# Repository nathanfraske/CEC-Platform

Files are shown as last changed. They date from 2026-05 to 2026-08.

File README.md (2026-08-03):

# CEC Platform

**CEC is a modular PC power-telemetry system.** Per-rail sensing modules connect
to a central Hub over a single commodity cable (RJ-45). The Hub aggregates
telemetry and forwards it to the host PC over USB. Four tiers — **Standard,
Pro, Enterprise, Mission Critical** — are built from one fundamental design with
progressively populated features.

Modules are **tier-agnostic and degrade gracefully**: any module works in any
Hub, with higher-tier features going dormant when the Hub cannot service them
and activating, without replacement, when the module is moved to a capable Hub.

This repository holds the **KiCad 10 hardware design sources** (schematics,
layouts, the shared component library), the fabrication snapshots, and the
tooling that checks them.

> **Ground truth.** [`CEC-Platform-Ground-Truth-Spec.md`](CEC-Platform-Ground-Truth-Spec.md)
> is the canonical specification and holds precedence over everything else,
> including [`CLAUDE.md`](CLAUDE.md). Read the spec before making any design
> decision. Spec revision: **v1.1.0 (2026-06-09), controlled baseline** (semantic
> versioning; the pre-release v1.0–v3.11 working log is retained in spec §11.1).
> Working-summary revision: **2026-06-09**.

---

## Boards

| Board | Directory | Tier | MCU | Ports | Host link | BOM target (100q) |
|---|---|---|---|---|---|---|
| Hub Standard | [`beta/hub-standard-rev2`](beta/hub-standard-rev2) | 1 | ESP32-S3-WROOM-1-N16R8 | 4 | USB Full Speed | ~$36 |
| Hub Pro | [`hubs/hub-pro`](hubs/hub-pro) | 2 | ESP32-P4 | 8 | USB High Speed | ~$45 |
| Hub Enterprise | [`hubs/hub-enterprise`](hubs/hub-enterprise) | 3 | ESP32-P4 + secure element | n/a | USB HS (+ optional 1000BASE-T1) | ~$50 |
| Hub Mission Critical | [`hubs/hub-mission-critical`](hubs/hub-mission-critical) | 4 | ESP32-P4 + crypto | n/a | redundant uplinks | ~$80 |
| 24-pin ATX module | [`beta/atx-24pin-rev3`](beta/atx-24pin-rev3) | Standard | per module spec | – | – | $35 |
| EPS 8-pin module | [`beta/eps-8pin-rev3`](beta/eps-8pin-rev3) | Standard | per module spec | – | – | $32 |
| PCIe 8-pin 2-port | [`beta/pcie-8pin-2port`](beta/pcie-8pin-2port) | Standard | per module spec | – | – | $38 |
| PCIe 8-pin 3-port | [`beta/pcie-8pin-3port`](beta/pcie-8pin-3port) | Standard | per module spec | – | – | ~$42 |
| 12VHPWR Standard module | [`beta/12vhpwr-standard`](beta/12vhpwr-standard) | Standard | per module spec | – | – | $49 |
| 12VHPWR Pro module (lead) | [`modules/12vhpwr-pro`](modules/12vhpwr-pro) | Pro | ESP32-P4 | – | – | $98–$99 |

Enterprise and Mission Critical are specified at platform-summary level only
until first customer requirements land (see **OQ-7**).

---

## The universal interface (LOCKED)

Every board — every Hub, every module, every tier — uses the same **shielded
RJ-45 (8P8C)** connector with a **locking boot** as the default shipped variant.
Mini-Fit Jr is retired platform-wide. The shared parts that implement this
interface (RJ-45 FTP jack, SK6812 LED chain, ESP32 module, power input — plus
the optional Enterprise/MC over-voltage protection network, OQ-8) live in [`lib/`](lib) so one change propagates
to every board.

### Pin allocation

| Pin | Cat5e pair | T568B color | CEC function | Tiers |
|---|---|---|---|---|
| 1 | Pair 1 | White-orange | VCC (+5VSB power) | All |
| 2 | Pair 1 | Orange | GND (power return) | All |
| 3 | Pair 3 | White-green | CAN1_H (control + low-rate telemetry) | All |
| 4 | Pair 2 | Blue | STREAM_P (RS-485 data, module → Hub) | Pro+ |
| 5 | Pair 2 | White-blue | STREAM_N (RS-485 data, module → Hub) | Pro+ |
| 6 | Pair 3 | Green | CAN1_L | All |
| 7 | Pair 4 | White-brown | AUX_REF (precision reference) | Pro+, pending OQ-3 |
| 8 | Pair 4 | Brown | DETECT / module-ID (analog single-wire sense) | All |

- **Power.** VCC is +5VSB on a single pin; GND returns on a single pin (no
  paralleling). Hubs take **bulk 5VSB on a dedicated 2-pin power-in connector**
  from the 24-pin module (spec §2.7) and distribute it to ports over RJ-45 VCC, so
  no single jack carries the trunk and per-port VCC stays comfortable. The RJ-45
  connector is still rated **≥ 1.5A**, and firmware **caps aggregate SK6812 LED
  current** (OQ-2). The VCC series protection resistor is sized together with the
  power budget, not independently.
- **Control — CAN.** All control and command traffic lives entirely on CAN, on
  pair 3, for every tier. Classical CAN at 500 kbps on Standard; CAN-FD on Pro
  and above. Transceiver TJA1051T/3; fixed **120 Ω split termination at the Hub**.
- **Streaming — RS-485.** High-bandwidth telemetry only, one direction
  (module → Hub), on pair 2. Present on **Pro modules and Pro+ Hubs only**;
  Standard leaves pair 2 unused and terminated at the module side.
- **DETECT.** Analog single-wire identity and presence sense: a precision
  resistor from pin 8 to GND on each module, read by the Hub through a fixed
  pull-up to VCC as an ADC divider. Open line ≈ VCC = no module. Resistor code
  table pending (OQ-6).
- **Protection.** Standard and Pro do **not** populate per-pin PoE/over-voltage
  protection — accidental PoE injection isn't a design target there. A per-pin
  TVS array plus series limiting resistors (PoE-survivable to ~57V) is an open
  question for Enterprise/Mission Critical (OQ-8).

See spec [§2](CEC-Platform-Ground-Truth-Spec.md) for the full interface detail.

---

## Repository layout

```
cec-platform/
  lib/                       # shared library: the locked universal interface
    cec.kicad_sym            #   symbols (authored in the KiCad Symbol Editor)
    cec.pretty/              #   footprints (RJ-45 FTP jack, SK6812, ESP32, power input; protection net is Enterprise/MC, OQ-8)
    3dmodels/                #   3D models referenced by footprints
  hubs/
    hub-standard/            # Tier 1 — ESP32-S3, 4 ports, classical CAN, USB FS
    hub-pro/                 # Tier 2 — ESP32-P4, 8 ports, classical CAN + RS-485, USB HS
    hub-enterprise/          # Tier 3 — platform-summary only for now (OQ-7)
    hub-mission-critical/    # Tier 4 — platform-summary only for now (OQ-7)
  modules/
    atx-24pin/               # Standard (superseded line)
    atx-24pin-rev2/          # Standard (current 24-pin line)
    eps-8pin/                # Standard
    pcie-8pin-2port/         # Standard (2 ports / 4 connectors)
    pcie-8pin-3port/         # Standard (3 ports / 6 connectors)
    12vhpwr-standard/        # Standard
    12vhpwr-pro/             # Pro (lead Pro module)
  fab/                       # tagged release snapshots of exactly what was sent to the board house
  firmware/                  # module firmware: shared ESP-IDF components, per-app trees, RTL
  corpus/general/            # cross-project rules corpus (SB-13; linted for provenance)
  tests/                     # pipeline unit tests + the golden-board regression (SB-08)
  docker/                    # the routing-container compute plane (kicad-cli/pcbnew 10 + JRE)
  scripts/                   # kicad-cli wrappers, CI helpers, and the agentic routing/synthesis plane
  CEC-Platform-Ground-Truth-Spec.md   # canonical spec (precedence over all)
  CLAUDE.md                  # operating guidance / working summary of the spec
  README.md
  LICENSE  NOTICE            # Apache-2.0
```

Each board is its own KiCad project. The universal-interface parts are sourced
from `lib/` rather than duplicated per board, and library tables use
project-relative paths (`${KIPRJMOD}`) — **never** absolute paths.

**Firmware lives in [`firmware/`](firmware/)** — consolidated from the
former `cec-24pin-idf` and `cec-eps-idf` repos (subtree-imported with
history) plus the 12VHPWR prototype's RTL + ESP32-P4 app: shared
ESP-IDF components under `firmware/esp/components/`, the prototype
(dev-board/perfboard) apps under `firmware/esp/proto/` — the flat
`firmware/esp/<name>` level is reserved for production apps matching
`modules/<name>` — and the GW5A acquisition RTL under `firmware/rtl/` with its
simulation gate. Pin maps live next to the KiCad projects that define
them; `firmware/FOLLOWUPS.md` tracks deferred work, and
`.github/workflows/firmware-ci.yml` builds all three apps + runs the
RTL sim on every firmware push (toolchain pins in `versions.env`).

---

## Toolchain

- **KiCad 10** (current stable, 10.0.x series). The `.kicad_*` file format is
  forward-only: a board saved in 10 will not open in 9. Keep every local install
  and any CI/container on the same major version.
- **`kicad-cli`** ships with KiCad and runs headless; it must be on `PATH`. For
  CI or a container, use the official KiCad Docker image rather than a full GUI
  install.

### Checks and outputs

Wrapper scripts in [`scripts/`](scripts) drive `kicad-cli`. Each prefers a local
`kicad-cli` and otherwise falls back to the official KiCad Docker image
(override the tag with `KICAD_IMAGE`, default `kicad/kicad:10.0`).

```bash
# Electrical rule check (schematic). Exit 0 = clean, 5 = violations.
scripts/erc.sh beta/hub-standard-rev2/hub-standard-rev2.kicad_sch

# Design rule check (layout). Exit 0 = clean, 5 = violations.
scripts/drc.sh beta/hub-standard-rev2/candidate/hub-standard-rev2-candidate.kicad_pcb

# Connectivity netlist and BOM, for checking against the spec.
scripts/netlist.sh beta/hub-standard-rev2/hub-standard-rev2.kicad_sch
scripts/bom.sh     beta/hub-standard-rev2/hub-standard-rev2.kicad_sch

# Top-side render for a quick silk/placement look.
scripts/render.sh  beta/hub-standard-rev2/candidate/hub-standard-rev2-candidate.kicad_pcb

# Fab package (gerbers + drill + pick-and-place) into the gitignored build/ dir.
scripts/fab.sh     beta/hub-standard-rev2/candidate/hub-standard-rev2-candidate.kicad_pcb

# CI sweep: ERC over every schematic, DRC over every layout. A board with a
# fab/<board>-* snapshot is ALWAYS checked, DRAFT marker or not; the gate fails
# on ERROR-level violations (warnings stay visible in the build/ reports).
scripts/check-all.sh

# Repo hygiene: no Mini-Fit Jr footprints, no absolute library paths, and the
# corpus provenance lint (corpus/general/ + scripts/constraints/).
scripts/checklist.sh
```

Reports and fab outputs are written under `build/` (gitignored). Fab packages
are committed only as tagged release snapshots under `fab/<rev>/`.

### The agentic routing / synthesis plane (Python)

The deterministic compute plane plus its control-plane hooks (see
[`scripts/README-cec_pcb.md`](scripts/README-cec_pcb.md) and
[`docs/self-hosted-router.md`](docs/self-hosted-router.md) for depth):

| Script | Role |
|---|---|
| `scripts/cec_fr.py` | Freerouting candidate generator (DSN/SES round-trip, pours after route, via normalize) |
| `scripts/cec_score.py` | scorer + HARD gates (Kelvin `_HI/_LO`, diff `_P/_N`), one cosmetic DRC filter, `drc_types`/`drc_loci` |
| `scripts/cec_router.py` | the `route()` orchestration loop + decision log (what `route.yml` runs) |
| `scripts/cec_route.py` | pcbnew real-copper hand-routing primitives for the sub-agent routing pass |
| `scripts/cec_dispatch.py` | compute-as-tools (`request_candidates`) + the budgeted `agent_route` tier loop |
| `scripts/cec_synth_pipeline.py` | the synthesis pipeline: cascade stages, placer, physics (IPC electrothermal), `run_pipeline` |
| `scripts/cec_constraints.py` / `cec_hc.py` / `cec_place.py` / `cec_dcir.py` / `cec_loop.py` | constraint registry + checkers, high-current pass, placer, DC-IR, the place→route→check self-correction loop |
| `scripts/cec_ledger.py` | SB-01 durable run ledger + determinism manifest (sibling `cec-runs` repo) |
| `scripts/cec_golden.py` | SB-08 golden-board pipeline regression (run before merging `scripts/**` changes) |
| `scripts/cec_corpus_lint.py` | SB-13/14 corpus provenance lint (wired into `checklist.sh`) |

Self-hosted workflows: `.github/workflows/route.yml` (Route) and `synth.yml`
(Synthesize: `run` / `sweep` / `candidates` modes) — manual `workflow_dispatch`
only; both append the run verdict to the job Summary. On this development box
the same plane runs in the `docker/` routing container
(`docker compose -f docker/compose.yaml run --rm --no-deps routing ...`).

### Self-contained & reproducible (clone parity)

A plain `git clone` is a full-parity project — no dependency on a machine's
global KiCad libraries:

- **Pinned toolchain.** The KiCad version is pinned in
  [`versions.env`](versions.env) (major 10, the 10.0.x series); the scripts and
  CI read it. The `.kicad_*` format is forward-only.
- **Vendored parts.** Official and third-party symbols/footprints are copied into
  [`lib/vendor/`](lib/vendor) and their 3D models into
  [`lib/3dmodels/`](lib/3dmodels), all referenced by `${KIPRJMOD}`-relative
  paths. `scripts/vendor-libs.sh` brings them in at the pinned library tag.
- **Enforced.** `scripts/checklist.sh` (run in CI) fails if any design file uses
  a machine-global `${KICAD*_DIR}` or an absolute path — the signal that a part
  still needs vendoring.

---

## Design-review checklist

A recurring pass, enforced in part by `scripts/checklist.sh`:

- No Mini-Fit Jr footprints remain anywhere; all module-to-Hub connectors are
  RJ-45 8P8C.
- Pinout on every board matches the locked pin allocation table above.
- PoE/over-voltage protection is not populated on Standard/Pro; on Enterprise/MC
  it follows OQ-8.
- The RS-485 pair (pins 4 and 5) and its receivers exist only on Pro and above;
  Standard leaves pair 2 unused and terminated at the module side.
- CAN termination is a fixed 120 Ω split at the Hub.
- Power-netclass trace width covers the trunk worst case; the firmware LED
  current cap is reflected in the design intent.
- Libraries and 3D models are vendored in-repo and referenced by
  `${KIPRJMOD}`-relative paths only (no machine-global or absolute paths).
- BOM totals are in line with the spec targets.

---

## Open questions

Design decisions that are **not** settled in the spec. Do not assume an answer;
surface it. Summarized here, full text in spec [§9](CEC-Platform-Ground-Truth-Spec.md).

| ID | Topic | Spec recommendation |
|---|---|---|
| OQ-1 ✓ locked | Hub bulk power → dedicated 2-pin +5VSB power-in from the 24-pin module; RJ-45 VCC distributes per-port (spec §2.7) | Resolved 2026-05-30 |
| OQ-2 | LED current cap value and max LED state to budget | Confirm a firmware cap |
| OQ-3 | Precision reference: distributed AUX_REF (pin 7) vs. local REF3033 | Path B (local REF3033) |
| OQ-4 | Cable-length SKUs and any-length policy | Pending; interacts with OQ-3 |
| OQ-5 | RS-485 topology: per-port point-to-point vs. shared multidrop | Per-port (working basis) |
| OQ-6 | Module-ID resistor encoding table | Pending module/tier list |
| OQ-7 | Fully specify Enterprise/Mission Critical now, or summary-level | Summary-level for now |
| OQ-8 | Per-pin PoE/over-voltage protection on Enterprise/MC (TVS + series-R, ~57V); Standard/Pro don't populate it | Pending Ent/MC requirements |

Two consequences worth calling out for layout work:

- With **OQ-1 locked** (dedicated 2-pin power-in), the full 5VSB trunk runs on the
  dedicated power-in and the Hub's internal distribution, while each RJ-45 VCC pin
  carries only one module. The **power-netclass minimum trace width** and the
  board `.kicad_dru` still wait on **OQ-2** (the LED cap) to fix the worst-case
  current.
- **AUX_REF on pin 7** is provisional pending **OQ-3**; treat it as such.

---

## Status

This is an early-stage hardware repository. The directory structure, shared-
library home, tooling, CI, and documentation are in place. The KiCad design
artifacts land per board over time: symbols, library-driven schematics, and
library tables can be drafted in-repo (then verified with ERC and the exported
netlist), while **PCB routing geometry** is done interactively in the KiCad 10
GUI.

**Carried action item:** the Hub Standard and 12VHPWR schematics still show
Mini-Fit Jr footprints and must be re-cut to RJ-45 before any board order. They
are the stale artifacts; the spec is current.

---

## Contributing

- The spec wins. If a change to a locked decision seems warranted, propose a
  spec revision first rather than diverging in a board.
- Do not resolve an open question (OQ-1…OQ-7) by assumption — surface it.
- Keep library paths project-relative (`${KIPRJMOD}`); never commit absolute
  paths. Vendor any official/third-party part you use
  (`scripts/vendor-libs.sh`) so a clone stays self-contained, and keep the
  toolchain on the pinned KiCad 10 (`versions.env`).
- Run `scripts/check-all.sh` and `scripts/checklist.sh` before pushing layout or
  schematic changes.
- Commit fab outputs only as tagged release snapshots under `fab/<rev>/`, not as
  routine churn.

---

## License

Copyright 2026 Nathan M. Fraske.

Licensed under the **Apache License, Version 2.0**. You may not use the files in
this repository except in compliance with the License. See [`LICENSE`](LICENSE)
for the full text and [`NOTICE`](NOTICE) for attribution; a copy of the License
is also available at <http://www.apache.org/licenses/LICENSE-2.0>.

Unless required by applicable law or agreed to in writing, work distributed
under the License is distributed on an "AS IS" BASIS, WITHOUT WARRANTIES OR
CONDITIONS OF ANY KIND, either express or implied.

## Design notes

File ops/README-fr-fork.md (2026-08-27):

# FreeRouting seed fork — `freerouting-1.7.0-cec1` (A5-seed)

A minimal fork of open-source **FreeRouting v1.7.0** (Apache-2.0) that adds a
`-seed <long>` CLI flag giving reproducible, steerable pseudo-randomness to the
autorouter. It closes the R-01 "no diversity axis" gap and removes the
run-to-run noise that contaminated every A/B measurement.

- **Base tag:** `v1.7.0` (upstream commit `ba0b23e89858bbfe7113df38f9de8dab090a0079`).
- **Patch (durable, committed):** `scripts/patches/freerouting-1.7.0-cec-seed.patch`
- **Build product (gitignored, WSL-ephemeral):** `build/fr-fork/freerouting-1.7.0-cec1.jar`
- **Owner ruling:** patch BASE is 1.7.0 (2.2.4 was gate-rejected 2026-06-10 — hangs on
  the 12vhpwr GND net; see `CLAUDE.md` action item -4).

The **patch is the source of truth**; the jar is a rebuildable product (`build/fr-fork`
is gitignored per the WSL-ephemeral-state policy).

---

## What the patch changes (5 files, +44/-2 lines of code)

| File | Change |
|---|---|
| `datastructures/Seed.java` *(new)* | Process-global master-seed holder. `Seed.mix(local)` returns `local` **unchanged** when no seed is set → default behavior is byte-identical to stock. |
| `gui/StartupOptions.java` | Parses `-seed <long>` (decimal or `0x` hex) and calls `Seed.set(...)`. Inserted **before** the `-s` (session-file) branch because `"-seed".startsWith("-s")` — otherwise the flag would be swallowed. |
| `autoroute/BatchAutorouter.java` | **The live diversity axis.** When `-seed` is set, the per-pass net/item routing **order** is shuffled with a seeded PRNG (salted by pass number). Opt-in; no-seed keeps the exact stock (sorted) order. |
| `autoroute/MazeSearchAlgo.java` | The rip-up maze `Random` is seeded via `Seed.mix(ripup_costs)` instead of `ripup_costs` alone. No-seed → identical to stock. |
| `autoroute/BatchOptRouteMT.java` | The `-mt >1` `ItemSelectionStrategy.RANDOM` shuffle (stock: wall-clock-seeded, a genuine nondeterminism source) becomes seed-derived when `-seed` is set; unseeded stock shuffle otherwise. |

### Why net-ORDER is the diversity lever (the key finding)

The obvious target — the maze rip-up `Random` (`MazeSearchAlgo:1180`, gated on
`ctrl.ripup_pass_no >= 4`) — is **dead code in the headless batch path**:
`AutorouteControl.ripup_pass_no` is initialized to `1` (line 120) and **never
reassigned** by `BatchAutorouter` (it sets `ripup_costs` at line 345 but not
`ripup_pass_no`). So `randomize` is always false and that `Random` is never
consumed during a CLI route. Seeding it alone yields **zero** diversity (measured).

Consequently the stock `-mt 1` batch path is **fully deterministic** — every seed
would give the identical route (that is precisely the R-01 "no diversity axis"
problem). The one *live* routing degree of freedom is **net ordering**, so that is
what the seed steers. This mirrors FreeRouting's own `ItemSelectionStrategy.RANDOM`,
which already randomizes item order — but only in the MT optimizer; the patch
extends the same idea, opt-in, to the main batch autoroute pass. The maze-`Random`
seeding is kept anyway (correct, harmless, and becomes live if upstream ever fixes
the `ripup_pass_no` bug).

### Guarantee: unflagged = stock

Every seeded site reduces to the exact stock expression when `-seed` is absent
(`Seed.isSet()==false` / `Seed.mix()` returns its argument). This was verified
byte-for-byte (leg 0b below): **patched, no `-seed`, is byte-identical to the stock
1.7.0 jar.**

---

## Nondeterminism sources found in FR 1.7.0 (audit)

Classified: **(a)** genuinely random / seedable · **(b)** hash-iteration order · **(c)** wall-clock.

| Site | Class | Verdict |
|---|---|---|
| `autoroute/MazeSearchAlgo.java:44,53,1179` — rip-up detour `Random`, seeded from `ripup_costs` | (a) | **Dead** in batch mode (`ripup_pass_no` stuck at 1). Seeded by the patch anyway. |
| `autoroute/BatchOptRouteMT.java:194` — `Collections.shuffle(item_ids)` **unseeded** (wall-clock `Random`) | (a) | Real nondeterminism, but only on `-mt >1` **and** `-is rand`. Seeded by the patch. |
| `datastructures/PlanarDelaunayTriangulation.java:29,56` — shuffle | (a) | Uses a **fixed** seed (`99`); already deterministic. Left stock. |
| `geometry/planar/PolygonShape.java:17,466,485` — `nextInt` | (a) | Uses a **fixed** seed (`99`); already deterministic. Left stock. |
| `datastructures/UndoableObjects.java:20` — item store | (b) | `ConcurrentSkipListMap` (sorted) → deterministic iteration. Not a source. |
| `board/Item.java` — `get_connected_set` / `get_unconnected_set` | (b) | `TreeSet` (sorted). Not a source. |
| `autoroute/BatchAutorouter.java:34` — `already_checked_board_hashes` `HashSet` | (b) | Membership-only, never iterated for decisions. Not a source. |
| `board/BasicBoard.java:165` — `diff_traces` `HashSet` | (b) | Count-only (contains/remove/size). Not a source. |
| `autoroute/BatchOptRouteMT.java:26` — `result_map` `HashMap` + thread completion order | (b)/(c) | MT-only path; thread-order nondeterminism the seed cannot fully fix. Pipeline uses `-mt 1`, so out of scope. |
| Per-connection `TimeLimit` (`BatchAutorouter:373` = `100000·2^(pass-1)` ms) and the pull-tight `TIME_LIMIT_TO_PREVENT_ENDLESS_LOOP = 1000` ms (`opt_changed_area`) | (c) | Wall-clock. **Budget left alone.** Not hit on the small EPS board (deterministic there); *can* feed decisions beyond stopping on large/congested boards — noted, not touched. |

`Math.random()`: none in the tree. `-oit` in 1.7.0 is the optimization-improvement
**threshold** (percent), **not** a time budget; the run is bounded by `-mp`
(max_passes). Neither is wall-clock.

---

## How to rebuild

FR 1.7.0 targets Java 17 and ships a Gradle **7.3** wrapper, which **cannot compile
on Java 21** (the host/container default). Use a local JDK 17 — do **not**
`apt`-install one system-wide.

```bash
cd /home/nathan/CEC-Platform

# 1. Clone the pinned base (gitignored working area)
git clone --depth 1 --branch v1.7.0 \
  https://github.com/freerouting/freerouting.git build/fr-fork
cd build/fr-fork

# 2. Apply the committed patch
git apply ../../scripts/patches/freerouting-1.7.0-cec-seed.patch

# 3. Local JDK 17 (Temurin), extracted under the fork (not system-wide)
curl -sL -o jdk17.tar.gz \
  "https://api.adoptium.net/v3/binary/latest/17/ga/linux/x64/jdk/hotspot/normal/eclipse"
mkdir -p jdk && tar xzf jdk17.tar.gz -C jdk --strip-components=1

# 4. Build the fat executable jar
JAVA_HOME="$PWD/jdk" ./gradlew executableJar --no-daemon --console=plain

# 5. Name the artifact
cp build/libs/freerouting-executable.jar freerouting-1.7.0-cec1.jar
sha256sum freerouting-1.7.0-cec1.jar
```

**Jar reproducibility caveat (matters for hash-pinning):** the compiled bytecode is
fully reproducible — two independent builds from this patch produced **byte-identical
`.class` and resource entries** (3297/3298). The **only** differing jar entry is
`META-INF/MANIFEST.MF`, which bakes in `Build-Time` (build clock), so the jar
**sha256 changes per build**. Pin the specific jar that will actually be
distributed (below), or normalize the manifest for a stable hash.

---

## How to use it (CEC pipeline)

Point `cec_fr` at the jar with the environment variable — **do not edit
`scripts/cec_fr.py`'s `FR_RELEASES`** (another owner wires the registry entry):

```bash
export CEC_FREEROUTING_JAR=/home/nathan/CEC-Platform/build/fr-fork/freerouting-1.7.0-cec1.jar
```

`cec_fr.ensure_jar()` treats an explicit `CEC_FREEROUTING_JAR` as a trusted override
(hash logged, not pin-checked), so it runs the patched jar directly. To actually
*use* the seed, the FR invocation must add `-seed <n>`; `cec_fr.run_freerouting()`
currently only **logs** its `seed=` kwarg (`"no -seed flag in FR 1.7.0"`), so the
registry-wiring change is what threads `-seed` onto the command line. Until then the
patched jar behaves exactly like stock (default = no `-seed`).

Direct invocation (the exact shape `cec_fr._fr_command` builds, plus the new flag):

```bash
xvfb-run -a java -jar freerouting-1.7.0-cec1.jar \
  -de in.dsn -do out.ses -mp 10 -oit 30 -mt 1 -seed 1
```

### For the registry wiring (what the orchestrator needs)

- **Delivered jar:** `build/fr-fork/freerouting-1.7.0-cec1.jar`
  sha256 `375e36b8ee347c57127670c06aeaa650d562a0365b0a4ed6dd3634d215f103b1`
  (built with Temurin JDK 17.0.19; the canonical binary — copy it to a durable path
  and pin THIS sha, since a rebuild changes only the manifest timestamp).
- Base tag `1.7.0`, `min_java: 17`, runs `java -jar` (no app-image needed).
- A suggested `FR_RELEASES` key: `"1.7.0-cec1"`.
- The seed must be threaded onto the FR command line as `-seed <long>` (append to
  `_fr_command`'s arg list) for it to take effect.

---

## Verification (VERBATIM)

Env: `cec/routing:kicad10` container, Java 21, `xvfb-run`. DSN exported **once**
from `tests/golden/eps-8pin/eps8pin-module.kicad_pcb` via `cec_fr.export_dsn`
(`build/fr-fork/dettest/eps.dsn`, sha256 `2cbea65d002a89bf2a83f…`). Every FR run:
`-mp 10 -oit 30 -mt 1`, identical output basename in a separate workdir (so the
session name — which echoes the output filename — is not a spurious diff).

Stock jar sha256 `e6c5db33792a00f99799b1113bb9f5e1576731f885b069da8850520528f7ef8f`
(the pinned baseline). Patched jar sha256
`375e36b8ee347c57127670c06aeaa650d562a0365b0a4ed6dd3634d215f103b1`.

```
sha stock1:9c2819a72527a8bd stock2:9c2819a72527a8bd pdef:9c2819a72527a8bd \
    s1:35238a2ea52e5609 s2:d8199482709908cb s7:641aef9c5bed6ac5

(i)   STOCK run1 vs run2          : IDENTICAL
(0a)  PATCHED no-seed run1 vs run2: IDENTICAL
(0b)  PATCHED no-seed vs STOCK    : IDENTICAL
(ii)  PATCHED -seed 1 run1 vs run2: IDENTICAL
(ii2) PATCHED -seed 2 run1 vs run2: IDENTICAL
(iii) PATCHED -seed 1 vs -seed 2  : DIFFERENT
(iii2)PATCHED -seed 1 vs -seed 7  : DIFFERENT
(iv)  PATCHED -seed 1 vs no-seed  : DIFFERENT
```

Reading the results:

- **(0b) patched-default is byte-identical to the stock jar** — the "keep default
  exactly stock" requirement holds byte-for-byte (all three of stock1/stock2/pdef
  share sha `9c2819a7…`).
- **(ii)/(ii2) same seed → byte-identical** across runs — reproducible.
- **(iii)/(iii2)/(iv) different seeds → different `.ses`** (three distinct shas
  `35238a2e` / `d8199482` / `641aef9c`) — a real, seed-controlled exploration axis.
- **(i) stock run1 vs run2 → IDENTICAL** (honest deviation from the task's
  expectation). On the small EPS board at `-mt 1`, stock FR 1.7.0 is **already
  deterministic** (sorted collections + the dead maze `Random`). The measured
  ±30-unconn noise is a **`-mt >1` / large-congested-board** phenomenon, not a
  `-mt 1` small-board one — but stock nonetheless has **no seed diversity axis**
  (every seed → identical), which is exactly the R-01 gap this patch fills.

---

# cec2 addendum (2026-07-14) — `freerouting-1.7.0-cec2`

Owner GO ("do the surgery ... do the speedups and profile it"). cec2 = cec1 + three
**opt-in** flags; the unflagged-equals-stock guarantee is preserved (every new site
checks a `CecOptions` flag that defaults to stock behavior).

| Flag | File(s) | What it does |
|---|---|---|
| `-noecho` | `designforms/specctra/SpecctraSesFileWriter.java`, `datastructures/CecOptions.java` *(new)* | Skip unmodified user-fixed ("protect") wires in the SES — they were router INPUTS; echoing them creates re-import duplicates (reconcile measured ~130 strips/route). |
| `-maxstall <k>` **(EXPERIMENTAL — do not wire by default)** | `autoroute/BatchAutorouter.java` | Abort the batch route after `k` no-improvement passes. Bench 2026-07-14: the abort fires, but the post-route OPTIMIZER (improvement-bounded, not time-bounded) then thrashes on the incomplete board — the maxstall leg TIMED OUT at 900 s vs a 194 s full run. Completion (skip the optimizer on stall-abort) queued in FOLLOWUPS; the shipping pre-kill is EXTERNAL: watch the `CEC_PASS` lines and kill the JVM on plateau, which dodges the optimizer entirely. |
| `-progress` | `autoroute/BatchAutorouter.java` | One machine-readable line per pass: `CEC_PASS pass=<n> togo=<m> failed=<f> ripped=<r>` — the stage-0 pre-kill contract (replaces log-scraping). |

- **Patch (cumulative over v1.7.0, replaces applying cec1 separately):**
  `scripts/patches/freerouting-1.7.0-cec2.patch`
- **Jar sha256:** `149cebd88169be77f5ddc7e1d50284451204f10c088e5d7380859ab0395b7ce5`
  The cec2 patch removes the upstream build-user and build-clock manifest
  fields, freezes the generated `Constants.java` build date to the reviewed
  binary's date, disables file timestamps, and enables reproducible entry order.
  The reviewed digest is also compiler-platform specific: it is produced by
  Temurin **Windows x64** JDK 17.0.20+8. The corresponding Linux x64 JDK does
  not produce the pinned complete-JAR digest even with identical sources and
  version. `scripts/build-freerouting-cec2.ps1` pins and verifies the Windows
  JDK archive, build patch, and final JAR hash.
  (durable copies: `/mnt/e/toolchain/fr-fork/` + `build/fr-fork/`)
- **cec_fr wiring:** `-noecho` + `-progress` default ON where supported
  (`CEC_FR_NOECHO=0` reverts the echo for A/Bs); `-maxstall` opt-in via
  `CEC_FR_MAXSTALL=<k>`; the seed axis remains opt-in via `CEC_FR_SEED_AXIS=1`.
- Hash-exact rebuild from Windows PowerShell:

  ```powershell
  powershell -ExecutionPolicy Bypass -File scripts/build-freerouting-cec2.ps1
  ```

  The default output is
  `build/fr-fork/freerouting-1.7.0-cec2.jar`. The script builds in a disposable
  `%TEMP%` directory, validates both the JDK and JAR hashes, and removes the
  downloaded toolchain and Gradle cache when finished.

# cec3 addendum (2026-08-04) — `freerouting-1.7.0-cec3`

The fully guarded six-layer Hub exports a DSN larger than 512 KiB. Freerouting
1.7.0's generated scanner can refill and grow its buffer, but its hand-written
`next_string()` helper read the initial array directly and crashed at byte
524,288 before routing began. cec3 applies the incremental
`scripts/patches/freerouting-1.7.0-cec3.patch` after the cumulative cec2 patch.
The helper now refills and grows the existing buffer in place, preserving every
scanner position; it does not raise a fixed size ceiling or remove PCB guards.

- Linux/WSL build: `scripts/build-freerouting-cec3.sh`
- OpenJDK build pin: 17
- JAR SHA-256:
  `202136e7e73d5aa3e2a852bab186f71b67289a4068dee0804cb9c7b2efd8c7f7`
- Exact Hub proof: a 549,907-byte DSN completed parser, route, SES import, and
  KiCad board save with the cec3 artifact; cec2 failed at index 524,288.

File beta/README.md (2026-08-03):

# CEC beta line — the authoritative board versions

Single source of truth for the CURRENT Standard-line beta products.  The
machine-readable equivalent is `scripts/cec_beta_manifest.py`; audits and waves
consume that manifest instead of recursively discovering whatever happens to be
under `beta/`.

**Rule:** for any beta-line change, edit only a manifest-declared directory
below.  Historical captures live under `old-revisions/` and are never project
discovery inputs.  `eps-8pin-rev3` is the one EPS product; `rev3` identifies its
current design revision, not a product variant.

> **PHYSICAL MOVE EXECUTED 2026-07-22** (owner directive: "the BETA line in its own
> directory... no further confusion on where the latest ones are" — supersedes the
> earlier defer-the-move note). The live beta lineage now LIVES in `beta/<board>/`
> (depth-preserved: 2-deep like `modules/<board>/`, so every `${KIPRJMOD}/../../lib`
> path resolves unchanged; the out-daughterboards keep depth 3 under
> `beta/output-daughterboards/`). The rule is now brutally simple: **if it's in
> `beta/`, it's the latest; everything under `modules/`/`hubs/` is alpha or
> history.** Verification of the move: normalized netlists BYTE-IDENTICAL pre/post
> for all 11 moved boards (only path metadata differs), zero stale toolchain refs
> (60-file sweep + 11 composed-path fixes + 3 resolvers: `cec_router.find_board`,
> `cec_facts.board_catalog`, `cec_synth_pipeline.Config.load` — all scan `beta/`
> first), full checklist green, SB-08 golden unchanged.

## Authoritative beta boards (edit these)

| Board | Directory | MCU | State | Markers |
|---|---|---|---|---|
| 24-pin ATX | `beta/atx-24pin-rev3` | ESP32-C6-MINI-1 | INA238 beta, DRAFT | BETA |
| EPS 8-pin | `beta/eps-8pin-rev3` | ESP32-C6-MINI-1 | current hierarchical beta, DRAFT | BETA |
| PCIe 8-pin 2-port | `beta/pcie-8pin-2port` | ESP32-C6-MINI-1 | hierarchical beta, DRAFT | BETA |
| PCIe 8-pin 3-port | `beta/pcie-8pin-3port` | ESP32-C6-MINI-1 | hierarchical beta, DRAFT | BETA |
| 12VHPWR Standard | `beta/12vhpwr-standard` | ESP32-S3-MINI-1 | hierarchical, fab-ready | BETA |
| ARGB Standard | `beta/argb-standard` | ESP32-S3-MINI-1 | beta, DRAFT | BETA |
| Hub Standard | `beta/hub-standard-rev2` | ESP32-S3-WROOM-1 | current hierarchical schematic, layout via waves | BETA |
| Smoke Tester | `beta/smoke-tester` | NONE (pure analog, by design) | sketch-stage: README spec + assets + BOM, no capture yet (owner standup 2026-07-24) | BETA + DRAFT |

The shipped Hub alpha and the earlier sectioned Hub draft are archived at
`old-revisions/hubs/hub-standard-alpha` and
`old-revisions/hubs/hub-rev2-sectioned-draft`.  They remain recoverable through
git but cannot be selected as current BETA inputs.

Output daughterboards (per the D-5a architecture, also beta and authoritative):
`beta/output-daughterboards/atx24-out-db`, `.../eps-out-db`, `.../pcie-out-db`.

## Superseded (do not edit; kept only as history)

| Stale directory | Superseded by | Why |
|---|---|---|
| `old-revisions/beta/eps-8pin-pre-rev3` | `beta/eps-8pin-rev3` | obsolete EPS revision; archived to enforce one current EPS |
| `modules/pcie-8pin-2port-rev2` | `beta/pcie-8pin-2port` | same |
| `modules/pcie-8pin-3port-rev2` | `beta/pcie-8pin-3port` | same |
| `old-revisions/hubs/hub-standard-alpha` | `beta/hub-standard-rev2` | shipped alpha reference, not a BETA editing root |
| `old-revisions/hubs/hub-rev2-sectioned-draft` | `beta/hub-standard-rev2` | older DRAFT, fewer parts, superseded |
| `old-revisions/beta/*-flat-2026-08-02` | corresponding hierarchy | reviewed electrical source retained for exact hierarchy regression |

Each carries a `SUPERSEDED` marker. None was ever fabbed. Safe to delete once you
confirm you want them gone; git history keeps them.

## Hub rev2 line (NOT superseded — the merged-in pipeline branch's hub revision)

`beta/hub-standard-rev2` (DRAFT) is the **rev2 Hub Standard schematic** finalized
2026-07-15 on `claude/pipeline-consolidation` and merged 2026-07-17: F1–F4 per-port
polyfuses, D8/D9 SMAJ5.0A power-entry TVS, C18–21 DETECT filters, the J6 column-paired
mezzanine header (DNP THT — since split into the J6P/J6C/J6D structural segments,
2026-07-22), D-11 DRU exception. Committed layout is unstarted; the wave pipeline
synthesizes its layouts (first-ever routed hubs landed 2026-07-20/22). PROMOTED into
the authoritative table 2026-07-22 (see the table note). Do NOT confuse it with
the archived `old-revisions/hubs/hub-rev2-sectioned-draft` capture.

## Alpha / ordered prototypes (keep as history, not part of the beta line)

- `modules/atx-24pin` — alpha, the validated prototype (INA228).
- `modules/atx-24pin-rev2` — the ordered rev2 prototype (INA228, physically built).

These are the alpha lineage. Per the alpha/beta convention they are never overwritten
or edited for beta work; the beta 24-pin is `atx-24pin-rev3`.

## Other tiers (not Standard beta, listed so they are not mistaken for it)

`hubs/hub-pro`, `hubs/hub-enterprise`, `modules/12vhpwr-pro`, `modules/ent-common`,
`modules/ent-kvm-carrier`.

## Move record (2026-07-22)

The deferred physical move was executed per this file's own recipe: `git mv` of the
9 authoritative dirs (+`eps-8pin-rev3`), a guarded longest-first reference sweep (60
files; `(?!-rev)` lookaheads protect the `-rev2` superseded siblings), 11
composed-path fixes (`os.path.join(ROOT, "modules", board)` forms the sweep cannot
see), and `beta/`-first search order in the three resolvers. Proofs: 11/11
normalized-netlist identity, zero stale refs in scripts/tests/.github/ops, checklist
green, golden signature unchanged. The superseded/alpha directories deliberately did
NOT move — history stays where it happened.

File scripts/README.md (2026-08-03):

# `scripts/` — kicad-cli wrappers and CI helpers

Thin, portable Bash wrappers around `kicad-cli`, plus CI and vendoring helpers.
Every script calls through [`kicad-cli.sh`](kicad-cli.sh), which prefers a local
`kicad-cli` and otherwise runs the official **KiCad Docker image** (image and tag
pinned in [`../versions.env`](../versions.env) as `KICAD_IMAGE`, default
`kicad/kicad:10.0`). Reports and outputs go to
the gitignored `build/<board>/` directory.

| Script | Does | Usage |
|---|---|---|
| `kicad-cli.sh` | Wrapper: local `kicad-cli`, else Docker | `scripts/kicad-cli.sh <args…>` |
| `erc.sh` | Electrical rule check (schematic) | `scripts/erc.sh <board.kicad_sch>` |
| `drc.sh` | Design rule check (layout) | `scripts/drc.sh <board.kicad_pcb>` |
| `netlist.sh` | Export netlist (check vs. pin table) | `scripts/netlist.sh <board.kicad_sch>` |
| `bom.sh` | Export BOM (check vs. spec targets) | `scripts/bom.sh <board.kicad_sch>` |
| `render.sh` | Top-side PNG render | `scripts/render.sh <board.kicad_pcb>` |
| `fab.sh` | Gerbers + drill + pick-and-place → `build/` | `scripts/fab.sh <board.kicad_pcb>` |
| `check-all.sh` | ERC every schematic, DRC every layout (CI) | `scripts/check-all.sh` |
| `checklist.sh` | Repo hygiene: no Mini-Fit Jr, in-repo relative lib/3D paths (CI) | `scripts/checklist.sh` |
| `vendor-libs.sh` | Vendor official/3rd-party parts + 3D models for clone parity | `scripts/vendor-libs.sh fetch` (then `add-symbol`/`add-footprint`/`add-3dmodel`/`verify`) |

`erc.sh` / `drc.sh` follow `kicad-cli` conventions: **exit 0 = clean, 5 =
violations**, other = tool error. `check-all.sh` aggregates those and is a clean
no-op until boards exist.

## Examples

```bash
# One board
scripts/erc.sh beta/hub-standard-rev2/hub-standard-rev2.kicad_sch
scripts/drc.sh beta/hub-standard-rev2/candidate/hub-standard-rev2-candidate.kicad_pcb

# Everything, the way CI runs it
scripts/check-all.sh
scripts/checklist.sh

# Pin the toolchain image explicitly
KICAD_IMAGE=kicad/kicad:10.0 scripts/check-all.sh
```

## Notes

- Keep the container's KiCad on the same major version as the project (**KiCad
  10**); the file format is forward-only. The pin lives in
  [`../versions.env`](../versions.env) (sourced by these scripts; CI uses the
  same image tag).
- `vendor-libs.sh` copies official/third-party parts and their 3D models into the
  repo at the pinned `KICAD_LIB_TAG`, so a plain clone is self-contained.
- `fab.sh` writes working outputs to `build/`. Release packages are snapshotted
  to `fab/<rev>/` at a tag, not produced here as churn.
- If a board defines a `.kicad_jobset`, prefer `kicad-cli jobset run` for fab
  outputs so settings match the GUI (confirm flags with `kicad-cli jobset run -h`).

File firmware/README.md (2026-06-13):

# CEC-Platform firmware tree

Drop this directory into `CEC-Platform/firmware/`. One repo, one SHA, one
coherent hardware-plus-firmware state: pin maps live next to the KiCad
projects that define them, and fab-gate punchlists pin both at once.

## Layout and the criss-cross mechanics

```
firmware/
  rtl/
    common/          shared Verilog; consumed by relative path from any target
      cec_spi_slave.v
    12vhpwr-proto/        12VHPWR perfboard prototype (GW5A-25, Tang Primer 25K dock)
      top.v          acquisition FSM + ESP link
      tb_top.v       self-checking sim (AD7606 stub + ESP master stub)
      12vhpwr-proto.cst   dock 2x20 GPIO field pin map
    fpgamax/         (later) production target; reuses rtl/common
  esp/
    components/      shared ESP-IDF components; every app sees them via
                     EXTRA_COMPONENT_DIRS in its project CMakeLists
    proto/           PROTOTYPE apps (dev-board/perfboard rigs):
      12vhpwr/         ESP32-P4-NANO readout app for this prototype
      atx-24pin/       ESP32-S3 dev-board rig (24-pin)
      eps-8pin/        ESP32-S3 dev-board rig (EPS)
    (flat esp/<name> is reserved for production apps matching modules/<name>)
  tools/             host-side Python (decoders, cal) as they appear
```

RTL criss-cross is file-list based: targets reference `../common/*.v`
directly, and the Gowin project for each target adds the same files. ESP
criss-cross is the IDF component system: drop a component under
`esp/components/<name>/` with its own CMakeLists and every app picks it up
with no submodules, no packaging, no version skew. The first shared pieces to
extract as real components once v0 stabilizes: the frame protocol
(header/seq/payload) and the calibration math.

The AGPL seam stays architectural: nothing here links against
cec-support-agent. Telemetry crosses to the diagnostic pipeline as serial
data and log artifacts only.

## 12vhpwr-proto v0: what it does

Fabric (verified by simulation in this tree): 200 ns RESET pulse after POR,
CONVST paced at 1 kSPS (parameter), BUSY tracked through 2FF sync, 64-clock
dual-line serial read at 12.5 MHz (V1-V4 off D7, V5-V8 off D8, capture
late-high, launch on falling per the AD7606 serial interface), 8x16 frame
latch guarded against tearing while the ESP is mid-read, and an oversampled
mode-0 SPI slave presenting 18 bytes: `0xA5, seq, V1..V8` MSB first. DRDY is
level-high while an unread frame waits and clears on a completed read.

ESP32-P4: SPI master at 4 MHz (keep at or under 5 MHz, the slave is
oversampled at 50 MHz), polls DRDY, pulls a frame, checks the header, prints
all eight channels as raw codes and volts at 152.59 uV/LSB, about 5 Hz.

## Build and run

Sim (CI-able, no vendor tools):

    cd rtl/12vhpwr-proto
    iverilog -g2012 -o tb tb_top.v top.v cec_boxcar_decim.v cec_native_anomaly.v cec_native_rail.v ../common/cec_spi_slave.v && vvp tb
    # expect: PASS: decimator average, LIVE seq, BURST ring, STREAM dropcount, STATUS rate counter, NATIVE-ANOMALY ...

Bitstream: Gowin EDA V1.9.9Beta-4 or newer (Yosys 0.33 does not target GW5A).
New project, device GW5A-LV25MG121, add `top.v`, `cec_boxcar_decim.v`,
`cec_native_anomaly.v`, `cec_native_rail.v`, `../common/cec_spi_slave.v`, and
`12vhpwr-proto.cst`, synthesize, place-route,
program the dock over its USB-C.

ESP app:

    cd esp/proto/12vhpwr
    idf.py set-target esp32p4
    idf.py build flash monitor

IDF v5.3 or newer for ESP32-P4 support.

## Acceptance: bring-up step 3

With the module powered, dock programmed, ESP flashed, grounds common via
the T15 Y:

1. BUSY pulses about 4 us at the CONVST cadence (OS = 000 as built).
2. Console streams frames with an advancing seq and a stable 0xA5 header.
3. Screw-bus inputs jumpered to the screw-bus GND read within a few LSB of
   code 0.
4. An AA battery across one input reads near code 9800 (1.5 V / 152.59 uV);
   sign flips when reversed.

Symptom decoder lives in the build doc (section 13) and the session notes:
parallel-mode silence on D7, BUSY-width oddities, half/double codes, and
sane/garbage alternation each point at one specific strap.

## CI sketch (GitHub Actions, path-filtered)

```yaml
on:
  push:
    paths: ['firmware/**']
jobs:
  rtl-sim:
    runs-on: ubuntu-latest
    steps:
      - uses: actions/checkout@v4
      - run: sudo apt-get update && sudo apt-get install -y iverilog
      - run: |
          cd firmware/rtl/12vhpwr-proto
          iverilog -g2012 -o tb tb_top.v top.v cec_boxcar_decim.v cec_native_anomaly.v cec_native_rail.v ../common/cec_spi_slave.v
          vvp tb | tee sim.log
          grep -q '^PASS' sim.log
  esp-build:
    runs-on: ubuntu-latest
    container: espressif/idf:v5.3
    steps:
      - uses: actions/checkout@v4
      - run: |
          cd firmware/esp/proto/12vhpwr
          idf.py set-target esp32p4 build
```

Hardware checks keep their own workflows with their own path filters; a
firmware push never rebuilds the KiCad gates and vice versa.

## Honest status

The RTL is simulation-verified in this tree against a behavioral AD7606 and
a behavioral ESP master. The ESP app follows current IDF v5 master-driver
API but has not been compiled here; expect at most include-level fixups on
first build. Timing closure on the GW5A is trivial at these clock rates but
is the Gowin tool's word, not the simulator's.

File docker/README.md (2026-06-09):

# `docker/` — Linux container home for the CEC compute plane

Phase 0 of [`docs/local-compute-exploration.md`](../docs/local-compute-exploration.md). This gives the
CPU compute plane (Freerouting JVM swarm + `kicad-cli` DRC) a clean Linux home and an opt-in GPU
inference service for the local judge tiers — on a Windows 11 box via WSL2 + Docker, or on bare Linux.

Why bother: on Linux, **Freerouting runs truly headless** (the official image is a REST server — no
Xvfb, none of the Windows interactive-desktop hack in [`docs/self-hosted-router.md`](../docs/self-hosted-router.md)),
and vLLM/PyTorch/FEM are all Linux-first. The compute plane itself is **CPU/RAM-bound** (one ~0.5 GB
JVM per core) — the GPU is only for the inference tier and future ML, not for Freerouting or DRC.

## Contents

| File | What |
|---|---|
| `Dockerfile.routing` | CPU compute container: `kicad/kicad:10.0` + the **FULL** `openjdk-21-jre` (not `-headless`) + xvfb + numpy/scipy/requests. Runs the `cec_*` pipeline. |
| `xvfb-entrypoint.sh` | Starts a **persistent Xvfb** on `$DISPLAY` at container start so Freerouting's Swing GUI has a display (and `cec_fr` runs `java` directly, skipping `xvfb-run`). |
| `compose.yaml` | `routing` (CPU, `init: true`) + `freerouting` (headless REST) + `inference` (GPU, opt-in) + a commented `fem` stub. |
| `.wslconfig.example` | RAM/core split for WSL2 — copy to `%UserProfile%\.wslconfig`. |

## One-time host setup (Windows 11 + WSL2)

1. **Windows NVIDIA driver ≥ 576** (do **not** install a Linux driver inside WSL2 — the Windows one
   is paravirtualized through). **WSL2 ≥ 2.7.0** (`wsl --version`; the Blackwell CUDA-graph fix).
2. Copy `.wslconfig.example` → `%UserProfile%\.wslconfig`, then `wsl --shutdown`.
3. In the distro: install **Docker** (Docker Desktop WSL2 backend, or Docker Engine) + the **NVIDIA
   Container Toolkit**. Verify the GPU reaches a container:
   ```bash
   docker run --rm --gpus all nvidia/cuda:12.8.0-base-ubuntu24.04 nvidia-smi
   ```
   If the 5090 isn't seen, run `nvidia-cdi-refresh` (documented Blackwell-in-WSL fix; microsoft/WSL#14452).
4. **Put the repo on the WSL ext4 home (`~/`), NOT on `/mnt/c`.** The DSN/SES round-trip is
   many-small-file churn and is dramatically slower over the `/mnt/c` 9P mount. `git clone` it inside WSL.

(On bare Linux: just Docker + the NVIDIA Container Toolkit; skip steps 1–2 and the `/mnt/c` caveat.)

## Run

```bash
# Build the CPU compute container (matches versions.env KICAD_IMAGE)
docker compose -f docker/compose.yaml build routing

# Start the headless Freerouting REST server + the routing container
docker compose -f docker/compose.yaml up -d freerouting routing

# Route a board (the existing pipeline; Freerouting runs headless via xvfb-run in-container)
docker compose -f docker/compose.yaml run --rm routing \
    python3 scripts/cec_router.py --board eps-8pin --seeds 0,1,2,3 --passes 12 --opt-time 30

# Opt-in: bring up the local GPU inference server for the judge tiers (Thrust A)
#   set CEC_VLLM_IMAGE to a Blackwell-ready (CUDA 12.8 / sm_120) vLLM image first
docker compose -f docker/compose.yaml --profile inference up -d inference
```

Decision logs land in the gitignored `build/route/` (and accumulate in `build/route/corpus/` — the
training substrate for the surrogate ranker, Thrust C).

## Notes, caveats, and the things to verify

- **Freerouting 1.7.0 needs the FULL JRE, not `-headless`** (validated 2026-06-07 — this was the
  blocker that made every in-container route die). FR is a Java/**Swing** app: even run "headless" it
  constructs AWT/Swing objects on startup. `openjdk-21-jre-headless` omits `libawt_xawt.so` and
  hard-forces `java.awt.headless=true`, so FR throws `java.awt.HeadlessException` *even with a live
  Xvfb*. The Dockerfile installs the full `openjdk-21-jre`; `xvfb-entrypoint.sh` then gives that GUI a
  persistent virtual display (`DISPLAY=:99`) so `cec_fr` runs `java` directly (no per-run `xvfb-run`
  server-number races / zombie pileup; `compose.yaml init: true` reaps any orphans). Verified
  end-to-end from a clean image: `eps-8pin` routes 2 seeds in ~14 s, `kelvin_ok`/`diffpair_ok` pass,
  `drc=4` (the known LOGO1 + shield-tab floor).
- **`kicad-cli` has no Specctra export.** The DSN/SES round-trip rides KiCad's SWIG `pcbnew` bindings
  (`cec_fr.ExportSpecctraDSN`/`ImportSpecctraSES`), which work in the `kicad/kicad:10.0` image — the
  Dockerfile fails the build early if `import pcbnew` doesn't work. SWIG is deprecated upstream;
  the eventual migration is to the KiCad **IPC API server** (`kicad-cli api-server`).
- **Freerouting wiring.** Today `cec_fr` spawns the pinned **1.7.0** jar itself (works headless
  in-container via the persistent Xvfb above). The `freerouting` REST service + the
  `CEC_FREEROUTING_URL` env var are the **future path** (Task #2) — switching `cec_fr` to POST jobs to
  the REST API. Until that's wired, the REST service is just running alongside; the jar path executes.
  **Known gap (Task #2):** the official `ghcr.io/freerouting/freerouting` (v2.2.4) binds its API to
  `127.0.0.1:37864` *inside its own netns*, so it is not reachable from the host port-map or from the
  `routing` container (`freerouting:37864`) as shipped — wiring `cec_fr` to it needs a host-bind flag
  on that service first.
- **GPU sharing.** The 5090 is **not MIG-capable**: run at most one heavy GPU job at a time, or share
  via **MPS**/time-slicing. The `inference` service caps itself at `--gpu-memory-utilization 0.5` so a
  FEM/router job has headroom; since the judge tiers default to deterministic, keep it **off** unless a
  local LLM tier is actually engaged, leaving the whole GPU free.
- **vLLM image.** `vllm/vllm-openai:latest` may not yet support Blackwell `sm_120` cleanly — set
  `CEC_VLLM_IMAGE` to a known-good 5090 image (e.g. a CUDA-12.8 / PyTorch-≥2.7 build). Use **AWQ**
  (not FP8/FP4 — Blackwell FP8 tensor cores aren't usefully exposed through WSL2 dxgkrnl yet).
- **Core pinning.** When you run the inference server alongside routing, pin cores (E-cores → JVMs,
  a couple of P-cores → the inference host) and cap `--max-workers` to avoid the measured contention
  penalty. Not wired here yet — a follow-up under Task #4.

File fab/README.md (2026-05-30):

# `fab/` — release fabrication snapshots

This directory is **tracked on purpose**. It holds the exact package that was
sent to the board house, frozen per release, so any shipped board can be
reproduced bit-for-bit.

## Convention

- Snapshot fab outputs under `fab/<rev>/` **only at a tagged release** — not as
  routine churn on `main`.
- `<rev>` matches the release tag (for example `fab/hub-standard-v1.2/`).
- A snapshot is the complete board-house package: gerbers, drill files,
  pick-and-place (position) file, the BOM as sent, and any fab notes / stackup.

## Working outputs vs. snapshots

Day-to-day, generate fab outputs into the gitignored `build/` directory with
`scripts/fab.sh` (or `kicad-cli jobset run`). Those are regenerable from source
and are **not** committed. Only the release snapshot is copied here and tracked.

```
fab/
  <release-tag>/
    gerbers/
    drill/
    <board>-pos.csv
    <board>-bom.csv
    notes.md        # stackup, finish, panelization, board-house, order date
```

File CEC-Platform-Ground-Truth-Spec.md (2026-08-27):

# CEC Platform: Ground-Truth Specification

## Document control

| Field | Value |
|---|---|
| Document | CEC Platform Ground-Truth Specification |
| Version | 1.6.0 |
| Status | Controlled baseline |
| Date | 2026-07-24 |
| Companion files | cec-subsystem-power-management.svg (Section 2.9); cec_closed_loop_support_pipeline.svg (Appendix D) |
| Source of record | GitHub spec repository (canonical); record the source commit hash on every exported copy (process rule, 1.0.1) |

This document is the single source of truth for the CEC platform and takes precedence over every earlier document. Where an earlier document conflicts, this document governs. Every decision carries a status marker (LOCKED, PROPOSED, RESOLVED, or working basis), and every open item is tracked as a numbered open question (OQ-1 through OQ-89) in Section 10.

**v1.6.0 summary (2026-07-24, owner ruling):** USB-BACKFEED PROTECTION PACKAGE (beta line). With a CEC board USB-attached and a dead or faulty PSU connected, host VBUS back-feeds the PSU's 5VSB bulk through the module's ORing diode — owner-discovered and confirmed by transient simulation (~27 A peak; 0.5–22 mC per plug event against the ~50 µC USB inrush budget; ~400 mC sustained into a 2 Ω-faulted PSU = a guaranteed host-port eFuse trip). The Hub's host-USB leg was already safe behind its TPS2121 mux stages; this revision propagates that pattern. Ratified: (1) every beta Standard module's USB-C ingress becomes a TPS2121 priority power mux (the Hub part, LCSC C485916) — the module's 5VSB source and VBUS as the two inputs, the logic rail as the output, the SS34 ORing Schottky retired; input ISOLATION is the load-bearing mitigation, with ILIM (~1 A class) and an OV cutoff (~6 V, faulty-PSU margin) as defense-in-depth (Section 6.14). (2) A ~750 mA-hold polyfuse on VBUS ahead of the mux on every module (defense layer 2). (3) The Hub's KVM aux 5 V pin — as-built a RAW +5VSB rail tap — becomes a designed LOWEST-priority input via a third TPS2121 cascade stage (priority MAIN_5V > 5VSB > USB > wall-wart/KVM) plus a ~1.1 A-hold polyfuse, resolving-toward OQ-53/OQ-55 for the consumer tier (Section 2.9). (4) One first-article bench gate: the TPS2121's UNPOWERED reverse behavior (OUT driven at 5 V, both inputs dead) — the datasheet specifies reverse blocking only for a live device, and two shipped paths now rely on it. Interim bench rules recorded until the beta boards exist. BETA line only; alpha and the ordered rev2 boards are frozen as shipped. No LOCKED electrical decision is altered. See Sections 2.9, 4, 6.14, 9, 10 (OQ-53/OQ-55), Section 11 for the full entry, and `docs/usb-ingress-bom-delta-2026-07-24.md` for the per-board BOM delta.

### Versioning

This document uses semantic versioning, MAJOR.MINOR.PATCH:

- MAJOR: a change that breaks a connector pinout, a wire protocol, an interface, or cross-tier compatibility.
- MINOR: a new module, tier, section, or capability that does not break the above.
- PATCH: corrections, clarifications, and editorial changes with no design impact.

Version 1.0.0 is the first release under this scheme. It consolidates the pre-release working line v1.0 through v3.11, whose detailed log is retained for provenance in Section 11.1. Inline (vX.Y) tags in the body reference that pre-release log.

### Revision lines: alpha and beta (consumer hardware, owner directive 2026-07-03)

The document version above (semantic MAJOR.MINOR.PATCH) tracks the SPECIFICATION. Consumer *hardware* carries a parallel, orthogonal revision-line label:

- **ALPHA** — the existing validated consumer boards (Hub Standard and every Standard module). A working one-to-one prototype exists for each, so the concept is validated: alpha is refined, not re-litigated.
- **BETA** — any owner-approved refinement revision (the 2026-07-03 standard-tier review output and beyond). Beta is a new revision lineage *beside* alpha, never overwriting it — title-block Rev field, board README, `fab/<board>-beta-*` snapshot naming, BOM outputs — with alpha preserved in git history and its fab snapshots.

**Guiding principle for every revision (owner, 2026-07-03):** openness, extensibility, and make it better even if it costs a bit more — do it right the first time, better than everyone else does. When a trade pits cost-down against quality, capability, or extensibility, default to the quality side and surface the cost delta. Cheapest-possible is the rule for compute spend, never for the boards. Version 1.3.0 folds the owner-ruled consumer-beta decisions into this document; per-decision provenance is in the Section 11 revision log and `docs/standard-tier-review/beta-lock-register-2026-07-03.md`.

### Supersedes

- CEC Hub Standard v1.1 (Mini-Fit Jr connector): superseded on connector and cabling; other decisions carried forward.
- Module sensing architecture v3 (RJ-45 strategy) and v4 (INA228/INA238 selection): adopted, with v4 overridden on reference distribution, DETECT, pin-7 allocation, and 24-pin shunt values.
- Early CAN-FD / BOM thread (JST-XH interface, i.MX 93 Enterprise): superseded.
- CEC PCB-repo ground-truth (GitHub, 2026-05-30): reconciled; its Standard-module MCU lock adopted, and its 24-pin sensor, 12VHPWR Standard sensing, and platform-wide PoE drop addressed in Sections 2.4, 6.1, and OQ-14.
- Subsystem-power, NanoKVM, and Concierge branch (v3.4, 2026-06-04): architecture adopted (Section 2.9, Appendix C, the NanoKVM aux link, OQ-38 through OQ-56); stale board facts not imported.
- Design-review findings (2026-06-05): folded in; the EPS/PCIe transient-visibility ladder adopted as Section 6.13.

### Outstanding board actions

The specification leads the as-built boards on the items below. Each is to be carried on the next board pass.

1. FTP shielded RJ-45 jack (Section 2.1): boards carry the unshielded Amphenol 54602; FTP is the production target (OQ-37).
2. DETECT-pin ESD diode (Section 2.4): locked but not yet populated; the ordered 24-pin rev2 shipped without it.
3. 24-pin RJ-45 VCC no-connect (Section 2.7): rev2 carries the parallel path; the no-connect fix lands on rev3.
4. Digital-module MCU and detection front-end (Sections 6.1 and 6.13): the ESP32-C6/C3 change and the EPS/PCIe detection front-end are spec-adopted but not yet on the as-built schematics; the 24-pin, EPS, and PCIe are on the ESP32-S3-MINI-1 with no detection front-end, and the EPS was sourced on the S3-MINI-1-N4R2.
5. CAN transceiver on the fabbed 24-pin rev2 (Section 3.1): order-side records list the TJA1462A while the v3.5 lock and same-day schematic update name the TJA1051T/3; confirm which part the boards physically carry and, if the TJA1462A, migrate on the next pass. Pin-compatible SO8, both run classical 500 kbps, so no functional impact in the interim (added 1.0.1).
6. Output-side connector-daughterboard architecture (Section 2.8, v1.4.0): spec-locked for the 24-pin, EPS, and PCIe modules, but not yet on any as-built schematic or PCB. The 24-pin's second board-mount output header (J4) and the EPS/PCIe per-cable output headers still need removing, the inter-board connector (Keystone blade clips) placed on each main board, and the passive daughterboard projects (footprint, fan-out copper, and the mating TE FASTON tab side) created from scratch. 12VHPWR is unaffected (added 1.4.0).
7. USB power-ingress mux and the KVM third stage (Sections 6.14 and 2.9, v1.6.0): SCHEMATIC PASS LANDED on all six beta boards (2026-07-24, netlist-verified 2026-07-24): every beta Standard module carries the TPS2121 ingress mux (24-pin U5/U6 dual-stage into +5V_SYS; EPS/PCIe U4 and 12VHPWR U5 as VCC_RJ45-vs-VBUS single stage) with the VBUS polyfuse F1 (750 mA PTC, C371166) and ferrite ahead of the mux input and the SS34 ORing diode retired; the beta Hub carries the third KVM cascade stage U11 (+ F5 1.1 A PTC, C5707763), per-port VCC polyfuses F1-F4 (500 mA, C46640983), and the signed-off OV dividers R33-R38 on all three mux stages (U5/U7/U11); BOM CSVs regenerated per board. STILL OPEN: PCB placement/routing of the new parts on every board (owner-queue row), the 5.6 V-zener OV retune rider, and the v1.6.0 first-article unpowered-reverse bench gate. Until boards are fabbed, the v1.6.0 interim bench rules of Section 2.9 apply on any bench with a suspect PSU (added 1.6.0; board-state note updated 2026-07-24).

## Table of contents

- 1 Platform overview
- 2 Universal physical interface
  - 2.1 Connector
  - 2.2 Pin allocation
  - 2.3 DETECT: presence and comm-class sense
  - 2.4 Cross-connect and PoE protection
  - 2.5 Connector current rating and power budget
  - 2.6 Cable
  - 2.7 Hub bulk power input
  - 2.8 Module power-path connectors
  - 2.9 Subsystem power management
- 3 Communication architecture
  - 3.1 CAN: control and low-rate telemetry
  - 3.2 RS-485: data streaming only
  - 3.3 Precision voltage reference
- 4 Hub Standard
- 5 Hub Pro
- 6 Module sensing and current handling
  - 6.1 Production current-sensing summary
  - 6.2 Sensing granularity policy
  - 6.3 Module current targets
  - 6.4 Shunt selection
  - 6.5 Resolution and ADC range
  - 6.6 Thermal design
  - 6.7 High-current layout, stackup, and vias
  - 6.8 Kelvin sensing
  - 6.9 Pro module detail
  - 6.10 Acquisition model: continuous sampling, ring buffer, and ALERT
  - 6.11 12VHPWR Max module
  - 6.12 SATA / peripheral power module
  - 6.13 EPS/PCIe transient-visibility ladder
  - 6.14 Module standalone mode and common protection suite
- 7 ARGB Controller
  - 7.1 Tiers
  - 7.2 Power
  - 7.3 LED output stage
  - 7.4 Current sensing and self-description
  - 7.5 Communication and host integration
  - 7.6 Telemetry and reporting
  - 7.7 Licensing and channel
- 8 Cross-tier compatibility
- 9 BOM summary
- 10 Open questions
- Appendix A Spare-pair / USB architecture exploration
- Appendix B Compute tiers, FPGA versus MCU, and a Linux-free Enterprise
  - B.1 Why an FPGA on the Max, and what it buys over an MCU
  - B.2 Max capture-FPGA shortlist
  - B.3 A Linux-free Enterprise
  - B.4 Tooling and development effort
  - B.5 Current leaning
- Appendix C Concierge data collection
  - C.1 Principle and ownership
  - C.2 What the platform can produce
  - C.3 What Concierge must collect
  - C.4 Cadence and retention
  - C.5 Where computation happens
  - C.6 Golden-lifecycle data dependencies
  - C.7 The three vantage points
- Appendix D Support pipeline
  - D.1 Thesis: one loop, two halves
  - D.2 Pipeline definition
  - D.3 Zone model and design rules
  - D.4 Evidence model
  - D.5 Plan generation and validation
  - D.6 Execution and verification
  - D.7 Sign-off, corpus, and the golden unification
  - D.8 Economics model
  - D.9 Worked example
  - D.10 Definitions
- 13 The enterprise line (ENT-NET / ENT-AIR)
  - 13.1 Compute and identity
  - 13.2 Host links and northbound surface
  - 13.2a Module link
  - 13.3 The RJ-11 security-I/O port
  - 13.4 Power
  - 13.5 Redundancy — fail-detected, stated honestly
  - 13.6 Enterprise module build variants
  - 13.7 The NanoKVM boundary and the CEC-KVM direction
  - 13.8 Availability ladder (MC / MC-Max SKUs)
  - 13.9 Compliance posture
- 11 Revision history
  - 11.1 Pre-release working log
- 12 Index

---

## 1. Platform overview

The CEC platform is a modular PC power-telemetry system. Per-rail sensing modules connect to a central Hub over a single commodity cable. The Hub aggregates telemetry and forwards it to the host PC over USB. Three tiers, the third SKU-differentiated, are built from one fundamental design with progressively populated features:

| Tier | Role | Hub MCU | Host link | Distinguishing hardware |
|---|---|---|---|---|
| Standard | Mainstream builders | ESP32-S3 | USB Full Speed | CAN only, 4 ports |
| Pro | Overclockers, bench users | ESP32-P4 | USB High Speed | plus RS-485 streaming, 8 ports |
| Enterprise (ENT) — one line, SKU-differentiated | Regulated / financial / defense-adjacent / tamper-mandated fleets | PolarFire SoC (baseline MPFS095TC Core; HS option = S-grade Athena, 7th ruling) | Per posture SKU: ENT-NET = standard IEEE 802.3 1000BASE-T uplink (primary management plane) + USB (sensing/provisioning); ENT-AIR = local operator paths only, **zero network egress by design** | Hardened no-Linux RTOS control plane, PUF-rooted identity + secure boot, RJ-11 security-I/O port, rollback-resistant tamper log. **Two orthogonal SKU axes** — posture: ENT-NET (northbound Redfish-subset/OpenMetrics/syslog-TLS) / ENT-AIR (no network PHY populated, inspection-verifiable; radio-free module builds); availability ladder: **base** (fail-detected) → **MC** (+ independent compute watchdog + redundancy pack) → **MC-Max** (+ optional FAIL-FUNCTIONAL voting-pair compute) |

_D-ENT-6 RESOLVED (owner, 2026-07-02 second ruling): the legacy tier-3/tier-4 rows fold
into ONE enterprise line; "Mission Critical" survives as the MC / MC-Max availability
SKUs, orderable in either posture. See Section 13 for the full architecture._

Module **interfaces** are tier-agnostic and this is unchanged and LOCKED: any module works
in any Hub over the universal RJ-45/CAN/DETECT interface and degrades gracefully (Section
8). v1.2.0 adds enterprise **build variants** of the module families (Section 13.6):
same family, same interface, same graceful degrade — different build posture (radio-free
MCU, per-unit identity, provenance-grade BOM). A build variant never changes what the
Hub-facing interface promises.

Standard-tier module MCUs (REVISED v3.9): the three digital-sensor Standard modules (24-pin ATX, EPS 8-pin, PCIe 8-pin) run the **ESP32-C6-MINI-1**, on a board footprint that is also **ESP32-C3-MINI-1** compatible so the lighter 24-pin and EPS boards can be cost-reduced to the C3 once their NTC count is fixed (Section 6.1). The **12VHPWR Standard** module keeps the **ESP32-S3-MINI-1**, earned by its nine analog inputs and the option of N4R2 PSRAM for fast logging (Section 6.1), and the **Hub Standard** keeps the **ESP32-S3-WROOM-1-N16R8** (Section 4), deliberately retained for its native-USB host link and the benefit of one standard Hub part. This supersedes the v1.5 lock that ran all Standard modules on the S3-MINI-1; the rationale and per-module fit are in Section 6.1. The 12VHPWR Pro module runs the ESP32-P4 (Section 6.9), as does the proposed 12VHPWR Max (Section 6.11, P4 with PSRAM).

**Processing-placement principle (design rule).** Process at the lowest layer that cannot move the work up, and push everything else up. A device keeps only the processing that bandwidth or autonomy forbids relocating: the data reduction needed to fit its own uplink, and any decision it must make faster than a round trip to the next layer or while that layer is absent. Everything else, meaning classification whose result only ships upward, trend, history, cross-module inference, and presentation, belongs at a higher layer, where compute is amortized across modules, context spans the whole system, and an update lands in one place rather than across a fleet. The corollary is to prefer bandwidth over added local silicon: absent a hard autonomy requirement, give a node a faster uplink and let the layer above do the work, since each layer up (module, Hub, host, self-host service) is cheaper to build and easier to update in every way except latency and locality. This is the baseline that OQ-15 and OQ-20 (Max capture versus report) and OQ-7 (Enterprise build) resolve against. Overshoot signals, where work should move up a layer: a module storing history, a module running a learned model whose only output ships upstream, a module computing something that needs another module's data to mean anything, or any device sized for its peak-analysis case instead of its local-decision case. The compute-architecture leanings that follow from this principle, MCU plus FPGA on the Max and a Linux-free MCU-or-RTOS control plane on Enterprise, are recorded in Appendix B.5 and refine the simple Hub-MCU column above.

---

## 2. Universal physical interface

### 2.1 Connector (LOCKED)

- Module-to-Hub connector is **RJ-45 (8P8C)** for all tiers, all modules and Hubs. Mini-Fit Jr is retired platform-wide.
- **Locking-boot RJ-45 is the default** shipped in the box, chosen to remove the silent-dropout failure mode of a plain clip in a transported or vibrating chassis. Mechanical-keyed variants remain available for high-security deployments.
- Shielded jacks (FTP) on Hub and modules. (Board divergence: current prototype boards carry the unshielded Amphenol 54602 with grounded board-locks, OK for prototype bring-up; FTP is the production target, tracked as OQ-37.)

### 2.2 Pin allocation (LOCKED; two items pending)

| Pin | Cat5e pair | T568B color | CEC function | Tiers |
|---|---|---|---|---|
| 1 | Pair 1 | White-orange | VCC (+5VSB power) | All |
| 2 | Pair 1 | Orange | GND (power return) | All |
| 3 | Pair 3 | White-green | CAN1_H (control plus low-rate telemetry) | All |
| 4 | Pair 2 | Blue | STREAM_P (RS-485 data, module to Hub) | Pro+ |
| 5 | Pair 2 | White-blue | STREAM_N (RS-485 data, module to Hub) | Pro+ |
| 6 | Pair 3 | Green | CAN1_L | All |
| 7 | Pair 4 | White-brown | Standard/Pro: reserved spare, no-connect (no distributed reference; see Section 3.3). **Enterprise (v1.2.0, OQ-81, RESOLVED-BY-DIRECTION):** shared wired-OR hardware **SYNC/FREEZE** line — platform-wide simultaneous FREEZE trigger plus a PPS-class latch edge (≤100 ns module-to-module), and a per-module **heartbeat challenger** (hardware-timed challenge-response against the module device key). Legacy (non-ENT) modules remain NC-compatible; ENT modules enable sync only after the CAN handshake confirms an ENT Hub. See Section 13.2a and Section 13.8. | All |
| 8 | Pair 4 | Brown | DETECT (presence + comm-class, analog single-wire sense) | All |

Notes:
- CAN runs classical at 500 kbps on every tier, on the same pair (Section 3.1).
- Pair 3 (pins 3 and 6) is the T568B split pair but stays twisted in the cable; standard practice for differential CAN.
- Standard tier leaves pair 2 unused, terminated at the module side.

### 2.3 DETECT: presence and comm-class sense (LOCKED; OQ-6 resolved v1.7)

Pin 8 is an analog single-wire presence and comm-class sense. Each module carries one resistor from pin 8 to GND. The Hub reads pin 8 through a fixed 10k pull-up to its local 3.3V rail (not the 5VSB VCC, so the divider output stays inside the ADC input range), forming a divider it converts on an ADC channel.

The resistor encodes only what the Hub must know before the module talks: that a module is present, and which link to bring up on the port. Module category, exact type, tier, unique serial (the module MCU's factory MAC), and any per-unit data are reported over CAN on enumeration, which is an unlimited namespace. The pin therefore carries only the physical-layer decision, which keeps the code table small and fixed: it does not grow as module categories or models are added.

Enumeration is host-independent: identity rides CAN and the module network runs on 5VSB, so the Hub enumerates every module at power-up even with the PC off. The only thing a port-level sense or a host bus adds over that is the physical port-to-module mapping, which is needed solely to bring up a per-port streaming link, and that matters only when the host is present to consume the stream. So presence and identity never depend on the host, the sense line, or USB.

| Code | ID resistor (E24, pin 8 to GND) | V at pin 8 (3.3V, 10k pull-up) | Meaning |
|---|---|---|---|
| Link: CAN-only | 2.2 kΩ | 0.595 V | Standard modules and any low-rate module; no streaming receiver |
| Link: CAN + RS-485 | 4.7 kΩ | 1.055 V | Hub enables the RS-485 receiver on the port (Pro) |
| Link: CAN + 100BASE-T1 | 10 kΩ | 1.650 V | Hub brings up the 100BASE-T1 PHY (Max, contingent on OQ-20) |
| Reserved link A | 22 kΩ | 2.269 V | Future link type |
| Reserved link B | 47 kΩ | 2.721 V | Future link type |
| No module | open | ~3.3 V (rails to pull-up) | Port empty or cable broken |
| Fault | short to GND | 0 V | Solder bridge or damaged cable |

Codes sit ~0.45 to 0.62V apart, far above the worst-case error (ESP32 ADC nonlinearity, the 3.3V rail tolerance the ADC does not reference, and 1% resistors), so nothing collides. The resistor is a pure code, so it needs no precision or TCR spec; a standard 1% 0402/0603 is adequate, unlike the shunts. Because it is kΩ-scale, cable and contact resistance (under 1Ω, drifting with insertion cycles) is below 0.1% of the divider, so this sense is immune to the contact-resistance drift that helped kill the distributed reference.

Why 3.3V rather than 5V: the 5VSB on pin 1 could pull the divider up over a wider 0 to 5V span, spreading the codes further apart, but that gain does not survive the ADC. The ESP32 and S3 ADC top out near 3.3V with an absolute max around 3.6V on a pin that is not 5V tolerant, and an empty port pulls the line to the full reference, so a 5V pull-up puts about 5V on the ADC for every open port, over-ranging the read and stressing the pin. Scaling each port back under 3.3V at the Hub ADC would add a divider per port and land right back in the 3.3V window, so the span gain cancels. 5VSB is also a loose, noisy standby rail, looser than the Hub's local regulated 3.3V, and since the ADC references its own bandgap rather than the rail that error is uncompensated, which is the error the pin-7 Kelvin return exists to remove. A 5V line would also break the pin-8 module sense tap behind poke-and-ack, since the module ESP32 cannot take 5V either. The wider namespace a 5V span would buy is not needed, since identity lives on CAN and this table is small and fixed.

Limitation: the resistor maps a port to a link class, not to a unique module, so when two same-class modules coexist the Hub knows both ports hold (for example) an RS-485-class module but not which serial is on which port until it correlates over CAN. For the usual one-of-each build this never arises. If per-port unique identity ever becomes a requirement (repeated modules, Enterprise/MC fleets), the upgrade path is a 1-Wire ID and EEPROM on pin 8 with pin 7 as its return, carrying a unique serial and on-module storage read per-port and before boot. Not adopted here.

Port-to-identity binding (poke-and-ack, v2.6): the Hub binds each CAN-enumerated identity to its physical port without putting identity on the pin. Because the Hub holds a separate pull-up on each DETECT line, it briefly perturbs one port's line; the module on that port senses the change on a high-impedance pin-8 input tap and reports over CAN that its line moved; the Hub, knowing which port it poked, binds that serial to that port. It walks the ports in sequence, or drives a distinct low-rate pattern per port to bind them all in one pass. The code table is untouched and identity stays on CAN, so this spends no namespace: the pin carries one bit of per-port selection and CAN carries the identity. It runs host-independent at standby and re-runs on hot-plug for any newly announced module. It needs a module-side tap from pin 8 to a GPIO or ADC input (today's modules carry only the passive resistor), and it coexists with a pin-7 Kelvin return on the same pair.

Compatibility: the current prototype modules have no pin-8 sense tap, so they will not respond to a poke even on a Hub built with the feature. The Hub treats a silent port as a legacy module, still known from CAN and read for comm-class from the static divider, just not poke-bindable. So poke-and-ack is an opt-in enhancement that degrades to today's known-but-unbound behavior for any module without the tap, and a new Hub can freely mix poke-capable and legacy modules.

Pro and up can bind without the poke: a Pro module's per-port RS-485 streaming pair is already point-to-point, so bringing the receiver up on a port and seeing whose stream appears binds that port to its identity. A no-module-change option for hot-plug is per-port 5VSB current, where the port whose draw rises as a new identity announces on CAN is that module's port, though this cannot disambiguate a cold boot where every port powers up at once. Open details are in OQ-28.

Pin 7 candidate uses (exploration, v2.2; none adopted): the spare pin's realistic uses are narrow, because the architecture already covers the obvious ones elsewhere. The one concrete improvement is a dedicated Kelvin return for the DETECT divider: routing pin 7 as the divider's current-free low-side reference removes the IR-drop error from the module's 5VSB draw on the shared ground (on the order of 100 to 150 mV at a few meters and a few hundred milliamps), which scales with cable length (OQ-4). That conflicts with keeping pin 7 as a driven signal, so allowing both the Kelvin return on sensor ports and the deferred Max trigger (Section 6.11) on a Max port would require a per-port pin 7 at the Hub rather than one shared bus. Uses considered and set aside as redundant: 1-Wire identity and EEPROM (per-port identity is already the module MCU MAC over CAN, and per-unit calibration lives in module flash); a hardware power-state line from the 24-pin module (modules run on 5VSB and are on CAN before the main rails come up, so the co-capture FREEZE already covers the power-on transient, Section 6.10); out-of-band firmware recovery (modules have local USB, and a single line cannot sequence the ESP32 boot-mode entry); a second comm channel or a redundant power pin (CAN covers the first, and moving bulk power to the JST-XH feed removed any RJ-45 current pressure for the second). Pin 7 stays reserved pending a decision.

Resolved for the enterprise tier (v1.2.0, OQ-81, RESOLVED-BY-DIRECTION): pin 7 is allocated as the ENT hardware SYNC/FREEZE line plus per-module heartbeat challenger (see the pin-7 row in Section 2.2 and Sections 13.2a and 13.8); this decides against pin 7's other suitors, the 1-Wire identity return (OQ-76 — a device-key challenge-response is adopted instead) and the DETECT Kelvin return (OQ-60 note). Consumer and Pro tiers are unaffected: pin 7 there remains reserved, no-connect, pending a decision.

### 2.4 Cross-connect and PoE protection (RESOLVED for consumer, v1.9; Enterprise/MC deferred to OQ-7)

Decision (v1.9): consumer tiers (Standard and Pro) do not carry per-pin PoE-grade over-voltage protection on the RJ-45 module interface. This ratifies the board state and closes the consumer half of OQ-14.

Rationale: the RJ-45 here is an internal module-to-Hub interconnect inside the PC, not a port that faces building network wiring. Reaching it with 57V PoE means deliberately running a live PoE cable into an open case and into a telemetry jack, which is misuse rather than an accident. The realistic accident, plugging a module or Hub into an ordinary non-PoE network jack, puts only low-voltage Ethernet signaling on the pins, and the dominant interconnect (CAN, pins 3 and 6) runs through the TJA1051T/3, whose bus pins carry the automotive transceiver class's own bus-fault and ESD protection (confirm the exact fault and ESD ratings against the TJA1051T/3 datasheet). Dropping the protection also returns the VCC series-resistor drop to the 5VSB budget, removing the headroom tradeoff that the layout caution below was about.

One carve-out is decided on its own, separate from the PoE clamp: the DETECT pin (pin 8) feeds the ESP32 ADC directly and has no inherent protection, and the platform hot-plugs modules, so insertion ESD lands on a bare analog input. A single low-capacitance ESD diode on pin 8 is locked into every Hub and module (decision, v2.0). It is cheap, does not touch the 5VSB headroom question, and stands even though the PoE-grade network is dropped. The CAN pins lean on the transceiver; the analog DETECT pin is the one exposed node with nothing behind it.

Enterprise and Mission Critical (deferred to OQ-7): the module-to-Hub RJ-45s on those tiers are equally internal and inherit the consumer answer. What can face building infrastructure where PoE sources live is an external uplink, currently specced as the optional 1000BASE-T1 host link, which is a different connector with its own magnetics and protection story. So the over-voltage question for those tiers attaches to the uplink port, not the module interface, and is decided when Enterprise and Mission Critical are specified in full (OQ-7).

**Enterprise uplink protection (v1.2.0, closes the OQ-14 enterprise half).** The
protection lands on the ENT-NET 1000BASE-T uplink, not the module RJ-45s (which inherit
the consumer answer unchanged): magnetics galvanic isolation ≥2× the IEEE 802.3 1500 Vrms
floor as the primary defense (survives compliant PSEs by absent-PD-signature and passive
PoE injection by construction; Bob-Smith blocking caps rated ≥200 V), a low-capacitance
TVS array on the PHY side of the magnetics (IEC 61000-4-2 ±8 kV contact class), and a
3-electrode GDT on the shield-to-chassis path sized to IEC 61000-4-5 Level 2 —
office/rack grade by declared target fleet, NOT building-entrance grade (outdoor-plant
deployments use an external in-line SPD accessory, documented, never a board respin).
The uplink jack is visually distinct from module ports (bezel color plus silkscreen plus
board-edge grouping); module ports stay locking-boot per Section 2.1.

**Module-port mis-plug fail-safe (ENT re-scope of this section, 4th ruling
2026-07-02).** The consumer ratification (no PoE-grade protection on module ports —
internal interface, deliberate misuse) STANDS for Standard/Pro. On the ENT line the
presence of a real 802.3 jack on the same faceplate reclassifies the mis-plug as
FORESEEABLE misuse: every ENT hub module port and every ENT module jack SHALL survive a
live network cable and worst-case 57 V PoE (both modes, both polarities, passive
injectors included) with no hardware damage, self-recovering, detected plus alarmed plus
logged (REQ-HUB-COMMON-110 / REQ-MOD-COMMON-053; protection network per survey 11). The
consumer boards are unchanged; this is an ENT build delta, not a platform
re-ratification.

**Standalone-mode ESD/protection posture (consumer, v1.3.0, ruling H3).** The beta Standard modules gain a standalone mode (usable independently of a Hub over their own USB-C, Section 6.14). Because a module may then be handled and connected outside the Hub-mediated enclosure, the protection review widens from "the DETECT pin is the one exposed analog node" to "ESD on every externally touchable line under the no-hub assumption," and the module's USB data pair gains the same USBLC6-2SC6 plus VBUS clamp the Hub already carries. This is a consumer BETA build delta on the modules; it does not change the RJ-45 module-interface ratification above. See Section 6.14.

### 2.5 Connector current rating and power budget (corrected; bulk power resolved v1.3)

Correcting an earlier overstatement: a quality 8P8C contact carries roughly 1A continuously, and many connectors are rated 1.5A or higher, derated for cable bundling and temperature rise. This is consistent with how PoE works. PoE uses high voltage (roughly 48 to 57V) across multiple paralleled conductors, so even 90W Type-4 PoE puts well under 0.5A on any single conductor. CEC differs in two ways: it runs power at 5V (so roughly ten times the current of 48V PoE for the same wattage), and each RJ-45 carries a single VCC and a single GND pin with no paralleling.

Bulk power resolution (OQ-1): the Hub does not draw aggregate power through an RJ-45 VCC pin. The 24-pin module feeds the Hub over a dedicated 2-pin JST-XH 5VSB cable, and the Hub distributes 5VSB to each downstream module over that module's own RJ-45 VCC pin. So each RJ-45 VCC pin carries one module's draw only (roughly 0.1 to 0.5A depending on LED state), comfortably inside the contact rating. The aggregate now lives on the JST-XH feed and, upstream of it, the PSU 5VSB rail.

That leaves two shared limits, both in the 3A class: the JST-XH contacts and the PSU 5VSB rail, which CEC shares with the motherboard's own standby load. The dominant variable is the SK6812 LED chains. Seven SK6812 at full white draw on the order of 0.4A per board, so a fully populated Hub plus modules at full-white LEDs can push total 5VSB draw past 3A, exceeding both the JST-XH rating and the rail. The firmware current cap (OQ-2) therefore governs total 5VSB draw, not only the LEDs.

Required controls:
- Cap total CEC 5VSB current in firmware (the LED budget is the main lever) so the worst case stays within the JST-XH rating and the shared 5VSB budget with margin. Size against a ~2.5A rail to cover weaker PSUs and the motherboard's own standby draw. See OQ-2.
- RJ-45 per-module VCC pins: a connector rated 1.5A or higher is ample, since each carries one module.
- JST-XH bulk feed: confirm its contact rating covers the capped aggregate with margin (XH is ~3A class; a heavier series is available if more headroom is wanted than the cap provides).

The Hub-side bulk-power connector, its keying, and where it lands on the Hub front end are specified in Section 2.7.

### 2.6 Cable (mostly locked; lengths pending)

- Standard tier: quality Cat5e patch cable, FTP recommended near noisy GPUs.
- Pro and above with streaming active: Cat6 STP recommended for the RS-485 pair.
- CEC ships colored boots (bright orange) and labeled cables to differentiate from network cables.
- Patch-cable class (G2, owner sourcing 2026-07-03): the shipped in-case runs are a slim, highly flexible, braided RJ-45 patch-cable class; the specific part is owner-sourced, and the length catalog rides OQ-4.
- Cable length SKUs and the any-length versus fixed-length policy are pending (see OQ-4), because they interact with the precision-reference decision (OQ-3).

### 2.7 Hub bulk power input (LOCKED; resolves OQ-1)

The Hub receives bulk power on a dedicated 2-pin power-in connector, separate from the RJ-45 interface, carrying +5VSB into the Hub from the 24-pin ATX module (which taps 5VSB at the PSU's 24-pin connector). The Hub distributes that 5VSB outward to each port over the RJ-45 VCC pin. This holds for every Hub and removes the single-VCC-pin trunk constraint of Section 2.5: aggregate current no longer passes through any one RJ-45 contact, so the 8-port Pro is no longer the limiting case.

The connector architecture is locked; the specific part is the simplest one meeting the rating and is a working selection rather than itself locked:
- 2-pin, polarized and keyed against reverse insertion. Working selection: 2-pin JST-XH (~3A class). It is distinct from the retired Mini-Fit Jr and from the superseded JST-XH interface use; here it is a power-only feed. Step up to a higher-current 2-pin part (for example JST-VH) if the capped trunk budget grows.
- Documented rating at or above the capped aggregate with margin.
- Lands on the Hub's existing 5VSB front end: TPS2121 priority power mux (source-side reverse-current blocking + soft-start inrush limiting), the D1 reverse-isolation Schottky, the 4700 uF hold-up, and the TPS3839K33 supervisor, see the front-end architecture below. As an internal PC power lead it is not exposed to the commodity-cable cross-connect threat of Section 2.4, so it carries no per-pin over-voltage network; reverse-polarity and inrush protection still apply (now via the mux, not a discrete resistor/diode). Section 2.9 (subsystem power management) gives that mux + D1 a second job: blocking the shared monitoring rail and the forensic wall-wart from back-feeding up the 5VSB line into a dead PSU, so the mux's source-side reverse blocking must be confirmed against that path (OQ-55).

Hub Standard front-end architecture (PCB-repo design, folded in v3.2): the 5VSB-in and the USB-C VBUS are OR-ed through a **TPS2121 priority power mux** (PSU 5VSB preferred; USB VBUS is the backup so the Hub enumerates on a bench with no PSU connected). A **reverse-isolation Schottky (D1)** downstream of the mux feeds an **isolated +5V_HOLD reservoir node**, the 4700 µF aluminum-electrolytic hold-up cap and the LP5907 LDO input sit behind it, so the reservoir cannot back-feed or smooth the 5VSB rail the platform is measuring. (D1 is **built as SB120**, 1 A/20 V; **SS14**, 1 A/40 V, is a drop-in higher-margin alternative, either is adequate on the 5 V rail.) The mux's own soft-start (C_SS ≈ 2.2 µF) ramps the bulk-cap charge, so the v1.1 discrete 1 Ω 1 W inrush resistor and a separate reverse-polarity diode are **superseded** by the mux and are not populated. A divider on the shared +5VSB into an ESP32 ADC pin (GPIO8) is the **blackout-sense** input: on PSU power loss the MCU rides the +5V_HOLD reservoir (~tens of ms) and dumps its last telemetry window to flash. A small (~470 µF) bulk cap on the +5VSB distribution rail rides out downstream-module load steps. Measurement integrity holds because the PSU 5VSB is sensed upstream at the 24-pin module, ahead of the cable and the mux.

24-pin module dual-feed (LOCKED, v3.3): the 24-pin ATX module is unique in being both the bulk 5VSB **source** (over the dedicated JST feed above) and a normal module on a Hub RJ-45 port. Its **RJ-45 VCC pin (J1 pin 1) is left no-connect, not tied to the module's +5VSB**, so all bulk current flows over the JST as OQ-1 intends. The module is self-powered from its own 5VSB tap and never needs the Hub's distributed VCC; RJ-45 GND/CAN/DETECT stay connected (the parallel GND return is beneficial). This is required, not cosmetic: the JST lands at the Hub power-mux **input** and the RJ-45 VCC at its **output**, so the mux series resistance (~56 mΩ, TPS2121) sits in the JST leg only. Commoned on the module, the two VCC pins parallel each other, and a short RJ-45 patch makes the RJ-45 the **lower-resistance** path, it would then carry the majority of the bulk current on the 1.5 A-rated RJ-45 contact (over its rating near full load) and bypass the mux's PSU/USB OR-ing (back-feeding the +5VSB rail, e.g. leaking USB-only bench power into an unpowered 24-pin). Other modules are unaffected, their RJ-45 VCC is their only 5VSB source and stays connected. The ordered rev2 24-pin carries the parallel path; the board docs hold the prototype-run mitigation and the Hub-side workaround options, and the no-connect fix lands on rev3.

**Beta power-in consolidation (v1.3.0, Hub Standard J_PWR).** The beta Hub consolidates the two separate 2-pin feeds — the dedicated 5VSB input of this section and the Section 2.9 MAIN_5V source tap — into ONE 3-pin JST **S3B-XH-A** (3 A/pin; LCSC C157928), pin order 1 = MAIN_5V, 2 = GND (center), 3 = 5VSB. Center-GND ordering makes any misinsertion benign and the XH shroud blocks reversal; net names are unchanged (MAIN_5V_RAW / GND / 5VSB_RAW). This is exactly the production single-feed consolidation this section and Section 2.9 flagged as a follow-up. The consumer alpha boards keep the two 2-pin feeds (kept separate on alpha so the existing 5VSB cable and Hub bench-test still work); production/kit builds move to J_PWR.

**Rev3 dead-bug stack supersession (2026-08-03; authoritative for the current BETA line).** The segmented Hub/24-pin mezzanine now carries the 24-pin board's already-selected **+5V_SYS** on J6P pins 1/3/5 with ground on 2/4/6. It therefore supersedes and retires the Hub's `J_PWR`, `MAIN_5V_RAW`, and `5VSB_RAW` cable entry and the redundant first Hub TPS2121 stage. The retained Hub source chain is: J6P +5V_SYS into U7 primary; service USB VBUS into U11 primary; fused NanoKVM 5 V into U11 backup; U11 output into U7 backup; U7 output is the final selected +5VSB rail. This paragraph supersedes the v1.3.0 J_PWR realization above without rewriting its historical decision record.

### 2.8 Module power-path connectors (PSU side): interposer cabling (LOCKED, repo v1.6; folded in v3.2; output side superseded and EPS/PCIe locked, v1.4.0)

Separate from the universal RJ-45 module-to-Hub interface (Sections 2.1 to 2.7), each sensing module is a power-path interposer: PSU rail current enters the module, passes through its shunts, and continues to the load. The PSU-side connectors are module-specific (not universal) and are locked per module as follows.

**24-pin ATX module — input unchanged; output is the connector-daughterboard architecture (LOCKED, v1.4.0; supersedes the v1.6 two-male-header output form and its female-to-female bridging cable, owner ruling `SYNTHESIS-beta-plan.md` §D-5a, 2026-07-04).** Gender convention for the input side is unchanged: the board-mounted header is **male** (pin-side), and a cable end that plugs onto it is **female** (socket/receptacle).
- Input (J3, PSU side): unchanged. A Molex Mini-Fit Jr (5569 family) 24-circuit **male header**; the PSU's existing cable (a female receptacle housing) plugs directly onto it. No new cable is needed here.
- Output (motherboard side): the module no longer carries a second board-mount male header (J4), and the CEC-supplied female-to-female 24-pin ATX bridging cable this section previously mandated is retired (see the kit-cable paragraph below). Output rails instead cross an **inter-board connector** to a **passive daughterboard** — no active or passive components beyond the connector body and its fan-out copper, sized to the Section 6.4 current class, thick copper by design — stood off the main board and mechanically secured, with strain relief provided by the chassis (stand-off geometry, keying against mis-seat, and the strain-relief pull-force/flex-cycle numbers are OQ-87). The daughterboard is populated EITHER with a PCB-mount vertical female header at the through-hole field OR a soldered pigtail, and may itself be sold as a daughterboard-plus-extension-cable assembly, soldered at the through-holes with its own strain relief (a productized accessory; SKU definition is OQ-89).

**Inter-board connector class (LOCKED, v1.4.0): the all-Keystone/TE tool-less blade configuration is the platform default,** applied **per cable** (per-cable daughterboard shape, not one wide daughterboard spanning every cable — a shared connector housing derates further under mutual heating as more contacts populate it, breaks fault isolation across cables, and would prevent an independent per-cable sellable-assembly swap). The main board carries Keystone universal-entry 30 A blade clips (SMT 3586, LCSC C238113, or THT 3557-2, LCSC C352820); the daughterboard carries the mating TE FASTON .250″ PCB tabs (63849-1, LCSC C86469) — the sellable daughterboard-plus-extension assembly therefore carries the four-cent tab side. Ratified joint counts, sized to the margin policy (continuous rating ≥125% of sustained worst case at ≤30°C rise, matching this document's own electrothermal-gate convention): **24-pin 9** (12V ×1, 5V ×2, 3.3V ×1, 5VSB ×1, GND ×4), **EPS 12** (3 contacts per polarity per cable, ×2 cables), **PCIe-2 8** (2 per polarity per cable, ×2 cables), **PCIe-3 12** (2 per polarity per cable, ×3 cables). Design-basis currents (owner, 2026-07-04): EPS 8-pin ~13 A/pin continuous sustained (brief transients run higher) → ~52 A/cable sustained worst case; PCIe 8-pin the same ~13 A/pin theoretical, only 3×12V pins → ~39 A/cable; 24-pin anchors on the 6 A/circuit ATX bar (cross-checked, not superseding, the OQ-11 shunt figures). Design rule (owner): design to worst case with margin, but keep transients as transients and sustained as sustained — never fold a transient peak into the continuous rating; all figures are AWG-dependent, and CEC's own extensions use 16 AWG.

Mating force on this joint is deliberately high (owner ruling, 2026-07-04): high insertion force is a **feature**, not a defect — the joint is not meant for constant swapping, and a mis-seat or pull-out is absolutely unwanted. The mating-force concern raised against the blade configuration is accordingly **dismissed as a qualification gate**, not scheduled for bench measurement.

Ratification carries exactly one physical gate before first fab: a sample fit check across the mating clip and tab parts ("as long as the tabs and whatnot fit together," owner, 2026-07-04) — a first-article bench item, not an open spec question. Recommended (not gating) engineering follow-up, procurement notes, and the committed fallback connectors (stacked Keystone 8197 screw configuration; Würth REDCUBE 85 A as a zero-qualification proto rung; the 24-pin HPCE vertical/mezzanine premium alternative) are OQ-86.

**EPS 8-pin and PCIe 8-pin modules — output side now explicitly LOCKED (v1.4.0; closes a pre-existing documentation gap).** This section previously locked an output-side connector form only for the 24-pin and 12VHPWR; it did not lock one for EPS or PCIe, even though the as-built boards generalize the 24-pin's paired-male-header pattern per cable. EPS and PCIe now carry the identical rule, applied **per cable**:
- Input: unchanged. A board-mount male Mini-Fit Jr header per cable; the PSU's cable plugs directly onto it.
- Output: superseded identically to the 24-pin — one inter-board connector and one passive daughterboard **per cable**, each on the all-Keystone/TE connector class and ratified joint counts above, sized to that cable's own current class (Section 6.4).

**12VHPWR modules (Standard and Pro), connectors soldered to the board — UNCHANGED, explicitly out of scope for the 2026-07-04 ruling.** The 12VHPWR module does not use detachable pass-through headers, a bridging cable, or a daughterboard. Its 12VHPWR (12V-2x6) connector(s) remain soldered directly to the module PCB (board-mounted); on the platform's highest-current, melt-prone connector this removes a mated-contact pair from the power path and keeps the connection deterministic, a rationale the owner re-confirmed 2026-07-03 ("direct soldered pigtail CONFIRMED... no detachable junction in that power path, period"). Sideband pass-through (added v3.8): the inline 12VHPWR module passes the four 12V-2x6 sideband pins, SENSE0, SENSE1, CARD_CBL_PRES#, and CARD_PWR_STABLE, from the PSU side to the GPU side unmodified, so the GPU reads its correct power budget through the interposer. This is implemented on the PCB models and is recorded here so it survives a respin or a hand-off. Soldered-joint strain relief (design note, v3.8): the soldered PSU-side high-current joints carry roughly 8 to 10 A per conductor balanced and will fatigue the pad under cable flex over thermal cycles, so clamp or pot the cable entry. The joint is permanent, with no field swap, and is an assembly step for any standalone SKU.

Hot-plug scope (added v3.8): hot-plug applies to the RJ-45 telemetry interface (CAN and 5VSB, with the DETECT pin ESD-protected per Section 2.4), which the platform hot-plugs and re-enumerates (Section 2.3). The monitored inline power path of this section, daughterboard included, is not hot-pluggable under load: a module is inserted into the rail with the PSU off, like any inline power component.

**Kit-cable direction — SUPERSEDED (v1.4.0).** The D-1 custom-female-pigtail direction recorded in v1.3.0 (a female pigtail that would "effectively create a board-mount female header" — the missing part the old section's whole premise turned on) is realized here as the daughterboard's soldered-pigtail option, rather than as a retrofit onto the retired male-J4 output form it was originally weighed against. The gender-logic finding on the record stands as the reason a female-out interface was worth pursuing at all: a female-out module mates with the entire standard male-header/female-cable extension ecosystem exactly like a PSU cable, while a male-out module mates with nothing standard. The LOCKED-today female-to-female 24-pin bridging-cable SKU is retired as a direct consequence of the output form above; its sellable-assembly replacement is defined in OQ-89. The kit-cable panel connectors (about $0.20 each, unaffected by this revision) and the original v1.3.0 note are preserved for provenance in Section 11.

### 2.9 Subsystem power management (PROPOSED; architecture adopted, parts and module-rail scope open)

The monitoring subsystem (the Hub, the NanoKVM, and on the open fork below the module fleet) draws from one of three 5V sources, selected in hardware, with firmware setting the load budget and operating mode to match. This does two things the single-5VSB feed of Section 2.5 cannot: it escapes the S0 limb of the 5VSB budget, and it lets a customer recover the Hub's data from a completely dead system without opening the case.

Sources and priority (high to low):
- **PSU main 5V**, present when the PC is running (S0), tapped downstream of the 24-pin module's 5V sensor so the subsystem's own draw is measured and counted in system 5V rather than hidden in standby overhead (OQ-13). This is the large rail (the 24-pin 5V is sized for 20A), so it carries the high-draw S0 state, LEDs included.
- **PSU 5VSB**, present whenever the PSU has AC, over the 24-pin module's existing JST-XH feed (Section 2.7). The standby rail, roughly 2.5 to 3A shared with the motherboard standby, governed by the OQ-2 cap. The JST feed taps 5VSB downstream of the 24-pin module's own 5VSB sensor (the sensor sits ahead of the cable and the mux per Section 2.7), so the subsystem's standby draw is counted in the 5VSB figure, parallel to the S0 main-5V case (OQ-13). This defines the standby (S5) energy content; confirm the tap point against the 24-pin board.
- **Wall-wart 5V**, present only when a customer plugs a 5V USB supply into the NanoKVM's USB-C with the PC fully dead. The last-resort forensic source.

Source selection is hardware, a priority ideal-diode OR (main 5V, then 5VSB, then wall-wart), rather than a firmware switch. This extends the Hub's as-built TPS2121 PSU/USB priority mux (Section 2.7) from two inputs to the three subsystem sources, the same TI PowerPath family the OQ-55 part search names (TPS2116 / LTC4412-class). Firmware runs on the Hub MCU, which is powered by the rail it would be switching, so a firmware-controlled switch can deadlock the MCU if it selects a source that is not solid. The firmware instead reads which source is live on a rail-sense and sets the load budget and mode: full budget and normal monitoring on main 5V, the standby cap (OQ-2) on 5VSB, and a minimal LEDs-off forensic-extraction mode on the wall-wart. It may gate the main-5V enable once the PC is confirmed stably up, but the 5VSB fallback stays hardware-automatic. This is priority switching, with the OR isolating the idle inputs, and the rails are never paralleled to sum their capacity, which they do not need since main 5V alone is ample.

Back-feed isolation is the safety-critical rule. Every source feeds the shared rail through its own ideal diode or series element, and the shared rail must never push power back toward a source or into a dead system. In particular the wall-wart, when it is the source, must not travel up the Hub's 5VSB input into a dead PSU's standby rail and the motherboard, nor up the NanoKVM's slot path into the dead PSU. The Hub's existing TPS2121 priority power mux (Section 2.7) already provides source-side reverse-current blocking on its 5VSB input, and the downstream D1 reverse-isolation Schottky walls off the +5V_HOLD reservoir; confirm the mux's reverse blocking covers the shared-rail path back into the 5VSB source, and add the matching isolation on the NanoKVM's slot input.

The shared rail spans the Hub-to-NanoKVM cable, so both boards sit on it and the cable's 5V conductor carries the subsystem current in whichever direction the live source dictates: Hub to NanoKVM on the PSU rails, NanoKVM to Hub on the wall-wart. Size that conductor and its ground for the full subsystem draw. The power feed shares the reserved aux header and cable with the UART link of Appendix C.7: a single **5-pin right-angle JST-PH** header (S5B-PH-K-S) carries the shared 5 V, ground, the full-duplex 3.3 V UART (TX/RX), and the NanoKVM's 3.3 V reference/presence line, the full set of pins the NanoKVM brings out on its own header (UART1 TX/RX, GND, 3V3, 5V/GND; its two header grounds common at the connector). There is no separate trigger conductor: the NanoKVM exposes no drivable interrupt input, so event triggers ride the UART in-band (resolved, OQ-51 v3.7). Whether the module fleet also rides this shared rail (the whole-platform dual-feed that frees on-board LED brightness on a maxed build by moving the operating draw to main 5V in S0) or stays on 5VSB-only with the discretionary loads offloaded individually (per-load) is OQ-53.

Forensic recovery (the dead-system case, ties OQ-48). With no PSU power, the customer plugs a wall-wart into the NanoKVM's externally accessible USB-C. That powers the NanoKVM, which powers the Hub over the shared rail, so the monitoring island runs decoupled from the dead PC. The Hub serves its persisted data to the NanoKVM over the UART, and the NanoKVM egresses it over its own Ethernet or WiFi, so the data comes out without opening the case or reviving the PSU. The draw in this mode is the Hub plus the NanoKVM with the LEDs off, around an amp, which any phone charger covers. The external power-in is the NanoKVM's USB-C if it is bracket-accessible on the PCIe card; a CEC power-in port on a rear bracket is the more general option and also revives a Hub-only build (OQ-54).

Persist-on-fault. Forensic recovery returns only what the Hub already wrote to its 16 MB flash, since the volatile ring buffers are gone the instant power dropped. The Hub therefore flushes critical events and frozen windows to flash as they occur, with a final flush on total power loss that the 4700 uF hold-up rides, which gives the hold-up cap a second job beyond the source changeover and sets part of its sizing (OQ-56).

CEC subsystem power management

```text
# ===========================================================
# CEC monitoring-subsystem power management
# ===========================================================
#
# HARDWARE (automatic, no firmware in the loop):
#   3 x 5V sources feed ONE shared monitoring rail through a
#   priority ideal-diode OR. Priority: main 5V, then 5VSB,
#   then wall-wart. Every source is isolated, so the shared
#   rail can never push power back toward a source or into a
#   dead system.
#     main 5V  : tapped downstream of the 24-pin module's 5V
#                sensor, so the subsystem's own draw is measured
#                and counted in system 5V (OQ-13)
#     5VSB     : the 24-pin module's existing JST-XH feed;
#                Hub TPS2121 mux (Sec 2.7) blocks back-feed
#     wall-wart: 5V into the NanoKVM USB-C (external bracket),
#                isolated from the NanoKVM slot-power path
#   Hub and NanoKVM both sit on the shared rail, which spans the
#   inter-board cable; the 5V conductor carries the subsystem
#   current in whichever direction the live source dictates.
#
# FIRMWARE (Hub): never switches the source (that would deadlock
#   the MCU doing the switching). It senses the live source and
#   sets the load budget and operating mode to match.

state ACTIVE_SOURCE   # MAIN5V | SB5VSB | WALLWART | NONE
state MODE

loop every control_tick:
    src = read_rail_sense()                  # ADC/GPIO on the rail
    if src != ACTIVE_SOURCE:
        ACTIVE_SOURCE = src
        switch src:
            MAIN5V:                          # PC running, large measured rail
                set_budget(led = FULL,       load = FULL)
                MODE = NORMAL_MONITORING
            SB5VSB:                          # PC standby, ~2.5A shared rail
                set_budget(led = STANDBY_CAP, load = STANDBY_CAP)   # OQ-2
                MODE = STANDBY_MONITORING
            WALLWART:                        # PC dead, external forensic power
                set_budget(led = OFF,        load = MINIMAL)
                MODE = FORENSIC_EXTRACTION

    if MODE == FORENSIC_EXTRACTION:
        serve_persisted_records_over_uart()  # NanoKVM pulls, egresses over net

# -----------------------------------------------------------
# Persist-on-fault: forensic recovery returns only what is in
# flash, so critical data is persisted as it happens, with a
# final flush on total power loss that the hold-up cap covers.
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

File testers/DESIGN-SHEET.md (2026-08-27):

# PSU tester board family — exhaustive design sheet (pipeline input)

> **STOP WORK — mandatory gate (2026-08-10).** Do not advance, copy, route,
> fabricate, or order any Tester design until
> `docs/tester-stop-work-reconciliation-gate-2026-08-10.md` is explicitly
> released under its Section 4 evidence and owner-decision requirements.

STATUS: DRAFT v0 (2026-07-16). The design contract for every board under
`testers/` — floorplan zones, per-component placement rules, routing
standards, stackup, and the gates the platform pipeline enforces. Package-
specific rows marked **(fill at BOM v1)** complete when the sourcing agents'
results integrate into `docs/psu-tester-bom-draft-2026-07-16.md`. Design
basis of record: `docs/psu-tester-exploration-2026-07-14.md` (+§6 ruling),
`docs/psu-tester-architecture-sketch-2026-07-16.md` (REV B + §3b/3c/3d/§10–12),
`docs/psu-tester-component-research-2026-07-16.md`. Nothing here alters a
LOCKED platform decision; the blade interface rules inherit §2.8/iteration-7
verbatim.

## A. Board census (who exists and why)

| Board | Tiers | Why it is its own board |
|---|---|---|
| `tester-standard/` | ST-1000/1300 (population variants, same copper) | C6-class control, no fast channel/OVP/streams — different compute + loop count than Pro |
| `tester-pro/` | Pro + **Pro SE** (~3 kW population variant, §H) | P4 + RS-485 + OVP-A + 8 verniers + SCP |
| `tester-max/` | Max + **Max SE** (~3 kW population variant, §H) | Pro superset + on-board digitizer lane (AD9253+GW5A LVDS must stay short) + T1 PHY |
| `fast-channel-slice/` | Pro ×1, Max ×2 | The µH-budget lives at the fixture — the slice's copper IS the circuit; separable bench-gate prototype |
| `slot-deck/` | all | Thick-copper blade fields + load-bus routing + Hub bay; mechanically chassis-bound, revs with fixture geometry not electronics |
| `hpwr-fixture-head/` | all | The per-test wear position; replaceable by design |

AC sense pod: PARKED (owner) — no folder until un-parked. R-bank plates:
chassis metalwork + lug wiring, NOT a PCB (bank switching FETs/fuses live on
the main board; only heavy wire crosses).

**"Smoke Tester" — STOOD UP on the beta line (owner directive 2026-07-24; folder
`beta/smoke-tester/`, sketch-stage):** sacrificial first-contact triage box —
per-rail blade fuse + crowbar fault-converter (a fuse alone cannot catch
mains-on-a-rail), blade+HRC 250 VAC coordination, neon hot-ground CASE-LIVE
detector, relay-armed PS_ON, needle meter, pure analog, terminator-only (never
inline). Workflow position: ahead of everything in this census (Smoke Tester →
module/ST deck → Pro/Max). Spec of record: `beta/smoke-tester/README.md`; concept +
decision list: `docs/smoke-tester-concept-2026-07-24.md`.

**DUT INPUT INTERFACE — replaceable straight-through boards (OWNER-RULED 2026-07-25:
"just a straight-through connector… they sell those off the shelf, ModDIY probably —
can just resell those").** Every deck slot's DUT-facing plug-in position is a
REPLACEABLE STRAIGHT-THROUGH CONNECTOR BOARD, not the module's own header: the DUT
cable mates with a cheap board carrying the family male header, wired through to the
module behind it. Per-DUT matings and mechanical abuse land on a $2–5 part; modules
($35 ST … $600+ Pro/Max) never accumulate matings. SOURCING POSTURE (ruled): resell
off-the-shelf ModDIY-class straight-through/jig boards where they exist (24-pin/EPS/
PCIe) — with the STANDING MODDIY CAVEAT carried from OQ-86/88 verbatim: DIY-category,
provenance-unverified, prototype-OK, the resold/sellable version needs the bench
qualification pass (catalog check + sample order = owner desk item). MONITORING (no
sense contacts on an off-the-shelf board): the tester program stores a per-head
BASELINE at install and trends ΔV/ΔI across load steps against it — head-contact
drift becomes a firmware alarm ("replace input board, slot N") using measurements the
modules already make (OQ-85 row). UPGRADE RUNG (only if metrology demands): our own
head PCB with the OQ-88 sense-return contacts populated (port-end Kelvin, the 12d
pattern) — decision deferred until a bench case shows baseline-trending insufficient.
EXCEPTION: 12VHPWR keeps the designed `hpwr-fixture-head` (already in this census) —
melt-class per-pin monitoring is load-bearing there and an unmonitored straight-through
contradicts the §2.8 minimal-mated-pairs rationale. Consumer modules: UNCHANGED
(cycle counts moot outside the deck).

## B. Floorplan doctrine (zones, in airflow order — sketch §4 is binding)

```
MAIN BOARDS (front→back = cold→hot, the airflow path IS the layout):
[Z1 FRONT/COOL ≤45°C] MCU, DAC, op-amp loop fronts, loop shunts, USB-C+PD,
                       CAN/RS-485/T1, trip comparators, OVP stage, aux bucks
[Z2 FET ROW]           vernier L2 devices ON the extrusion edge (board edge-
                       mounted TO-247/264 row), gate networks + NTCs at pins
[Z3 BANK SWITCHING]    bank NFETs + fuses at the rear edge, lug fields to the
                       chassis R-plates; SCP crowbar blocks at their fixture
                       feeds (electrically Z3, physically at the front bus —
                       see C rules)
[Z-BUS]                the heavy load return bus bar / pour spine runs the
                       board spine; STAR GROUND at its single tie point
```

- Zone boundaries are keepout-enforced in the pipeline (corridor keepouts,
  same mechanism as the module high-current corridors).
- The slot deck sits ABOVE the main board plane (chassis standoffs); heavy
  interconnect = bolted bus/lug or blade-class joints, never board-to-board
  headers carrying load current.
- Thermal gradient rule: nothing precision (shunts, references, DAC) may sit
  downstream of Z2 in the airstream (sketch §4 precision-zone rule).
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

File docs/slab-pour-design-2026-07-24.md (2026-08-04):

# Slab-pour architecture: subtractive power copper (owner concept, 2026-07-24)

> **Implementation status, 2026-08-02.** The declared-current slab allocator,
> minimum-width gate, current-source provenance, pickup synthesis, stale-zone
> removal, and fail-closed Hub rebuild path are implemented. The system does not
> claim that every present placement is pourable. Current Hub and ATX diagnostics
> stop on missing anchors, current-source conflicts, or minimum-width failures.
> See `beta-placement-passives-audit-2026-08-02.md` for measured results.

**Status: RATIFIED DIRECTION (owner, 2026-07-24 in-session), partially implemented and gated.**
Owner's concept, verbatim intent: *"make a pour just a giant slab, intentional
overshoot in all directions, and progressively shave off areas of it until it fits
and doesn't take up more space than it needs, and no cross-section on it is less
than the min cross-section allowed for that pour."* Plus the priority ruling:
*"this would be an early rung on the ladder — the pour takes priority and gets its
route first before everyone else gets to encroach."*

## Why (the evidence)

Every pour defect caught on 2026-07-23/24 was an OUTLINE-DERIVATION failure of the
constructive approach (small rects derived from pads/asks): the 0.4mm rect miss at
RS1's via rows (severed In2/B rail legs), dead unbonded mirrors, 8-13% lace fills,
bond-planting refusals. A maximal slab cannot miss anything by construction;
material is then removed only for a MEASURED reason. Coverage becomes structural,
ampacity becomes a closed-loop invariant instead of an aspiration.

## The two-part slab (reconciling priority-first with the no-strand lesson)

The 2026-06-07 measured lesson stands: an immutable pour laid before routing walls
FR off and strands sense taps. The owner's slab is negotiable-but-floored, which
splits cleanly:
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

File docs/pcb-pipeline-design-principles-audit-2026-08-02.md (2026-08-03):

# PCB pipeline design-principles audit — revised 2026-08-03

## Scope and release meaning

This is an independent audit of the automated placement, routing, copper, and
fabrication pipeline. It does not assume that the existing design notes or
checked-in candidates are correct. The audited current BETA inputs are exactly
the ten entries in `scripts/cec_beta_manifest.py`: 12VHPWR, ARGB, ATX rev3,
EPS rev3, Hub rev2, both PCIe products, and the three output daughterboards.
Discovery is manifest-only; archived or recursively discovered board folders
cannot enter the current audit.
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

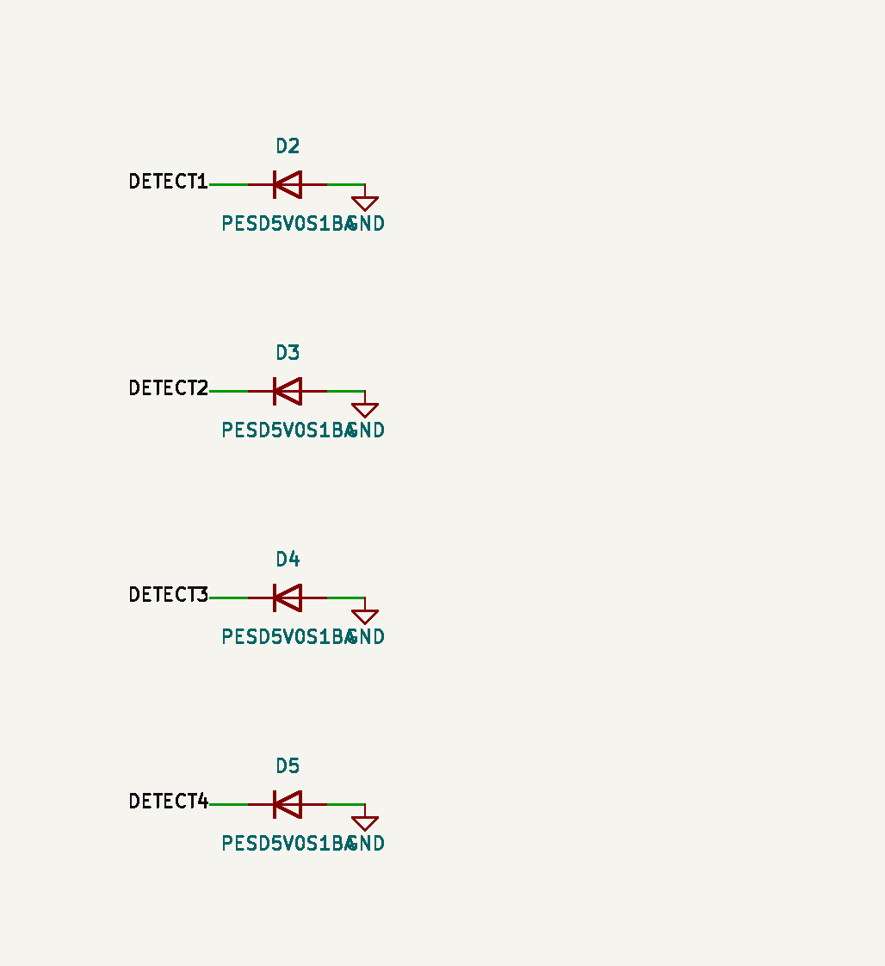
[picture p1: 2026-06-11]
docs/cl19-trace-gallery-2026-06-10/spots/hub-detect-esd-d2-d5.png

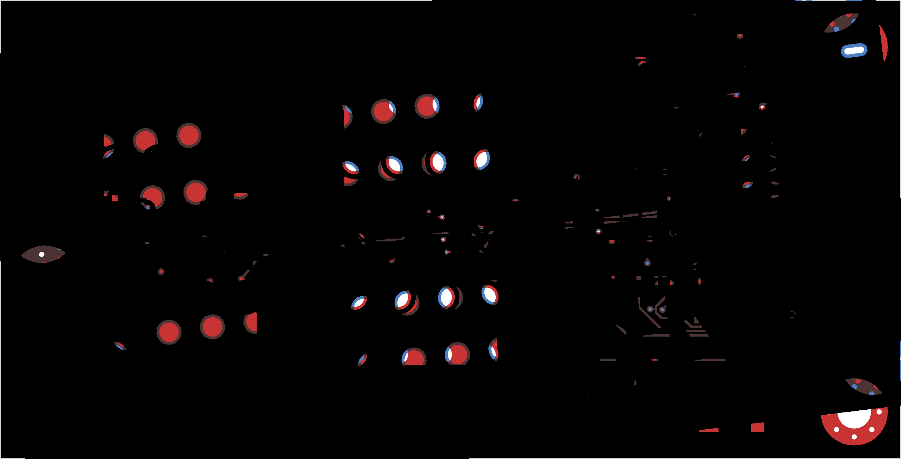
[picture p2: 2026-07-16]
docs/det-inspection/incremental-samples/rotated_layer.png

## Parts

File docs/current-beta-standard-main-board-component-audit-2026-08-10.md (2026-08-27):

# Current Beta Standard schematic and component-coherence audit

**Status: no source-level electrical blockers -- regenerated from current
source on 2026-08-12. Qualification warnings remain open. PCB fabrication
readiness is deliberately not evaluated.**

Machine-readable evidence is regenerated with
`python3 scripts/cec_beta_electrical_audit.py --scope standard-main --json-out docs/current-beta-standard-main-board-component-audit-2026-08-12.json`.
That snapshot records the exact manifest board list and a SHA-256 digest of
every root/child schematic used for each board. Conclusions in this document
must not be revised without regenerating that evidence first.

This document reviews electrical coherence in the current Standard Beta root
schematics and BOM selections. It asks whether the selected parts, values,
ratings, pin connections, support networks, and interfaces agree with their
manufacturer guidance and with the intended board function.

PCB synchronization, DRC, routing, trace width, placement, stackup, vias,
footprint manufacturability, and assembly process are outside this review.

## 1. Current Beta scope

The authoritative scope comes from the executable
`STANDARD_MAIN_BOARDS` set in `scripts/cec_beta_manifest.py`. The six
current Standard main-board schematics are:

| Board | Current root schematic |
|---|---|
| ATX 24-pin rev3 | `beta/atx-24pin-rev3/24pin-module.kicad_sch` |
| EPS 8-pin rev3 | `beta/eps-8pin-rev3/eps-8pin-rev3.kicad_sch` |
| PCIe 8-pin 2-port | `beta/pcie-8pin-2port/pcie8pin-2port-module.kicad_sch` |
| PCIe 8-pin 3-port | `beta/pcie-8pin-3port/pcie8pin-3port-module.kicad_sch` |
| 12VHPWR Standard | `beta/12vhpwr-standard/12vhpwr-standard-module.kicad_sch` |
| Standard Hub rev2 | `beta/hub-standard-rev2/hub-standard-rev2.kicad_sch` |

ARGB, daughterboards, Tester boards, generated candidate PCBs, archived
projects, Alpha boards, and the obsolete `eps-8pin` product are excluded. All
findings below come from fresh exports of these six root schematics. The Hub
was omitted in the earlier prose revision despite already being a current-wave
manifest board; the executable scope gate now prevents that class of drift.

## 2. Electrical verdict by board

| Board | Schematic/component verdict | Main open items |
|---|---|---|
| ATX 24-pin rev3 | **Mostly coherent; conditional sign-off.** | USB ESD-array VBUS capacitor, TPS2121 OVP dynamic margin/current-limit intent, and ESP32 module decoupling. |
| EPS 8-pin rev3 | **Schematic blockers repaired; conditional electrical sign-off.** | LP5907 effective-capacitance/load-step validation, ESP32 distributed-bulk deviation, and TPS2121 dynamic OVP margin. |
| PCIe 2-port | **Schematic blockers repaired; conditional electrical sign-off.** | LP5907 effective-capacitance/load-step validation, ESP32 distributed-bulk deviation, and TPS2121 dynamic OVP margin. |
| PCIe 3-port | **Same conditional electrical state as 2-port.** | Same shared control/USB cell; the third sensing channel itself is coherent. |
| 12VHPWR Standard | **Mostly coherent; conditional electrical sign-off.** | TPS2121 dynamic OVP margin, output-pigtail schematic representation, INA240 input-filter error budget, and ESP32 module decoupling. |
| Standard Hub rev2 | **Schematic topology and bounded power/hold-up models pass.** | OVP/source-switching bench qualification and OQ-56 hold-up/slow-brownout measurements remain open. |

## 3. Electrical findings requiring reconciliation

### 3.1 Corrections to the earlier review

- ESP32 radio operation is outside the product operating mode. The LP5907 is not
  rejected on generic radio-enabled current guidance; only its capacitor network
  and measured radio-disabled load margin remain open.
- INA181 saturation is not a metrology failure. These channels are binary
  fast-spike detectors; their acceptance criteria are threshold crossing,
  propagation, minimum pulse capture, and recovery/re-arm behavior.
- The earlier blanket EN-RC finding is removed. The exact ESP32-C6-MINI-1
  peripheral schematic uses 10 kOhm/100 nF, exactly matching the C6 boards.
  Espressif separately describes 10 kOhm/1 uF as a usual starting point and
  explicitly says to adjust it to the actual power/reset timing. The S3 board's
  100 nF implementation therefore remains a first-article reset test, not a
  schematic correction.
- The PCIe 47 kOhm / 10 kOhm OVP and missing-TPS2121-IN1-capacitor findings
  were stale. Current source has R15 = 43.2 kOhm, R16 = 10 kOhm, and C45 =
  10 uF from `VCC_RJ45` to ground. The static window now passes, while its
  52 mV worst-corner margin to the LP5907 6.0 V absolute maximum remains an
  explicit dynamic validation item.
- The PCIe LP5907 output network now uses exact Samsung
  CL21A475KAQNNNE / C1779 4.7 uF bulk at C7. The complete nominal output node
  is below 10 uF and input nominal capacitance exceeds output nominal
  capacitance. Exact effective-capacitance and load-step evidence remains open.
- PCIe C41 and R13 now have exact Samsung CL05B104KO5NNNC / C1525 and
  UNI-ROYAL 0402WGF1002TCE / C25744 selections, respectively.
- The EPS direct VBUS diode and missing-protection findings were stale after
  repair. Current source has exact Littelfuse 1206L075/16WR / C371166 feeding
  TPS2121 IN2, `VCC_RJ45` feeding IN1, TPS2121 OUT feeding `+5VSB`, and exact
  UMW USBLC6-2SC6 / C2687116 coverage on D+/D-/VBUS/GND. D2 is absent.
- EPS C7 is now exact Samsung CL21A475KAQNNNE / C1779 4.7 uF. The complete
  nominal LP5907 nodes are 11.1 uF input and 6.5 uF output, and the executable
  radio-disabled load budget is 200.772 mA including 20% margin against the
  regulator's 250 mA capacity.
- 12VHPWR R26/R27 are now exact 43.2 kOhm / 10 kOhm. The static TPS2121
  threshold window passes at 5.287 to 5.948 V; the separate 52 mV dynamic
  guardband qualification remains open.

### 3.2 Open corrections

| ID | Affected boards | Finding | Required electrical disposition | Primary evidence |
|---|---|---|---|---|
| ELEC-02 | ATX, EPS, PCIe 2/3, 12VHPWR | The exact ESP32-C6-MINI-1 and ESP32-S3-MINI-1 peripheral schematics show 22 uF plus 0.1 uF externally at the module supply. The current boards use smaller distributed networks. PCIe now has about 6.5 to 6.8 uF nominal after its LP5907 repair; this is intentionally below the module reference because the product permanently disables the radios and the LP5907 must remain inside its own capacitor envelope. | Treat the present network as an intentional radio-disabled deviation only after calculating effective capacitance and measuring the 3.3 V droop during boot, flash access, maximum CPU/peripheral activity, USB, CAN, and simultaneous sensor conversions. | [ESP32-C6-MINI-1 datasheet Figure 9-1](https://documentation.espressif.com/esp32-c6-mini-1_mini-1u_datasheet_en.html#peripheral-schematics); [ESP32-S3-MINI-1 datasheet Figure 9-1](https://documentation.espressif.com/esp32-s3-mini-1_mini-1u_datasheet_en.html#peripheral-schematics). |
| ELEC-13 | EPS, PCIe 2/3 | C7 is now 4.7 uF, so each complete nominal LP5907 output node is below 10 uF and nominal input capacitance exceeds output capacitance. The exact MLCC effective value and radio-disabled load-step behavior are not yet proven. Executable budgets total 200.772 mA (EPS), 202.752 mA (2-port), and 204.840 mA (3-port), including 20% margin, against 250 mA capacity. | Retain C7 = Samsung CL21A475KAQNNNE / C1779 and validate effective capacitance, startup, thermal margin, and worst-case load steps in the permanent radio-disabled mode. | [LP5907 datasheet](https://www.ti.com/lit/ds/symlink/lp5907.pdf); `scripts/cec_power_budget.py`; current EPS/PCIe root schematics. |
| ELEC-05 | ATX, EPS, PCIe 2/3, 12VHPWR | TPS2121 stages use 43.2 kOhm / 10 kOhm, producing about 5.639 V nominal and 5.287 to 5.948 V at calculated extremes. This passes the static 5.25-to-6.0 V window but leaves only about 52 mV at the worst calculated corner before dynamic overshoot. | Either add meaningful guardband or demonstrate by worst-case transient analysis/bench test that the downstream input never exceeds its absolute maximum. | TPS2121, LP5907, and TLV755P primary datasheets; resistor values are from the current root schematics. |
| ELEC-07 | ATX | USBLC6 D_USB1 pin 5 is tied to connector-side `VBUS_RAW`, but the schematic has no local capacitor on that node; the listed capacitors are after the PTC/ferrite. ST's application topology places the VBUS capacitor at the protection device/connector side. | Add the local VBUS-to-ground capacitor shown by the exact application topology or obtain an exact-device rationale showing it is unnecessary. Qualify the ST part actually listed on ATX rather than borrowing the UMW clone's data. | [ST USBLC6-2 datasheet, typical USB application schematic](https://www.st.com/resource/en/datasheet/usblc6-2.pdf). |
| ELEC-08 | ATX | TPS2121 U5 uses 20 kOhm ILIM, approximately a 4.8 A typical setting, near/above the device's 4.5 A continuous-current rating. U6 uses 100 kOhm, approximately a 1.2 A-class setting. The repository does not show a fault/current budget explaining the much higher U5 setting. | Tie both ILIM selections to the actual maximum load, connector/source limits, thermal limit, and fault-clearing objective. Do not use the device maximum as the default without a system-current need. | [TPS2121 datasheet tables 7-3 and 7-5](https://www.ti.com/lit/ds/symlink/tps2121.pdf#page=6). |
| ELEC-09 | 12VHPWR | J4 is described as an output pigtail but is assigned the same Molex 2191161161 male board-header MPN, symbol intent, and board-header footprint as input J3. Electrically, that does not define the permanent cable conductors, pin mapping, or assembly test. | Represent J4 as a soldered cable/wire landing or an explicit cable assembly, with all six 12 V, six ground, and four sideband conductors mapped. Lock wire gauge, cable connector, and continuity/hipot test requirements in the BOM/drawing. | Current 12VHPWR root schematic; [Molex 2191161161 product record](https://www.molex.com/en-us/products/part-detail/2191161161). |
| ELEC-10 | 12VHPWR | Each INA240A3 channel has matched 10 Ohm series resistors and 470 nF differential capacitance, giving roughly a 16.9 kHz differential pole. TI says input-filter components must be selected carefully, limits the series resistors to 10 Ohm or less, and calculates about 0.33% gain error at 10 Ohm before mismatch/error accumulation. | Decide whether bandwidth/noise benefit justifies the gain and settling error. Include resistor tolerance/TCR, capacitor tolerance, step response, overload recovery, and calibration in the measurement error budget. | [INA240 datasheet section 9.1, input filtering and Table 9-1](https://www.ti.com/lit/ds/symlink/ina240.pdf#page=18). |
| ELEC-12 | Standard mains | DNP CMC/fan options remain in source BOM data, and ATX uses ST USBLC6 while PCIe/12VHPWR use a UMW part with the same generic name. | Produce an electrically explicit fitted/DNP variant list and qualify each exact manufacturer independently. A shared generic value is not substitution approval. | Current root BOM fields; [ST USBLC6-2 datasheet](https://www.st.com/resource/en/datasheet/usblc6-2.pdf). |

### 3.3 Repairs confirmed by the regenerated audit

- **ELEC-01 on EPS is fixed:** the current hierarchy proves the complete
  protected, reverse-blocking dual-source chain and exact D+/D- ESD coverage;
  the legacy D2 is absent. The audit now fails closed on every required pin,
  net, MPN, and LCSC selection.
- **ELEC-03 on EPS is fixed at the nominal-network level:** C7 is exact
  4.7 uF C1779, producing 11.1 uF nominal input and 6.5 uF nominal output.
  The effective-capacitance and load-step qualification remains a warning.
- **ELEC-04 on 12VHPWR is fixed:** R26/R27 are 43.2 kOhm / 10 kOhm and the
  static tolerance window is 5.287 to 5.948 V. ELEC-05 retains the separate
  dynamic-margin question.
- **ELEC-04 on PCIe is fixed:** R15/R16 are 43.2 kOhm / 10 kOhm and the
  static tolerance window is 5.287 to 5.948 V. ELEC-05 retains the separate
  dynamic-margin question.
- **ELEC-06 is fixed:** C45 is an exact 10 uF X5R capacitor from `VCC_RJ45`
  to ground, and all three U4 IN1/IN2/OUT nodes have distinct selected bypass
  capacitors on both PCIe boards.
- **ELEC-11 is fixed:** C41 is Samsung CL05B104KO5NNNC / C1525 and R13 is
  UNI-ROYAL 0402WGF1002TCE / C25744 on both PCIe boards.
- **PCIe regulator capacity is proven at the paper-model level:** executable
  component sums plus the single 20% system margin leave 18.9% capacity on the
  2-port and 18.1% on the 3-port. This does not waive ELEC-13 bench evidence.
- **Hub scope and OVP source are repaired:** the Hub is now in the executable
  Standard-main scope, and U7/U11 use exact 43.2 kOhm / 10 kOhm dividers.
  Its 5VSB dropout/hold-up audit still proves that U8 detects ahead of D1 and
  ahead of the buck regulation floor; OQ-56 remains open.

### 3.4 Confirmed and non-blocking operating assumptions

- Radio is not used on any module. With RF clock-gated, the ESP32-C6-MINI-1
  datasheet reports about 27 mA typical at 160 MHz with peripheral clocks
  disabled and 38 mA typical with all peripheral clocks enabled. Even allowing
  substantial margin for flash and external ICs, a 250 mA LP5907 is a
  reasonable source for EPS/PCIe. This is accepted electrically provided the
  production firmware permanently prevents Wi-Fi, Bluetooth, and 802.15.4
  activation and a first article confirms total peak 3.3 V current and droop.
  Source: [ESP32-C6-MINI-1 current-consumption table](https://documentation.espressif.com/esp32-c6-mini-1_mini-1u_datasheet_en.html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).
- INA181 channels are intentional binary fast-spike detectors feeding TLV7011
  comparators. They are not waveform-mapping or metrology channels, and their
  analog value is not sampled. Saturation on a sufficiently large spike is
  therefore expected and harmless; the only required range check is that the
  minimum target spike crosses the worst-case comparator threshold and that
  overload recovery meets the required re-arm time. TI explicitly lists the
  TLV7011 for threshold detection and specifies approximately 260/310 ns
  propagation at 100 mV overdrive; the real minimum-pulse requirement must use
  the complete INA181/filter/comparator path. Sources: [INA181](https://www.ti.com/lit/ds/symlink/ina181.pdf)
  and [TLV7011](https://www.ti.com/lit/ds/symlink/tlv7011.pdf#page=7).
- ESP32 EN uses 10 kOhm/100 nF. This exactly matches the C6 module's Figure 9-1.
  Both C6 and S3 documents call 10 kOhm/1 uF a *usual* setting and explicitly
  permit adjustment for the actual ramp and reset sequence. Keep a cold-start,
  brownout, rapid-cycle, and programming reset test, but do not carry this as a
  schematic correction. Sources: [ESP32-C6-MINI-1 Figure 9-1 and reset note](https://documentation.espressif.com/esp32-c6-mini-1_mini-1u_datasheet_en.html#peripheral-schematics)
  and [ESP32-S3-MINI-1 reset note](https://documentation.espressif.com/esp32-s3-mini-1_mini-1u_datasheet_en.html#peripheral-schematics).

## 4. Shared active-component review

| Part and references | Schematic implementation | Verdict |
|---|---|---|
| ESP32-C6-MINI-1-N4: ATX/EPS/PCIe U1 | 3.3 V rail, boot/reset switches, GPIO8 strap, I2C, CAN logic, and USB signals are coherently connected. Radio-disabled active current is 27 to 38 mA typical at 160 MHz depending on peripheral clocks, so both the 500 mA TLV755 and 250 mA LP5907 have credible current margin. | **Supply capacity pass under the permanent radio-disabled assumption. ELEC-02 and effective-capacitance/load-step qualification remain.** |
| ESP32-S3-MINI-1-N4R2: 12VHPWR U1 | TLV755 500 mA-class source and about 11.9 uF nominal distributed capacitance support the reviewed approximately 212 mA worst-case load including margin. Boot/reset/strap connections are coherent. | **Supply capacity pass. ELEC-02 remains the decoupling check.** |
| TJA1051T/3: every U2 | VCC is 5 V, VIO is 3.3 V, GND and high-speed mode are correct for the `/3` variant; TXD/RXD connect to 3.3 V MCU logic. | **Pass.** CAN termination is intentionally system-level and must exist at the bus endpoints. |
| TLV75533PDRVR: ATX U3, 12VHPWR U16 | IN/OUT/EN pin use is correct; at least 1 uF nominal input/output capacitance is provided; output load budgets are below 500 mA. | **Schematic pass.** Exact effective-capacitance and thermal calculations remain sign-off evidence. |
| LP5907MFX-3.3: EPS/PCIe U3 | IN and EN are correctly tied to the 5 V source and OUT feeds 3.3 V. Pinout is correct. EPS/PCIe executable load budgets are 200.772/202.752/204.840 mA including the 20% system margin. Every C7 is now 4.7 uF, bringing each nominal node into range. | **Paper load/cap-network pass; effective-capacitance, startup, and load-step qualification remain open.** |
| TPS2121RUXR: ATX U5/U6, EPS/PCIe U4, Hub U7/U11, 12VHPWR U5 | IN1/IN2/OUT, priority, soft-start, status, CP2/OV2, and current-limit pins are logically coherent. EPS, PCIe, Hub, and 12VHPWR have distinct exact bypass selections on every audited power pin. | **Conditional:** ELEC-05/08 apply. Unpowered reverse behavior and source-switching transients need first-article verification. |
| INA238AIDGSR: ATX U10-U13, EPS/PCIe U10-U12 | Supply, I2C, VBUS, IN+/IN-, and address straps are coherent; ATX's four address combinations are unique. | **Pass.** Firmware must use the correct shunt range/calibration; ATX RS4 requires the wide range for precise measurement above about 1.64 A. |
| INA181A2IDBVR: ATX fast channels, EPS/PCIe U20-U22 | REF is grounded for unidirectional operation, A2 gain is 50 V/V, 3.3 V supply and positive-rail common mode are valid. Outputs feed TLV7011 comparators as binary fast-spike detectors; no analog measurement is taken. | **Pass for the stated purpose.** Verify minimum detectable spike, comparator threshold tolerance, pulse width, propagation delay, and overload recovery rather than linear full-scale accuracy. |
| TLV7011DBVR: ATX fast channels, EPS/PCIe U30-U32 | 3.3 V supply, push-pull output, common filtered threshold, and input/output polarity are coherent. | **Pass.** Comparator threshold range/hysteresis must be included in the protection-detection budget. |
| INA240A3DR: 12VHPWR U10-U15 | 3.3 V supply, REF1/REF2 grounded, high-side 12 V common mode, polarity, and A3 gain are valid. | **Conditional on ELEC-10.** |
| REF3030AIDBZR: 12VHPWR U4 | 3.3 V input, 3.0 V output, and 100 nF input/output capacitors are valid. It is used as a measured calibration reference rather than the ESP32 ADC reference. | **Pass.** |
| SN74LVC1G17DBVR: ATX U4/U8 | DBV pinout, 3.3 V supply, and 5 V-tolerant inputs are appropriate for the ATX control/status signals. | **Pass.** |
| AO3400A: ATX/12VHPWR Q1 | ATX PS_ON# current is trivial. 12VHPWR uses a 3.3 V gate, 100 Ohm gate resistor, default-on pull-up, low-side fan return, and SS34 flyback diode. The part is specified to 48 mOhm maximum at 2.5 V gate drive. | **Topology pass.** Confirm exact fan current and hot loss, but there is no schematic pin/connectivity error in the current root schematic. |
| USBLC6-2SC6 | D+/D- pass-through pins, ground, and VBUS reference are correct on ATX/EPS/PCIe/12VHPWR. | **EPS/PCIe/12VHPWR pass. ATX requires ELEC-07.** |
| 1206L075/16WR PTC and MPZ2012S601AT000 ferrite | The 750 mA hold PTC provides comfortable nominal margin for the sub-500 mA service/control loads; topologies that use the 2 A, 100 mOhm-max ferrite also retain ample current margin. | **Pass where present.** Inrush and ambient derating remain bench/calculation items. |
| PESD5V0S1BA clamps | Nodes and polarities are sensible for DETECT, ATX control, and VBUS clamps. The BOM's supplier identity is not consistently backed by a primary-manufacturer record. | **Conditional.** Lock VRWM, clamp voltage, leakage, capacitance, and pulse rating for the exact supplier part. |

## 5. Current-sense resistor and passive-network review

All shunts in the current design are evaluated as the two-terminal parts listed
in the root schematics/BOMs.

| Board / references | Electrical check | Verdict |
|---|---|---|
| ATX RS1-RS3: Bourns CSS2H 2 mOhm, 5 W | At 20 A, each dissipates 0.8 W and develops 40 mV; values are compatible with INA238 and INA181A2 ranges. | **Pass with exact rail-current and calibration budgets.** |
| ATX RS4: RESI LCSR2512FR025K9L, 25 mOhm, 2 W | At 3 A: 75 mV, 0.225 W. Basic value, tolerance, TCR, and rating are adequate. INA181 saturation on a large event is acceptable for the binary detector; INA238 must use its wide shunt range for precise measurement above about 1.64 A. | **Pass.** |
| EPS/PCIe RS1-RS3: Bourns CSS2H 0.5 mOhm, 6 W | Even at 30 A, dissipation is 0.45 W and shunt voltage is 15 mV; A2 fast-channel output is 0.75 V. | **Pass.** Actual connector/rail limit and calibration must set the software range. |
| 12VHPWR RS1-RS6: Bourns CSS2H 1 mOhm, 5 W | At the Molex 9.2 A/contact rating, each develops 9.2 mV and dissipates about 85 mW; INA240A3 ideal output is about 0.92 V. | **Pass.** Large nominal component margin; filter/calibration issue is ELEC-10. |
| USB-C R8/R9 on every board | Both CC pins use 5.1 kOhm Rd to ground, correctly declaring a USB device/sink. | **Pass.** |
| I2C R3/R4 | 2.2 kOhm pull-ups to 3.3 V are coherent for the short local bus. | **Pass; confirm total bus capacitance at system integration.** |
| EN/boot/strap resistors | 10 kOhm pull-ups are conventional and correctly oriented. The C6 10 kOhm/100 nF EN network matches the exact module peripheral schematic; PCIe C41/R13 now have exact C1525/C25744 selections. | **Schematic/BOM pass; retain first-article reset testing for both C6 and S3.** |
| TPS priority resistors | 100 kOhm / 33 kOhm networks coherently establish the selected source priority. | **Pass.** Verify actual switchover thresholds across tolerance. |
| TPS OVP resistors | ATX, EPS, PCIe, Hub, and 12VHPWR use 43.2 kOhm / 10 kOhm. | **Static selections pass. ELEC-05 and Hub source-switching qualification retain the dynamic questions.** |
| TPS ILIM resistors | ATX U5 20 kOhm; ATX U6 and PCIe/12VHPWR 100 kOhm. | **100 kOhm selections are coherent for a roughly 1 A-class service path; ATX U5 requires ELEC-08.** |
| Threshold R10/C40 or R60/C60 | 10 kOhm and 100 nF filter the PWM-derived common comparator threshold. | **Topology pass.** Firmware PWM frequency/ripple, settling, and comparator threshold tolerance need a calculation. |
| 12VHPWR NTC networks TH1/TH2, R20/R21, C20/C21 | 10 kOhm NTC over 10 kOhm to ground with 100 nF filtering gives a valid ratiometric ADC signal and negligible self-heating at 3.3 V. | **Pass.** Calibration table and fault detection for open/short sensors remain firmware requirements. |
| 12VHPWR rail divider R5/R6/C24 | 47 kOhm / 10 kOhm gives about 2.105 V at 12 V and remains ADC-safe through normal 12 V tolerance; 1 nF filters high-frequency noise. | **Pass.** Add overvoltage-range analysis for the intended fault maximum. |
| ATX -12 V network R74/R75/R76, D5, C64 | 15 kOhm to 3.3 V and 100 kOhm to -12 V level-shift the ADC node to about 1.30 V at -12 V and 2.87 V at 0 V; BAT54S clamps to the 0/3.3 V rails. | **Pass.** Include resistor/clamp leakage and ADC input error in calibration. |
| ESP32 supply MLCCs | The module datasheets show 22 uF plus 0.1 uF externally. Current boards use topology-specific distributed networks; EPS/PCIe are intentionally smaller after bringing the LP5907 nominal output capacitance inside its documented range. | **Conditional radio-disabled deviation under ELEC-02/ELEC-13.** Use effective capacitance and measured supply droop. |
| Other MLCC families | Exact Samsung MPNs are populated for the repaired EPS/PCIe 100 nF, 1 uF, 2.2 uF, 4.7 uF, and 10 uF positions. | **Nominal selections pass; ELEC-07 and effective-capacitance qualification remain where identified.** |

## 6. Connector electrical review

This section covers part rating and schematic pin use only, not footprint,
mounting, stackup, assembly, or mechanical fit.

| Connector | Boards | Electrical disposition |
|---|---|---|
| Molex 39291247, 24-pin | ATX J3 | 13 A/contact class is adequate for the ATX rail allocation when current is distributed across the intended contacts. Pin mapping must be checked against the licensed ATX definition in the final interface review. |
| Molex 87427-0802, 8-pin | EPS inputs/outputs | 13 A/contact gives ample nominal margin for EPS conductors. Four connector instances correctly represent two independent pass-through channels. |
| Molex 45586-0005, 8-pin | PCIe inputs | 9 A/contact provides ample nominal margin for a conventional 150 W PCIe 8-pin allocation. |
| TE 63969-1 blade receptacles | ATX/PCIe outputs | Electrical current class is suitable for the per-contact output allocation. System current sharing and temperature rise remain qualification items, not schematic contradictions. |
| Molex 2191161161, 12V-2x6 male header | 12VHPWR J3 | 9.2 A power-contact rating gives 55.2 A across six 12 V contacts, about 662 W at 12 V before derating. A 600 W allocation is therefore feasible but has limited connector-level thermal margin. J4 is not a valid use of this male-header definition; see ELEC-09. |
| Kinghelm KH-RJ45-58-8P8C | EPS/PCIe/12VHPWR/Hub | CAN_H, CAN_L, DETECT, ground, and module-power mapping are coherent where fitted. The supplier data is weak on VCC contact current and environmental margin, so the low-power control-rail load needs an explicit limit. |
| XKB U262 USB-C | All six | USB 2.0 D+/D-, CC1/CC2, VBUS, ground, and shield intent are coherent. EPS now includes the protected source-selection and D+/D- ESD chain. |

## 7. Electrical sign-off gate

For schematic/component sign-off, each affected finding must be marked
**fixed**, **accepted with a quantified operating limit**, or **removed from
scope**. The evidence packet should contain:

1. a fresh root-schematic netlist and exact fitted/DNP BOM;
2. zero semantic-audit blockers and explicit disposition of ERC warnings that
   can conceal real dangling or multiply-driven nets;
3. worst-case calculations for regulator load, capacitor effective value,
   TPS2121 OVP/ILIM, shunt/amplifier range, comparator thresholds, reset timing,
   connector current, and ADC scaling;
4. exact manufacturer datasheet and orderable part for every fitted item;
5. bench plans for source backfeed, OVP/overshoot, current limit, regulator
   startup/load steps, MCU brownout/reset, sensing saturation/calibration, and
   protection thresholds; and
6. an owner decision approving any deliberate deviation from manufacturer
   guidance, including the operating condition that makes it safe.

This gate makes no statement about whether a PCB can be fabricated or routed.

## 8. Primary references

- Texas Instruments: [TPS2121](https://www.ti.com/lit/ds/symlink/tps2121.pdf), [LP5907](https://www.ti.com/lit/ds/symlink/lp5907.pdf), [TLV755P](https://www.ti.com/lit/ds/symlink/tlv755p.pdf), [INA238](https://www.ti.com/lit/ds/symlink/ina238.pdf), [INA181](https://www.ti.com/lit/ds/symlink/ina181.pdf), [INA240](https://www.ti.com/lit/ds/symlink/ina240.pdf), [TLV7011](https://www.ti.com/lit/ds/symlink/tlv7011.pdf), [REF30](https://www.ti.com/lit/ds/symlink/ref30.pdf), [SN74LVC1G17](https://www.ti.com/lit/ds/symlink/sn74lvc1g17.pdf).
- Espressif: [ESP32-C6-MINI-1 module datasheet and peripheral schematic](https://documentation.espressif.com/esp32-c6-mini-1_mini-1u_datasheet_en.html), [ESP32-S3-MINI-1 module datasheet and peripheral schematic](https://documentation.espressif.com/esp32-s3-mini-1_mini-1u_datasheet_en.html), [ESP32-C6 hardware schematic guidance](https://docs.espressif.com/projects/esp-hardware-design-guidelines/en/latest/esp32c6/schematic-checklist.html), [ESP32-S3 hardware schematic guidance](https://docs.espressif.com/projects/esp-hardware-design-guidelines/en/latest/esp32s3/schematic-checklist.html).
- NXP: [TJA1051](https://www.nxp.com/docs/en/data-sheet/TJA1051.pdf).
- Bourns: [CSS2H-2512](https://www.bourns.com/docs/product-datasheets/css2h-2512.pdf).
- RESI/LCSC: [LCSR2512FR025K9L exact part record](https://www.lcsc.com/product-detail/C494568.html).
- STMicroelectronics: [USBLC6-2](https://www.st.com/resource/en/datasheet/usblc6-2.pdf).
- Alpha & Omega Semiconductor: [AO3400A](https://www.aosmd.com/products/mosfets/low-voltage-mosfets-12v-30v/ao3400a).
- TDK: [MPZ2012S601AT000](https://product.tdk.com/en/search/emc/emc/beads/info?part_no=MPZ2012S601AT000).
- TE Connectivity: [63969-1](https://www.te.com/en/product-63969-1.html).
- Molex: [87427-0802](https://www.molex.com/en-us/products/part-detail/874270802), [45586-0005](https://www.molex.com/en-us/products/part-detail/455860005), [39291247](https://www.molex.com/en-us/products/part-detail/39291247), [2191161161](https://www.molex.com/en-us/products/part-detail/2191161161).

## 9. Review limits

This is a schematic, BOM, component-rating, and manufacturer-guidance review.
It does not substitute for licensed ATX/PCI-SIG/12V-2x6 compliance review,
firmware inspection, SI/PI analysis, environmental qualification, or physical
bench testing. It intentionally makes no PCB-fabrication or layout judgment.

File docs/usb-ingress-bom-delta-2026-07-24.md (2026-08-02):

# USB-ingress BOM delta — the v1.6.0 backfeed-protection package (2026-07-24)

**What this is.** The per-board part plan for spec v1.6.0 (USB-backfeed protection package;
owner rulings 2026-07-24, sign-off record `docs/owner-queue.md` 2026-07-24 rows; spec
sections 2.9 / 6.14 / §11 v1.6.0 entry). The generated `bom/*.csv` files are **not** edited
here — they regenerate from the schematics. This document is the input contract for the
schematic implementation pass (Sonnet, via MCP): refdes plan, part identities, net moves,
and the strap-value derivations. Refdes proposals were checked free against each board's
current BOM on 2026-07-24; the implementing pass owns final refdes assignment if a
collision has appeared since.

**Scope.** Beta line only (alpha + ordered rev2 frozen as shipped): `beta/atx-24pin-rev3`,
`beta/eps-8pin`, `beta/pcie-8pin-2port`, `beta/pcie-8pin-3port`, `beta/12vhpwr-standard`,
`beta/hub-standard-rev2`. `beta/eps-8pin-rev3` (owner-gated) inherits the EPS delta
verbatim if/when un-gated. **`beta/argb-standard` is explicitly NOT in the class** — its
logic-power OR is a true three-way per-source diode-OR (D2 `+5V_LED` / D3 `+5VSB_RJ` /
D4 `VBUS`, one SS34 per source, `05-mcu` sheet), so VBUS is already reverse-isolated from
every other source leg; no change.

---

## 1. Shared part set (verified 2026-07-24)

| Part | MPN | LCSC | Package | Status / provenance |
|---|---|---|---|---|
| Priority power mux | TPS2121RUXR (TI) | **C485916** | VQFN-HR-12 (RUX) | Reuse — already sourced on hub-standard (U5/U7) and atx-24pin-rev3 (U5). Stock verified 2026-07-24: **3,473**; ladder $1.1633@1 / $1.0299@10 / $0.8135@100 / $0.7566@1000. Extended. |
| VBUS polyfuse (modules) | 1206L075/16WR (Littelfuse) | **C371166** | 1206 | NEW platform line. 750 mA hold / 1.5 A trip / 16 V / 100 A max. Stock verified 2026-07-24: **7,735**; ~$0.23@5 (LCSC). Extended. 16 V rating chosen over the hub's 6 V F1–F4 family (C46640983) deliberately: this fuse must survive a faulted-PSU overvoltage appearing across a failed mux (quality-first ruling). |
| KVM polyfuse (hub) | FSMD110-16-1206R (FUZETEC) | **C5707763** | 1206 | NEW platform line. 1.1 A hold / 2.2 A trip / 16 V. Stock verified 2026-07-24: **1,015** (thin — restock watch); $0.1082@5. Extended. Fallback: Littelfuse 1206L110/16WR (not LCSC-carried; DigiKey ~7.9k, consign). The 6 V Littelfuse 1206L110SLYR (C2153847) was REJECTED: out of stock and under-voltage-rated. |
| C_SS soft-start 2.2 µF | CL10A225KO8NNNC (Samsung) | **C23630** | 0603 | Reuse — the hub's C_SS1/C_SS2 line (hub-proven ~10 ms ramp). New line on the module BOMs (same 0603 land as their C15849 1 µF line). Basic-class MLCC. |
| ILIM strap 100 kΩ 1% | 0402WGF1003TCE (UNI-ROYAL) | **C25741** | 0402 | Reuse — already a line on every module BOM (R7) and the alpha hub (R29/R30). Basic. |
| OV1 divider top 47 kΩ 1% | 0402WGF4702TCE (UNI-ROYAL) | **C25792** | 0402 | Reuse — hub line (R12/R15/…); NEW line on module BOMs (their only 47 k today is the 12VHPWR's 0.1% Yageo R5, not needed here — 1% is fine for a ±5% comparator). Basic. |
| OV1 divider bottom 10 kΩ 1% | 0402WGF1002TCE (UNI-ROYAL) | **C25744** | 0402 | Reuse — already on every board (R2 etc.). Basic. |
| PR1 divider 100 kΩ / 33 kΩ 1% | 0402WGF1003TCE / 0402WGF3302TCE | **C25741 / C25779** | 0402 | 100 k reused as above; 33 k = the 24-pin rev3's own U5 PR1 divider value (R53, currently LCSC-blank in its BOM — back-annotate C25779 at the same pass; verified in stock, JLC-carried). Basic. |
| Mux input bypass 100 nF | CL05B104KO5NNNC (Samsung) | **C1525** | 0402 | Reuse — on every board. Basic. |
| Mux input bulk 10 µF | CL21A106KAYNNNE (Samsung) | **C15850** | 0805 | Reuse — on every module (C6/C7/C9). Hub uses its 0603 10 µF line C96446. Basic. |
| DELETED per module | SS34 (D2) | C8678 | SMA | The retired ORing Schottky. 12VHPWR: delete **D2 only** — D5 (SS34 fan flyback) stays. ARGB keeps all three of its per-source SS34s. |

## 2. Strap-value derivations (TPS2121 datasheet SLVSEA3, verified against its own tables)

**Pin map (RUX-12):** 1/8 = OUT, 2 = IN2, 3 = CP2, 4 = OV2, 5 = OV1, 6 = PR1, 7 = IN1,
9 = ST, 10 = ILIM, 11 = SS, 12 = GND. OV1/OV2/PR1/CP2/ST: "connect to GND if not
required." Abs max IN/OUT 24 V; OV/PR pins 6 V; internal comparator reference
V_REF = 1.01/1.06/1.10 V (min/typ/max, rising).

**ILIM (~1 A class, owner ruling).** Datasheet law: **I_LIM = 65.2 / R_ILIM^0.861**
(R in kΩ, I in A). Validation against the datasheet's own electrical table:
44.2 kΩ → 65.2/26.1 = **2.50 A** (table: 2.5 A typ); 80 kΩ → 65.2/43.5 = **1.50 A**
(table: 1.5 A typ, 1.0–2.0 min–max). Cross-checks against the fleet: hub R_ILIM1/2 =
27 kΩ → **3.8 A**; 24-pin U5 R50 = 20 kΩ → **4.9 A**. For the ruled ~1 A: the exact
solve is R = (65.2/1.00)^(1/0.861) ≈ **128 kΩ — outside the datasheet's recommended
R_ILM window of 18–100 kΩ**, so the spec value is the in-range, already-sourced
**100 kΩ → I_LIM = 65.2/100^0.861 = 65.2/52.6 ≈ 1.24 A typical** (scaling the 80 kΩ
row's ±33% band: ≈ 0.8–1.65 A limits). Above the ESP32 flash-burst ~500 mA; ~1 A-class
per the ruling; tolerance is irrelevant to safety because isolation, not the limiter,
is the load-bearing mitigation (owner ILIM ruling) and the 750 mA-hold polyfuse is the
host-protection element.

**Soft start.** C_SS = 2.2 µF, the hub-proven value (~10 ms output ramp). Module local
bulk (≈ 30–50 µF post-mux) charges at ≈ C·dV/dt ≈ 25–50 mA — three orders under any
port limit (the owner row's ~50 mA figure).

**OV1 (~6 V faulty-PSU cutoff, PSU-side input).** Divider from IN1 to GND, tap at OV1;
the input disconnects when V_OV1 > V_REF. With 47 kΩ / 10 kΩ:
**V_cut = 1.06 × (47+10)/10 = 6.04 V typical**; worst-case band ≈ **5.70–6.33 V**
(V_REF 1.01–1.10 plus ±1% resistors). Sits above ATX 5VSB max (~5.25 V) and USB VBUS
max (5.5 V), below the LP5907 input abs-max (6.5 V); the mux itself is a 22 V part and
survives the insult while disconnecting the load. Divider burden 5 V/57 k ≈ 88 µA
(OV pin leakage ±0.1 µA — negligible error). At a 22 V insult the OV pin sees
22×10/57 = 3.86 V < the pin's 5.5 V recommended max — the divider also keeps the pin
itself safe.

**PR1 (priority-valid threshold, PSU-side input).** 100 kΩ / 33 kΩ from IN1 (the
24-pin U5's proven R52/R53 values): IN1 is treated valid while
V_IN1 > 1.06 × 133/33 = **4.27 V typ** — the stage falls back to USB below a sagging
~4.3 V PSU rail. On the hub's new U11, mirror the as-built U5/U7 PR1 strap style (the
implementing pass reads it off the hub schematic); if a divider, use the same
100 k/33 k. CP2, OV2 (and OV1 where unused), and ST strap to GND per the pin table;
an ST readout to a spare GPIO (10 kΩ pull-up, C25744) is optional and
pin-budget-permitting, matching the 24-pin's existing MUX_ST net.

## 3. Per-board deltas

Wiring order at every module USB entry (per §6.14 posture): connector → ESD clamp
(existing) → **F1 polyfuse (new)** → FB1 VBUS bead (existing) → mux IN2. PSU-side
entry: existing port bead/tap → mux IN1. Existing rail bulk (C6/C7/C9 class) stays on
the rail net, which becomes the soft-started mux OUT.

### 3.1 eps-8pin (also the template for eps-8pin-rev3 when un-gated)

| Action | Refdes | Part / value | LCSC | Role |
|---|---|---|---|---|
| ADD | U4 | TPS2121RUXR | C485916 | USB ingress mux. IN1 (pin 7) = RJ-45 VCC feed (J1.1 → FB2 → IN1); IN2 (pin 2) = VBUS via F1/FB1; OUT (1,8) = +5VSB logic rail |
| ADD | F1 | 1206L075/16WR, 750 mA/16 V | C371166 | VBUS polyfuse, ahead of the mux (layer 2) |
| ADD | R13 | 100 kΩ 0402 1% | C25741 | ILIM strap → ~1.24 A typ |
| ADD | R14, R15 | 47 kΩ / 10 kΩ 0402 1% | C25792 / C25744 | OV1 divider from IN1 → ~6.04 V cutoff |
| ADD | R16, R17 | 100 kΩ / 33 kΩ 0402 1% | C25741 / C25779 | PR1 divider from IN1 → ~4.27 V validity |
| ADD | C41 | 2.2 µF 0603 | C23630 | C_SS soft start |
| ADD | C42 | 100 nF 0402 | C1525 | IN2 (VBUS) bypass at pin 2 |
| ADD | C43 | 10 µF 0805 | C15850 | IN2 (VBUS) bulk |
| DELETE | D2 | SS34 | C8678 | Retired ORing Schottky |
| STRAP | — | CP2, OV2, ST → GND | — | Per datasheet pin table |

Note: EPS carries no discrete VBUS PESD (its splice relies on the USBLC6's own VBUS
clamp, recorded §6.14) — unchanged by this delta; the OQ-83 reconciliation pass decides
that separately.

### 3.2 pcie-8pin-2port and pcie-8pin-3port

Identical to the EPS delta (same refdes plan: U4, F1, R13–R17, C41–C43, delete D2;
both boards' R13+/C41+ verified free). Their discrete VBUS clamp D4 (PESD5V0S1BA)
stays at the connector, ahead of F1.

### 3.3 12vhpwr-standard

Same shape, shifted refdes (U4 = REF3030, C24, R22/R23 are taken):

| Action | Refdes | Part / value | LCSC | Role |
|---|---|---|---|---|
| ADD | U5 | TPS2121RUXR | C485916 | USB ingress mux (U5–U9 free; INA240s are U10–U15). IN1 = RJ-45 VCC feed; IN2 = VBUS via F1/FB1; OUT = +5VSB rail |
| ADD | F1 | 1206L075/16WR | C371166 | VBUS polyfuse |
| ADD | R24 | 100 kΩ 0402 | C25741 | ILIM strap |
| ADD | R25, R26 | 47 kΩ / 10 kΩ 0402 | C25792 / C25744 | OV1 divider (1% UNI-ROYAL — NOT the 0.1% Yageo R5/R6 precision line) |
| ADD | R27, R28 | 100 kΩ / 33 kΩ 0402 | C25741 / C25779 | PR1 divider |
| ADD | C25, C26, C27 | 2.2 µF / 100 nF / 10 µF | C23630 / C1525 / C15850 | C_SS; IN2 bypass; IN2 bulk |
| DELETE | D2 | SS34 | C8678 | **D2 only** — D5 (SS34 fan flyback on J2) STAYS |

### 3.4 atx-24pin-rev3

The 24-pin already muxes MAIN_5V × 5VSB (U5, with R50 ILIM 20 k / R52+R53 PR1
100 k/33 k / C50 SS 2.2 µF). The new stage inserts **in the 5VSB leg**, exactly per the
owner text ("VBUS + the module's 5VSB source as mux inputs") and hub-parity
(5VSB>USB stage feeding the MAIN stage): total priority MAIN_5V > 5VSB > USB.

| Action | Refdes | Part / value | LCSC | Role |
|---|---|---|---|---|
| ADD | U6 | TPS2121RUXR | C485916 | IN1 = post-shunt +5VSB tap (the net feeding U5 pin 2 today); IN2 = VBUS via F1/FB1; OUT → U5.IN2 (net move) |
| ADD | F1 | 1206L075/16WR | C371166 | VBUS polyfuse (D3 PESD clamp + FB1 bead stay; order: J5 → D3 → F1 → FB1 → U6.IN2) |
| ADD | R54 | 100 kΩ 0402 | C25741 | U6 ILIM strap |
| ADD | R55, R56 | 47 kΩ / 10 kΩ 0402 | C25792 / C25744 | U6 OV1 divider from the 5VSB tap → ~6.04 V faulty-PSU cutoff |
| ADD | R57, R58 | 100 kΩ / 33 kΩ 0402 | C25741 / C25779 | U6 PR1 divider (mirrors U5's R52/R53) |
| ADD | C51, C52, C53 | 2.2 µF / 100 nF / 10 µF | C23630 / C1525 / C15850 | U6 C_SS; IN2 bypass; IN2 bulk |
| DELETE | D2 | SS34 | C8678 | Retired ORing Schottky |
| ANNOTATE | C50, R53 | 2.2 µF / 33 kΩ | C23630 / C25779 | Back-fill the LCSC-blank existing U5 support lines with the same platform parts |

Beyond-package recommendation (flag for owner at the schematic pass, NOT ratified):
OV1/OV2 dividers on U5's own MAIN_5V/5VSB inputs would move the ~6 V disconnect to the
PSU-facing stage as well; the ratified package protects the logic rail via U6 alone.

### 3.5 hub-standard-rev2 (KVM third stage)

| Action | Refdes | Part / value | LCSC | Role |
|---|---|---|---|---|
| ADD | U11 | TPS2121RUXR | C485916 | Third cascade stage (U9/U10 left reserved for the alpha H2 rung-3 DNP convention). IN1 = /PSU_5V (U5.OUT); IN2 = /KVM_5V_IN via F5; OUT = new net → U7.IN2 |
| ADD | F5 | FSMD110-16-1206R, 1.1 A/16 V | C5707763 | KVM 5 V polyfuse (F1–F4 are the 2026-07-15 per-port 500 mA PTCs) |
| ADD | R_ILIM3 | 27 kΩ 0402 | C25771 | ILIM strap, mirrors the shipped stages (~3.8 A; the F5 polyfuse is the tighter element toward the wall-wart) |
| ADD | C_SS3 | 2.2 µF 0603 | C23630 | Soft start, hub-proven value |
| ADD | C22, C23 | 100 nF 0402 / 10 µF 0603 | C1525 / C96446 | U11 IN2 bypass/bulk (hub's own 0603 10 µF line) |
| NET MOVE | J_KVM pin 1 | +5VSB → /KVM_5V_IN | — | The raw rail tap is retired; the pin becomes inbound-only (spec §2.9/§4 v1.6.0). D7 (PESD on the 3V3 ref pin) unchanged |
| NET MOVE | U7 pin 2 (IN2) | /PSU_5V → U11.OUT | — | Completes MAIN_5V > 5VSB > USB > KVM |
| STRAP | U11 | PR1/CP2/OV1/OV2/ST | Existing support parts | Corrected 2026-08-02 from the TI TPS2121 fixed-priority table and exported netlist: PR1 follows IN1, CP2 is GND, OV2 is GND, OV1 uses the fitted divider, and ST is unused. U5 and U7 use the same CP2-low fixed-priority mode. |

## 4. Cost delta (100-qty class)

Per module: TPS2121 $0.81 + polyfuse ~$0.15 + straps/caps ~$0.05 − SS34 ~$0.02 ≈
**+$1.0/board**. Hub: ≈ **+$1.0** (mux + 1.1 A polyfuse + straps). Recorded in spec §9
(table figures unchanged as printed; quality-first ruling governs).

## 5. First-article bench gate (carried from the ruling — do not drop at implementation)

TPS2121 **unpowered reverse behavior**: OUT driven at 5 V with BOTH inputs dead,
module topology and KVM topology. The datasheet's reverse-current blocking
(0.2/1/2 A detection, 10 µs) is characterized for a live device only. Load-bearing for
(a) host plugged into a fully dead module+PSU, (b) wall-wart into a dead hub. Until
measured, the interim bench rules of spec §2.9 v1.6.0 stand.

## Accepted variance (audit-confirmed, 2026-07-24)

ST (pin 9) is left NC on every new TPS2121 stage, NOT grounded as the strap
table above literally reads: the vendored symbol types ST as an Output pin, so
a hard GND tie creates a real ERC ERROR (driver collision with the GND
PWR_FLAG), and NC matches both the datasheet's stated alternative and the
hub's as-built U5/U7 precedent. Judged sound by the independent pre-merge
audit; recorded here so the document of record matches the boards.

## CORRECTION (datasheet-derived, 2026-07-24): OV trip point + output clamp

The LP5907's ABS-MAX V_IN is **6.0V** (SNVS798Q §5.1; no transient allowance --
abs-max carries no time dimension), not the 6.5V the failure survey and SPICE
case F assumed. The implemented 47k/10k divider trips at 6.04V -- ABOVE the
LDO's ceiling. Corrected work order (both self-answered from datasheets + the
platform margin rules, no owner decision needed):
1. RETUNE OV1 on every stage: trip ~5.6-5.7V so the order is 5.25V (5V+5%
   normal max) < trip < 6.0V abs-max. Candidate pairs (implementing agent
   verifies LCSC stock, prefers already-sourced values): 47k/11k -> 5.59V, or
   43k/10k -> 5.62V. V_trip = 1.06V x (Rt+Rb)/Rb (V_REF rising, TPS2121 EC).
2. ADD a 5.6V zener/TVS clamp on each mux OUT (the t_FSW=5us switchover
   ride-through still lets the input sail past trip; the clamp holds the
   LDO input under abs-max through the event). Small SOD-323 zener class.
Both to ride the next schematic splice pass; spec v1.6.x note owed.

## ADDENDUM (datasheet-provenance audit, 2026-07-24): both retune candidates run
## uncomfortably tight on worst-case ±1% resistor + VREF tolerance -- flagging, not
## picking, before the schematic pass locks one in

Re-verified the CORRECTION above: LP5907 6.0V is confirmed against the vendored PDF
(§5.1, MIN -0.3/MAX 6V, no time-dimension carve-out), and 47k/11k -> 5.589V / 43k/10k ->
5.618V both check out arithmetically (V_trip = VREF,typ x (Rt+Rb)/Rb = 1.06 x ...). Propagated:
`docs/spice-backfeed-verify-2026-07-24.md` (Case F, Case C, Sources) and
`docs/psu-tester-failure-survey-2026-07-24.md` (the U5/U6 and hub J_PWR rows) are now
corrected to cite 6.0V, not 6.5V; `scripts/sim/cec_backfeed_cases.py` had a live 6.5V
threshold constant (not just prose) -- fixed and re-run, see
`docs/datasheet-provenance-audit-2026-07-24.md`.

NOT yet done, and deliberately left for the schematic-implementation pass rather than
decided here (this is a real design trade-off, not a datasheet fact to look up): a full
worst-case tolerance stack on the two candidate pairs, using the TPS2121's own VREF
band (1.01/1.06/1.10V min/typ/max, Sec 7.5) against ±1% resistors both directions --

- **47k/11k**: typ 5.589V; worst-case band **5.24V - 5.90V**. The LOW end (5.24V) sits
  *below* 5.25V (5V+5% normal-max) -- a nuisance-trip risk on a completely in-spec 5VSB
  rail in the worst-case corner, which the original CORRECTION's back-of-envelope
  "5.25V < trip < 6.0V" check did not catch (it only checked the typical trip point).
- **43k/10k**: typ 5.618V; worst-case band **5.27V - 5.93V**. Clears 5.25V, but by only
  ~0.3% -- thin, not comfortable.

Both candidates leave under ~1.5% of headroom somewhere in the stack, on a divider that
only has ~13% of span (5.25V to 6.0V) to work with in the first place at ±5%-class
VREF accuracy. Two directions that would actually close this margin, for the
implementing pass to choose between (neither ratified here): (a) tighten the OV1
divider resistors to 0.1% (the platform already stocks a 0.1% Yageo line for the
12VHPWR rail divider, R5/R6 -- same 0402 land, same idea, ~$0.01 delta) which removes
most of the resistor-tolerance half of the stack; or (b) accept a narrower margin and
lean on item 2 above (the output-side zener clamp) as the real backstop rather than
expecting the OV1 trip point alone to guarantee sub-6.0V. Recorded here rather than
silently picked, per the same "surface it, don't assume it" rule this repo applies to
open questions generally -- this is a design decision with a real trade-off, not a
transcription check.

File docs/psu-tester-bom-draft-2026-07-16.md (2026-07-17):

# PSU tester — BOM v1 (SOURCED) + full-retail roll-up

**v1.2 (2026-07-16, owner steer round):** (1) **P4 supply: owner RULED ride
out the blip** (Pro/Max are a distance from shipping) — §5.1 downgraded from
escalation to standing discipline; (2) **fans RULED → Arctic S12038-4K**
(11.45 mmH₂O beats the iPPC-3000's 7.63 at half the price; spec-sheet
checked) — Pro −$60, ST unify recommended; (3) **2 kW ballast RETIRED →
~3,000 W WORKSTATION tier** (Pro-W / Max-W, sketch §13) — first-cut BOMs in
new §3c; (4) **displays added** (owner: main load readout + one LCD per
module bay, off/logo when unpopulated — BOM-checked ~$3/bay, RULED IN) —
+$35 Pro-class. Totals: **Pro ≈ $1,064 / Max ≈ $1,357 / Pro-W ≈ $1,635 /
Max-W ≈ $1,955 / ST ≈ $545/$589**.

**v1 (2026-07-16, evening): four-agent live sourcing pass integrated** — every
line now carries a real MPN/LCSC#/price/stock verified against lcsc.com
product pages today (DigiKey where LCSC has nothing), superseding the v0
class estimates (kept as the Δ column). Assets (symbols/footprints/3D/
datasheets) staged under `lib/vendor/psu-tester-staging/{load-semis,
control-silicon,max-lane,electromech}/`. Tags: **[LCSC]** live-verified
today, **[DK]** DigiKey consigned, **[P]** platform part, **(q)** quote item.
Qty pricing = the ~25–50 break (small-batch build basis). Still
pre-schematic — freeze at schematic.
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

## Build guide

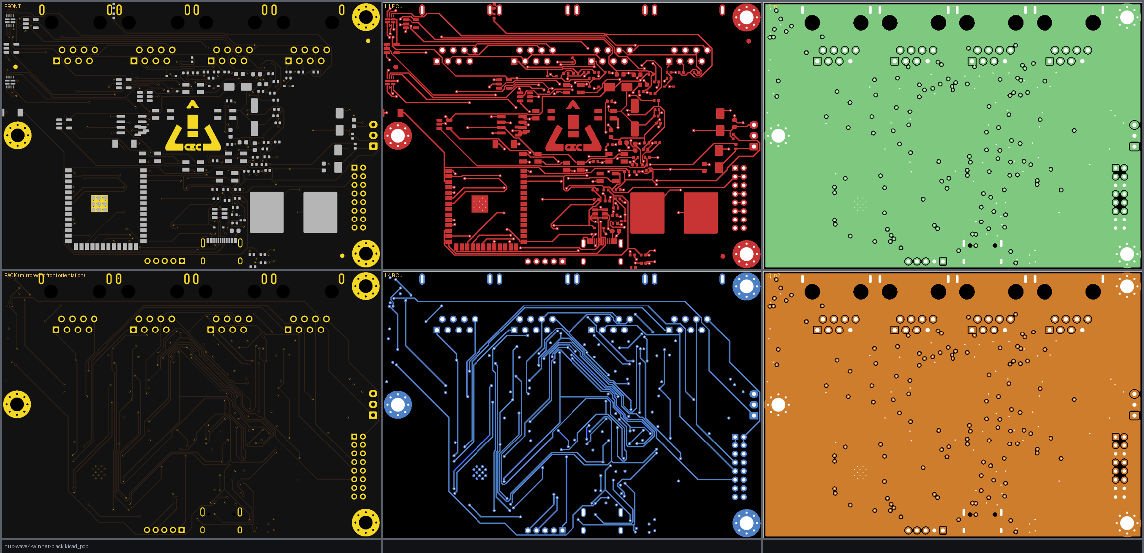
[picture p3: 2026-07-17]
build/hub-wave4-winner-hex.png

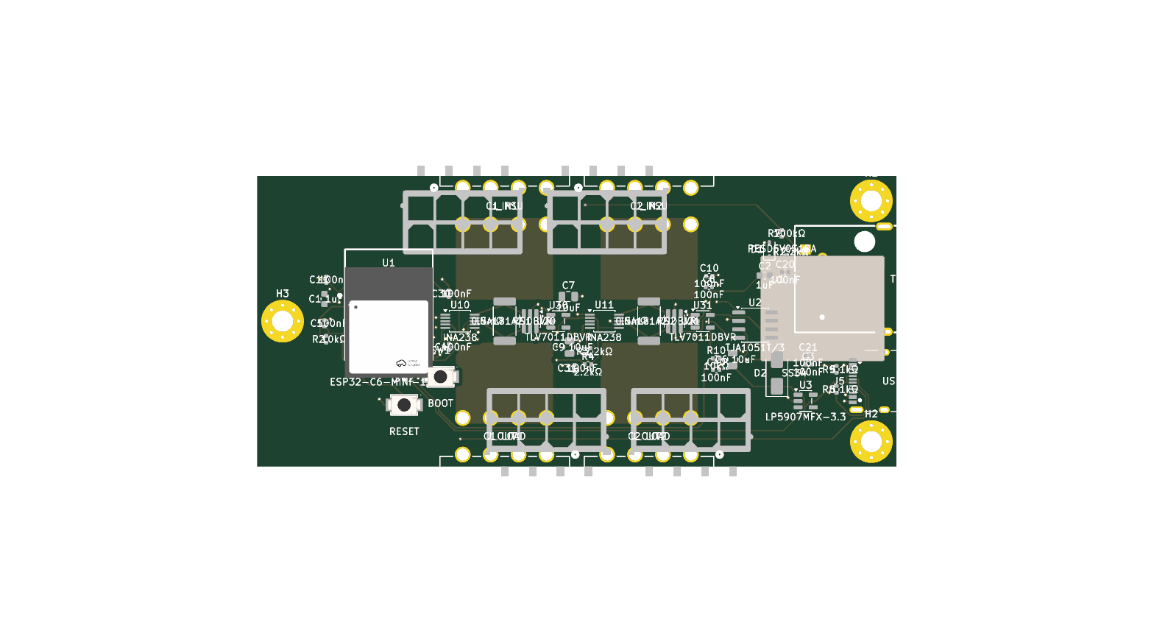
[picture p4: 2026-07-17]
build/route-clean/build-final-top.png

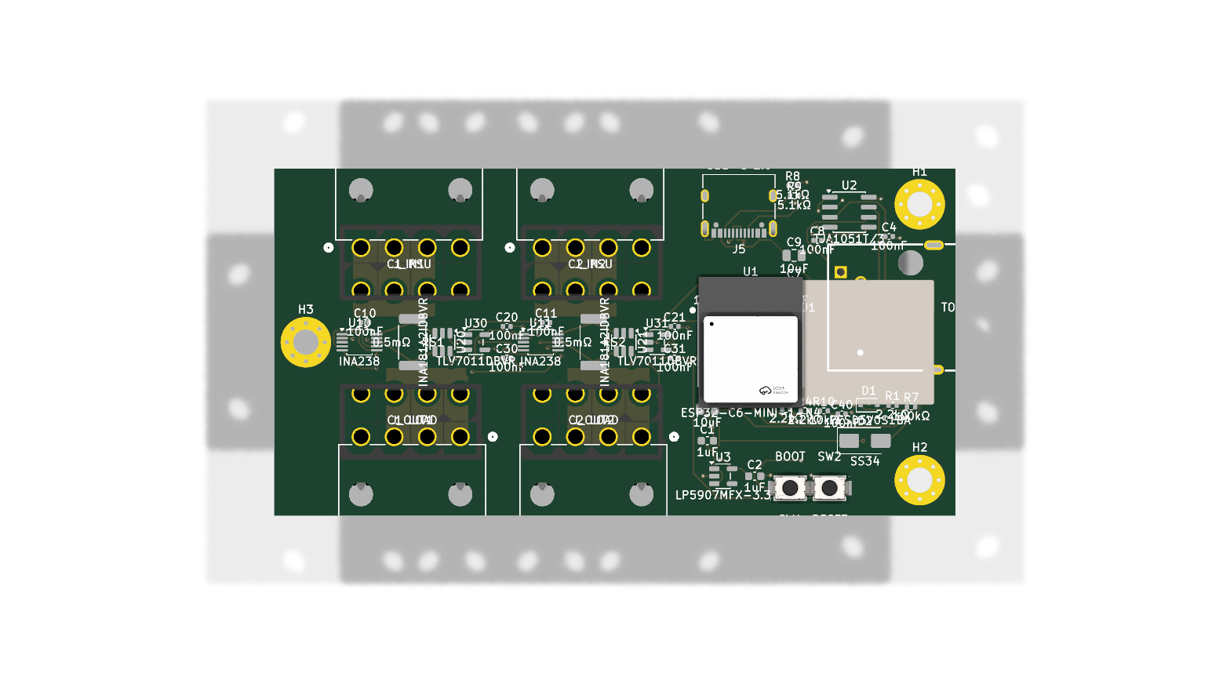
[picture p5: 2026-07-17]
build/route-pcie2-inrow/final-top.png

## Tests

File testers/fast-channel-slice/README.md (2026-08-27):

# Fast excursion channel slice (Pro ×1, Max ×2)

> **STOP WORK — mandatory gate (2026-08-10).** This design must not advance or
> be fabricated until `docs/tester-stop-work-reconciliation-gate-2026-08-10.md`
> is explicitly released.

DRAFT — no schematic yet. Design basis: sketch §2 (fast channel block), §3
speed budget, AN104/AN133 lineage (component-research doc §1).

Small 2-layer 2 oz board mounted ON the 12V-2x6 fixture block: 3–4× TO-264 L2
ballasted, fast CC loop (OPA810-class + gate stage), analog slew shaper
(≤5 A/µs, settable 2.5), Kelvin shunt + fast comparator, MCU-gated. The
mm-scale bus rule lives here: every µH costs 5 V at 5 A/µs — the slice's
copper IS the design. Bench-gate: single-channel prototype before Tier-2
claims (canonical §5.3).

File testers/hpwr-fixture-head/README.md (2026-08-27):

# 12VHPWR fixture head (all tiers)

> **STOP WORK — mandatory gate (2026-08-10).** This design must not advance or
> be fabricated until `docs/tester-stop-work-reconciliation-gate-2026-08-10.md`
> is explicitly released.

DRAFT — no schematic yet. Design basis: sketch §12 (the 12VHPWR exception —
captive pigtail cannot slot), §2.8 12V-2x6 doctrine (Molex 219116 land,
cec:CEC_12V2x6_Horizontal footprint, +12V/GND row VERIFY-BEFORE-POWER rule).

Male 12V-2x6 header (GPU-side stand-in) the module's captive pigtail plugs
into, with SENSE0/SENSE1 capability straps (strap-selectable 150–600 W
advertisement) + CARD_PWR_STABLE / CARD_CBL_PRES# wiring, feeding the fast-
channel slice bus + 12V load channels. Carries the melt-watch NTC position.
The per-test wear item at this position — design for replaceability.

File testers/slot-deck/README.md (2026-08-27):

# Blade slot deck — module docking field

> **STOP WORK — mandatory gate (2026-08-10).** This design must not advance or
> be fabricated until `docs/tester-stop-work-reconciliation-gate-2026-08-10.md`
> is explicitly released.

DRAFT — no schematic yet. Design basis: sketch §12 (slot-in bundles),
scripts/check_output_daughterboards.py (keying proofs — EXTEND to this board),
blade-fit-check-2026-07-04.md addenda (the authoritative per-family mating
drawings via pcb_placement()).

Thick-copper board presenting UPWARD TE 63951-1 blade fields in the exact
per-family patterns (24-pin 10 + J_SIG 1×4 socket, EPS 6/cable, PCIe 6/cable)
— the tester plays the daughterboard side of the ratified iteration-7 pair.
Routes slot fields to the load bus + carries the Hub dock bay RJ-45 channel
positions. Keying checker must prove no family seats in another family's
field INCLUDING any deck rotations. Gang-insertion mechanics (260–440 N on
24-pin) = OQ-86-extension sample gate before fab. LENGTH VARIANTS: standard
deck (Pro/Max/ST) vs the W deck (4× 12VHPWR slots — sketch §13(e); decide
one-long-board vs deck-segments before the blade-field drawing freezes).
Each slot position carries its bay LCD header (1.54″ SPI + CS line from the
74HC595 chain, sketch §5) so the screen sits AT the slot it reports. Deck
harness also carries: an OPTIONAL tester-PD 5 V tap position for the Hub
bay's §2.9 input (ride-through is already covered platform-side — mux +
hold-up + host-USB, owner 2026-07-16; provision the position, populate at
will) and, if the owner populates relief valve 2, the 2–3 CAN-only
expansion jacks' wiring (CAN pair + DETECT + switched 5VSB; pair 2 dark).

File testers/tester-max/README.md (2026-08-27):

# Tester Max — main board

> **STOP WORK — mandatory gate (2026-08-10).** This design must not advance,
> inherit present Standard/Pro cells, or be fabricated until
> `docs/tester-stop-work-reconciliation-gate-2026-08-10.md` is explicitly
> released.

DRAFT — no schematic yet. Design basis: docs/psu-tester-exploration-2026-07-14.md
(§6 addendum), docs/psu-tester-architecture-sketch-2026-07-16.md (§8/§8a),
docs/max-part-selection-2026-07-05.md (the digitizer lane of record),
testers/DESIGN-SHEET.md.

Tester Pro superset + the Max digitizer lane ON-BOARD: 4× 20 MHz AC-coupled
AFE → mux → AD9253-105 → GW5A-25 (LVDS), ESP32-P4, ONE 100BASE-T1 PHY (module
link, DETECT 10 kΩ CAN+T1 code), OVP characterization firmware on the same
TPS55288-class stage, second fast-channel slice position. 2 kW ballast option
RETIRED (owner 2026-07-16) → **Max-W (~3,000 W Workstation) is a population
variant of this same board** — +banks/verniers/+1 DAC80508, 4× HPWR fixture
positions, 6-fan two-lane W chassis, ganged dual fast channels (sketch §13,
BOM §3c). Front-panel main LCD + per-bay deck LCDs (sketch §5 displays).
Digitizer-on-main (not mezzanine) to keep the 65 MS/s LVDS short — revisit
only if the Max-module program ships a reusable mezzanine.

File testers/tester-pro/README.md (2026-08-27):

# Tester Pro — main board

> **STOP WORK — mandatory gate (2026-08-10).** This design must not advance,
> inherit present Standard cells, or be fabricated until
> `docs/tester-stop-work-reconciliation-gate-2026-08-10.md` is explicitly
> released.

DRAFT — no schematic yet. Design basis: docs/psu-tester-exploration-2026-07-14.md
(§6 tier ruling), docs/psu-tester-architecture-sketch-2026-07-16.md (REV B),
docs/psu-tester-bom-draft-2026-07-16.md, testers/DESIGN-SHEET.md.

1600 W hybrid sink. Compute: ESP32-P4 + TJA1051T/3 + RS-485 stream TX
(DETECT 4.7 kΩ, the Pro CAN+RS-485 code). 8× L2 vernier CC loops (DAC80508
setpoints), R-bank switching, SCP crowbars, OVP-A stage (RULED: TPS55288-
class check-grade), §6.13-pattern trip comparators, USB-C PD self-power,
front-panel main LCD + per-bay deck LCDs on shared SPI (sketch §5 displays).
Hosts the fast-channel slice (separate board, testers/fast-channel-slice/)
at the 12V-2x6 position. **Pro-W (~3,000 W Workstation, owner 2026-07-16) is
a population variant of this board** — ~13 vernier loops / 2× DAC80508 /
~120× 50 W bank units / 4× HPWR fixture positions / 6-fan W chassis (sketch
§13, BOM §3c) — design the loop/bank arrays for the W population count from
the start. ST/Pro/Max shared blocks come from lib/ per platform rule.

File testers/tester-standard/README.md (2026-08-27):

# Tester Standard (ST-1000 / ST-1300) — main board

> **STOP WORK — mandatory gate (2026-08-10).** This design must not advance,
> be copied into another tier, or be fabricated until
> `docs/tester-stop-work-reconciliation-gate-2026-08-10.md` is explicitly
> released.

DRAFT — no schematic yet. Design basis: docs/psu-tester-architecture-sketch-2026-07-16.md
(§11), docs/psu-tester-bom-draft-2026-07-16.md (§3a/3b), testers/DESIGN-SHEET.md.

ONE board, two population variants: ST-1000 (~1000 W, 2 fans) and ST-1300
(~1300 W, 3 fans) differ ONLY in R-bank leg count, fan count, and fuse values —
never in copper. Compute: ESP32-C6 + TJA1051T/3, DETECT 2.2 kΩ (CAN-only tier),
PWM+RC setpoints, ONE small 2-device L2 vernier, SCP crowbars, NO fast channel,
NO OVP stage, NO RS-485/T1. Slot-bundle posture (sketch §12): blade slot deck +
Hub Standard bay; feature fence and kill-line per sketch §11.

## Stand-up sequence (recorded 2026-07-16 night — owner ask "next steps")

PHASE 0 — owner decisions gating design start: (1) §12b mezzanine dock
ratify/decline (defines deck Hub bay + tester link block); (2) atx24
sense-wire study §7 (PS_ON# drive / PWR_OK µs / −12 V on rev3 — the ST
fence's T1/T3/T6 + −12 V tests ride the 24-pin module); (3) R-bank step
ladder nod (proposal to be drafted); (4) OQ-1/OQ-10 program-gate posture
(ST ahead of, or behind, the canonical interviews/competitive-buy gates).
PHASE 1 — physical, start now: OQ-86 blade sample order (63969-1 depth
≤4.0 mm + deck-scale gang-insertion = #1 mech risk); chassis/extrusion/
plate quotes; duct P-Q → fan lock at first chassis article.
PHASE 2 — design: ST main board capture (six-gate machinery, DESIGN-SHEET
§C/§H); slot-deck board (keying checker extended; bay-LCD headers; Hub bay
per §12b; NOTE: empty alternate slot loads via a PASSIVE pass-through
daughterboard = the retail OQ-89 assembly as slot filler); firmware
scaffold (cec_module runtime, interlock FSM, POST/cross-cal, displays,
OQ-85 profile/MARK contracts); placement/routing via the pipeline
(pipeline-consolidation branch carries the current router).
BUNDLE LONG POLE (platform-side): W6 — EPS + PCIe routing passes (zero
copper today); the $1,299 bundle ships real modules.
PHASE 3 — proto: JLC + consigned THT, chassis FA, POST bring-up, blade
confirm-soak, T1/T3/T6 vs known-good PSU, SCP on sacrificial unit,
report end-to-end.

## Phase-0 rulings (owner, 2026-07-16 night)

1. **§12b mezzanine dock RATIFIED** ("cleanest approach; all hubs will have
   it anyway" → Hub-side socket = standard hub fitment, feeds D-3/OQ-77).
   Fallbacks: USB direct / RJ-45 to a hub port. **Tester RJ-45 must be
   PoE-SAFE** → adopt the ENT mis-plug chain (REQ-MOD-COMMON-053: SS110 +
   SMAJ58A + TPS26621 + DETECT series R + pin-7 conditioning, ≈+$2.7).
2. Sense-wire §7: **ALREADY IMPLEMENTED** (owner-approved 2026-07-14,
   pipeline branch 2d9fa68c: read taps + Schmitt buffers + AO3400A PS_ON#
   open-drain DRIVE + ESD clamps; drive gated to not-plugged-in / override,
   system-wide BENCH-TESTER-MODE flag = the liability answer). Dependency
   CLOSED — the tester also gains DUT power-CYCLING through the module.
3. R-bank ladder v1.1 — RATIFIED 2026-07-17 (in the §12c structure; see the ladder section header).
4. **OQ-1/OQ-10 WAIVED for ST** ("just want it to exist; we know plenty of
   shops"). Pro/Max keep the canonical gate queue.
5. Blade samples: owner orders at some point; **press-fit tool + lever-assist
   de-fit mechanism drafting QUEUED** (deck mechanical work, OQ-86 extension).

## R-bank ladder v1.1 — **OWNER-RATIFIED 2026-07-17** ("yes the ladder has my sign off in the new structure" = v1.1 values/groups/counts + §12c per-slot channelization together; the historical [wb]-pending-nod markers below and in the 05 sheets are CONVERTED by this sign-off; the 6R LCSC SKU confirm remains the one BOM-lock item)

_v1.1 supersedes v1 pre-nod on the owner's minor-rail directive (2026-07-16
night): "I think you're underestimating the capacity of some PSU's 5V and
3v3 rails... need to be able to load and test the 5VSB rail... crossload
tests... spec all of them out to be massively overkill — I've seen PSUs
that can do like 20-30A over 5V alone." v1 minors (5 V 4 legs/20 A, 3.3 V
4/19.4 A, 5VSB 2+peak, −12 V 1) retained here for provenance only._

Basis: HoRX 50 W family legs, forced air + plates, ~48 % derate target;
binary-ish switched GROUPS of parallel legs (AOD4184A low-side + ATOF fuse
per group); vernier (2× IXTH75N10L2, assigned 12 V) interpolates between
steps and runs the OCP fine-ramps; minor-rail OCP = bank steps (fence says
coarse staircase is in-scope).

| Rail | Leg value | Per-leg @rail | Groups (legs) | ST-1000 total | ST-1300 total |
|---|---|---|---|---|---|
| 12 V | 6.0 Ω | 2.0 A / 24 W (48 %) | 1+1+2+4+8+16 (+12 ST-1300) | 32 legs = 64 A / 768 W | 44 legs = 88 A / 1056 W |
| 5 V | 1.0 Ω | 5.0 A / 25 W (50 %) | 1+1+2+4 | 8 legs = 40 A / 200 W | same |
| 3.3 V | 0.68 Ω | 4.85 A / 16 W (32 %) | 1+1+2+4 | 8 legs = 38.8 A / 128 W | same |
| 5VSB | 3.3 Ω | 1.5 A / 7.6 W | 1+1+2 | 4 legs = 6.0 A + mini-CC loop (below) | same |
| −12 V | 47 Ω 10 W | 0.26 A | 1+1 | 2 legs = 0.52 A | same |

**Operating model (owner Q&A 2026-07-17, recorded verbatim-intent):** bank
FETs are DOORS, never dimmers — fully enhanced or fully off; a leg draws its
Ohm's-law current (12 V / 6 Ω = 2 A) whenever its group is on, and nothing in
the banks modulates saturation. The staircase comes from group selection; the
ONE linear FET per rail (the 04a-d vernier, deliberately half-on in its CC
loop) slides 0–1-step continuously between staircase steps. Target 37.3 A =
banks 36 A (18 legs) + vernier 1.3 A. It is a segmented DAC: binary-weighted
coarse segments, linear interpolator fine.

**Why the duplicate 1× group (the "1+1" at the head of every ladder):**
transition insurance, not resolution. (a) GLITCH-FREE STEPPING — crossing a
binary boundary with a single 1-group is break-AND-make (3→4 legs = {1,2}
OFF + {4} ON together; any switching skew and the DUT sees a 2–8 A spike or
droop WE injected). With the spare unit, every ±1 step has a pure-ADDITIVE
path (3→4 = just ADD 1b; the {1a,1b,2}→{4} reshuffle happens later, net-zero,
under vernier cover) — every step becomes a single switch action and the
vernier's transition duty never exceeds one unit. (b) FAULT TOLERANCE — with
one 1-group, an opened LSB fuse deletes every odd step; with two, the full
staircase survives degraded. (c) WEAR/HEAT SHARING — the LSB toggles most in
any profile; two units split the switching and thermal duty (firmware
rotates which serves). Cost: one extra leg per rail (~$3). −12 V's "1+1" is
the same insurance where the whole bank is two legs.

**5VSB mini-CC loop (v1.1)**: the v1 "small-FET peak leg" upgrades to a
proper small LINEAR channel (DPAK-class FET + op-amp, 0–3.5 A programmable,
extrusion-mounted) — one cell, three duties: the ATX 3.5 A/500 ms peak-leg
pulse, FINE standby setpoints for CoC/DoE efficiency points (0.05/0.15/
0.5/1 A class — coarse 1.5 A steps can't hit these), and 5VSB OCP ramps.

**Overkill margins (v1.1 headline)**: 5 V 40 A vs the worst-seen ~30 A
(+33 %); 3.3 V 38.8 A vs ~25 A (+55 %); 5VSB 6 A vs ~3.5 A (+71 %); −12 V
0.52 A vs 0.3–0.5 A spec class. Every rail independently group-switched →
ALL ATX crossload corners reachable (max-minors/min-12V and inverse) as
firmware sequences over the same banks; the DUT's own combined-minor limit
bounds actual concurrent dissipation, so tester capacity is never the cap
in a crossload or OCP hunt. Lever if "massively" should be bigger: 5 V
+2 legs → 50 A (+1 position, ~$6).

Totals (v1.1): ST-1000 = 32 + 22 = **54 legs**; ST-1300 = **66 legs**
(v1: 43/55). BOM delta vs v1: +11 minor legs ≈ +6 positions ≈ +$30–40
(resistors + 3 more AOD4184A/ATOF group sets + plate inches).
Step resolution: 2.0 A on 12 V (vernier fills 0–2 A continuously), 5 A /
4.85 A on the minors (coarse staircase in-scope per fence; option noted in
FOLLOWUPS — one L2 device relay-switchable to 5 V/3.3 V if shops ever want
fine minor-rail OCP hunts). Why 6.0 Ω over
the priced 5R: honest 48 % derate + round 2 A steps; same family/price
class ([wb] confirm the 6R sibling's LCSC line at BOM lock; 5R fallback =
2.4 A/28.8 W legs, 58 % — still acceptable with plates).

## Field arrangement math v1 (2026-07-16 — companion to ladder v1, rides the same nod)

- **Part — ONE housing everywhere**: HoRX 50 W aluminum-shell family (RX24-class
  gold shell, ~51×30×17 mm body, end terminal lugs, base mounting ears). Priced
  line = the 5R C2923747 ($1.71–3.24, healthy stock); ladder v1 wants the 6R
  sibling ([wb] confirm its LCSC line at BOM lock; 5R fallback = 2.4 A/28.8 W
  legs at 58 %). Values by rail: 6R0 (12 V) / 1R0 (5 V) / 0R68 (3.3 V) / 3R3
  (5VSB) — same shell, one mechanical design — plus one 47R 10 W small shell
  (−12 V). Terminals are screw/solder LUGS, not .250 blades: a bolted .250 male
  blade lug per terminal makes the deck reach (Arcol HS50 push-on-terminal
  variant = western-sourcing fallback) — [wb] at blade-sample time.
- **Fold rules** (the wall-cartridge form, DESIGN-SHEET 22b v2): positions at
  ~36 mm pitch along the wall (30 mm shell + air gap); back-to-back pairs = 2
  legs/position; walls at ~50 mm pitch (3 mm plate + 2×17 mm shells + ~13 mm
  air), fins PARALLEL to airflow; ONE row tall per wall, always (single gang
  drop into the deck + one feed bar; height never scales). Scaling axes, in
  order: row length along the flow axis (cheap; preheat absorbed — worst-case
  air rise ~20 K at W-tier CFM), then wall count across the duct. NEVER a
  second row vertically on a wall.
- **Census** (v1.1 overkill minors = 22 legs ≈ 11 positions on every model;
  rows budgeted ≤ ~400 mm against the 430–450 mm console class):

| Model | 12 V legs | Minor legs | Total | Positions | Walls × pos/row | Duct |
|---|---|---|---|---|---|---|
| ST-1000 | 32 | 22 | 54 | 27 | 3 × 9 (~324 mm) | ~160 mm |
| ST-1300 | 44 | 22 | 66 | 33 | 3 × 11 (~396 mm) | ~160 mm |
| Pro / Max | ~53 | 22 | ~75 | 38 | 4 × 10 (~360 mm) | ~210 mm |
| Pro SE / Max SE (W-merge 2026-07-17; water cold-plate walls — air fold rules = provenance) | ~96–100 | ~22 | ~120–125 (§13) | ~61 | 6 × 11 (~396 mm) = two lanes of 3 | 2 × ~160 mm (§13 two-lane) |

- **Continuous-power ledger** (banks × per-leg W + verniers): Pro 12 V
  53×24 ≈ 1.27 kW + 8 verniers ≈ 0.4 kW ≈ the 1600 W continuous rating ✓;
  W ~100×24 ≈ 2.4 kW + 13 verniers ≈ 0.6–0.75 kW ≈ 3.0 kW ✓ (installed
  ~125×50 W ≈ 6.2 kW at the ~48 % derate doctrine — the 2× part-count margin
  IS the derate, that's where "~120" comes from). Minor capacity adds ≤~390 W
  (200+128+30+…) but concurrent actual is DUT-bounded (a real unit's
  combined-minor limit is ~130 W) — capacity is for coverage + OCP hunts,
  not simultaneous dissipation; duct sizing unchanged.
- **Volume check (the "does it balloon" answer)**: W-tier = 6 walls × ~400 mm
  rows × ~100 mm resistor zone ≈ 13 L total for 3 kW delivered — the field
  IS the heatsink AND the radiator, so no second thermal volume exists to grow;
  air rise ≈ 20 K at 263 CFM. Banks are PER RAIL; 12 V groups are ASSIGNED PER
  SLOT NODE (sketch §12c, owner Q 2026-07-17 — the earlier "any head into the
  same 12 V plane" pooling is RETIRED: a shared plane can neither fence
  per-cable current nor attribute it; division would ride cable resistance).
  Fixed deck copper maps groups→slot nodes; per-slot fuses + firmware ceiling
  map + module-measured attribution per §12c's fence table (24-pin 12 V fence
  = 10 A on the 2×6 A ATX bar). Only the 12 V bank count scales with tier;
  minors are constant (22 legs, ladder v1.1) and enter via the 24-pin slot
  node under its own fences (recruit ≤ connector bar even though installed
  capacity is higher — §12c honesty note).
- Group maps beyond ST (Pro 53-leg / W ~100-leg 12 V ladders) = [wb] at each
  tier's ladder pass; switching/fusing stays per GROUP (AOD4184A + ATOF sized
  at group current), the resistor is the per-leg unit, trip watch per group.
- CORRECTION trail: 22b's original "ST-1000 = one double-sided plate" was
  pre-math (a single row would be ~790 mm); v1-minors math said 2 walls;
  ladder v1.1's overkill minors settle ST-1000 at THREE walls (3 × 9). Fixed
  in DESIGN-SHEET 22b.

## Split architecture — hot load slices vs cool control board (**OWNER-RATIFIED 2026-07-17: "absolutely"** — the unit is officially MULTI-BOARD: SELV control board + per-rail load slices + deck + display boards; IMS/metal-core stays the per-slice option decided at layout by the electrothermal gate, most likely earned by the 12 V switch slices at W-tier currents)

Owner: "make the hot loop ends with all the hot components on their own
(metal cored?) PCB, run the signalling to them, all signaling separate —
so we can put them in different compartments or stacked or whatever?"

RECOMMENDATION: YES, with one sharpening — the BIG heat is already
off-PCB by design (50 W legs on chassis plates, vernier/SCP FETs on the
extrusion). What actually splits off is the SWITCHING LAYER, as per-rail
**LOAD SLICES**: bank-switch FETs + ATOF fuses + loop shunts + trip
comparators + LOCAL gate drivers on small hot-zone boards; the control
board stays pure SELV logic in the cool zone. Substrate: thick-copper FR4
baseline; IMS/metal-core = a PER-SLICE OPTION where SMD switch dissipation
concentrates (the 12 V group rows at W-tier currents) — decide per slice
at layout with the electrothermal gate, don't blanket-IMS.

Rules that make the split safe:
- Gate DRIVERS live ON the slice; the harness carries logic-level
  enable/PWM only (never gate charge over a cable).
- De-gate pull-downs live ON the slice → **an unplugged harness IS the
  safe state (no load), physically.**
- Kelvin pairs stay on-slice (shunt → comparator local); only digital
  trip/latch lines cross.
- Keyed connectors, counted in the fail-safe analysis.

What it buys: compartment/stacking freedom (owner's ask); ONE control
board across ST/Pro/Max/W — W = MORE IDENTICAL SLICES (the DESIGN-SHEET §H
population strategy physicalized); the slice is the service unit (burned
group = swap a cheap board); and the SE two-chamber wet-gallery/dry-deck
becomes the SAME architecture instead of a special case. Precedent: the
fast-channel-slice is already its own board for µH reasons — this
generalizes the pattern. Cost: +connectors/assembly, offset by slice reuse
across four SKUs.

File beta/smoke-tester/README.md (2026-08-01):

# Smoke Tester — sacrificial first-contact PSU triage box (beta line)

**Status: DRAFT, sketch-stage, SIGNED OFF — sourced, capture next** (the
`tester-standard` convention: folder + design basis first, gated capture as its own
phase). Stood up 2026-07-24 (decision #1); **OWNER SIGN-OFF 2026-07-25 ("I approve of
your recommendations on all counts")**: decisions #2 terminator fence, #3 blade+HRC
coordination, #5 earth pigtail, #9 $79 retail, #11 spare brick in-box, #12 consumables
ladder, #13 keep snout paddle, **#14 arcs BOTH** (GDTs + LAMP TEST) = RULED; #4 smoke
chamber = adopted pending the flammability/venting review; #8 = pro-tool disclaimer
posture v1; **#10 bundle position remains OPEN** (no recommendation was offered).
BOM = LCSC-primary sourcing pass done 2026-07-25 (jlcsearch-verified, §6). Sub-boards
live in their own folders: `brick/`, `snout/`, `faceplate/` (§8 structure). Design
basis of record: `docs/smoke-tester-concept-2026-07-24.md` (§1–§9) + this README (the
board-level spec). Sketches: `assets/` (block diagram, per-way schematic sketch,
control/indication sketch). BOM: `bom/bom.csv` (+ JLC-format skeleton). Zero firmware
by design — no `firmware/` entry will ever exist for this board.

**One-liner:** the thing you plug a sketchy PSU into FIRST. Every DUT conductor enters
through a replaceable fuse; every fault class — overvoltage, mains-on-a-rail, reverse,
cap dump — is *converted* into a fuse-clearing current event by a sacrificial clamp;
the human is told the case is live before touching it. All triage, zero metrology:
the bouncer in front of the module / ST-deck bench, at a price where its own death is
a shrug.

## 1. Mission and fences

- **Does:** connector-domain triage of an unknown/suspect ATX PSU: 5VSB sanity,
  rails-quiet-before-PS_ON, rails-in-window after, PWR_OK presence + coarse timing,
  −12 V presence, hot-ground ("CASE LIVE") detection. Survives mains-on-any-output
  by design; repair = consumables.
- **Never:** metrology (±5 %-class lamp windows only), load testing beyond min-load
  bleeders, ripple, OCP hunts, data links, MCUs, inline operation. It TERMINATES the
  DUT — nothing of ours ever sits downstream of it. Green lights here earn the DUT
  its interview with the 24-pin module / ST deck; that is the whole product ladder.
- 24-pin only, deliberately: no other PSU connector adds a voltage domain (EPS/PCIe/
  SATA/Molex are the same secondary nodes), and PS_ON# lives on the 24-pin, which
  makes it the mandatory core. Per-cable wiring faults are a DMM / metrology-deck
  job, NOT this box's (owner re-ruling 2026-07-25 — AUX port DESCOPED, §5).

## 2. Architecture — three domains, four consumables, one structural rule

See `assets/smoke-tester-block.svg` (electrical) and
`assets/smoke-tester-board-map.svg` (physical boards + connectors).

**Domains.** (a) THE SACRIFICE PATH (DUT copper): snout → blade fuse → HRC backup →
clamp brick → way node → bleeders/dividers. (b) THE FLOATING MEASUREMENT DOMAIN:
comparators + lamps + meter, powered by the **batteryless instant-on supply**
(harvest-direct ⊕ supercap store, below),
referenced to DUT GND and floating relative to earth — it keeps indicating even when
DUT GND rides line potential. (c) THE EARTH-NEON DOMAIN: nothing but neon bulbs and
megohms between DUT nodes and the earth reference — zero powered electronics, strikes
at ~90 V, lights **CASE LIVE**.

**Power — batteryless, self-charging, INSTANT-ON (owner no-disposables directive
2026-07-24; harvest-direct bypass added on the owner's first-use-UX challenge,
2026-07-25):** no battery of any chemistry — and **no charge-before-first-use
ritual**. Harvest front end: 5VSB-way ⊕ 5V-way ⊕ USB-C 5 V through ORing Schottkys
(D_H1..D_H3) onto one common node. Off that node hang TWO independently fused legs
(both fusibles on the brick — the harvest tap's protection is sacrificial like
everything else): **RW_H 33 Ω 2 W → Z_ST 5.6 V CV clamp → the 2S supercap store**
(2× 2.7 V 2 F radials + 2× 100 kΩ balance — the EXACT Pro/Max-provision cell class,
one shared buy; VE-2 2026-07-25, was 5 F), and **RW_D 33 Ω 2 W → D_DOM → Z_DOM
clamp + C_DOM → the domain rail directly**. The domain rail is the diode-OR of that
harvest-direct leg and the store (via D_ST2): the instant ANY source is live — a DUT
rail or a phone brick — the panel is up in ~ms (only C_DOM charges, not the farad),
while the store fills behind RW_H in parallel (usable ~30 s, full ~2 min; ~150 mA
initial, 0.76 W in the 2 W part). The OR hands over by itself: when the DUT sags or
collapses, D_ST2 conducts and the lamps/latches ride straight through the exact
event they are reporting — the load-bearing storage property, preserved and now the
store's WHOLE job (ride-through + LAMP TEST depth), no longer the first-light path.
Store math: 1 F net, 5.0→2.8 V usable (D_ST2's diode drop raises the old 2.5 V
floor) = 8.6 J ≈ **~4.5 min of held-TEST ≈ ~5 DUT sessions** of reserve; zero
standby drain (latching relay + neons need nothing at rest). No LDO anywhere: all
thresholds compare against a TLV431 1.24 V absolute reference, so the rail may ride
2.5–5 V; way lamps are 2 mA high-efficiency red / 570 nm yellow-green (Vf ≤2.1 V)
so indication holds to the rail floor. First-light timeline: earth-domain neons
0 s, always (they need no power, ever); comparator panel ~ms on any live rail or
USB; the ONLY dark panel is store-empty AND nothing-live — which is itself a
verdict (no 5VSB = dead standby), and the **STORE OK** tick — now the bottom step
of the §4 six-step CHARGE bar (store >2.9 V while TEST held) — disambiguates
dead-box from dead-DUT; any phone brick arbitrates. Why supercap (vs Li-ion): the energy need is tiny and refilled
every use; EDLC ships with no UN38.3 lithium compliance, has no BMS, no aging
cliff, 10+ year life — and no recharge chore ever, because using the tool charges
it.

**The structural rule (what makes "modular" true):** *no main-board copper sits
electrically upstream of a sacrifice element, and measurement taps enter only through
≥900 kΩ of series 300 V-rated resistance.* The main board survives by impedance and
by coordination, never by luck. Way copper is laid out to 300 V-working creepage
(≥3.2 mm) — a layout gate, recorded in §9.

**The consumables (all socketed) — four that die from faults, one that dies on
purpose:**

| # | Part | Where | COGS | Dies from |
|---|---|---|---|---|
| 1 | ATO blade fuses, **1 A fast, one value everywhere** | panel sockets | ~$0.10 | everyday overcurrent (shorts, cap dumps) |
| 2 | HRC 5×20 ceramic sand-filled, **2 A time-lag, 250 VAC, 1.5 kA breaking** | internal twist holders | ~$0.35 | mains-class interruption (what a 32 V blade cannot break without arcing) |
| 3 | **Sacrifice brick SB1** — 5 MOVs (uniform 22 V, see brick/README) + ◆5 GDTs (VE-1; the visible mains crowbar) + 5 witness fusibles + 2 harvest fusibles (store leg + instant-on domain leg), one keyed plug-in PCB | 2×8 socket pair | ~$3.50 | any OV/mains event (doctrine: mains event ⇒ fuses AND brick) |
| 4 | **Snout SN1** — the 24-pin male header on a passthrough paddle (standard tin) | keyed 2×13 shrouded header | ~$3.1 | **mechanical damage only** (bent pins, broken latch, mangled DUT connectors) — cycle WEAR ruled functionally irrelevant at this box's duty; see the resolution note below |
| 5 | **◆ SMOKE pellet** — the same brick-witness KNP 1 Ω flameproof, in a tool-less panel clip behind the theater window (§4 SMOKE SHOT) | 2-point clip | ~$0.02 | **the SMOKE button** — the only part that dies on purpose (the demo; real-event smoke still comes free from the brick witnesses) |

**Physical partitioning — what is a daughterboard and what isn't (owner Q,
2026-07-24):** the consumables are deliberately NOT one combined sacrificial
daughterboard — they are partitioned by DEATH CAUSE so you never throw away good
parts with dead ones. Blades (everyday-event clock) and HRCs (mains-event clock) are
bare socketed fuses, not boards — keeping the blades in standard panel sockets is
what keeps them hardware-store-refillable (the trust story). The BRICK is the one
true plug-in daughterboard: it groups exactly the parts that die TOGETHER in a
single event class (a mains event degrades the MOV and opens its witness in the same
half-cycle — undiagnosable individually without gear, so the service unit is the $3
board). The SNOUT is the second plug-in board — and its justification is now DAMAGE ONLY.
CYCLE-WEAR RESOLUTION (owner bench pushback, 2026-07-24 — owner RIGHT, resolved
with numbers): the Molex durability specs (30 cycles std PS-5556 / 100 cycles HMC
gold PS-444850001) qualify a low-level-contact-resistance floor (+10–20 mΩ class)
that matters at HIGH-CURRENT duty (at 6 A real-PSU use, 20 mΩ = 0.72 W of heat in
one contact — that is what the spec protects). This box reads voltage through
megohm dividers at ≤0.26 A: a contact would have to degrade to **2.3 Ω — 115×
worse than spec end-of-life — before a ±5% window lamp even reaches its edge**
(0.26 A × 2.3 Ω = the 0.6 V window half-width; a spec-dead 20 mΩ contact
dissipates 1.4 mW here). Owner bench experience (hundreds of matings on PSU
testers, zero issues) is exactly what this physics predicts. CONSEQUENCES:
wear-based snout replacement is RETIRED from the consumables story and forecast;
the HMC/gold adder is DROPPED (standard tin is correct at this duty); the snout
survives only as a DAMAGE/SERVICE spare — bent pins from cross-insertion, broken
latch, a mangled DUT connector chewing ours — plus a production sub-assembly
convenience (the consigned Mini-Fit hand-solder happens on a $0.6 paddle, not the
main board). Open decision #13: KEEP the paddle (recommended — damage repair
without board rework, ~$1.3 delta) vs board-mount the connector directly (−$1.3,
one less board, damage = main-board rework). Connector tech: keyed 0.1 in header
sockets, NOT the platform TE-blade ecosystem — the module output daughterboards
carry 18–52 A continuous (30 A blade joints earned); the brick carries ≤0.6 A
continuous and big current only as fault transients. Pulse math for the socket: a
230 VAC clearing event pushes ~50–150 A through one pin pair for <10 ms ≈ 0.5 J ≈
+13 K adiabatic in a brass pin — inside a 3 A-rated pin's pulse capability, events
are rare by definition, and the brick pinout doubles the GND return pins anyway
(2×8 = 16 positions: 5 ways + 5 returns + harvest node in + store & domain legs
out + 2 key/spare). Contact-pitting
after repeated mains events is a first-article bench watch item, not a redesign.

**Blade format (ruled at refinement): full-size ATO/ATC (19 mm)** — not Mini/ATM or
Micro2/3. Reasons: the most universal automotive format on earth (the trust story),
the best panel-holder availability, glove-friendly handling, standard color code
(brown = 1 A everywhere), and panel real-estate is not the constraint. Mini would
save ~40% panel width at the cost of fiddlier handling and thinner corner-store
coverage.

**Coordination story (why two fuses in series):** the 1 A fast blade clears every
low-voltage event first (selectivity by rating ratio 1:2 and speed class F vs T).
In a mains event the blade opens but can sustain an arc (it is a 32 VDC part); the
current continuing through the arc cooks the 2 A time-lag HRC, which is built to
break 250 VAC into sand. The witness resistor (1 Ω flameproof fusible, in series
with its MOV) opens with its designed benign puff — that is the safe smoke — and
disconnects the spent MOV so a failed-short varistor cannot latch the way.

## 3. Per-way electrical spec

See `assets/smoke-tester-way-sketch.svg`. Five fused ways (core only — the 3 AUX
ways + continuity way were DESCOPED with the AUX port, owner ruling 2026-07-25, §5).
All windows ±5 % nominal, LM339 comparator pairs against a TLV431-derived ladder; taps measure DOWNSTREAM of the sacrifice chain (post-event a
way honestly reads dead).

| Way | Blade | HRC | MOV (brick) | Witness | Divider (to DUT GND) | Window at node |
|---|---|---|---|---|---|---|
| 12 V | 1 A F | 2 A T | S14K14-class (14 VRMS / ~22 V VV) | 1 Ω 1 W fusible | 903 k / 100 k (÷10.03) | 1.137–1.257 V |
| 5 V | 1 A F | 2 A T | S14K6-class | 1 Ω 1 W fusible | 903 k / 100 k | 0.474–0.524 V |
| 3.3 V | 1 A F | 2 A T | S14K4-class | 1 Ω 1 W fusible | 903 k / 100 k | 0.313–0.346 V |
| 5VSB | 1 A F | 2 A T | S14K6-class | 1 Ω 1 W fusible | 903 k / 100 k | 0.474–0.524 V |
| −12 V | 1 A F | 2 A T | S14K14-class (MOVs are bidirectional = free reverse clamp) | 1 Ω 1 W fusible | 100 k to +2.5 V bias / 15 k / 903 k string | level-shifted window, healthy/absent/OV separable |

**MOV column SUPERSEDED at sourcing (2026-07-25):** the brick populates a UNIFORM
14D220K (22 V) disc on every way — LCSC carries no low-voltage 14D discs in depth,
and one value = one brick pattern. Consequence recorded honestly: the 6–25 V OV band
on minor rails is DETECT-ONLY (windows lamp red); crowbar action begins where the
22 V MOV conducts, and the ◆GDT (~90 V sparkover) + fuses take the mains class. −12 V
shares the same bidirectional disc. Full brick detail: `brick/README.md`.

Divider top legs are 3 × 301 kΩ 1206 in series (voltage sharing — each sees ≤110 V at
230 VAC on the way; 1206 rated 200 V, string rated 600 V). Mains math sanity: 230 VAC
onto a way drives the MOV into conduction at tens–hundreds of amps → both fuses clear
in ≤ a half-cycle, witness opens, comparator node never exceeds ~2.4 V through the
÷10 string even mid-event.

Min-load bleeders (switchable, "MIN LOAD" DPST): 47 Ω 10 W on 12 V (~0.26 A) + 10 Ω
5 W on 5 V (~0.5 A) — enough for group-regulated antiques to regulate, small enough
that 1 A blades never see >0.6 A legitimate. **FIRST-CONTACT RULE (owner Q
follow-through, 2026-07-25): MIN LOAD stays OFF for first contact — throw it only
after the first green read.** With the bleeders out of circuit, the only conduction
paths during the riskiest window are the self-disconnecting clamp legs (witness
opens in sub-ms) and the megohm dividers — a DC incursion then has NO low-impedance
path that would force the 32 VDC-class blades into a breaking role at 400 V. Panel
silk + the truth-table card carry the rule.

**Both grids, one box (owner Q, 2026-07-25):** the tester touches only the DUT's DC
outputs, so whether the PSU eats 120 VAC or 230+ VAC changes NOTHING in normal
operation — the secondary rails are the same 12/5/3.3 V either way, and the fuse
CURRENT ratings key on the tester's own draw (bleeders + microamp taps), which is
input-agnostic. Input voltage matters only for the mains-on-a-rail FAULT class, and
every mains-facing element is specced at the 230 VAC / 325 Vpk worst case, which
covers 120 V automatically as the milder instance: 250 VAC-class HRC interrupters
(ways + smoke branch), 300 V-working divider strings + ≥3.2 mm creepage, and strike
points (GDT/neon ~90 V) that fire from 120's 170 Vpk just as well. Same fuses, both
grids, no switch, no variant. The one distinct ingress is the PSU's PRIMARY PFC BUS
(~380–400 VDC, no zero-crossings — harder to break than AC): in the real fault it
arrives through the failure's own impedance and is bounded by the DUT's input fuse +
bulk-cap energy; the arc bench carries an explicit DC-ingress row (§9) to prove the
HRC/GDT chain there rather than hand-wave it.

**DC-incursion handling — the designed sequence (owner Q, 2026-07-25).** A stiff,
continuous 400 V source is not a physical PSU presentation: the bulk rail is a
CAPACITOR BANK (~390–560 µF at ~400 V ≈ 30–45 J) behind the PSU's own input fuse —
a hard primary-to-secondary breakdown delivers a tens-of-milliseconds droop-to-dead
dump, not a lab supply. The box's designed response ORDER exploits that: (1) GDT
strikes (arc ~20 V) and hogs the current off the MOV; (2) the 1 Ω witness — the
lowest-value, fastest element in the chain — opens in sub-ms at dump currents and
DISCONNECTS the clamp leg; (3) the way then floats at fault potential behind ≥900 kΩ
dividers (3×301k 1206 = 133 V/element at 400 V, inside their 200 V rating, 59 mW
each) while neons + red windows scream — with MIN LOAD off (first-contact rule
below) there is NO path left that asks a 32 VDC blade or 250 VAC HRC to break DC at
400 V. If MIN LOAD was engaged when the DUT let go, the event is still bounded by
the dump energy (blade arcs for the tens-of-ms droop, HRC + sand as backstop) — the
bench DC row proves both cases. UPGRADE PATH EVALUATED AND REJECTED: 10×38 gPV
solar fuses (1000 VDC breaking, the cheap high-DC commodity) on every way ≈ +$15–20
and a much larger board — disproportionate for a corner that physics already bounds
and the sequence already handles; recorded so the decision is visible (realism
ladder: concept §9.14).
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

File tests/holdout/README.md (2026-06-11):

# Held-out eval pool (CL-11)

The tuning-free complement to `tests/golden/`. **Goldens are frozen regression anchors and
are BURNED for tuning the moment a prompt or charter is adjusted against them** — the
framework's verify steps literally instruct adjusting against the goldens, so a separate
pool that tuning never touches is what keeps evaluation honest.

## Rules

- **Never tune against this pool.** No prompt, charter, threshold, or check parameter is
  adjusted to make a holdout case pass. A holdout case is consulted only when EVALUATING a
  candidate change (CL-19 extractor eval, CL-22 panel seat gating, CR-03 adoption replay).
- **Grown, not authored:** entries arrive from every adjudicated override (an owner verdict
  that contradicted a tier), every CL-13 bench label, and every escape — never invented.
  Each entry records its provenance (decision_id from the ledger, or the bench run).
- **Thin at first is correct.** An empty pool is honest; a padded one is not. The pool's
  size is itself a reported metric, never narrated past its N (the DF-04 floor discipline).
- Format mirrors `tests/golden/fixtures.json` (board state + expected flag IDs), one
  subdirectory per case, manifest in `holdout.json` once the first case lands.

## Why this directory exists empty

Created with CL-11 (2026-06-10) so the SPLIT exists before the first adjudicated override
arrives — capture cannot be retroactive (the DF-01 argument applied to eval data). The
first entries are expected from the wave-3 morning-bundle verdicts (CL-12) and the first
bench labels (CL-13/SB-06).

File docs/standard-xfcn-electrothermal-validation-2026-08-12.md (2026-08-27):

# Standard XFCN electro-thermal validation — 2026-08-12

## Disposition

**PROTOTYPE ELECTRICAL GEOMETRY PASS / production release remains blocked.**
Every daughterboard now has complete copper connectivity, solid power-pad
connections, and passes its per-net cold copper-path budget. The isolated-board
30 °C rise screen still fails because it deliberately supplies no terminal,
cable, fastener, or enclosure heat path. That result is not overridden: release
still requires a correlated 3-D assembly model or representative hardware data.

The complete machine-readable sweep is in
`output/xfcn-electrothermal-20260812/results.json`; the generated detailed table
is in the adjacent `report.md`.

## Authority and modeled geometry
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

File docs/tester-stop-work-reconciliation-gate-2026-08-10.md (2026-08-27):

# PSU Tester program — stop-work and reconciliation gate

**Status: STOP WORK — mandatory program gate, effective 2026-08-10.**

This document blocks implementation work on every board and mechanical assembly
under `testers/` until the findings below are reconciled. It applies to Tester
Standard/ST-1000/ST-1300, Pro, Max, fast-channel slices, slot decks, fixture
heads, resistor-bank walls/cartridges, and their shared electrical interfaces.

## 1. Work that is blocked

Until this gate is released, do not:
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

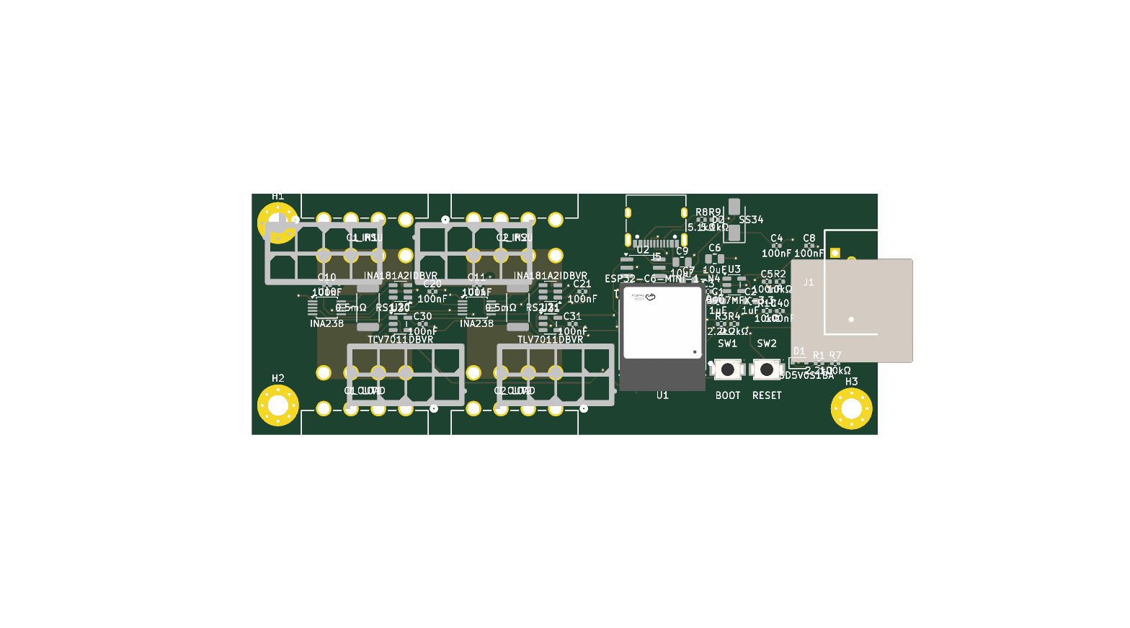
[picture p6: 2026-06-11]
docs/fullstack-run-2026-06-11-validation/vision/pour-r1.png

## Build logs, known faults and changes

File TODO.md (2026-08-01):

# TODO

The LIVE list of what the agent is ACTIVELY working on, in checkbox form. **APPEND-ONLY** — items are
never deleted; completed / obsolete ones stay as a timestamped history.

Format:
- `- [ ] [added YYYY-MM-DD HH:MM] <task>` — active
- `- [x] [added YYYY-MM-DD HH:MM · done YYYY-MM-DD HH:MM] <task>` — completed (left in place)
- `- [~] [added YYYY-MM-DD HH:MM · obsolete YYYY-MM-DD HH:MM → <tombstone>] <task>` — obsolete, with a
  tombstone pointing where it went (e.g. `FOLLOWUPS.md "<entry>"`, `PR #N`, `docs/owner-queue.md`, another line)

Distinct from FOLLOWUPS.md (deferred / non-blocking backlog) and docs/owner-queue.md (owner-action items).
Times are UTC.

## Active

- [ ] [added 2026-07-25 08:00] **POUR PASS 2 — five-part live-variant mandate LANDED** (design doc
  "v4 pass 2" state note; probes build/pourprobe2/). (1) planner rate: `_preconnect_merge` (same-net
  locked copper = already-present corridors; the s510 /SENSE3V3_LO 598mm² amoeba re-solved an
  ALREADY-CONNECTED net), per-layer `lay_attach`, approach ∪= own manifolds/tracks, honest
  `width-infeasible` diag (In2 1oz demands 16-46mm at rail currents — physics, not a corner-graph
  bug) — planner-owned 2/9 → 5/9, path_found 5/9 → 7/9 on 6 live variants; residual +5VSB +
  /SENSE12V_HI = J3-belt width class (both engines agree; force-rail REFUSALS remove their
  pre-connect — owner design question stands). (2) region-class (+3V3): `_realize_region`
  power-plane doctrine — ONE In2-else-B region + per-island pad-aware via fields + landings, no
  tree/bridges/snake. (3) fallback realization: `realize_overunder_rects` (capsule covers per run +
  boundary via fields; smear only behind CEC_OU_SMEAR=1). (4) hygiene: zero-cluster reap overrides
  name exemption; zero-fill zones die; orphan-via sweep (pour-live-gated). (5) SINGLE-OWNER
  WHITELIST at the freeze (`enumerate_winning`): 10 insurance dicts dropped per variant; import
  no longer resurrects patches for frozen nets; region layer = the solve's choice (ask = preference).
  Teeth 80/80 in-container; golden in flake band (unconn 17 / thermal 1799). ACCEPTANCE DONE:
  wave s530-532 winner plain-compact-s532-polish — planner-owned 6/9 / paths 7/9; measured on the
  published board 0 zero-cluster + 0 zero-fill zones, 0 orphan stubs; render PASS2-winner-*-hex.png
  worklogged (five-class verdict in the dash entry). Pass 2b/2c closures: cell-geometry native
  attach, neck minority-ratio rule, 4-connected spine stamping, reaper pre-verdict skip removed,
  publish hygiene. OPEN: J3-belt class (+5VSB, /SENSE12V_HI — corridor abstraction cannot count
  PARALLEL gap cross-sections at a connector belt; owner design question); /SENSE3V3_HI rides the
  rect fallback (neck-rejected honestly).
- [ ] [added 2026-07-25 05:10] **v4 TERRITORY POUR PLANNER — LANDED, 24-pin wave param ON** (owner GO,
  docs/slab-pour-design-2026-07-24.md v4). `scripts/cec_pour_plan.py`: manifolds/patches/terminal
  groups → Prim tree → obstacle-corner corridor candidates (direct/L/bounded corner Dijkstra) →
  exact-at-scale B&B layer assignment (most-constrained-first) → crossing SPLIT w/ ONE compact
  field → geometric min-width proof + raster clearance/attach verification → per-net LOUD
  route_overunder fallback (the Dijkstra demoted). Via-line ROOT CAUSE probed + double-ablated
  (design doc v4 state note): 16 F-only SMD islands = mask-forced terminal attaches, mess was
  realization smear — NOT a search bug. s464: **7/9 planned (baseline 6/9), zero mid-span fields,
  every field terminal-labeled**; fails (+5VSB, /SENSE12V_HI) ⊂ baseline's 3 (J3-belt class, the
  standing owner question). Teeth tests/test_pour_plan.py (8); all pour suites 46 green
  in-container; golden untouched (flake band unconn 17 / thermal 1799). `pour_plan: True` in the
  24-pin params; `cec_pourfirst.py --v4` standalone; artifact POURFIRST-*-s464-v4-hex.png on the
  dash. OPEN: first full wave with the param on (fail-open protects); +5VSB//SENSE12V_HI belt
  crossing = owner design question; capsule end-caps cosmetic (round lollipops).
  **[2026-07-25 follow-up rulings LANDED + s464-re-proven (7/9 holds):** POUR TERMINATION
  (patch inner-edge clip via `_shunt_pad_halves`, gap strips excluded from planner F space /
  landings / emit — 2 measured intrusions -> 0) + VIA-IN-PAD assembly-class exclusion
  (`_via_pad_excluded` in `_via_spot_clear`/`add_via_field`/`add_overunder_vias`/
  `synthesize_force_vias` outboard-base fix + `_array_sites` own-net-skip root-cause fix +
  planner `_spot_ok`/`_field_vias` slide-reseat). Fresh run: NEW in-pad vias 0/97, gap
  intrusions 0; 3 LEGACY locked array vias in the historical skeleton regenerate clean at
  next materialize. Zoneless+filled shunt-band F.Cu crop worklogged (rung-gate artifact).
  Residual: `cec_channel_route.py` (caller-less tool) not guarded; legacy skeleton artifacts
  keep pre-fix locked vias until re-materialized.]**

- [ ] [added 2026-07-25 02:45] **POUR-FIRST PLACEMENT RUNG (owner v3/v3.1 ruling) — pipeline seam landed.**
  `csp.pour_first_stage` wired into `_build_session` behind param `pour_first` (24-pin ON): anchor-only
  materialize (connectors+stamps+MCU from `Candidate.pourfirst_anchor_refs`) → one solve (v3.1
  connector manifolds + width-margin attach + over-under + patches) → FREEZE (CEC_POURFIRST_STATE
  route-side passthrough w/ NO re-solve + NO slab fallback for frozen nets; F.Cu avoid boxes into
  p8/p9; POURFIRST artifact → build/wave-snaps). Nowhere-reaper (`reap_nowhere_zones`) at the
  import cleanup site (pour-paths only; patch:/manifold:/pourfirst: names exempt). Teeth:
  tests/test_pour_first.py (15; all pour suites 38 green in-container). MEASURED: manifolds do NOT
  flip the 3 s415 skeleton no-paths (margin 4/6/8 sweep; bottlenecks = locked via triplet + cell SMD
  pad + trunk-walled J3-6 — not the connector-group thesis; design doc v3.1 state note). OPEN: e2e
  variant audit + owner review of the frozen-state semantics on +3V3-class logic floods.

- [x] [added 2026-07-23 07:30 · done 2026-07-23 12:25] **Overnight studies + chain (owner GO)** — landed probe-first: rules carriage (drill 12→0), width-aware+arc edge keepouts, hub power rung (evac-False pour asks + power-pickup stitch), hub thermal entry (J_PWR anatomy), 24-pin Power patterns, floors 150/170. Gates: rung probes v1/v2 + width probe + golden delta measured, then commit + 6-round night chain (s182-217 / s72-107). Morning report owed.

- [x] [added 2026-07-23 05:35 · done 2026-07-23 12:25] **Fix-wave readout** — 24-pin s176-181 + hub s66-71 running (watcher bfco4e0ea); commit 870ef278 pushed. Judge: first graded hub boards since s41 (plateau floor), 24-pin post-fix unconn/criticals under honest netclasses (numbers NOT comparable to seg-era rows), J6C fallback-tier grind rate, C1|U10 class rate.

- [x] [added 2026-07-23 05:05 · done 2026-07-23 05:35] **Resume-ladder items 1+2: Kelvin/walk fix + hub routing-stage root cause** — hub answer MEASURED (two layers: seg4 = 100% pre-route H1|jellybean refusals from the M2-override never reaching materialize [board carried M3 under an M2 model]; seg3 = plateau-kill discarding terminal-grind boards: killed togo-34 hub re-routed to unconn 7 / kelvin TRUE = best hub ever). 24-pin INA|shunt class root-caused as the WALK PITCH COLLAPSE (J6C v3 seat walled the walk at x~39 -> pitch 12->5.38/8.0; the Kelvin cell itself is in the hand-board band). LANDED: plateau floor (CEC_FR_PLATEAU_FLOOR, per-board 100/170) + REST allow-list; mount_fp threading into build_board/materialize; materialize _bdir beta-first (netclass/DRU carriage silently lost since the move!); walk floor 9.0 (CELL_PITCH_FLOOR, measured) + _lb-clamp ordering fix + calibrated band [-6.5,+13.9]; seats v4 (probe: walk-band region + multi-substrate stability tiers + seg-seg legality); U1 hard pin (66,41.4,-90); p11 fiducial eviction rung; 7 beta-move path stragglers. VERIFIED: both refused 24-pin seeds now FULLY CLEAN pre-route (pitches 10.35 uniform), hub s65 clean / s62 = pre-existing C1 class only. Teeth: test_plateau_floor + test_rail_walk_floor + fr_rest/mating_frame extensions.

- [x] [added 2026-07-24 02:46 · done 2026-07-24 02:52] **hub-standard missing from the ESP-IDF folder picker (owner ask)** — root-caused: `firmware/cec-firmware.code-workspace` never listed `esp/proto/hub-standard` (the extension's folder icon enumerates VS Code workspace folders only, it does not scan for IDF projects). Added the workspace-folder entry + a per-app `.vscode/settings.json` (v6.0.2 setup, esp32s3, COM port left unset) matching the atx-24pin/eps-8pin pattern. On branch claude/hub-firmware-location-9qleb4. Scaffold apps still unlisted → FOLLOWUPS.
- [x] [added 2026-07-10 22:50 · done 2026-07-10 23:15] **Scoping pass (owner ask, NO runs/waves): GPU-shader worthiness for router/placer (FEM already GPU), placer parallelization + packing-correctness levers, FEM solver completeness audit (opus sub-agent)** — DONE: standing results in docs/pipeline-solver-roadmap.md (GPU-reachability section + shader verdicts + decision log) + FOLLOWUPS 2026-07-10 block + handoff G18. Headlines: GPU paths all currently unreachable (cupy/pyamg lost to runtime-pip; bake into Dockerfile.routing); no shaders now (FEM determinism fix first ~1h @ cec_thermal2d.py:546; coord-router A/B failed twice; placer <2% of candidate); throughput levers = prune→adjudicate wiring (~8x FR savings), FR REST, LoadBoard/DRC dedup.
- [x] [added 2026-07-10 23:00 · done 2026-07-10 23:15] **G17 closed: 12vhpwr J3/J4 side-column ROOT CAUSE + FIX** — anchor_roles reached _classify but not seed_anchors edge seating (sideband data pins → both "host" → right edge); role_overrides= threaded through seed_anchors + synth_one, +3 regression tests (test_placer_oracle 44/44). Verifying wave re-run awaits owner green-light (scoping-only session). Pre-existing red: test_corridor_model test_phase2_default_placement_is_legal (ablated not-mine, FOLLOWUPS).
- [x] [added 2026-06-24 05:20 · done 2026-06-24 05:35] **12VHPWR thermal integration — wire production case-cooling into the dashboard** (closes the named FOLLOWUP). board_thermal_config now returns a 4th `cooling` spec; render_per_layer applies the metal-case model (TIM on RS1-6 shunts + M3 mounts) so the 12VHPWR dashboard shows the owner-validated maxT 72.95 / dT 22.95 = PASS, not the still-air 151/dT101. Env knobs CEC_THERMAL_NO_COOLING / _TIM_WK / _MOUNT_WK walk the envelope. Verified in-container (prod / still-air / conservative-TIM). SB-08 golden proven INERT (cec_golden imports cec_fr/cec_score/cec_synth_pipeline only). Committed bb60c65 (thermal) + 55be140 (place-planner WIP banked). EPS/PCIe generalization → FOLLOWUPS (owner sign-off).
- [x] [added 2026-06-24 06:05 · done 2026-06-24 06:55] **24-pin ATX shrink study (owner overnight ask)** — got the loop running on the 24-pin; compared the two connector revisions. RESULT: rev2 (90° rotated output, modules/atx-24pin-rev2) = 6576 mm², routes clean, **21% SMALLER than straight-through (8342 mm²)** — owner's hypothesis confirmed. Both at their rigid-shrink floor (0%, connector/part-bound). Found ~1270 mm² (~19%) dead space in rev2's stale U1 keepout (lib already 16×21, board 45×35) → Update-from-Library + guided re-place could reach ~36% vs straight. Pour-resize won't shrink the outline (part-bound). Dashboard :8095 (build/24pin-rev2-shrink); writeup docs/24pin-shrink-2026-06-24.md. Next levers → FOLLOWUPS (owner greenlight).
- [x] [added 2026-06-24 05:40 · done 2026-06-24 06:15] **Push placement-corridor → PR #60** (owner: "Go ahead and push it up"). Pushed 3089680..c45c179 (thermal integration + place-planner WIP + doc fixes); no CODEOWNERS path touched.
- [ ] [added 2026-06-24 05:40 · in progress] **Fine-grained 12VHPWR board passover** (review workflow wf_b3e2a860-3a6: conformance / route-fab / thermal / loop-fit / doc-accuracy + adversarial verify). Anchored ground truth: board is FULLY ROUTED (0 unconnected, 0 parity, 15 cosmetic-silk DRC), not DRAFT, fab/12vhpwr-standard-proto-v1 exists. CLAUDE.md action-item-4 ("47 ratlines remain / Fill zones / dangling vias") is STALE → doc-fix pending the reviewer. Worst-case 12A pin-hog thermal re-checked under the new solver (result pending).

- [ ] [added 2026-06-15 00:15 · in progress] **FR-on-Hub routing FIX + full hour run** (owner: "do the fixes"). FIXED FR routing the Hub: (1) on-board OFFSET — synth 0-origin coords were placed off the committed outline at (70,90) → FR routed nothing (THE unblock); (2) `_seat_antenna_ic` — ESP off the ganged ports → residual 4→0 (+ antenna term fixed to use courtyard near-edge: ref 0.565→1.0, synth 0.0→0.903, hub_penalty 0.373→0.125); (3) two-process GND fill (Remove footgun). RESULT: low-effort route_once 628 tracks / 39 unconnected / kelvin+diffpair pass / len 2240 (was 2/216). 103 placer tests green. Discriminator test: committed HAND placement routes 389 wires (baseline). NEXT: commit + LAUNCH the hour run.
- [x] [added 2026-06-14 22:50 · done 2026-06-14 23:30 · SUPERSEDED 2026-06-15 00:15 by the FR fix above] **FULL pipeline (place→route→check) wired + run on the Hub** (owner: "if it's all wired up, run the full pipeline for an hour"). scripts/hub_pipeline_run.py wires the route leg; `materialize_onto_reference` fixed the materialize gap (build_board output isn't DSN-exportable → copy the committed Hub + reposition, in a spawn subprocess to dodge the pcbnew Remove footgun). Chain runs end-to-end. **BUT Freerouting does not route the Hub** — emits 1 wire (FR log: autoroute pass#1 "1 change" → pass#2 "0 changes" → stops), 216 unconnected; the identical path routes cable modules to 556 tracks. So an hour run is NOT worthwhile (reproduces the 1-trace result) — reported instead of burned. Placement is solid (correct frame, gates pass, max_T 68.7). FR-on-Hub fix path → FOLLOWUPS item 4. Findings: docs/placer-upgrade-2026-06-14/STATUS.md "FULL PIPELINE".
- [x] [added 2026-06-14 22:40 · done 2026-06-14 23:15] **Hub pipeline TEST RUN (in kicad10 container)** — place→materialize→render→DRC→score ALL ran on hubs/hub-standard with the oracle. Result: correct oracle frame (98.1×74.1, 8 edges), 80-part board, residual 4, corridor_cross 0, **similarity 0.705**, **HPWL 1.25× the hand board (down from 1.84× pre-MV)**, hub_penalty 0.373 (antenna 0.0 = the known gap). DRC 575 (~506 cosmetic silk/lib; ~64 real-structural tracking residual-4; 211 unconnected = UNROUTED, route leg not wired). **The pipeline WORKS at the placement level.** Recipe + numbers: docs/placer-upgrade-2026-06-14/STATUS.md "HUB PIPELINE TEST RUN".
- [x] [added 2026-06-14 21:50 · done 2026-06-14 22:55] **MV2→MV5 placer-upgrade build + consultative audit** (owner: fan out for impl + audit at the end). IMPL committed 26d9a77; 4-skeptic parallel audit (geometry/charter/regression/test-rigor) = SHIP-WITH-FIXES, 0 blocker; ALL findings verified + fixed in a follow-up commit (H1 similarity renorm, M2 sense-net rail exclusion, M3 edge_override validation, charter MEDIUM topological power-loop derivation, regression MEDIUM oracle-failure logging, 2 HIGH test-rigor MV3/MV4 plan-validation tests + scramble/sort-key teeth + LOW comments). 41 tests green, checklist exit 0. Status+audit: docs/placer-upgrade-2026-06-14/STATUS.md. DEFERRED→FOLLOWUPS: MV5 generative closers + the Hub full-stack run.
- [x] [added 2026-06-14 21:50 · superseded by line above] **MV2→MV5 placer-upgrade build** (continue the MV checklist; owner: fan out for impl if needed + consultative audit at the end). DONE (cec_synth_pipeline.py + tests/test_placer_oracle.py, 31 tests, checklist exit 0): MV2 net-aware `_role`/`_connector_net_role`/`_is_rail_net` + `oracle_stage1_answers`/`apply_oracle_stage1` + `seed_anchors(edge_override=)` 4-edge + `place_mechanical(mount_pos_override)`; MV3 `oracle_similarity` DIAGNOSTIC (identity 1.0/scramble<1, NEVER a rank key — `_candidate_sort_key` test enforces); MV4 `proxy_score` (==hpwl with no ref → zero regression; ref-normalized HPWL-dominant composite) + sort-key swap + cfg knobs; MV5 `build_hub_model`/`hub_score` (port_even/antenna/power_cluster mux-loop/usb_prox, gated to ≥2 ports+ESP, reference scores well hub_penalty≈0.27 vs synth≈0.60). Status: docs/placer-upgrade-2026-06-14/STATUS.md. Anti-overfit charter honored (reference=validation only). DEFERRED→FOLLOWUPS: MV5 generative closers (power cohesion sweep + antenna-edge ESP seed). NEXT: parallel adversarial audit → verify → fix → SB-08 in-container.
- [x] [added 2026-06-13 23:25 · done 2026-06-13 23:33] Await DeepSeek new-impl audit → consolidate the Opus-4.8 + DeepSeek verdict (both merge-ready, 0 blockers; DeepSeek's 3 HIGHs = diff-only false positives)
- [x] [added 2026-06-13 23:33 · done 2026-06-14 00:10] new-impl polish fixes — #56 portion: H1 temper T0-overpromise prompt; M1 corridor fallback+log; M2 lane-gate T0/kelvin_stall (_t0_should_fire helper); M3 wire host suites into checklist.sh+CI; L3 in_family_only n_in; L4 progress history[:-1]; L1 deepseek_audit _coerce parity; L6 delete dead PENALISABLE (+6 tests; 159 host tests green)
- [x] [added 2026-06-14 00:10 · done 2026-06-14 00:30] new-impl polish fixes — #57 portion (claude/bot-push-guard, commit 70e176d): H2 pre-push GIT_TERMINAL_PROMPT=0 on the credential-fill probe (fail-closed, no-hang verified); L14 drop unused `root` var. Deferred pre-push LOWs L12/L13/L15/L16 → FOLLOWUPS.md (owner-scoped)
- [x] [added 2026-06-14 00:35 · done 2026-06-14 01:05] Adversarially verify the #56 polish fixes (wf_789eb5bc-b59, 8 skeptics + synth = SHIP-WITH-FIXES) → harden M1 (log even on empty fence) + L3 (header counts shown-under-truncation) + 2 tests; residuals (12vhpwr corridor siting, run()-level H1/L4 coverage, verifier worktree-isolation) → FOLLOWUPS. 161 host tests green
- [ ] [added 2026-06-13 23:25 · in progress 2026-06-14 01:20] Build `claude/seat-bakeoff` PR: cloud-seat shim → 2-D variant×model bake-off → 6-judge leave-one-out panel → de-overfit → data-chosen `--seats cloud` defaults (+ DeepSeek `--stream` live thinking). Owner: BUILD + RUN the full sweep.
- [x] [added 2026-06-14 04:33 · done 2026-06-14 04:50] Corridor-aware reseed placer **Phase 0** (docs/placement-strategy-2026-06-14.md): `build_corridor_model` + `corridor_cross_count` (cec_synth_pipeline) + the two missing checkers `shunt-inline-in-corridor` / `high-current-corridor-keepout` (cec_constraints) + `tests/test_corridor_model.py` (19 tests). PROVEN on committed eps-8pin: model reports ≥3 through-crossers (/DETC1,/THRESH,/I2C), /CAN_L=0; keepout checker has teeth (foreign track→FAIL). Wired into checklist host suite (134 green). Branch claude/placement-corridor.
- [x] [added 2026-06-14 04:50 · done 2026-06-14 05:25 · CLAIM RETRACTED 2026-06-14 06:00 → see audit-remediation line] Corridor-aware reseed placer **Phase 1a**: `Candidate.corridor_cross` + model build in synth_one + sort key `(residual, corridor_cross, hpwl)` + opt-in `proxy_reject(corridor_max=)`. ⚠ The "ranking alone breaks the ceiling" claim was a measurement artifact (degenerate bands) — RETRACTED by the audit; Phase 1a stands as honest rank-key plumbing only. Real ceiling-break = Phase 2 (corridor formation).
- [x] [added 2026-06-14 05:40 · done 2026-06-14 06:00] **AUDIT REMEDIATION** of Phase 0/1a (4 parallel skeptics, PR #60). BLOCKER confirmed + claim RETRACTED: synth winner's `cc=0` is a degenerate-band artifact (shunts land x~7.5 vs connectors x~30-43 → bands ~73mm/96mm, can't be straddled). Fixed: (1) band from connector+2-pad-shunt pads only, exclude INA SMD (matches derive_power_pours; reviewer A F-1, B F-4). (2) `formed`/degeneracy guard (`board_w`) → unformed corridors score 0 INERTLY not falsely-clean. (3) checker false-FAILs on 12VHPWR/24-pin (shared-bus → N/A, Phase-5 variant) + `_sense_nets` exclusion (reviewer B F-1/2/3/4 — 2 BLOCKERs). (4) determinism: sorted() set iteration in relative_place/anneal_macros (reviewer C F-2 — compact s6 now stable 0, was {0,1,2}). (5) tests: place_candidates production-sort (tautology, reviewer D F-1 BLOCKER) + via teeth + shunt-FAIL teeth + shared-bus-NA + multi-cable + no-kelvin + degenerate-guard; honest reframe (34 corridor / 159 host green). (6) doc claim retracted honestly. Deferred→FOLLOWUPS: seg-AABB exact, CI pcbnew wiring, parity re-freeze (owner).
- [x] [added 2026-06-14 06:25 · done 2026-06-14 06:55] **Phase 2 — corridor FORMATION** (89266ab): `_cable_topology` + `_seed_corridor_spine` (align J_OUT's force-pad COLUMN under J_IN's, seat shunt on the column axis at rot270/H3 as fixed anchors) + `_corridor_veto` + `anneal_macros(veto=)` (no HOT/SENSITIVE body in a foreign band). Synth bands now 15.6mm = the committed board's. **KEY FINDING: cc=6 is the INHERENT FLOOR** — the committed (best hand) board is also cc=6; the 6 foreign signals must cross the full-height current corridors to reach the central ESP. Placement CANNOT reach cc=0; the pour-cut failure is route-time LAYER ASSIGNMENT, not placement. OPEN (FOLLOWUPS): residual regressed 2→6 (veto/legalizer tuning); the layer-assignment pivot is the owner's call.
- [~] [added 2026-06-14 06:25 · obsolete 2026-06-14 06:40 → re-run clean] **Audit (1st attempt) corrupted the shared worktree** — a verify-agent's `git checkout` reverted my uncommitted Phase 2 edits (worktree-isolation hazard). Stopped (TaskStop wpnhp01ff), re-applied Phase 2, committed. Re-run on the committed tree (no uncommitted work to lose) → next active line.
- [ ] [added 2026-06-14 06:55 · in progress] **Audit the remediated Phase 0/1a + Phase 2** (workflow wt1frw8xk, on the COMMITTED tree c867f34, verify-agents in isolated worktrees so a git-checkout can't lose work). Triage + verify + fix confirmed findings. NOTE: launched before the overhang commit 192503d; reconcile the cc-floor over-claim (channels DO exist -> the metric over-counts) when it lands.
- [x] [added 2026-06-14 07:00 · done 2026-06-14 07:05] **Auto-overhang cable ports** (owner insight, 192503d): synth_one defaults connector_overhang="edge" for cable-corridor boards -> J_IN/J_OUT seat at edges, corridor spans full height, **residual 6→0**. Plot tool scripts/gen-corridor-plot.py. Remaining: cc 14 vs committed 6 = peripheral parts (CAN/USB/ESP) scattered into crossing positions → next lever "keep non-cable nets off the corridor side".
- [ ] [added 2026-06-14 07:05] **Peripheral placement lever**: keep non-cable parts (CAN xcvr, USB, ESP, RJ45) clustered away from the corridors so their nets don't cross (the committed board does this → cc 6 not 14). Distinct from corridor formation.
- [x] [added 2026-06-14 07:25 · done 2026-06-14 07:45] **Phase 1+2 audit remediation** (4d2c98e): shared-bus exclusion in build_corridor_model (12vhpwr/24pin inert), overhang value→power_able, spine pad-clamp, corridor_cross docstring de-overclaimed, doc CORE-PREMISE rewritten honestly (cc=6 = hand-board analytic floor, placer is WORSE at legal cc 8-24), 24pin test-filename fix + residual==0/band-width asserts + _corridor_veto/_shared_bus unit tests. 37 tests green.
- [x] [added 2026-06-14 07:45 · done 2026-06-14 08:05] **Wire the corridor lever into the tier loop** (c25ee66): `corridor_violations` (board→sensitive bodies in foreign formed bands) + cec_place `apply_corridor_evict`/`evict` directive/refine injection + cec_router `corridor_evict_repair` in MANAGER_REPAIRS. Verified end-to-end (detect→evict→cleared; manager emits place_nudge). +6 tests (43/68 green). Lever in BOTH planes (nightly refine + routing-tier manager).
- [x] [added 2026-06-14 08:05 · done 2026-06-14 08:25] **Panel: corridor lever vs EI + routing tier** (wzx07zl6f, WORKS-WITH-GAPS). Findings: shape-PARITY with the routing tier confirmed (corridor_evict_repair ≅ kelvin_inversion_repair; dual-plane). **G1 (HIGH) FIXED (e01ddd7)**: apply_corridor_evict had no containment guard → dragged the corridor shunt in refine() → false-clean. Deferred → FOLLOWUPS: G2/G3 (EI-instrumentation: not lane-tagged / no corpus_state / not model-proposable / replace-Delta inert) = the overnight-run prereq; cluster-divergence (router nudge bare-ref vs cec_place carries cluster); band-edge math duplicated across planes. DOMAIN: the evict lever clears body-in-band but is ORTHOGONAL to corridor_cross (the cc 14→6 driver) → reconfirms the LAYER lever is the real fix.
- [ ] [added 2026-06-14 08:10] **ROADMAP (owner, 2026-06-14): (1) land the panel/audit → (2) add the LAYER-TIER lever → (3) overnight full-loop run.** Layer lever = the route-time fix the cc=6 floor finding points at: route each corridor-crossing foreign signal so it does NOT neck the F.Cu+B.Cu pour pair (the 4-layer stackup carries current on BOTH outers, inners are GND/12V planes — so it's "stagger the cut across F/B so the mirror always carries + stitch", NOT "move to a free signal layer"). The `high-current-corridor-keepout` checker already identifies the crossing nets; the lever plugs into cec_fr (DSN per-net layer / pour-after-route) as a routing-tier lever. Design firms up once the panel lands. Gated on the panel.
- [x] [added 2026-06-14 08:50 · done 2026-06-14 09:10] **LAYER-LEVER REWORK** (audit w23i0d8nq: 3 HIGH — safe-but-USELESS as built; owner: HOLD the run, rework first). ALL 5 ITEMS LANDED (03c4d0b, 1ad2b42, eab3752, 837a7f4): (4/5) `_route_quality` safe-revert metric (DRC + unrouted ratlines + hard-gate penalty; +inf on failure, not the old `except:return 0` mask) + temp-staged in-place safety (fixes the copy2(path,path) crash). (2) L-bend detection: `_seg_band_clip` (Liang-Barsky) + net-extent crossing test + `_relayer_segment_inband` → multi-segment/45° crossings caught (was 0). (3) `_adopt_staggered_board` re-points rec["routed"]+refreshes metrics (never downgrades a passing board) + the pour RE-FILL that heals the corridor. (1) `_route` lays the B.Cu MIRROR + via stitching (synthesize_power_copper strip_redundant=False, additive, both lanes, _route_quality safe-revert) → the "un-cut mirror carries" premise is now TRUE. +14 tests; checklist wired.
- [x] [added 2026-06-14 09:10 · done 2026-06-14 10:25] **Re-audit the layer-lever rework + launch the clean run** (owner: run audit, implement findings, launch + babysit). DONE. 4 parallel skeptics found 1 BLOCKER (gate-launder) + 3 HIGH → fixed (fb182b5: full re-measurement closes the launder, stale-Pareto refresh, connectivity-repair via, revert-on-disconnect). Focused re-audit confirmed the BLOCKER CLOSED → 1 MEDIUM + 2 LOW fixed (ec0d1d7: objective_base refresh, FEM-stale drop, mkstemp/sidecar leak, test-isolation). Night-watch date fixed (78ae674). **7h run LAUNCHED** ~05:14 UTC (PID 842244, deepseek-v4-flash auditor); round 1 ran clean: route → 4 F.Cu + **4 B.Cu MIRROR** pours + 140 vias (item-1 confirmed LIVE) → T4 panel → T6 pour → layer-stagger (full re-measure live, safe-reverted, no launder) → T5 auditor. Panel LIVE on **:8095**. Watchdog up (PID 846815, 8h). Host suite green both test orders.
- [ ] [added 2026-06-14 10:25 · in progress] **Babysit the 7h run** — round 1 healthy in the slow deepseek-auditor stage; watchdog (846815) self-heals run/panel over 8h + health-logs every 5 min to docs/fullstack-run-2026-06-14/watchdog.log. Monitor measurement.jsonl growth + :8095. Owner signed out for the night; status in chat + handoff.
- [~] [added 2026-06-14 08:30 · obsolete 2026-06-14 08:50 → rework line above] LAYER-TIER LEVER (owner: do it): route each band-crossing foreign signal staggered across F.Cu vs B.Cu so the un-cut outer 12V pour mirror always carries (cable-board-scoped; layer-keepout sibling of the FR-02 corridor-avoid in cec_fr). EI-INSTRUMENTED from the start (lane-gated via lane_for + a corpus_state/lane-tagged measurement row + OWNED_LEVERS entry) so it doesn't repeat the corridor-evict's EI gap AND it satisfies the overnight-run prereq. Then AUDIT it (panel).
- [ ] [added 2026-06-14 08:30] **Overnight full-loop run @ 8h** (after the layer lever + its audit): the EI-02 laned loop (cec_fullstack / cec_overnight) with all levers wired (layer-assignment + corridor-evict + kelvin/separate/adjacent), lane+corpus_state tagged so it's A/B-measurable. Launch detached, BABYSIT the first stretch (verify rounds tick, measurement rows write, no crash/thrash), fix issues that assert themselves.
- [ ] [added 2026-06-14 19:05 · in progress] **Make PLACEMENT a first-class EI-instrumented actuating tier** (owner: panel-review what placement implements vs how routing applies the EI points → checklist → implement all → test). Closes the FOLLOWUPS:127 G2/G3 gap: placement corridor lever (cec_place.apply_corridor_evict / cec_router.corridor_evict_repair) fires unconditionally, NO lane/corpus_state/measurement-row, NOT model-proposable, cec_fs_actuator `replace` Delta inert. Wire it to apply the SAME EI points routing does (EI-01 corpus_state, EI-02 A/B lane gate, EI-07 real_anchor_ratio, DeltaLog symmetric-outcome + control-rollback, fence/bound, OWNED_LEVERS). Panel workflow launched.
- [x] [added 2026-06-14 19:23 · done 2026-06-14 19:35] **Claude-RC session survivability** (owner interrupt: tmux + recovery script + WSL config + wire the RC systemd auto-reup to tmux). DONE (artifacts in /home/nathan/CEC-Platform/ops/, stable main checkout): (1) `claude-rc-tmux.sh` — systemd ExecStart wrapper runs each `claude remote-control` bridge inside a DEDICATED tmux server (socket claude-rc, session crc-<proj>), foreground-waits so systemd Restart=always still reups; tmux survives console drops + is attachable (`tmux -L claude-rc attach -t crc-CEC-Platform`). (2) `claude-session.sh` — persistent tmux launcher for the INTERACTIVE `claude` (survives terminal drops; re-attach by re-running). (3) `rc-recover.sh` — clean-restart the zombied bridge via systemctl, with a self-guard against killing the current session. (4) Edited `~/.config/systemd/user/claude-rc@.service` ExecStart→wrapper + ExecStop=tmux kill-session + KillMode=mixed; daemon-reloaded (LIVE on next WSL restart, or `systemctl --user restart claude-rc@*`/rc-recover.sh to apply now). Canonical unit + README snapshotted to ops/. tmux wrapper mechanics self-tested (create/env-inject/supervise-exit all verified). WSL mirrored-networking DEFERRED → FOLLOWUPS (risk to the tuned compute-plane NAT: localhostForwarding + broker:8080 ↔ host-LLM:8007 ↔ containers) — owner decision pending.
- [x] [added 2026-06-14 19:40 · done 2026-06-14 20:05] **Implemented the placement EI-parity checklist PL-03…PL-10** (PL-01/02 done earlier). PL-03: cec_place.nearest_evict_delta (dedup, regression-pinned) + sorted _cluster + apply_corridor_evict gains fence param + restore record; cec_router.corridor_evict_repair→place_cluster (cluster+fence-aware, RS*/J* skip) + apply_edit place_cluster case. PL-04: cec_fullstack.apply_placement_move (in-container, resolves body+band via corridor_violations, 2nd fence wall via is_fenced, evicts on a COPY of the committed→placed-r{N}.kicad_pcb, restore record) + cec_place.restore_poses. PL-05: _placement_source_for (control NEVER sees override) + --board-pcb-override threaded through route_one_worker/_exec_route_one/CLI. PL-06: settle via the existing kind-opaque DeltaLog + two-phase placement_base promote(vindicated)/revert(refuted/control) + refuted_placement_keys anti-ratchet. PL-07: gate-launder INHERITED (the pour_integrity→gates_pass fold at cec_fullstack:1761 runs on the moved+routed board; a fragmented move can't vindicate) + test. PL-08: _placement_row_fields on the measurement row (lane+corpus_state ride it) + placement_moved_rate/vindicated/refuted in ab_aggregate/render_ab_table. PL-09: real_anchor_ratio placement_moved kwarg (applied move=+1 deterministic, model unchanged, default no-op). PL-10: +27 tests across test_fs_actuator/test_prompt_audit_fixes/test_corridor_model/test_ei02_control_lane + NEW test_placement_actuation_e2e.py (host dry-run + REAL container leg) + test_fs_actuator wired into checklist.sh. VERIFIED: checklist exit 0 ("host suites pass"); 27 tests green both orders; e2e 6/6 incl. real container apply_placement_move; SB-08 IDENTICAL to committed baseline (max_T 253.2 = pre-existing owner-gated AM-04 red, NOT a regression). Found+fixed a real bug (CONTAINER_ROOT undefined in cec_fullstack) via the container leg. NEXT: adversarial audit.
- [x] [added 2026-06-14 20:05 · done 2026-06-14 20:45] **Adversarial audit of the placement EI-parity impl + REMEDIATION** (wf wmuedf7s6: 28 agents, 4 skeptics → verify each → synth; verdict needs-work, 1 blocker + 4 high + 4 med + 2 low confirmed, 10 dismissed). ALL FIXED + missing-tooth tests added: **BLOCKER-01** gate-launder (settle_outcome credits a both-gates-fail objective_base win which is pour-BLIND → a fragmented-pour move could 'vindicate') → KIND-AWARE fix `cec_fullstack._placement_keep(verdict,pour_integrity_ok)` (keep iff vindicated AND pour_integrity_ok is not False) so a fragmenting move is never promoted; settle_outcome UNTOUCHED (routing progress-crediting preserved — the audit's blanket-fix would've regressed routing). **FENCE-01** manager place_cluster bypassed the fence → corridor_evict_repair now derives+skips the locked sense ICs (union of cables' sense_ics) + accepts a fence param + stamps it into the edit; apply_edit passes fence to apply_corridor_evict (+del b). **AUDIT-PL4-001** CONTROL_EVERY<=0 deadlock → no-baseline settle branch drops+reverts (releases the one-in-flight guard). **MED-02** silent override-missing fallback → host-side isfile pre-check reverts+drops the unsettled move. **CTRL-01** _placement_source_for now gets concrete committed. **SWIG-01** del b. **AUDIT-PL4-003** skipped-delta logged. **TEST-RIGOR-01/02/03 + DETERMINISM-01** tests added. VERIFIED: checklist exit 0; test_fs_actuator 26 / test_ei02 32 / test_prompt_audit 34 / test_corridor_model 62 / e2e 8/8 (real container legs) green. KEY JUDGMENT: fixed BLOCKER-01 kind-aware (placement-scoped) NOT via the audit's literal settle_outcome change, per the audit's OWN residual-risk note that a blanket gate-dominance would break routing.
- [x] [added 2026-06-14 20:45 · done 2026-06-14 20:55] **Focused re-audit — VERDICT: SHIP** (wf wzgvmfh1r, 4 agents). All 8 prior findings independently verified CLOSED with code citations + a full green test run (test_ei02 32 / test_corridor_model 62 / test_fs_actuator 26 / test_prompt_audit 34 / test_stagger_feedback 12 / e2e 8). ZERO new blocker/high defects. Confirmed: _placement_keep applies only to placement deltas (settle_outcome byte-identical → routing preserved); pour_integrity_ok is always a strict bool on both route paths so `is not False` can't be bypassed; AUDIT-PL4-001 drops only settlement bookkeeping (routing carry untouched); FENCE-01 refuses locked sense ICs while ESP still moves. **PLACEMENT EI-PARITY (PL-01…PL-10) IS COMPLETE + FULLY AUDITED.**
- [x] [added 2026-06-14 20:53 · done 2026-06-14 20:56] **Found: the body-in-band placement lever is INERT on eps** (corridor_violations(committed eps)==[]; routing never moves parts → []every round). eps's cc=6 stall = foreign SIGNAL nets crossing the corridor (routing/LAYER problem), orthogonal to body-in-band eviction. So a placement-enabled run on eps would show "proposed→no_corridor→inert→stalls" — reconfirms the layer lever is eps's fix, NOT placement.
- [x] [added 2026-06-14 21:00 · done 2026-06-14 21:12] **Design plan: upgrade the synth placer before the Hub run** (wf w31yt6d78, 9 agents → docs/placer-upgrade-2026-06-14/plan.json). Verified LIVE: the committed Hub is ALREADY ROUTED (length 2359 / 769 tracks / kelvin+diffpair PASS) so calibration ground-truth is FREE; the placer is ~1.8x wirelength (HPWL 3677 vs 2002) / ~5x congestion (rudy 15.5 vs 3.0) worse than the hand Hub, and the proxy already discriminates them (so "rank the reference high" is well-posed). TWO real blockers reproduced: (B1) materialize() FileNotFoundError — the Hub dir has no .net, cfg.net='' → build_board crashes; (B2) seed_anchors mis-groups connectors (RJ-45 'host' + USB + J_5VSB all collapse onto the 'right' edge; _role mis-keys J_5VSB). MINIMAL-VIABLE (≈2.25 days S/M, host-runnable, enough to LAUNCH a scored+similarity-validated Hub run): MV1 feed netlist→materialize (the unblocker, S); MV2 derive Stage-1 (edges/outline/mounts/antenna) FROM the reference → fixes the wrong frame (M); MV3 reproduce-the-reference similarity metric = the validation number (M); MV4 wire the computed rudy/thermal proxy into selection (currently THROWN AWAY — sort key is only (residual,corridor_cross,hpwl)) (S); MV5 the 4 Hub-domain terms (RJ-45 even-spacing/antenna-on-edge/power-cluster/USB-ESP) (L). SEQUENCE: MV1 unblocks→MV2 correctness→MV3 instruments→MV4 free leverage→MV5 measured quality. GUARDRAILS (over-engineering to AVOID): no routing campaign for calibration (Hub already routed); defer Tier-B least-squares regression; thermal-sep/symmetry/LED terms are not first-run gates; don't refactor the anneal hot loop; oracle-seeding only as ONE competing candidate (overfitting).
- [ ] [added 2026-06-14 21:12 · in progress] **BUILD the placer-upgrade set MV1→MV5** (owner: do the whole stackup) then launch the Hub full-stack run scored vs the reference. Plan: docs/placer-upgrade-2026-06-14/plan.json. **GOVERNING CONSTRAINT (owner): the reference must NOT teach board-specific rules — encode the underlying WHY, treat the reference like the holdout (validate, never tune toward) or it's corpus-poisoning overfit.** Codified → docs/placer-upgrade-2026-06-14/anti-overfit-charter.md (3 rules: rules encode WHY-not-WHERE; reference=validation-only never an optimization target; per-board REQUIREMENTS [outline/edge/mounts] ≠ generalizable RULES). DONE: **MV1** (S) — _ensure_netlist_path + materialize() now sch-exports a netlist when cfg.net='' → a Hub candidate MATERIALIZES (tested in-container: place_candidates@98x74 residual 7 → materialize wrote 80-part board → read_placement parity; the FileNotFoundError blocker is gone). REMAINING: MV2 (split: GENERAL _role connector-function fix [principled] + per-board edge/outline/mount INPUT derived-from-reference-as-requirement [tagged board-specific, not a rule]); MV3 similarity DIAGNOSTIC (never a rank key); MV4 proxy_score (reference normalizes scale only, no per-board weight regression); MV5 the 4 net-derived domain terms (variance/edge/cohesion/proximity, no hardcoded ref values).
- [ ] [added 2026-06-14 20:56] **PIVOT (owner): validate the full stack on the HUB (a real fab-ready board) from a base stackup, using the committed Hub as a READ-ONLY reference oracle** — instead of eps (never hand-finished). DOABILITY CONFIRMED: Hub netlist exports+parses (77 comps / 83 nets), Config.load('hubs/hub-standard') + View ingest it, _classify partitions cleanly (8 connectors [4×RJ-45 J2-J5 + J_5V/J_5VSB power-in + J_KVM + J_USB], 9 ICs, 0 shunts, 60 passives), run_pipeline/run_sweep accept a board path, Hub is 4-layer + has fab/hub-standard-proto-v1. NOTE shunts=0 → corridor formation inert (cleaner generic-placement test than eps). CAVEATS: synth placer is DOMAIN-BLIND (CLAUDE.md item -2: no model of RJ-45 spacing / ESP antenna keepout / power front-end / LED chain) → produces routable-but-not-hand-quality; Stage-1 asks must be supplied (--answers, derivable from the reference Hub); "base stackup" = the Hub's 4-layer GND-plane. PLAN: extract netlist+reference (read-only→build/) → derive Stage-1 answers from the ref → run synth place→route→check → score the gap vs the fab Hub (HPWL/area/DRC/gates). NEXT: scope + kick off a bounded first pass.
- [x] [added 2026-06-14 19:40 · done 2026-06-14 20:05 → split into the two lines above] **Implement the placement EI-parity checklist (PL-01…PL-10)**. DONE + TESTED: **PL-01** (cec_fs_actuator.py) — `replace` Delta now carries a LIVE placement intent (`_placement_intent`: ref-target→{ref,op evict,band None,cluster True}, net-target→ref None for on-board resolution); v4_structural_escape populated; Delta.as_record compact-summarizes a placement intent; fence still refuses pinned/Kelvin BEFORE intent build. +5 tests (tests/test_fs_actuator.py TestPlacementDeltaLive), 22/22 green. **PL-02** (cec_fullstack.py) — placement clause added to OWNED_LEVERS, worded WITHOUT 'corridor'/'pour'/'around' so a model echo classifies to 'replace' not 'avoid' (verified _lever_kind round-trip). +3 tests (tests/test_prompt_audit_fixes.py TestPlacementLeverAdvertised), 34/34 green. REMAINING: PL-03 (dedup nearest_evict_delta + cluster/fence-aware manager corridor_evict_repair=place_cluster + sorted _cluster; cec_place/cec_router/test_corridor_model), PL-04 (apply_placement_move consumer, in-container, 2nd fence wall, edits committed COPY→placed-r{N}, restore record), PL-05 (lane-gate + thread --board-pcb-override into route_one_worker/_exec_route_one), PL-06 (settle via existing DeltaLog + two-phase override promote/rollback + _refuted_placement_keys), PL-07 (gate-launder guard: pour-integrity into gates_pass on moved+routed board), PL-08 (lane+corpus_state placement fields on measurement row + A/B table), PL-09 (applied-move=deterministic anchor EI-07, default no-op), PL-10 (update existing tests + e2e dry-run + host suite both orders + SB-08 in-container). Full checklist: docs/placement-ei-parity-checklist.json.
- [x] [added 2026-06-14 19:18 · done 2026-06-14 19:25] **Panel review DONE** (wf wxo5qk6l0; 9 agents: 4 recon → 4-lens panel → synthesis). Produced a 10-item dependency-ordered checklist (PL-01…PL-10) + 8 invariants + 38-test matrix + 4 open questions. Saved → docs/placement-ei-parity-checklist.json. CHECKLIST: PL-01 live `replace` intent (kill intent=None in finding_to_delta + v4_escape); PL-02 OWNED_LEVERS placement clause (worded w/o 'corridor' to dodge _lever_kind misclassification); PL-03 dedup nearest_evict_delta + cluster+fence-aware manager corridor_evict_repair (place_cluster) + sorted _cluster; PL-04 apply_placement_move consumer (in-container, resolves body+band, 2nd fence wall, edits committed COPY→placed-r{N}.kicad_pcb, restore record); PL-05 lane-gate + thread --board-pcb-override into route_one_worker/_exec_route_one (control routes committed); PL-06 settle via existing kind-opaque DeltaLog + two-phase override promotion (vindicated-only) + rollback + _refuted_placement_keys; PL-07 gate-launder guard (fold pour-integrity into gates_pass on moved+routed board); PL-08 lane+corpus_state placement fields on measurement row + A/B table; PL-09 applied-move = deterministic anchor (EI-07, default no-op); PL-10 update existing tests + e2e dry-run + host suite both orders + SB-08 untouched. OQ DECISIONS (panel-recommended, owner-vetoable): OQ1 fullstack-loop-scoped; OQ2 applied-move=deterministic anchor; OQ3 word OWNED_LEVERS w/o 'corridor'; OQ4 vindicated override persists/compounds, reverts on refute/overturn/control.
- [x] [added 2026-06-14 19:10 · done 2026-06-14 19:10] **Recon/grounding (pre-panel)** — mapped the exact placement-vs-routing EI gap in the live code. FINDINGS: (1) DEAD-END is `cec_fullstack.py:1932-1941` — at the actuator BOUND step ONLY `kind=="avoid"` deltas with `intent` feed the live carry `pending_corridor_avoid`; a `replace` (move/rotate) delta from `act.finding_to_delta` (:1915) is `kept` but its `intent` is None (`cec_fs_actuator.py:108-109`) and NOTHING consumes it → inert. (2) DOWNSTREAM IS ALREADY KIND-AGNOSTIC + reusable: control-gate settle `dlog.record_outcome` (:1862-1900) rolls back any non-vindicated delta; measurement row (:2001-2028) already carries lane/corpus_state(EI-01)/real_anchor_ratio(EI-07)/n_deltas_applied; `pending_corridor_avoid` (augmented-only :1622, suppressed-on-control :1627) is the EXACT carry pattern to mirror. (3) MECHANISM: each round routes from the committed board `ovd.BOARD_PCB[board]` via `route_directed(board_pcb,intents,...)`; placement = apply `cec_place.apply_corridor_evict(board,ref,band)` (already moves part+cluster, excludes structural RS*/J*, containment guard e01ddd7) to a COPY on the augmented lane, route that copy; control routes unmutated = rollback baseline. `apply_directive` dispatches an `evict` directive. (4) TO-WIRE: make `finding_to_delta` replace branch resolve a real intent {ref,band,op} (not None); add a `pending_placement` carry mirroring pending_corridor_avoid; add placement to `OWNED_LEVERS` (:83) so the model proposes it; fence must refuse moving a pinned/Kelvin/shunt ref.
- [~] [added 2026-06-14 07:25 · obsolete 2026-06-14 07:45 → done above] Phase 1+2 audit remediation (superseded by the done line above) Audit CONFIRMS cc=6 is the real hand-board floor (analytic: shared I2C bus → 4 forced + DETC1 + THRESH), but the placer is now WORSE (legal cc 8-24, not "hand-quality") — overhang(192503d) fixed residual but not peripheral placement. Fixes: (1) doc CORE-PREMISE retract "cc=6 never lower / hand-quality corridors" → honest legal cc + the analytic floor; soften "topological invariant"/"no channel"/"is exactly how committed routes". (2) build_corridor_model/corridor_cross_count MISSING the shared-bus exclusion (spurious 12vhpwr rank key) → factor out + apply. (3) overhang value "edge"→"power_able" (canonical). (4) _seed_corridor_spine clamp pads to [0,W]. (5) tests: fix 24pin filename (silent skip), assert residual==0 + band-width in test_phase2, add _corridor_veto unit test. (6) FOLLOWUPS: residual-misattribution now moot (residual 0). Defer (FOLLOWUPS): seg-AABB, _P/_N classifier parity, degeneracy pre/post-inflation.

## Done / obsolete (history)

- [x] [added 2026-06-13 19:45 · done 2026-06-13 20:25] Prompt-tier audit (Claude panel + DeepSeek cross-check): catalog + 30 confirmed/3 rejected + punchlist
- [x] [added 2026-06-13 20:30 · done 2026-06-13 23:00] Implement prompt-audit fixes (P1-P12 incl. H1/M2/H2/M1/M3/M4/M5 + P5/P6) → PR #56 (20/20 host tests)
- [x] [added 2026-06-13 21:55 · done 2026-06-13 22:10] Bot-push guard hook + gh-bot wrapper (push/gh as the bot, not the owner) → PR #57
- [x] [added 2026-06-13 22:48 · done 2026-06-13 22:48] FOLLOWUPS SessionStart hook + FOLLOWUPS.md → PR #58
- [x] [added 2026-06-13 23:25 · done 2026-06-13 23:28] TODO SessionStart hook + TODO.md → PR #58
- [x] [added 2026-06-13 22:40 · done 2026-06-13 22:48] Render eps-8pin before/after board PNGs
- [ ] [added 2026-06-15 01:35] **Integrate the agentic model stack into the placer/Hub route pipeline** (owner: panel the proper integration + toggle cloud/local, default overnight→local & short-midday→cloud; forensics on why it wasn't wired despite the docs → doc). Workflow: forensics (why bypassed) → design panel (tier wiring / toggle+defaults / corpus gating / placer-router feedback + dashboard) → implement → forensics doc.
- [x] [added 2026-06-15 01:55 · done 2026-06-15 02:25] **Forensics + design-panel continuation** (wf_cf91431f-a2a, 7 agents). Recovered 3 cached findings from the killed run + regenerated the seam inventory → forensics synth (smoke-first ossification root cause; 3-kinds-of-not-wired distinction) + 4-lens design panel → design synth (Path A wiring / cloud-local toggle / corpus gating / dashboard, 11-step checklist). Synopsis+forensics+design → **docs/agentic-integration-forensics-2026-06-14.md**.
- [x] [added 2026-06-15 02:25 · done 2026-06-15 03:05] **Implement the agentic integration (owner: "implement them + fix the stack to use the proper wiring")**. Owner default RESOLVED: explicit `--seats/--judge` wins; else `--hours>=2 → local`; else cloud (defaulting to cloud); cloud effort=MAX in all cases (Opus 4.8 max). DONE (checklist steps 1-10 + dashboard + audit): cec_seats.py resolver; model=/url=/effort= threaded through make_manager_swarm/make_worker_swarm→_panel→_chat_json→_chat_json_cloud (--effort max); hub_pipeline_run.py `--seats` + tier wiring into cec_router.route (cloud panel=1/local panel=3, fail-safe→deterministic) + post-route conformance SELECTION gate + REF intake + cec_policy.assert_loadable + corpus_fit_review sidecar + ledger; hub_run.sh forwards toggle/effort + broker --add-host; cec_dashboard.py agentic-decisions card (/api/agentic). **Adversarial audit wf_28d3ca68-a24 (5 skeptics→verify→synth): ship-with-fixes** — 2 cloud-effort defects + doc-accuracy FIXED (commit 31daa59). Commits 8ef8e07→5f1d7e5→f738df1→31daa59 (PR #60). 240 host tests green. Doc: docs/agentic-integration-forensics-2026-06-14.md. DEFERRED→FOLLOWUPS (step 11): Path-B generalization (find_board hubs/ + register Hub in BOARD_PCB + placer↔router feedback) + cloud-seats-in-container claude CLI + conformance abort-level promotion.
- [x] [added 2026-06-15 03:05 · restarted clean 03:57 · done 2026-06-15 09:10 (read 15:15)] **Overnight ~10h full-pipeline run (owner ask)** — COMPLETED full 10h/46 rounds, 0 crashes; **negative result**: 0 gate-passing, A/B augmented≈control, placement levers inert (all deltas noop), real blocker = pour-clip 40/46 rounds. Shadow auditor declined-with-restraint (good). T7 capstone hit FileNotFoundError (fail-safe→no_opinion). Writeup → docs/fullstack-run-2026-06-15/RESULT.md; 3 deferrals → FOLLOWUPS.md. — `CEC_FS_DATE=2026-06-15 cec_fullstack --board eps-8pin --hours 10` (**PID 1233137**, run dir docs/fullstack-run-2026-06-15). RESTART REASON: the box local date is 2026-06-14 (CDT) but I'd named the dir 2026-06-15 (UTC) → cec_fullstack's PERM (strftime %Y-%m-%d) wrote measurement/findings/bundle into docs/fullstack-run-2026-06-14 (co-mingling with yesterday's run + blind dashboard + empty babysit). Fixed by relaunching with CEC_FS_DATE=2026-06-15 so ALL artifacts co-locate. Owner CONFIRMED the auditor proposed_lever being advisory/noop is BY DESIGN (shadow ruling for EI-02 self-influence proof) — NOT changed. Watchdog relaunched (PID-rotated, CEC_FS_DATE=2026-06-15 + CLAUDE_PROJECT_DIR=worktree). Note: yesterday's docs/fullstack-run-2026-06-14 archive is slightly polluted (aborted run appended ~3 measurement rows + overwrote round-001..003 findings) — left as-is (past archive). FULL T0-T9 + EI-02 A/B control lane (control_every=4) + corpus gating (brief 35/6) + fence (nets=4 refs=5) + **placement actuators VERIFIED wired** (_t0_should_fire→gr02_repair line 1975/1981; finding_to_delta→select_deltas→apply_placement_move 2094/2112/2129; control-gated record_outcome + _placement_keep gate-launder guard + fence + rollback). Auditor=deepseek-v4-flash (warmed). Watchdog PID 1199904 (worktree-pinned, crash-relaunch only). Panel http://localhost:8095. CAVEAT: on eps the body-in-band placement lever is largely inert (eps's stall is foreign-signal-in-corridor = routing/layer, not placement) — actuators are PRESENT+ready, may not fire much; eps's active fix is the layer lever. BABYSIT: monitor run.log + measurement.jsonl + :8095; converges or 10h deadline.
- [ ] [added 2026-06-15 15:25] **Full actuation lever — complete the flag→clean-evidence-gate→tally→steer-not-gate loop** (owner ask). Plan of record: docs/actuation-lever-design.md (4-state rule lifecycle + the transitive-influence-lineage trap + 4 staged steps). Hard gates stay deterministic+human (CLAUDE.md ratification boundary); ratified rules STEER only, never gate.
  - [x] [added 2026-06-15 15:25 · done 2026-06-15 15:40] **Step 1 — per-rule transitive influence lineage** (commit d6ddfba): rule_id() + influence_signature() + per-run influence cone (transitive over placement_base lineage, carried only when kept) + `influenced_by` on the measurement row + clean_pairs() comparator (firewall: a row with R in its cone is never a baseline for R) + host tests. Additive/non-behavioural.
  - [x] [added 2026-06-15 15:25 · done 2026-06-15 16:05] **Step 2 — cross-run persistence + tally**: rule_tally() pools clean evidence over independent runs (firewall-safe across runs); actuation_lever_report + load_runs_from_dirs (board-filtered); _emit_lever_ledger durable obs; --tally CLI. (Caught + fixed a real glob bug in load_runs_from_dirs that silently disabled cross-run pooling.)
  - [x] [added 2026-06-15 15:25 · done 2026-06-15 16:05] **Step 3 — graduation bar**: graduation_verdict (min_runs/min_pairs/improving-frac sign-test/per-metric effect floor + direction); holdout fixture tests/holdout/actuation/bar-fixtures.json (4 boundary cases) validates the DEFAULT bar (bar code never reads holdout). Promotion stays owner-gated (advisory only).
  - [x] [added 2026-06-15 15:25 · done 2026-06-15 16:05] **Step 4 — steer-only chokepoint**: assert_steer_only() + SteerViolation + STEER_FIELDS/GATE_FIELDS (generalizes _placement_keep); a ratified rule may only bias the search, never write a gate field / ship.
  - [~] [added 2026-06-15 15:25 · obsolete 2026-06-15 15:50 → split into the two lines below] **Validation**: Hub or synthetic.
  - [x] [added 2026-06-15 15:50 · done 2026-06-15 15:50] **Hub generalization (Path-B infra)**: BOARD_PCB[hub-standard] + find_board resolves hubs/ + INTENTS[hub-standard]=[] + FRESH_ROUTE_BOARDS (_placement_only_copy strips committed copper so the Hub routes fresh from placement). Import-verified; host suite green.
  - [x] [added 2026-06-15 15:50 · done 2026-06-16] **Lever ENGAGES live + placement resolves a body**: hubsmoke2 (--rounds 5) confirmed the `.lever`→`.type|.action` fix (ff299ff) — round-5 `effort` lever actuated for the first time (status=applied). REMAINING gap closed 2026-06-16: a placement finding that named the body only in prose (r2 "Shift component C1") now resolves via `_prose_ref` (refdes-from-prose, validated against the manifest refs) + a finder-prompt nudge. Real r2 finding: `replace ref=None`→noop became `replace ref=C1 status=applied`. tests/test_actuation_lever.py TestProseRefFallback (7); host suite 597 green (9 pre-existing fr02/vision discover-order failures, baseline-identical).
  - [x] [added 2026-06-16 · done 2026-06-16] **Adversarial review of the prose-ref fix + harden + close r3** (wf_6653dbfc, 6 lenses/25 agents, 16 confirmed): r3 lever-misclassification CLOSED (_lever_kind failure_class override — real r2 AND r3 now resolve replace→C1); prose-ref hardened (underscore/long-prefix refs via known-ref alternation, case-insensitive, verb-proximity); known_refs hoisted. commit f8ddbd9; +11 tests (suite 63 green).
  - [~] [added 2026-06-16 · obsolete 2026-06-16 → FOLLOWUPS "KEY BLOCKER ... CORRIDOR-GATED" + owner-queue] **Longer Hub validation run** — WRONG TARGET. The review + a host-pcbnew trace proved the placement actuator is corridor-gated: `corridor_violations()` == [] for BOTH committed Hub (shared-bus) and committed eps (clean placement), so NO body can move on either regardless of ref resolution. The prose-ref fix is necessary but not sufficient. The actuator chain is already proven on an injected-violation EPS fixture (test_placement_actuation_e2e). Superseded by the owner decision below.
  - [x] [added 2026-06-16 · done 2026-06-16] **Option (1) — validate the chain on EPS (owner: "Validate the chain on EPS first")**: DONE, lever FIRES live. Injected U10/INA238 into the /SENSEC2 corridor; a live `cec_fullstack` loop (Sonnet finder) showed the chain end-to-end. KEY finding+fix (commit 7b10fed): `corridor_violations()` was only called INSIDE apply_placement_move, NEVER surfaced to the finder → it diagnosed routing + targeted the fenced sense net (refused). Added `corridor_body_facts` → pourcheck → `_audit_prompt` BODY-IN-CORRIDOR directive. **Baseline placement_moved_rate 0.0 (0/5) → with fix 0.667 (2/3, verdict=placed, U10 +9mm).** Evidence: docs/fullstack-run-2026-06-16-epsinject{,2}/RESULT.md. Det full-chain proof also in test_placement_actuation_e2e + the eps_chain_validate script.
  - [ ] [added 2026-06-16] **OWNER DECISION still open — option (2) generalize the lever** to a non-corridor "make-room" eviction (congestion band from GR-01/failed-waypoint geometry) so Hub-class "no routing room" failures move a body. Larger; the corridor-evict safety model doesn't transfer. docs/owner-queue.md §1 + FOLLOWUPS 2026-06-16. Option (1) is validated; (2) is the only remaining path to placement movement on a shared-bus (no-corridor) board like the Hub.
- [ ] [added 2026-06-16 17:55] **FULLY CLOSE THE LOOP — self-converging place→route→converge (owner: "build it all out")**. Mechanism, not corpus (memory: convergence-blocker-mechanism-not-corpus). Phases:
  - [x] [done 2026-06-16] P0: implementation-level recon → sequenced plan (workflow wf_ad6be7d1). Confirmed clip-at-shunt=notch, layer-stagger already exists, build order.
  - [x] [done 2026-06-16 · commit 91b7d68] P1 (keystone, ROUTE half): cec_fr.corridor_keepouts shared helper + cec_router delegation + route_directed wiring. **+ found & fixed a REAL bug the recon missed: the keepout's DoNotAllowZoneFills blocked ~89% of the same-net pour → block_fills flag (corridor keepouts set False).** 6 tests, golden track-metrics byte-identical, 0 new host failures.
  - [x] [done 2026-06-16 · KEY FINDING] P1-validate: live route_directed on committed eps. The keystone WORKS (foreign crossings 31→6, pours solid 122.8mm²) BUT **is COUPLED with placement** — committed eps isn't corridor-clean (corridor_cross≥3: /DETC,/THRESH,/I2C forced through), so the keepout strands them + the sense taps (kelvin True→False, unconn 2→16). The existence proof was via cec_golden (no keepout). → keepout DEFAULTS OFF; the loop closes with keystone+P5 TOGETHER on a fresh clean placement. NOT "closes the existing-board loop" as first assumed.
  - [ ] **P5 (now the critical coupled half): corridor-packing placer** — seed_anchors seats each cable's connector→shunt→sense-IC as a CLEAN COLUMN (no foreign airwire forced through the corridor) so a FRESH eps placement is corridor-clean. Then enable the keepout (P1) + corridor_max on it. THIS is what makes the keystone converge.
  - [ ] P5-validate: fresh eps place(corridor-clean)→route(keepout on)→converge: kelvin_ok stays True AND foreign crossings ~0 AND pours solid → gates pass. The actual close-the-loop proof.
  - [ ] P2: defrag/re-pour-after-route — heal a pour fragmented by a RESIDUAL crossing (a foreign pad inside the corridor vias through; keepout is allow_vias=True). After P5.
  - [ ] P3: (DEFERRED — recon: layer-stagger already exists, wired-but-inert; keystone reduces its workload; no new stagger work in scope unless P5 leaves residual crossings.)
  - [ ] P4: (SUBSUMED by P1 — the deterministic route-time keepout replaces the next-round-reactive avoid; residual = dedupe corr_* vs avoid_* keepouts, low-priority.)
  - [ ] P6: adversarial review of the whole loop + a fresh-board end-to-end convergence demo.
- [ ] [added 2026-06-16] **BUILD the LLM-guided placement loop (owner: "let's do it")** — the actuation-lever pattern pointed at PROACTIVE placement planning (deterministic placer PROVEN insufficient: fresh route kelvin=False + 62 clips; FOLLOWUPS 2026-06-16). New scripts/cec_place_planner.py: place_candidates(seed) → placement_context(parts/roles/positions/corridors/failures) → LLM planner seat proposes MOVES → apply+legalize → route+score (measure) → iterate. Reuse cec_judge_local (seat), cec_place (move/legalize), build_corridor_model, place_candidates/materialize, cec_fr.route_once+cec_score. Goal: drive a fresh eps placement to converge (kelvin pass, clips→low, gates pass).
  - [x] [done 2026-06-17] AUDITOR tier built + run (18 rounds, run9.log): nothink worker descended clips 91→48 (past the old ~70); the auditor (cec-worker-quality) DIAGNOSES the partition correctly every round but its absolute-coord re-layouts all REGRESS → ceiling = the move REPRESENTATION, not intelligence/speed.
  - [x] [done 2026-06-17] Partition MATERIALIZER `--pack` (`w_pack`/`_shelf_moves`) + `--keepout` measure flag. Deterministic all-right pack = clips=76/drc=6/kelvin (vs LLM 48/drc=28 not-fab-ready). Found the structural truth: +3V3/+5VSB feed BOTH corridors → the partition is a center-gap spine, not "all one side".
  - [ ] [added 2026-06-17] **NEXT: region-AWARE partition** — LLM assigns each foreign IC a region {cable-1-side, center-spine, cable-2-side, right}; per-region pack via `_shelf_moves`. Then rebalance `run()` score for finishing-DRC. Then a long run (~50s/round). The clean execution path (`_shelf_moves`) is done; needs the region-map plan seat.
- [ ] [added 2026-06-17 08:04] **BABYSIT the 8h region-partition run** (owner ask) — eps-8pin, build/place-planner-overnight, log docs/place-planner-2026-06-16/overnight-run.log, deadline ~16:03Z. PID 2380367. Region-aware partition tiers (commit 1b950ff) + fab-gated score (kelvin→drc≤16→clips→drc). Watch the trajectory; when it plateaus, diagnose the structural reason (owner: "find the reason behind it").
- [ ] [added 2026-06-17 08:09] **8h run RELAUNCHED with smooth clips+drc score** (the DRC ceiling rejected r1's clips=47 win) — eps-8pin, build/place-planner-overnight2, log docs/place-planner-2026-06-16/overnight-run2.log, PID 2384349, deadline ~16:08Z. Score now minimize(clips+drc) tiebreak clips (commit e27a45d). Babysitting; diagnose the plateau when it stalls.

- [x] [added 2026-06-18 22:35] Board-grow lever (last loop lever): scale board up ~5mm at deep plateau, re-converge; testing whether more channel room beats clips=40 (build/place-planner-grow, from r7) · done 2026-06-18 23:07 (verdict: does NOT beat clips=40; floor is topological)

- [x] [added 2026-06-19 00:02] Route spanning signals UNDER pours on B.Cu — building opt1 (post-route F.Cu->B.Cu layer-swap) + opt3 (KiCadRoutingTools pour-first), verifying COMPLETENESS, comparing (workflow wf_f3215343) · done 2026-06-19 00:24 (OPT1 layer-swap WON: 40->32 complete+clean; OPT3 KRT incomplete; ceiling-breaker = +3V3 inner plane)
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

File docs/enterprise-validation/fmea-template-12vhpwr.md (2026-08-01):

# FMEA — 12VHPWR Standard module (`fmea-template-12vhpwr`)

Instantiated from `fmea-template-common.md`. Family: 12VHPWR Standard, 6x
per-pin interposer (beta/12vhpwr-standard, routed/fab-direction per CLAUDE.md
action item 4). Sensing: 6x INA240 per-pin current-sense + 47k/10k rail-voltage
divider. Qualitative FMEA only — FMEDA deferred per the common template's depth
ruling; this family is the furthest along toward FMEDA-readiness since its
shunt part is already sourced and its production thermal pass is done (below).

## In-path elements (pre-seeded)

| Ref | Element | Pin | Value/MPN | Package |
|---|---|---|---|---|
| RS1–RS6 | Per-pin shunt | 1–6 | Bourns CSS2H-2512R-1L00F, 1 mΩ — LCSC C4175647, already sourced (OQ-11 sheet confirms this is the only real 1.00 mΩ part; spec's `-K-1L00F` citation is a documentation erratum, not this BOM) | 2512, 2-terminal, hand-routed Kelvin taps |
| J3 | PSU-side input connector | all 6 | Molex 219116 / 2191161161, 12V-2x6 board-mount male header | THT, right-angle, board-mounted (no detachable bridging cable, §2.8 LOCKED) |
| J4 | Load-side output pigtail | all 6 | Molex 12V-2x6, captive soldered pigtail to GPU | Soldered cable, no mated connector pair on this end |
| PCB copper | Per-pin fan-out lanes + F/B transition vias | 1–6 | — | Production rev residual per CLAUDE.md item 4: single-layer-per-segment (HI F.Cu / LO B.Cu), F→B transition vias 0.6/0.3mm (below the Power12V netclass 0.9/0.5mm spec) — proto-clean, production-rev margin item |
| TH1/TH2 | Board/ambient NTC (not in-path, but the family's only temperature datum per CLAUDE.md — noted for detection-surface completeness) | — | Murata NCP15XH103F03RC, LCSC C77131 | 0402 |

## Failure-mode rows

| Failure mode | Effect on monitored power path | Detection surface | In-path element | Severity | Fault-injection evidence ref |
|---|---|---|---|---|---|
| Shunt open (any of RS1–RS6) | That pin's lane interrupted — direct pass-through failure on that pin only (per-pin isolation; other 5 pins unaffected) | ALERT/threshold (INA240 sudden zero-current on that channel) | RS1–RS6 | S3 | TBD — not yet run |
| Shunt short/solder-bridge | None on pass-through current; destroys sensing on that pin only | INA240 differential reads near-zero permanently; sensor-fault classification | RS1–RS6 | S1 | TBD — not yet run |
| Kelvin tap trace open | None on pass-through (off main current path by construction) | INA240 reads open/rail-clamped input | RS1–RS6 Kelvin taps | S1 | TBD — not yet run |
| F→B transition via fatigue/crack under sustained current (0.6/0.3mm vias, below netclass spec per production-rev note) | Localized resistance rise; a sustained 12A single-pin-hog condition already measured (2026-06-09 FEM probe) to run the hog lane's transition to ~J 85 A/mm² — ~15% under the sustained ceiling, i.e. thin margin, not yet a fault | Electrical (INA240 imbalance-across-pins signature — the "58% instant electrical outlier vs. lagging ~2.2°C shunt thermal asymmetry" detection thesis already confirmed by the FEM probe) + thermal (TH1 near-shunt) | PCB copper (F→B vias) | S2 (approaches S3 margin under sustained imbalance — flagged, not yet a violation) | 2026-06-09 FEM probe (analytic, not physical injection — physical bench still `TBD`) |
| J3 connector pin fret (12V-2x6 board-mount header) | Localized derate on the affected pin(s); a sustained pin-current imbalance (the "12A hog" scenario) is the family's own documented worst case | Rail-voltage sag / INA240 imbalance signature | J3 | S2 | `bench-misplug-injection.md` (connector-stress leg, once run) — distinct from the FEM-probe imbalance finding above, which is a design-margin analysis, not a fault-injection result |
| J4 pigtail solder-joint fatigue (no mated pair on this end, captive cable) | Localized derate or open on one pin's lane at the load end | Rail-voltage sag / INA240 zero-current on that channel, same signature as a shunt open | J4 | S2/S3 depending on extent | TBD — not yet run |
| RJ-45 link severed / mis-plug | None on the pass-through 12V-2x6 path (module-to-Hub link is electrically separate) | DETECT-code mismatch, CAN bus-state | RJ-45 jack (FTP, cec:RJ45_FTP_Shielded_Horizontal), pin-8 ESD diode | S1 (by design) | `bench-misplug-injection.md` |

## Fail-passive rows

See `fmea-template-common.md` §"Fail-passive rows" — all five triggers apply
verbatim per pin (6 independent instances); none currently have dedicated
fault-injection evidence (all `TBD`).

## Production thermal margin (REQ-MOD-COMMON-032 — already partially answered)

Per CLAUDE.md action item 4: re-validated 2026-06-24 with the 2.5D min-cut
solver + production case-cooling (metal case, TIM on RS1–RS6 + M3 mounts) =
maxT 72.95 °C / dT 22.95 °C = PASS at balanced 600 W/50 A. Still-air no-case
bound (conservative number, per the 12VHPWR precedent this REQ names) = maxT
151 °C / dT 101 °C. This is the family furthest along toward closing
REQ-MOD-COMMON-032; the residual items are the production-rev margin note above
(single-layer lanes, undersized transition vias), not open unknowns.

## Open findings

- F→B transition via undersizing is a real, named production-rev item (not
  hypothetical) — carries the highest-confidence S2-approaching-S3 severity of
  any row across all four families precisely because it already has FEM
  evidence, unlike the other families' `TBD` rows.
- Spec-text erratum (`CSS2H-2512K-1L00F` should read `-R-1L00F` at spec lines
  ~511/625/836/1351) does not affect this BOM (already correct) but should be
  folded into the pending v1.2.0 spec edit per the OQ-11 sheet's checklist.

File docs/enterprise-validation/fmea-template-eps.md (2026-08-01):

# FMEA — EPS 8-pin module (`fmea-template-eps`)

Instantiated from `fmea-template-common.md`. Family: EPS 8-pin per-cable
interposer (beta/eps-8pin, rev2 current), 2 cables populated. Sensing:
INA238 per cable + the ENT §6.13-class transient-detection front-end.
Qualitative FMEA only — FMEDA deferred per the common template's depth ruling.

## In-path elements (pre-seeded)

| Ref | Element | Cable | Value/MPN | Package |
|---|---|---|---|---|
| RS1 | Shunt, cable 1 | 1 | Bourns CSS2H-2512R-L500F, 0.5 mΩ (OQ-11 sheet selection) | 2512, 2-terminal, hand-routed Kelvin taps |
| RS2 | Shunt, cable 2 | 2 | Bourns CSS2H-2512R-L500F, 0.5 mΩ (OQ-11 sheet selection) | 2512, 2-terminal, hand-routed Kelvin taps |
| J_IN1 / J_OUT1 | PSU-side in / load-side out, cable 1 | 1 | Molex Mini-Fit Jr 87427-0802, 2x4 | THT header, pegless RA |
| J_IN2 / J_OUT2 | PSU-side in / load-side out, cable 2 | 2 | Molex Mini-Fit Jr 87427-0802, 2x4 | THT header, pegless RA |
| PCB copper | Bundled-shunt vertical transition, per cable | both | — | OQ-10 (copper coin vs. filled-via field vs. plated slot) unresolved for this family |

## Failure-mode rows

| Failure mode | Effect on monitored power path | Detection surface | In-path element | Severity | Fault-injection evidence ref |
|---|---|---|---|---|---|
| Shunt open (RS1 or RS2) | Cable interrupted downstream — direct pass-through failure on that cable only (other cable unaffected, confirming per-cable isolation) | ALERT/threshold (INA238 sudden zero-current) | RS1, RS2 | S3 | TBD — not yet run |
| Shunt short/solder-bridge | None on pass-through current; destroys Kelvin sensing on that cable | INA238 differential reads near-zero permanently; sensor-fault classification | RS1, RS2 | S1 | TBD — not yet run |
| Kelvin tap trace open (hand-routed, §6.8) | None on pass-through (Kelvin taps are off the main current path by construction) | INA238 reads open/rail-clamped input — distinguishable from a true shunt fault if firmware checks tap continuity separately | RS1/RS2 Kelvin taps | S1 | TBD — not yet run |
| Bundled-shunt vertical transition failure (via-field/coin fatigue under 40–55A sustained per §6.4) | Localized resistance rise or open at the vertical, potentially cable-interrupting at the extreme | Rail-voltage sag, ALERT threshold, or thermal imaging during bench (no on-board NTC for this family currently) | PCB copper (OQ-10 pending) | S2/S3 depending on extent | TBD — needs OQ-10 resolution + dedicated thermal/current-cycling bench |
| J_IN/J_OUT connector pin fret | Localized derate, not full interruption for a single-pin fret (8-circuit header spreads current) | Rail-voltage sag under load; thermal imaging | J_IN1/2, J_OUT1/2 | S2 | `bench-misplug-injection.md` (connector-stress leg, once run) |
| §6.13 transient-detection front-end (INA181/comparator) fault | None on pass-through — front-end taps the shunt, does not sit in series | Loss of transient-FREEZE capability (a detection-surface degradation, not a power-path fault) | INA181-class CSA, comparator (if this family carries the ENT §6.13 front-end) | S1 | TBD — not yet run |
| RJ-45 link severed / mis-plug | None on the pass-through cables (module-to-Hub link is electrically separate) | DETECT-code mismatch, CAN bus-state, T1 link state (streaming family per REQ-MOD-COMMON-003) | J5 (RJ-45), D1 (pin-8 ESD) | S1 (by design) | `bench-misplug-injection.md` |

## Fail-passive rows

See `fmea-template-common.md` §"Fail-passive rows" — all five triggers apply
verbatim per cable (2 independent instances); none currently have dedicated
fault-injection evidence (all `TBD`).

## Open findings

- OQ-10 (bundled-shunt vertical) is unresolved; PCB-vertical severity for the
  40–55 A per-cable site cannot be bounded until it closes.
- This is a streaming family (100BASE-T1 per REQ-MOD-COMMON-003) — carries the
  full survey-11 T1 protection network (CMC + ≥100V coupling caps + TVS) as an
  in-path element on pins 4/5, not yet added to this worksheet pending that
  network's BOM landing.
- Shunt MPN (CSS2H-2512R-L500F) is not yet written into
  `beta/eps-8pin/bom/*.csv` per the OQ-11 sheet's own checklist — this
  worksheet's in-path element table is ahead of the BOM; reconcile at the next
  BOM-sourcing pass.

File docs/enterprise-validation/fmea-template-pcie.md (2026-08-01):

# FMEA — PCIe 8-pin module (`fmea-template-pcie`)

Instantiated from `fmea-template-common.md`. Family: PCIe 8-pin per-cable
interposer — two SKUs, 2-port (beta/pcie-8pin-2port) and 3-port
(beta/pcie-8pin-3port), rev2 current. Sensing: INA238 per cable (up to 3
cables). Qualitative FMEA only — FMEDA deferred per the common template's
depth ruling. This worksheet is written generically across both SKUs; the
3-port SKU carries one additional cable row (RS3/J_IN3/J_OUT3) that the
2-port SKU omits.

## In-path elements (pre-seeded)

| Ref | Element | Cable | Value/MPN | Package |
|---|---|---|---|---|
| RS1 | Shunt, cable 1 | 1 | Bourns CSS2H-2512R-L500F, 0.5 mΩ (OQ-11 sheet selection, same value as EPS) | 2512, 2-terminal, hand-routed Kelvin taps |
| RS2 | Shunt, cable 2 | 2 | Bourns CSS2H-2512R-L500F, 0.5 mΩ | 2512, 2-terminal, hand-routed Kelvin taps |
| RS3 | Shunt, cable 3 (3-port SKU only) | 3 | Bourns CSS2H-2512R-L500F, 0.5 mΩ | 2512, 2-terminal, hand-routed Kelvin taps |
| J_IN1/J_OUT1 … J_IN3/J_OUT3 | PSU-side in / load-side out, per cable | 1–3 | Molex 45586-0005, Mini-Fit Jr, dual-row RA, 3rd-gen PCIe polarization | THT header |
| PCB copper | Bundled-shunt vertical transition, per cable | all | — | OQ-10 unresolved (same open item as EPS — per-cable 40–55A site) |

## Failure-mode rows

| Failure mode | Effect on monitored power path | Detection surface | In-path element | Severity | Fault-injection evidence ref |
|---|---|---|---|---|---|
| Shunt open (any cable) | That cable interrupted — direct pass-through failure, other cables unaffected (per-cable isolation) | ALERT/threshold (INA238 sudden zero-current) | RS1/RS2/RS3 | S3 | TBD — not yet run |
| Shunt short/solder-bridge | None on pass-through current; destroys Kelvin sensing on that cable | INA238 differential reads near-zero permanently; sensor-fault classification | RS1/RS2/RS3 | S1 | TBD — not yet run |
| Kelvin tap trace open | None on pass-through (off main current path by construction) | INA238 reads open/clamped input | RS1/2/3 Kelvin taps | S1 | TBD — not yet run |
| Bundled-shunt vertical transition failure | Localized resistance rise or open; potentially cable-interrupting at the extreme (60–75A transient per spec §6.4 table) | Rail-voltage sag, ALERT threshold, or bench thermal imaging | PCB copper (OQ-10 pending) | S2/S3 depending on extent | TBD — needs OQ-10 resolution + dedicated bench |
| J_IN/J_OUT connector pin fret (45586-0005 polarized header) | Localized derate under a single-pin fret | Rail-voltage sag under load; thermal imaging | J_IN{1,2,3}, J_OUT{1,2,3} | S2 | `bench-misplug-injection.md` (connector-stress leg, once run) |
| Cross-cable thermal coupling (dense 2-/3-cable layout) causing one cable's fault to elevate a neighbor's steady-state temperature | Neighbor cable's margin erodes without itself faulting — a compounding, not primary, effect | Thermal imaging during bench; no on-board NTC currently | PCB copper / shunt siting | S2 | TBD — not yet run |
| §6.13 transient-detection front-end fault (if populated) | None on pass-through — taps the shunt, not in series | Loss of transient-FREEZE capability only | INA181-class CSA, comparator | S1 | TBD — not yet run |
| RJ-45 link severed / mis-plug | None on the pass-through cables | DETECT-code mismatch, CAN bus-state, T1 link state (streaming family) | RJ-45 jack, pin-8 ESD diode | S1 (by design) | `bench-misplug-injection.md` |

## Fail-passive rows

See `fmea-template-common.md` §"Fail-passive rows" — all five triggers apply
verbatim per cable (2 or 3 independent instances depending on SKU); none
currently have dedicated fault-injection evidence (all `TBD`).

## Open findings

- OQ-10 (bundled-shunt vertical) unresolved — same open item as EPS, shared
  root cause (both families use the same per-cable shunt-site geometry class).
- Streaming family (100BASE-T1 per REQ-MOD-COMMON-003) — carries the full
  survey-11 T1 protection network on pins 4/5; not yet an in-path row pending
  BOM landing.
- The 3-port SKU's third cable (RS3/J_IN3/J_OUT3) has no dedicated cross-cable
  thermal or mechanical isolation analysis yet — flagged as the compounding
  row above, needs its own bench pass once boards exist.
- Shunt MPN not yet written into `modules/pcie-8pin-*/bom/*.csv` (same
  OQ-11-sheet-ahead-of-BOM gap noted on the EPS worksheet).

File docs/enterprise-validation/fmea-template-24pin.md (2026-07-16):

# FMEA — 24-pin ATX module (`fmea-template-24pin`)

Instantiated from `fmea-template-common.md`. Family: 24-pin ATX interposer
(modules/atx-24pin, rev3 current). Sensing: 4x INA228 (12V, 5V, 3V3, 5VSB).
Qualitative FMEA only — FMEDA deferred per the common template's depth ruling.

## In-path elements (pre-seeded)

| Ref | Element | Rail | Value/MPN | Package |
|---|---|---|---|---|
| RS1 | Shunt | 12V | Bourns CSS2H-2512K-2L00F, 2 mΩ | 2512, 2-terminal |
| RS2 | Shunt | 5V | Bourns CSS2H-2512K-2L00F, 2 mΩ | 2512, 2-terminal |
| RS5 | Shunt | 3V3 | Bourns CSS2H-2512K-2L00F, 2 mΩ | 2512, 2-terminal |
| RS6 | Shunt | 5VSB | Vishay WSK2512R0250FEA, 25 mΩ | 2512, 4-terminal Kelvin (non-Bourns; only true-Kelvin part at this value — OQ-11 sheet) |
| J3 | PSU-side input connector | all 4 rails | Molex Mini-Fit Jr 5569, 24-ckt, male, RA | THT header (§2.8 LOCKED) |
| J4 | Motherboard-side output connector | all 4 rails | Molex Mini-Fit Jr 5569, 24-ckt, male, RA | THT header (§2.8 LOCKED) — bridged to the motherboard by a dedicated F-F cable, itself an in-path element pending its own part number |
| PCB copper | Rail traces/pours J3→shunt→J4 | all 4 rails | — | High-current stackup per OQ-12 (L3-rails-with-via-detour vs top-layer-rails — not yet resolved for this family) |

## Failure-mode rows

| Failure mode | Effect on monitored power path | Detection surface | In-path element | Severity | Fault-injection evidence ref |
|---|---|---|---|---|---|
| Shunt open (RS1/RS2/RS5) | Rail interrupted downstream of J3 — direct pass-through failure | ALERT/threshold (sudden zero-current + rail-voltage drop at INA228) | RS1/RS2/RS5 | S3 | TBD — not yet run |
| Shunt open (RS6, 5VSB) | 5VSB interrupted; also removes the Hub's bulk-power source (§2.7 — this module IS the 5VSB feed) | ALERT/threshold + Hub-side loss-of-bulk-power alarm | RS6 | S3 | TBD — not yet run |
| Shunt short/solder-bridge (any rail) | None on the rail itself (shunt is already low-mΩ; a hard short bypasses the sense element without interrupting current) — but destroys sensing on that rail | INA228 reads near-zero differential permanently; flagged as a sensor-fault, not a power-path fault | RS1/RS2/RS5/RS6 | S1 | TBD — not yet run |
| J3/J4 connector pin fret/high-resistance contact | Localized I²R heating, voltage droop under load on the affected pin(s); pass-through continues but derated | Rail-voltage sag at INA228 vs. expected regulation; thermal (no NTC on this family per CLAUDE.md — gap, flag for owner) | J3, J4 | S2 | `bench-misplug-injection.md` (connector-stress leg, once run) |
| PCB copper vertical failure (via-field crack/fatigue under thermal cycling) | Localized resistance rise or open on one rail segment | Rail-voltage sag or ALERT threshold, depending on severity | PCB copper (OQ-12 pending) | S2/S3 depending on extent | TBD — not yet run; needs OQ-12 resolution first |
| RJ-45 link severed / DETECT mis-plug (see `bench-misplug-injection.md`) | None on the ATX pass-through (module-to-Hub link is electrically separate from J3/J4 per §2.7/§2.8) | DETECT-code mismatch, CAN bus-state | J1 (RJ-45), D1 (pin-8 ESD) | S1 (by design — confirms fail-passive isolation) | `bench-misplug-injection.md` |

## Fail-passive rows

See `fmea-template-common.md` §"Fail-passive rows" — all five triggers apply
verbatim; none currently have dedicated fault-injection evidence (all `TBD`).

## Open findings

- No board-level NTC/thermal sensor on this family (unlike 12VHPWR's TH1/TH2) —
  the connector-fret detection surface above relies on rail-voltage sag alone;
  flag for owner whether a thermal tap is warranted at ENT tier.
- OQ-12 (stackup choice) is unresolved for this family; PCB-vertical severity
  cannot be bounded until it closes.
- RS6's 25 mΩ Kelvin part (WSK2512) uses a different footprint from RS1/RS2/RS5
  (Bourns CSS2H-2512) — confirm BOM carries both lands correctly at layout.

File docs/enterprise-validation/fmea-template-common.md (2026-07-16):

# FMEA template — common worksheet (per-family artifact: `fmea-template-{24pin,eps,pcie,12vhpwr}`)

Verification artifact for **REQ-MOD-COMMON-030** (fail-passive interposer
guarantee), **REQ-MOD-COMMON-031** (per-family FMEA/FMEDA with fault-injection
evidence), **REQ-MOD-COMMON-032** (in-path connector/copper thermal margins), and
**REQ-HUB-COMMON-081**. This is the shared worksheet structure; the four
instantiated files (`fmea-template-24pin.md`, `-eps.md`, `-pcie.md`,
`-12vhpwr.md`) pre-seed it with each family's real in-path elements.

**Depth ruling (trajectory scope, decision point "FMEA depth")**: qualitative FMEA
now, **quantitative FMEDA (failure rates, diagnostic coverage %) deferred until
OQ-11 (shunt part lock) and the survey-11 protection-network parts land in a
BOM** — avoids rework analyzing TBD parts. As of this writing OQ-11 has a
selection sheet (`docs/enterprise-requirements/ratification/
oq-11-shunt-selection-2026-07-02.md`) with exact MPNs per family but the formal
close still rides the pending v1.2.0 spec-text pass — treat every shunt MPN
below as ratified-pending-that-edit, not yet FMEDA-ready.

## Worksheet columns

| Column | Meaning |
|---|---|
| **Failure mode** | The specific way an in-path element fails (open, short, drift, mechanical, thermal). Named per element, not generically ("MCU dead" is a system-level trigger, not a row — see §"System-level triggers" below). |
| **Effect on monitored power path** | What happens to the pass-through 12V/5V/3V3/5VSB delivery the module sits in series with — NOT what happens to sensing accuracy. A row whose only effect is "sensing goes blind" is a detection-surface finding, not a fail-passive violation. |
| **Detection surface** | How the platform observes this failure: ALERT/threshold (§6.10 acquisition model), DETECT-code mismatch, CAN bus-state (error-passive/bus-off), thermal (NTC where present), or "none identified" (an honest gap, not a blank). |
| **In-path element** | The specific part/reference designator/PCB feature in the pass-through path (shunt, connector, copper vertical) — see the per-family pre-seed. Sensing-only components (INA228/238/240, ESP32, CAN transceiver) are NOT in-path; their failure modes belong in the fail-passive rows below, not here. |
| **Severity** | S1 negligible (sensing/telemetry degraded only, pass-through power unaffected) / S2 moderate (pass-through derates but continues, e.g. added series resistance from a partial connector fault) / S3 major (pass-through power interrupted, degraded below spec, or destabilized — any S3 finding is a REQ-MOD-COMMON-030 violation and MUST be designed out, not accepted with a note). |
| **Fault-injection evidence ref** | Pointer to the actual injection test that produced evidence for this row: `bench-misplug-injection.md` run ID for connector/pin faults, a dedicated shunt/copper fault-injection bench run ID (open-shunt, shorted-shunt, thermal-cycling), or `TBD — not yet run` where evidence doesn't exist yet. A row with severity S3 and evidence `TBD` is the reason REQ-MOD-COMMON-031 gates GA. |

## Fail-passive rows (REQ-MOD-COMMON-030 — every family carries these verbatim)

REQ-MOD-COMMON-030's text names five specific single-fault triggers; every
family's instantiated FMEA restates these five as baseline rows, because they
are system-level (not tied to one in-path element) and are the actual claim
REQ-030 makes:

| Trigger | Required effect on pass-through power |
|---|---|
| MCU dead (crashed, browned out, unprogrammed) | None — pass-through is a passive/analog current path independent of MCU liveness (INA sense taps and any active limiter must not open the path on MCU loss). |
| Sensor shorted (INA228/238/240 input pin shorted to a rail) | None — sense taps are high-impedance off the pass-through conductor; a shorted sense input must not pull down or short the monitored rail itself. |
| Firmware crash / watchdog reset | None — same reasoning as MCU dead; a crash-loop must not toggle any element in series with the power path. |
| Link severed (RJ-45 cable unplugged or CAN/T1 down) | None — the module is a physical pass-through independent of its telemetry uplink; losing the Hub link must not affect the PSU-to-load power delivery. |
| 5VSB lost (module's own housekeeping power fails) | None — same class as MCU dead; the housekeeping rail is not in the high-current pass-through path by design (§2.7/§2.8), so its loss must not couple into it. |

## PCB-vertical / thermal margin rows (REQ-MOD-COMMON-032)

Every family with a bundled-shunt or per-pin vertical current transition
(via field, copper coin, or plated slot per OQ-10; layer-routing choice per
OQ-12) carries a row for the vertical itself, referencing the family's
declared production cooling model (12VHPWR precedent: TIM/case coupling stated,
still-air bound published as the conservative number, per CLAUDE.md action
item 4).

## Notes for every instantiated file

- In-path elements are pre-seeded from CLAUDE.md's per-board build state and
  the OQ-11 shunt selection sheet; MPNs shown are the sheet's selection, not yet
  a closed OQ-11 (see depth-ruling note above).
- **FMEDA upgrade** (failure rates + diagnostic coverage %) is explicitly
  deferred, per family, until (a) OQ-11 formally closes via the v1.2.0 spec
  edit and (b) `bench-misplug-injection.md` / a dedicated shunt fault-injection
  bench has produced real evidence to calibrate rates against — do not
  backfill FMEDA numbers from datasheet MTBF alone without bench corroboration.

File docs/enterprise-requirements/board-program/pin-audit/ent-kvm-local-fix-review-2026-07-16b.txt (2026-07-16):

Footprint-assignment pass -- modules/ent-kvm-carrier/ent-kvm-local.kicad_sym
(2026-07-16b, stretch scope, ENT library-intake agent)

SCOPE: the local (project-embedded, not lib/-shared) symbol library backing
modules/ent-kvm-carrier carried 9 hand-drawn/placeholder symbols, all 9 with
an EMPTY Footprint property at the library-definition level, plus a matching
gap at several already-placed schematic instances. This pass closes the gap
for 6 of the 9 symbols (real MPN, real LCSC-native footprint, ERC-clean) and
explicitly, deliberately defers the remaining 3 (M2_MKEY_A_M3C,
M2_MKEY_B_M3C, LT6911_FUNC) -- see DEFERRED below, also logged in
FOLLOWUPS.md.

Real instance count found (NOT the "~33" in the work order -- that figure
over-counted; verified programmatically via a proper (symbol (lib_id ...))
schematic-instance scan, not a naive property-string grep, across all ten
sheet files): 13 schematic instances truly had an empty per-instance
Footprint property (Y1, Y2, U9, F1, D6, J4, J5, J6, J7, U11, D7, D8, D9).
Y1/Y2 (ent-common-local:Crystal_Small, 40MHz/25MHz) are OUT OF SCOPE for this
pass -- that symbol lives in modules/ent-common/, which the work order did
not grant (only modules/ent-kvm-carrier/ was authorized); flagged in
FOLLOWUPS.md rather than touched.

FIXED (real MPN already recorded on the schematic instance in every case --
this pass only had to find + verify + attach the matching real footprint,
not choose a part):

  TS3USB221_FUNC (U9, sheet 07-usb-gate) -- TI TS3USB221ARSER, LCSC C128396.
    Footprint pulled via easyeda2kicad, kicad-cli fp-upgraded, vendored as
    ent-kvm-local:UQFN-10_TS3USB221ARSER_L2.0-W1.5-P0.50 (10 pads, matches
    the symbol's 10 pins exactly). Symbol pin names (D+/D-/S/OE#/D1+/D1-/
    D2+/D2-/VCC/GND) were ALREADY correct against the TI datasheet order
    ("D- D+ 1D- 1D+ 2D- 2D+ S OE" per the LCSC-hosted datasheet) -- no pin
    edits needed, audit already clean (0 findings).

  FUSE_PTC (F1, sheet 08-compute-power) -- Bourns MF-MSMF200-2 (2A/8V PPTC,
    1812 SMD), LCSC C210837. Footprint pulled + vendored as
    ent-kvm-local:F1812_MF-MSMF200-2 (2 pads, matches). Symbol already
    typed both pins passive -- correct for a 2-terminal fuse, no edits.

  D_TVS_BIDIR (D6, sheet 08-compute-power) -- bidirectional TVS SMF5.0CA,
    SOD-123, LCSC C908214 (FUXINSEMI, 144k+ units in stock -- picked over
    the MDD/SEMIWARE/ZHIDE/TWGMC alternates also listed for this exact MPN
    on the strength of that stock depth). Footprint vendored as
    ent-kvm-local:SOD-123_SMF5.0CA_L2.8-W1.8-LS3.7 (2 pads, matches).
    Symbol already typed both pins passive -- correct for a symmetric
    bidirectional TVS, no edits.

  TF_CARD_TF123 (J6, sheet 09-m2-module) -- XUNPU TF-123-ARP9H17 microSD
    socket, LCSC C2982548. Footprint vendored as ent-kvm-local:TF-SMD_TF-
    123-ARP9H17_13P (13 pads, matches; the raw easyeda pull's own internal
    footprint name says "ARP9H15" not "-H17" -- a cosmetic LCSC/EasyEDA
    metadata naming quirk on THEIR side, not a wrong-part pull: the C-number
    C2982548 is confirmed the real "-H17" listing and the land dimensions
    are what matter, not the informal name string). Symbol pin names
    (DAT2/CD-DAT3/CMD/VDD/CLK/VSS/DAT0/DAT1 + SWITCH + 4x SHELL) already
    match the real, standard microSD 8-contact pinout plus card-detect and
    shield -- no edits, 0 findings.

  HDMI_A_19P (J7, sheet 10-hdmi-capture) -- BOOMELE HDMI-001 19PCBTP,
    LCSC C138388 (54.5k+ units in stock). Footprint vendored as ent-kvm-
    local:HDMI-A-SMD_19P_HDMI-001-19PCBTP (23 pads: 19 SMD signal + 4 THT
    shell-ground tabs, matches). Symbol pin NAMES already match the real,
    standard HDMI-A pinout (TMDS pairs + shields, CEC, DDC, +5V, HPD) --
    but the symbol's 4 shell pins were NUMBERED "SH1".."SH4" while the real
    footprint numbers its 4 through-hole shell tabs "20".."23" (verified:
    those 4 pads are the large oval THT pads, physically the shell tabs --
    pads 1-19 are the SMD signal pins). RENUMBERED the symbol's shell pins
    SH1->20, SH2->21, SH3->22, SH4->23 (both the library definition and
    each schematic's cached lib_symbols copy) so pin-number <-> pad-number
    correspondence holds for netlist/BOM tools that key off the number, not
    the name. This is a pure relabeling -- no pin (at x y angle) position
    moved, so wire connectivity (position-keyed in KiCad, not number-keyed)
    is unaffected; confirmed via a clean netlist re-export (J7 shows 23
    correctly-connected nodes, incl. the renumbered shell pins) and ERC
    (177 violations before and after -- see VERIFICATION below).

  Q_NMOS_GSD (Q1/Q2/Q3, sheet 09-m2-module) -- 2N7002 (Q1/Q2) and BSS138
    (Q3), both real, common small-signal N-FETs. The SCHEMATIC INSTANCES
    already carried a real footprint (cec-Package_TO_SOT_SMD:SOT-23-3_L2.9-
    W1.3-P1.90-LS2.4-BR) -- only the shared LIBRARY DEFINITION was blank
    (so Q1/Q2/Q3 were never in the "13 empty" scan; the gap was invisible
    on the sheet but would resurface for the NEXT Q_NMOS_GSD placement).
    Set the library Footprint to match the already-placed, already-correct
    instance value rather than introduce a second SOT-23 variant. Symbol
    pin map (1=G/input, 2=S/passive, 3=D/passive) already matches the real,
    standard SOT-23 small-signal-FET pinout -- no edits, 0 findings.

  RClamp0524PATCT (D7/D8/D9, sheet 10-hdmi-capture) -- this is a lib/-
    shared cec-ent-net symbol (manifest item #19, already landed with a
    real footprint at the library level: cec-Package_DFN_QFN:
    SLP2510P8_L2.5-W1.0-P0.50-BL). Only the three SCHEMATIC INSTANCES were
    blank (same "instance never synced from an already-correct library"
    shape as Q_NMOS_GSD) -- set all three to match the library default.
    No library or pin-type change needed (not this pass's symbol to begin
    with).

DEFERRED (documented, not silently skipped -- see FOLLOWUPS.md for the
dated bullet):

  M2_MKEY_A_M3C / M2_MKEY_B_M3C (J4/J5, sheet 09-m2-module) -- 67-pin
    symbols each, MPN on the schematic is HYCW23M-05NGFF-670B (HOAUC,
    "M2-MKEY-75P-A"/"-B" per the Value field). NO live LCSC listing found
    for this exact MPN this session (only a same-family sibling,
    HYCW33B-05NGFF-670B, turned up on JLCPCB) -- M.2 connectors have
    multiple real keying/notch variants (A/B/E/M-key, differing pin
    subsets), so pulling a similarly-named but NOT-verified-identical
    footprint risks a real mis-keyed/wrong-pinout part, worse than leaving
    the gap open. This accounts for the BULK of the 45 high + 63 medium
    findings on this library (mostly TX-direction and GPIO-multi-function
    passive-vs-output/bidirectional calls across the two 67-pin symbols) --
    deliberately left alongside the footprint gap rather than fixed in
    isolation, since a correct pin-type pass and a correct footprint pass
    for a connector this large are naturally one piece of work once a
    verified real M.2 socket MPN is in hand.

  LT6911_FUNC (U11, sheet 10-hdmi-capture) -- the schematic's own MPN field
    reads "LT6911C/UXC-class (TBD)" -- the exact Lontium variant/package is
    an OPEN DESIGN DECISION, not yet made by whoever captured this sheet.
    Assigning a firm footprint (or auditing pin types against one specific
    variant's real pinout) ahead of that decision would be presumptuous and
    could actively mislead a later reader into thinking the part choice is
    settled. Left untouched; the remaining handful of this library's high/
    medium findings not on the M2 connectors belong to this symbol.

VERIFICATION:
  - kicad-cli sym upgrade (no --force; the file was already in current
    20251024/kicad_symbol_editor format, so this is a safe validate-only
    no-op -- confirmed "Symbol library was not updated" both before and
    after) -- exit 0.
  - kicad-cli fp upgrade on the new ent-kvm-local.pretty/ directory (a
    fresh directory with only these 5 new files, so no risk of the
    whole-directory-reformat footgun recorded in FOLLOWUPS.md 2026-07-16b)
    -- exit 0, "not updated" (already current format post-pull).
  - ERC (kicad-cli sch erc on the full ent-kvm-carrier.kicad_sch hierarchy):
    177 violations BOTH before (git-stash baseline, scoped to only this
    board's own files) and after this pass's schematic edits -- the 8
    "lib_symbol_mismatch" findings the Footprint/pin-number edits initially
    introduced (library definition changed, each sheet's own cached
    lib_symbols copy not yet synced) were resolved by syncing those cached
    copies too, not left as "known benign" noise.
  - Netlist export (kicad-cli sch export netlist): clean, J7 (HDMI_A_19P)
    shows 23 correctly-connected nodes post-renumbering.
  - python3 scripts/cec_sym_audit.py --audit: high=45 medium=63 both before
    and after (unchanged -- confirms none of this pass's edits were pin-
    type changes, and that the entire finding set belongs to the 3
    deliberately-deferred symbols, not the 6 fixed ones, which independently
    show 0 findings each).

NOT run this pass: tests/test_sym_audit.py's hardcoded pin-count fixture
does NOT cover this file (it only tracks lib/cec-ent-{power,net,compute,mcu}
.kicad_sym) -- no fixture update needed or made.

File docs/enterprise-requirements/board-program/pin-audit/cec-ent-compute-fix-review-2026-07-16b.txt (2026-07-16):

T2 pin-type review -- cec-ent-compute.kicad_sym intake additions (2026-07-16b)
Part: FTSH-105-01-L-DV-K (easyeda2kicad pull, LCSC C5155080). Agent: ENT
library-intake, kicad-intake-manifest-2026-07-02.md row 14, hub JTAG/FlashPro
programming header, sheet 02c.

VERIFICATION BASIS: this is a GENERIC 2x5, 1.27mm-pitch SMT terminal strip --
Samtec does not assign per-pin functions to the connector part itself; the
JTAG/FlashPro signal-to-pin mapping is a board-level wiring decision (per
bom-a-compute.md, Microchip's own DS60001681H Figure 1-6 reference design
assigns the signals at that level, not in the connector). Confirmed the
MECHANICAL/mount style independently, since bom-a-compute.md's existing
"2x5 vertical THT" description does not match what the easyeda2kicad pull
actually carries (SMD gull-wing-style rect pads, no drill holes) -- a web
search of Samtec's own FTSH family description confirms "FTSH SMT Terminal
Strip" / "connector header surface mount", so the pulled SMD land is the
physically-correct one and the existing repo doc's "THT" label appears to be
a pre-existing inaccuracy (out of this task's scope to fix, flagged here for
the record; not touched).
  pins 1-10  unspecified -> passive  (all ten, named by position "1".."10" --
        no fixed function per the connector part itself). This matches the
        platform's existing convention for a generic multi-pin connector with
        no per-pin function (see KH-PCB-6P6C in cec-ent-power.kicad_sym,
        which the auditor accepts at 'unspecified'/low-severity for the same
        reason; 'passive' was chosen here instead of leaving 'unspecified'
        since it is a strictly cleaner, zero-finding result for a part that
        genuinely has no better-known type, and matches the diode-terminal
        'passive' convention already used elsewhere in this same library
        group for similarly function-less pins).
  Also added a ki_keywords property -- the raw easyeda2kicad pull for this
  part omitted it entirely (present on every other pulled part in this
  session's batch); added "JTAG programming header 2x5 1.27mm" to match
  house convention (every other symbol in this file/group carries one).

TOOLCHAIN FOOTGUN (grid alignment): the raw pull placed all ten pins on a
1.27mm half-grid offset (X coordinates ending in .35, not a 2.54 multiple) --
see cec-ent-power-fix-review-2026-07-16b.txt's "TOOLCHAIN FOOTGUN FOUND"
section for the general finding across this session's whole pull batch.
Fixed here by a uniform -1.27mm X shift of the entire symbol block (pins +
graphics together); verified 0 off-grid pins post-fix.

FOOTPRINT: NEW footprint vendored, cec-ent-compute:HDR_2x5_P1.27mm_FTSH-105-
01-L-DV-K.kicad_mod (the real easyeda2kicad LCSC-mirrored land -- ten 0.76 x
2.4mm SMD rect pads at 1.27mm pitch/2.54mm row spacing, matching the Samtec
FTSH-105 family's real dimensions), kicad-cli fp-upgraded to KiCad-10 format,
3D STEP copied to lib/3dmodels/cec-ent-compute.3dshapes/ (a fresh directory --
none existed for this library before; the pre-existing MPFS095T_FCVG484 BGA
footprint in this same .pretty references a 3dshapes path that does not
actually exist on disk, a pre-existing gap, not touched by this pass). NOTE:
running `kicad-cli fp upgrade` on the WHOLE cec-ent-compute.pretty directory
(rather than targeting only the new file) silently rewrote the pre-existing
BGA-484_19x19mm_P0.8mm_MPFS_FCVG484.kicad_mod footprint too (stroke-width and
UUID changes, `(attr smd)` reordered) -- caught via `git status`/`git diff`
before committing and reverted with `git checkout --`; only the new FTSH-105
file was kept. Lesson for future intake passes into a shared .pretty
directory: run kicad-cli fp upgrade against the SPECIFIC new file, not the
whole directory, or diff-review before staging.

Post-fix gate: cec-ent-compute.kicad_sym high=0 (the pre-existing
MPFS095T_FCVG484 medium findings -- JTAG/TX-direction/refclk bidirectional
calls -- are untouched and do not gate; FTSH-105-01-L-DV-K appears in zero
findings at any confidence). Test suite (tests/test_sym_audit.py) 11/11,
pin-count fixture updated 484 -> 494 (+10).

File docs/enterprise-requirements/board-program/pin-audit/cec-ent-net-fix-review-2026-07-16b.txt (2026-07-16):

T2 pin-type review -- cec-ent-net.kicad_sym intake additions (2026-07-16b)
Parts: TLV75801PDBVR (easyeda2kicad pull, LCSC C2877852), ABM3-25.000MHZ-B2-T
(hand-drawn, no LCSC listing found). Agent: ENT library-intake,
kicad-intake-manifest-2026-07-02.md rows 16 (TLV75801PDBVR) and 17 (ABM3
crystal), both uplink-PHY-rail parts (sheet 07a).

VERIFICATION BASIS (TLV75801PDBVR): pin map cross-checked against the real TI
datasheet SBVS351D (TLV758P family, fetched direct from ti.com and read via
the PDF-vision path -- the same WebFetch-text-extraction failure mode noted
for TPS7A20 in cec-ent-power-fix-review-2026-07-16b.txt applied here too, so
the PDF was downloaded and read directly rather than trusted from a text
summary). SBVS351D Figure 4-2 "DBV Package, 5-Pin Adjustable SOT-23 (Top
View)": 1=IN, 2=GND, 3=EN, 4=FB, 5=OUT -- exact match to the easyeda2kicad
pull. This is the ADJUSTABLE sibling of the TPS7A20 fixed-output family (same
DBV/SOT-23-5 package, 2.9x2.8mm per the datasheet's own Package Information
table) -- the BOM's own use ("LDO, adjustable, set to 1.1V via FB divider")
confirms the FB-pin variant is the correct part, not a TPS7A20 fixed code.
  pin 1 IN   unspecified -> power_in
  pin 2 GND  unspecified -> power_in
  pin 3 EN   unspecified -> input
  pin 4 FB   unspecified -> input   (feedback sense into the error amplifier
        -- an input to the regulator, per SBVS351D S6.3's own "Adjustable
        Operation" description of FB as the loop's sense node)
  pin 5 OUT  unspecified -> power_out  (see the power_out-vs-output rationale
        in the sibling cec-ent-power log; same call, same reasoning)
  Symbol graphic/pin layout intentionally rebuilt IDENTICAL to
  TPS7A2018PDBVR/TPS7A2050PDBVR (cec-ent-power.kicad_sym) for a consistent
  LDO-family schematic appearance across the three DBV parts this intake
  landed -- see that log's "TOOLCHAIN FOOTGUN FOUND" section for why (the raw
  easyeda2kicad pull for this part was off the 2.54mm grid).

VERIFICATION BASIS (ABM3-25.000MHZ-B2-T): NO live LCSC listing was found for
this exact ordering code (checked lcsc.com search, a direct site: search, and
cross-distributor searches) -- LCSC carries adjacent same-family codes
(e.g. ABM3-24.000MHZ-D2Y-T / C1985382) but not this frequency+suffix
combination, and easyeda2kicad has nothing to pull. Per the manifest's own
fallback instruction (row 17), hand-drawn instead. Confirmed this is a REAL,
valid Abracon ordering code (not a typo) by fetching and reading Abracon's own
ABM3.pdf (vendored nowhere in-repo; fetched fresh from abracon.com) via the
PDF-vision path: the "Options and Part Identification" ordering-code diagram
on page 2 shows exactly this shape (ABM3-[freq]MHz-[loadcap]-[optemp][stab]-
[tolerance]-[packaging], with unlisted fields left blank for standard
defaults), and a live DigiKey listing (product 675303) independently confirms
the part is real and orderable. Page 3 "Mechanical Dimensions" confirms the
package: 5.0x3.2x1.3mm ceramic body, a genuine 2-TERMINAL part (the
"CONNECTION" detail view shows only Pin1/Pin2, no third case/ground pad) --
both pins are just the crystal's own two terminals.
  pin 1  unspecified -> passive  (hand-drawn; named "1", matching the generic
        2-terminal-passive convention KiCad's own Device:Crystal symbol uses)
  pin 2  unspecified -> passive  (named "2")
  Symbol hand-drawn as a simple 2-plate crystal glyph (two vertical bars +
  connecting stubs + an outer case rectangle), all pins on the 2.54mm grid by
  construction (Â±5.08mm, length 2.54mm each).

FOOTPRINT: TLV75801PDBVR REUSES cec-Package_TO_SOT_SMD:SOT-23-5 (same
reasoning as the TPS7A20 pair -- see the sibling cec-ent-power log; all three
DBV-family LDOs land on the identical generic SOT-23-5 body). ABM3-25.000MHZ-
B2-T gets a NEW hand-drawn footprint, cec-ent-net:Crystal_SMD_5032-2Pin_ABM3
-- 2 roundrect SMD pads (1.9x2.4mm, 2.05mm off-center each way, giving a
2.2mm inner gap and 6.0mm overall span), taken directly from Abracon's own
"Recommended Land Pattern" drawing on page 3 of the fetched ABM3.pdf. No 3D
model (none available to pull; a hand-drawn STEP was judged out of scope for
an S-effort passive).

Post-fix gate: cec-ent-net.kicad_sym high=0 (the file's substantial
pre-existing medium/low backlog -- DP83869HMRGZR/DP83TC814S-Q1/LAN9370-I_KCX
TX-direction and connector-pin findings -- is untouched by this pass and does
not gate; neither new symbol appears in any medium/low finding either). Test
suite (tests/test_sym_audit.py) 11/11, pin-count fixture updated
187 -> 194 (+5 +2).

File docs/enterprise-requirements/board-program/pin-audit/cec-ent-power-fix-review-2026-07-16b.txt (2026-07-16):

T2 pin-type review -- cec-ent-power.kicad_sym intake additions (2026-07-16b)
Parts: TPS7A2018PDBVR, TPS7A2050PDBVR (easyeda2kicad pulls, LCSC C963430 /
C2864504), TLP172A (easyeda2kicad pull, LCSC C99477), LM393DR2G (easyeda2kicad
pull, LCSC C7955). Agent: ENT library-intake, kicad-intake-manifest-2026-07-02.md
rows 12 (TPS7A20 pair), 22 (TLP172A), 23 (LM393DR2G).

TOOLING NOTE (pin types set correctly at intake, not run through --fix): all
four parts were typed by hand against the verified datasheet pin map before
merging, not pulled-then-audited-then-fixed -- so this log documents the
verification basis and the deliberate type choices, per the same discipline
the --fix workflow enforces, rather than a mechanical before/after diff.

VERIFICATION BASIS (TPS7A2018PDBVR / TPS7A2050PDBVR): pin map cross-checked
against the real TI datasheet SBVS338H (fetched direct from ti.com, read via
the PDF-vision path since WebFetch's text extraction could not read the pinout
table/diagram reliably -- a WebFetch-only attempt on this same PDF returned an
outright WRONG pinout, caught before it was used). SBVS338H Figure 4-4 "DBV
Package, 5-Pin SOT-23 (Top View)": 1=IN, 2=GND, 3=EN, 4=N/C, 5=OUT -- this is
an EXACT match to what the easyeda2kicad pull already produced independently
from the LCSC listing, cross-verifying both sources. Package size 2.9x2.8mm
(incl. pins) per the same datasheet's Package Information table.
  pin 1 IN   unspecified -> power_in
  pin 2 GND  unspecified -> power_in
  pin 3 EN   unspecified -> input
  pin 4 NC   unspecified -> no_connect  (renamed from the pull's "N/C"/"NC")
  pin 5 OUT  unspecified -> power_out  (LDO regulator output, not a bare
        signal -- power_out is in the auditor's accepted-compatible set for
        an 'output'-class OUT pin; chosen over REF3030's plain 'output' since
        this part supplies a real load rail, unlike a low-current reference)

VERIFICATION BASIS (TLV75801PDBVR, landed in cec-ent-net.kicad_sym not this
file -- manifest row 16, uplink-PHY grouping, sheet 07a): same DBV/SOT-23-5
family, but the ADJUSTABLE variant -- TI SBVS351D Figure 4-2 "DBV Package,
5-Pin Adjustable SOT-23": 1=IN, 2=GND, 3=EN, 4=FB, 5=OUT. Noted here because
its symbol graphic/pin layout was built identical to TPS7A2018/2050 (same
family, same box) for a consistent LDO appearance across all three -- see the
cec-ent-net-fix-review-2026-07-16b.txt log for its own pin-type table.

VERIFICATION BASIS (TLP172A): the FIRST datasheet pull (via a guessed Toshiba
docget URL) landed on the WRONG PART -- TLP183 (a phototransistor coupler,
SO6, completely different pin count/function) -- caught by cross-checking the
description text against the BOM's own "SOP-4 PhotoMOS" characterization
before using anything from it. Re-pulled the REAL TLP172A datasheet two ways
(LCSC's redirected PDF + Toshiba's own docget with the correct did=16993) and
confirmed both agree. Official Toshiba datasheet (Rev.2.0, 2025-08-22) Figure
4.1 "Pin Assignment": 1=Anode, 2=Cathode, 3=Drain, 4=Drain -- the device is a
back-to-back dual-MOSFET AC switch (Note 1: "pins 3/4 are shorted" for the
2-terminal isolation test), so BOTH output pins are genuinely named "Drain" in
the datasheet, not a typo or an easyeda auto-naming artifact -- the
easyeda2kicad pull (LCSC C99477) independently produced the same A/C/D/D map,
cross-verifying it a second way.
  pin 1 A (Anode)    unspecified -> passive
  pin 2 K (Cathode)  unspecified -> passive  (renamed from the pull's "C" to
        match the platform's A/K diode-terminal convention, e.g. SS110/SMAJ58A
        in this same file)
  pin 3 D (Drain)    unspecified -> passive
  pin 4 D (Drain)    unspecified -> passive
  All four typed passive (LED input terminals + a relay-contact-style output
  pair have no ERC-meaningful direction, matching how SS110/SMAJ58A's diode
  terminals are typed in this same file).

VERIFICATION BASIS (LM393DR2G): onsemi datasheet (LM393/D, Rev.34, Sept 2025,
fetched direct from onsemi.com) "PIN CONNECTIONS (Top View)" diagram read via
the PDF-vision path, cross-checked against the well-established industry-
standard LM393/LM339-family pinout (identical layout convention across every
manufacturer's LM393 datasheet): 1=Output A, 2=Inputs A, 3=Inputs A, 4=GND,
5=Inputs B, 6=Inputs B, 7=Output B, 8=VCC, with the inverting/non-inverting
order within each "Inputs" pair following the standard convention (pin closer
to the output = inverting).
  pin 1 OUT1  unspecified -> open_collector  (renamed from "OUT/A"; LM393's
        output stage is genuinely open-collector per the datasheet's own
        "Output Short Circuit-to-Ground" rating and no internal pull-up --
        open_collector is in the auditor's accepted-compatible set for an
        'output'-class pin, and is the electrically PRECISE choice here,
        preferred over the generic 'output' REF3030-style call)
  pin 2 IN1-  unspecified -> input  (renamed from "IN/A/2")
  pin 3 IN1+  unspecified -> input  (renamed from "IN/A")
  pin 4 GND   unspecified -> power_in
  pin 5 IN2+  unspecified -> input  (renamed from "IN/B")
  pin 6 IN2-  unspecified -> input  (renamed from "IN/B/2")
  pin 7 OUT2  unspecified -> open_collector  (renamed from "OUT/B")
  pin 8 VCC   unspecified -> power_in
  Also dropped one of two EXACT-DUPLICATE pin-1 marker circles the easyeda
  pull carried in the graphic (cosmetic, harmless either way, cleaned up).

TOOLCHAIN FOOTGUN FOUND + RECORDED (grid alignment): easyeda2kicad's own
auto-layout does NOT reliably land pins on the platform's required 2.54mm
grid -- of the six parts pulled in this session's batch (four in this file,
two in cec-ent-net), only TPS7A2018PDBVR happened to land on-grid; the other
five were off by exactly 1.27mm (a half-grid offset) on one or both axes.
Fixed per-file: TPS7A2050PDBVR and TLV75801PDBVR were REBUILT with the exact
same graphic/pin layout as TPS7A2018PDBVR (same DBV/SOT-23-5 family, so this
also gives all three LDOs a consistent schematic appearance); TLP172A and
LM393DR2G (this file) plus FTSH-105-01-L-DV-K (cec-ent-compute) were fixed by
a uniform rigid-body coordinate shift of the WHOLE symbol block (pins +
graphics together, so nothing moves relative to anything else) by the exact
amount needed to bring every pin onto a 2.54mm multiple -- verified
programmatically post-fix (0 off-grid pins across all six parts). Also found
and fixed a SEPARATE bug in my own construction script: an early description
string for TLP172A contained a literal embedded double-quote character, which
silently truncated the KiCad string literal mid-property and corrupted the
S-expression (kicad-cli failed with "Unable to load library", no line number)
-- the file was regenerated fresh from the LCSC pull and every property/pin-
name string is now asserted quote-free before being spliced in.

FOOTPRINT REUSE DECISIONS (verify pin-map/land-match before reuse, per task):
  TPS7A2018PDBVR / TPS7A2050PDBVR -> REUSED cec-Package_TO_SOT_SMD:SOT-23-5
  (the platform's existing generic JEDEC MO-178 Var AA land). The easyeda
  pulls named their own lands "TSOT-23-5"/"SOT-23-5" with different pad
  styles (roundrect vs rect) and slightly different pad sizes, but all three
  independent sources (our vendored generic land, and both easyeda pulls)
  agree on the same physical envelope -- 0.95mm pin pitch, ~2.2-2.3mm row
  span -- and TI's own datasheet package table confirms "2.9mm x 2.8mm (incl.
  pins)" for the DBV package, consistent with the vendored land's body
  silkscreen (~2.9 x ~1.6mm). No new footprint vendored; Footprint property
  set to cec-Package_TO_SOT_SMD:SOT-23-5 directly.
  TLP172A -> NEW footprint vendored: cec-Package_SO:SOP-4_TLP172A_L3.9-W4.4-
  P2.54.kicad_mod (the real easyeda2kicad LCSC-mirrored land, kicad-cli
  fp-upgraded to KiCad-10 format, 3D STEP copied to
  lib/3dmodels/Package_SO.3dshapes/). No generic SOP-4 land existed in
  cec-Package_SO before this -- added following the same-directory precedent
  set by this session's other net-new SOIC-16/TSSOP-16 additions (dimensioned
  variant, not a fresh per-part library).
  LM393DR2G -> REUSED cec-Package_SO:SOIC-8_3.9x4.9mm_P1.27mm (the platform's
  existing standard narrow-body SOIC-8 land, already production-proven on
  INA240/TJA1051T-3 elsewhere in this platform). The easyeda pull's own land
  measured a ~9.5% wider row span (5.42mm vs 4.95mm) -- a real but modest
  difference consistent with IPC-7351 density-level variance across two
  different footprint generators for the same JEDEC MS-012AA body, not a
  different physical package. Judged the platform's own proven land the
  lower-risk reuse rather than vendoring a second, less-vetted SOIC-8
  variant purely for this one part.

Post-fix gate: cec-ent-power.kicad_sym high=0 (medium/low pre-existing
classes on OTHER symbols in this file are untouched, not gating -- none of
the four new symbols above appear in any medium/low finding either). Test
suite (tests/test_sym_audit.py) 11/11, pin-count fixture updated
106 -> 128 (+5 +5 +4 +8).

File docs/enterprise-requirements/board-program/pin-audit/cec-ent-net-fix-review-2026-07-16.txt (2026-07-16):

T2 pin-type review — cec-ent-net.kicad_sym intake additions (2026-07-16)
Parts: LAN9370-I_KCX (UltraLibrarian export, owner-supplied — Microchip full
datasheet is login-locked, site erroring, support unresponsive) and
JXD0-0001NL (SnapEDA export, owner-supplied).

VERIFICATION BASIS (LAN9370): pin map programmatically diffed against the
public product brief DS00002819B Table 3-1 (vendored at
lib/datasheets/LAN9370-Product-Brief-DS00002819B.pdf): 64/64 exact name
match + pin 65 = EP = VSS ("Exposed Pad Must be Connected to VSS").
Package cross-checked vs brief §4: VQFN-64 KCX 8x8x0.9mm, 0.4mm pitch,
6.5x6.5 EP, stepped wettable flanks (drawing C04-479 Rev A) — matches the
measured footprint (65 pads, EP 6.5024, min pitch 0.4). All pins on the
2.54 grid, 0 off-grid.

FIXES APPLIED (LAN9370-I_KCX):
  pin 46 VSS            power_out  -> power_in   (auditor high, agreed)
  pin 65 VSS (EP)       power_out  -> power_in   (auditor high, agreed)
  pin 52 CLK125/CASCADE_EN  output (HAND RULING vs auditor 'input'):
        brief Table 3-2 types CLK125 as an RGMII-class 125 MHz reference
        clock OUTPUT to the SoC MAC, "also provides configuration strap
        functions during a hardware reset"; sibling pin 51
        CLKO_25M/CASCADE_ID is typed VO8 (output). Primary function decides
        direction; the strap is reset-time only. AUDITOR CALIBRATED (same
        philosophy as the 2026-07-03 CS/RST calibration): mux-SECONDARY
        EN/ENABLE (EN not the first-listed function) now accepts a
        deliberate input/output/bidirectional; unspecified stays suspect;
        primary-EN pins keep the full rule. Regression test added
        (tests/test_sym_audit.py::test_mux_secondary_en_deliberate_type_accepted).
  pins 2/3/9/10/12/13/55/56 TRXP/N[4:1]  unspecified -> bidirectional
        (Table 3-2 buffer type 'A', 100BASE-T1 transmit/receive pairs)
  pins 6/16 T1_EXTRES/EXTRES  unspecified -> passive
        (Table 3-2: 6.49k 0.1% reference resistor connections to VSS)
  pin 59 XO / pin 60 XI — already output/input from UL, left as-is.

JXD0-0001NL: zero auditor findings (all 16 pins passive — correct for a
connector + passive magnetics). Pin set 1-14 + SH1/SH2 verified against the
footprint pad set (plus 2 NPTH posts).

OPEN FLAGS carried in the symbol Description fields:
  - BOM-B of record names JXD1-0001NL (TAB-UP); the vendored asset is
    JXD0-0001NL (TAB-DOWN) — owner tab-orientation/BOM decision before
    sheet-07 layout (owner-queue 2026-07-16).
  - LAN9370 strap/clock/rail DETAIL (beyond the brief) owed from the full
    datasheet or the LAN9371/72 public family docs at sheet-06 capture.
  - Both 3D STEPs vendored; footprint<->3D alignment eyeball = GUI glance
    item (noted in each footprint descr).
Post-fix gate: cec-ent-net high=0 (medium/low pre-existing classes tracked,
not gating). Test suite 11/11.

ADDENDUM (same day, later): JXD1-0001NL SUPERSEDES JXD0-0001NL.
Owner supplied the UL JXD1 export + manufacturer STEP and ruled TAB-UP
preferred (matches BOM-B of record). Land comparison (pad-by-pad, aligned at
P1): the two variants' footprints are GENUINELY DIFFERENT (pin-numbering
order around the field, LED-row offsets, post/shield-leg pattern) — no
cross-substitution. Actions: JXD0 symbol/footprint/STEP REMOVED from
cec-ent-net (git history retains them); JXD1 vendored with (a) UL's
alternate-body unit _1_2 dropped (duplicate pin set, not used by platform
convention), (b) all pins typed passive, (c) SH1/SH2 pins ADDED to the
symbol and the footprint's shield legs CORRECTED from UL's NPTH modeling to
PLATED pads (drill 1.6764 / pad 2.5) per the platform FTP shield-to-GND
discipline, (d) manufacturer 3D STEP attached. Audit high=0; pin-count
fixture unchanged at 187 (16 out, 16 in); all pins on-grid.

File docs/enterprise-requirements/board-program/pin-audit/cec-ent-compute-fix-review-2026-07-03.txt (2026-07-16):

# cec_sym_audit --fix review for lib/cec-ent-compute.kicad_sym
# 4 high-confidence change(s)

MPFS095T_FCVG484: pin H11 'SPI_EN': bidirectional -> input  (EN: enable/control pin (EN/ENABLE) (currently 'bidirectional'))
MPFS095T_FCVG484: pin H7 'DEVRST_N': bidirectional -> input  (RST: reset pin (RST/nRST/DEVRST) -- verify if this part can itself drive a reset OUTPUT to other devices (currently 'bidirectional'))
MPFS095T_FCVG484: pin L3 'MSS_DDR_CS0': bidirectional -> input  (CS: chip-select pin (CS/nCS) -- orientation-dependent, verify against the datasheet if this part is the bus MASTER (a master-side CS is normally an output) (currently 'bidirectional'))
MPFS095T_FCVG484: pin M3 'MSS_DDR_CS1': bidirectional -> input  (CS: chip-select pin (CS/nCS) -- orientation-dependent, verify against the datasheet if this part is the bus MASTER (a master-side CS is normally an output) (currently 'bidirectional'))

# HAND REVIEW (2026-07-03, orchestrator): the two CS proposals above were
# OVERRIDDEN input -> output after review. The MPFS MSS is the DDR bus MASTER
# (its DDR controller drives chip-select toward the DRAM), so a master-side CS
# is an output -- exactly the orientation caveat the auditor itself attached.
# SPI_EN and DEVRST_N stand as input (system-controller boot-config input and
# device reset input per DS60001692E).
MPFS095T_FCVG484: pin L3 'MSS_DDR_CS0': input -> output  (hand override, DDR master)
MPFS095T_FCVG484: pin M3 'MSS_DDR_CS1': input -> output  (hand override, DDR master)

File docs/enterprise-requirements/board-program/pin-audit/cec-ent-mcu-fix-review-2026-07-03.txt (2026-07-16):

# cec_sym_audit --fix review for lib/cec-ent-mcu.kicad_sym
# 170 high-confidence change(s)

ESP32-P4: pin 9 'VDD_LP': unspecified -> power_in  (VDD: supply-rail pin (VDD family))
ESP32-P4: pin 21 'VDD_IO_0': unspecified -> power_in  (VDD: supply-rail pin (VDD family))
ESP32-P4: pin 26 'VDD_HP_0': unspecified -> power_in  (VDD: supply-rail pin (VDD family))
ESP32-P4: pin 27 'FLASH_CS': unspecified -> input  (CS: chip-select pin (CS/nCS) -- orientation-dependent, verify against the datasheet if this part is the bus MASTER (a master-side CS is normally an output))
ESP32-P4: pin 30 'VDD_FLASHIO': unspecified -> power_in  (VDD: supply-rail pin (VDD family))
ESP32-P4: pin 41 'VDD_MIPI_DPHY': unspecified -> power_in  (VDD: supply-rail pin (VDD family))
ESP32-P4: pin 51 'VDD_USBPHY': unspecified -> power_in  (VDD: supply-rail pin (VDD family))
ESP32-P4: pin 54 'VDD_HP_1': unspecified -> power_in  (VDD: supply-rail pin (VDD family))
ESP32-P4: pin 59 'VDD_PSRAM_0': unspecified -> power_in  (VDD: supply-rail pin (VDD family))
ESP32-P4: pin 62 'VDD_IO_4': unspecified -> power_in  (VDD: supply-rail pin (VDD family))
ESP32-P4: pin 67 'VDD_PSRAM_1': unspecified -> power_in  (VDD: supply-rail pin (VDD family))
ESP32-P4: pin 71 'VDDO_FLASH': unspecified -> power_in  (VDD: supply-rail pin (VDD family))
ESP32-P4: pin 72 'VDDO_PSRAM': unspecified -> power_in  (VDD: supply-rail pin (VDD family))
ESP32-P4: pin 73 'VDDO_3': unspecified -> power_in  (VDD: supply-rail pin (VDD family))
ESP32-P4: pin 74 'VDDO_4': unspecified -> power_in  (VDD: supply-rail pin (VDD family))
ESP32-P4: pin 75 'VDD_LDO': unspecified -> power_in  (VDD: supply-rail pin (VDD family))
ESP32-P4: pin 76 'VDD_HP_2': unspecified -> power_in  (VDD: supply-rail pin (VDD family))
ESP32-P4: pin 77 'VDD_DCDCC': unspecified -> power_in  (VDD: supply-rail pin (VDD family))
ESP32-P4: pin 79 'EN_DCDC': unspecified -> input  (EN: enable/control pin (EN/ENABLE))
ESP32-P4: pin 85 'VDD_IO_5': unspecified -> power_in  (VDD: supply-rail pin (VDD family))
ESP32-P4: pin 91 'VDD_HP_3': unspecified -> power_in  (VDD: supply-rail pin (VDD family))
ESP32-P4: pin 96 'VDD_IO_6': unspecified -> power_in  (VDD: supply-rail pin (VDD family))
ESP32-P4: pin 101 'VDD_ANA': unspecified -> power_in  (VDD: supply-rail pin (VDD family))
ESP32-P4: pin 102 'VDD_BAT': unspecified -> power_in  (VDD: supply-rail pin (VDD family))
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

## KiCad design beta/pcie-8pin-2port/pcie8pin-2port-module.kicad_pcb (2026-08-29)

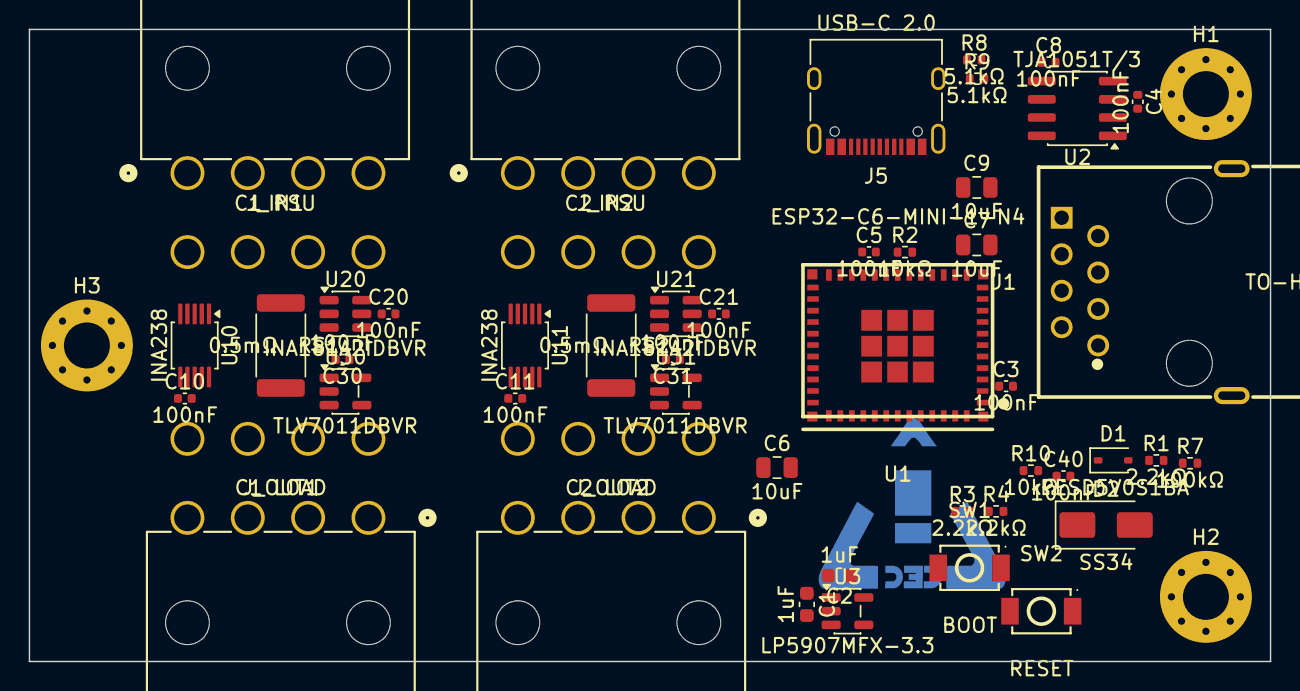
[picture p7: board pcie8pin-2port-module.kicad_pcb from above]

Board: 4 copper layers, 86.4 x 44.0 mm, 49 parts (1 on the bottom side), 28 nets, no tracks yet.

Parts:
C1, C2: 1uF; C_0603_1608Metric
C3, C4, C5, C8, C10, C11, C20, C21, C30, C31, C40: 100nF; C_0402_1005Metric
C6, C7, C9: 10uF; C_0805_2012Metric
D1: PESD5V0S1BA; D_SOD-323
D2: SS34; D_SMA
H1, H2, H3: MountingHole_3.2mm_M3_Pad_Via
J1: TO-HUB; RJ45_FTP_Shielded_Horizontal
J5: USB-C 2.0; USB_C_Receptacle_XKB_U262-16XN-4BVC11
J_IN1: C1 PSU; Molex_Mini-Fit_Jr_45586_2x04_P4.20mm_Horizontal
J_IN2: C2 PSU; Molex_Mini-Fit_Jr_45586_2x04_P4.20mm_Horizontal
J_OUT1: C1 LOAD; Molex_Mini-Fit_Jr_45586_2x04_P4.20mm_Horizontal
J_OUT2: C2 LOAD; Molex_Mini-Fit_Jr_45586_2x04_P4.20mm_Horizontal
LOGO1: CEC_Logo_Copper
R1, R3, R4: 2.2kΩ; R_0402_1005Metric
R2, R10: 10kΩ; R_0402_1005Metric
R7: 100kΩ; R_0402_1005Metric
R8, R9: 5.1kΩ; R_0402_1005Metric
RS1, RS2: 0.5mΩ; R_2512_6332Metric
SW1: BOOT; TS-1088-AR02016
SW2: RESET; TS-1088-AR02016
U1: ESP32-C6-MINI-1-N4; ESP32-C6-MINI-1
U2: TJA1051T/3; SOIC-8_3.9x4.9mm_P1.27mm
U3: LP5907MFX-3.3; SOT-23-5
U10, U11: INA238; VSSOP-10_3x3mm_P0.5mm
U20, U21: INA181A2IDBVR; SOT-23-6
U30, U31: TLV7011DBVR; SOT-23-5

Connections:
+3V3: C2.1, C3.1, C7.1, C8.1, C10.1, C11.1, C20.1, C21.1, C30.1, C31.1, R2.1, R3.2, R4.2, U1.3, U2.5, U3.5, U10.6, U11.2, U11.6, U20.6, U21.6, U30.5, U31.5
+5VSB: C1.1, C4.1, C6.1, C8.2, D2.1, J1.1, U2.3, U3.1, U3.3
/CAN_H: J1.3, U2.7
/CAN_L: J1.6, U2.6
/CAN_RX: U1.27, U2.4
/CAN_TX: U1.26, U2.1
/DETAMPC1: U20.1, U30.3
/DETAMPC2: U21.1, U31.3
/DETC1: U1.28, U30.1
/DETC2: U1.29, U31.1
/DETECT: D1.1, J1.8, R1.1, R7.1
/DETECT_SENSE: R7.2, U1.12
/EN: C5.1, R2.2, SW2.2, U1.8
/GPIO0: SW1.2, U1.23
/I2C_SCL: R4.1, U1.25, U10.5, U11.5
/I2C_SDA: R3.1, U1.24, U10.4, U11.4
/SENSEC1_HI: J_IN1.1, J_IN1.2, J_IN1.3, RS1.1, U10.10, U20.3
/SENSEC1_LO: J_OUT1.1, J_OUT1.2, J_OUT1.3, RS1.2, U10.8, U10.9, U20.4
/SENSEC2_HI: J_IN2.1, J_IN2.2, J_IN2.3, RS2.1, U11.10, U21.3
/SENSEC2_LO: J_OUT2.1, J_OUT2.2, J_OUT2.3, RS2.2, U11.8, U11.9, U21.4
/THRESH: C40.1, R10.2, U30.4, U31.4
/THRESH_PWM: R10.1, U1.19
/USB_CC1: J5.A5, R8.1
/USB_CC2: J5.B5, R9.1
/USB_DM: J5.A7, J5.B7, U1.17
/USB_DP: J5.A6, J5.B6, U1.18
/VBUS: C9.1, D2.2, J5.A4, J5.A9, J5.B4, J5.B9
GND: C1.2, C2.2, C3.2, C4.2, C5.2, C6.2, C7.2, C9.2, C10.2, C11.2, C20.2, C21.2, C30.2, C31.2, C40.2, D1.2, H1.1, H2.1, H3.1, J1.2, J1.SH1, J1.SH2, J5.A1, J5.A12, J5.B1, J5.B12, J5.S1, J_IN1.4, J_IN1.5, J_IN1.6, J_IN1.7, J_IN1.8, J_IN2.4, J_IN2.5, J_IN2.6, J_IN2.7, J_IN2.8, J_OUT1.4, J_OUT1.5, J_OUT1.6, J_OUT1.7, J_OUT1.8, J_OUT2.4, J_OUT2.5, J_OUT2.6, J_OUT2.7, J_OUT2.8, R1.2, R8.2, R9.2, SW1.1, SW2.1, U1.1, U1.2, U1.11, U1.14, U1.36, U1.37, U1.38, U1.39, U1.40, U1.41, U1.42, U1.43, U1.44, U1.45, U1.46, U1.47, U1.48, U1.49, U1.50, U1.51, U1.52, U1.53, U2.2, U2.8, U3.2, U10.1, U10.2, U10.7, U11.1, U11.7, U20.2, U20.5, U21.2, U21.5, U30.2, U31.2

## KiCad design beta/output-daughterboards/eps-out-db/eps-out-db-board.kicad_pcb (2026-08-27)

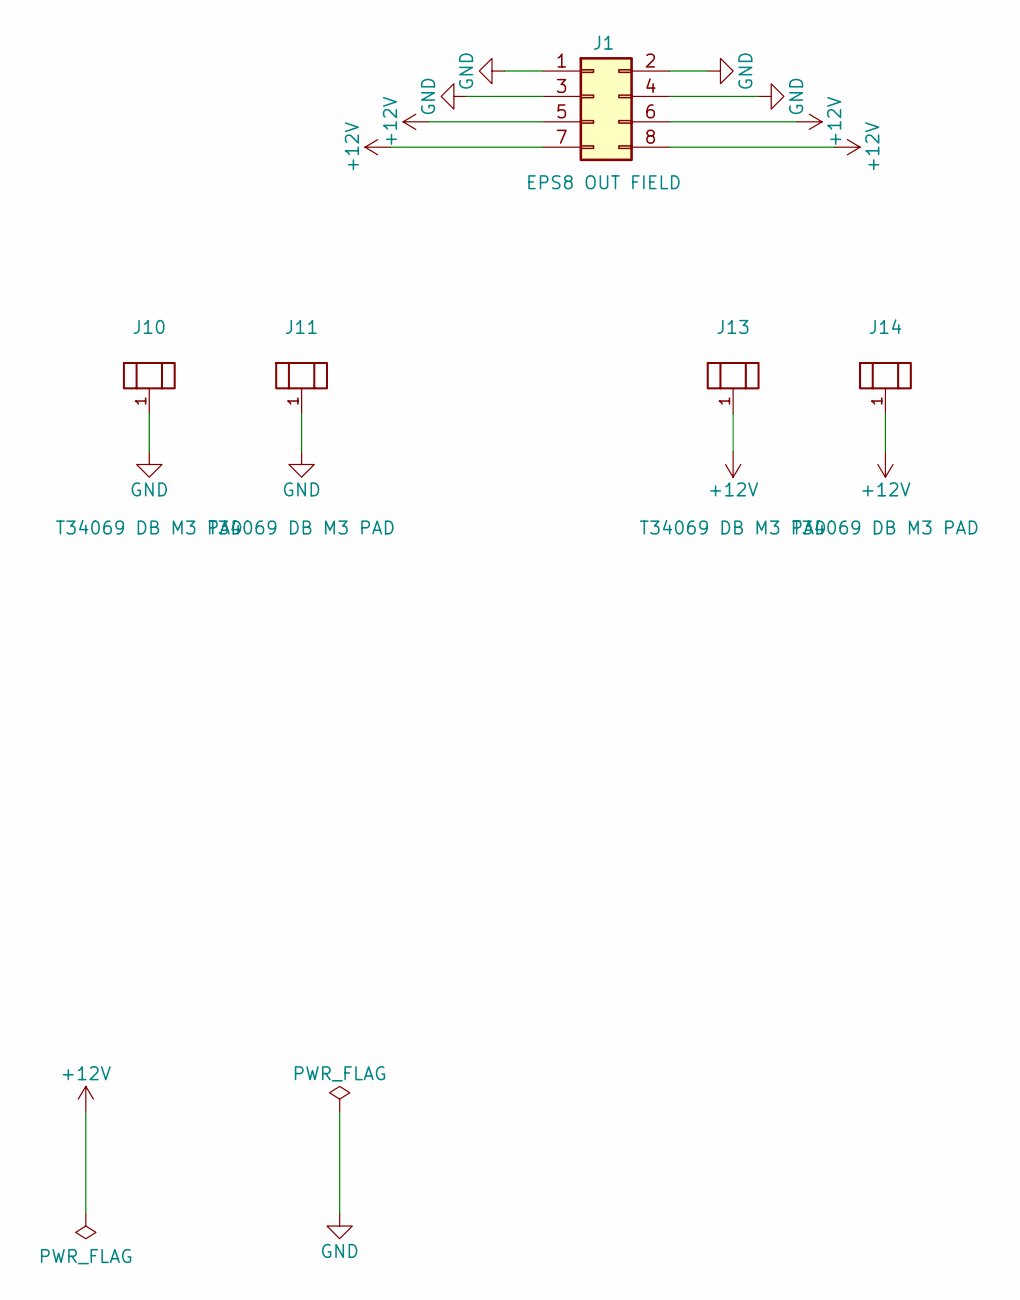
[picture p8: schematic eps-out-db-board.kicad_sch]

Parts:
J1: EPS8 OUT FIELD; EPS8_Daughterboard_Field_P4.20mm
J10, J11, J13, J14: T34069 DB M3 PAD; XFCN_T34069_Daughterboard_BoltPad_M3_PROVISIONAL

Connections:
+12V: J1.5, J1.6, J1.7, J1.8, J13.1, J14.1
GND: J1.1, J1.2, J1.3, J1.4, J10.1, J11.1

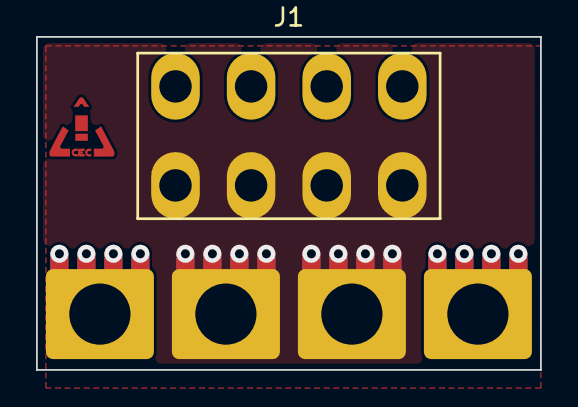
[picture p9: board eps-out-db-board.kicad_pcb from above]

Board: 4 copper layers, 28.0 x 18.5 mm, 6 parts (0 on the bottom side), 2 nets.

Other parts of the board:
LOGO1: CEC_Logo_Copper_Small

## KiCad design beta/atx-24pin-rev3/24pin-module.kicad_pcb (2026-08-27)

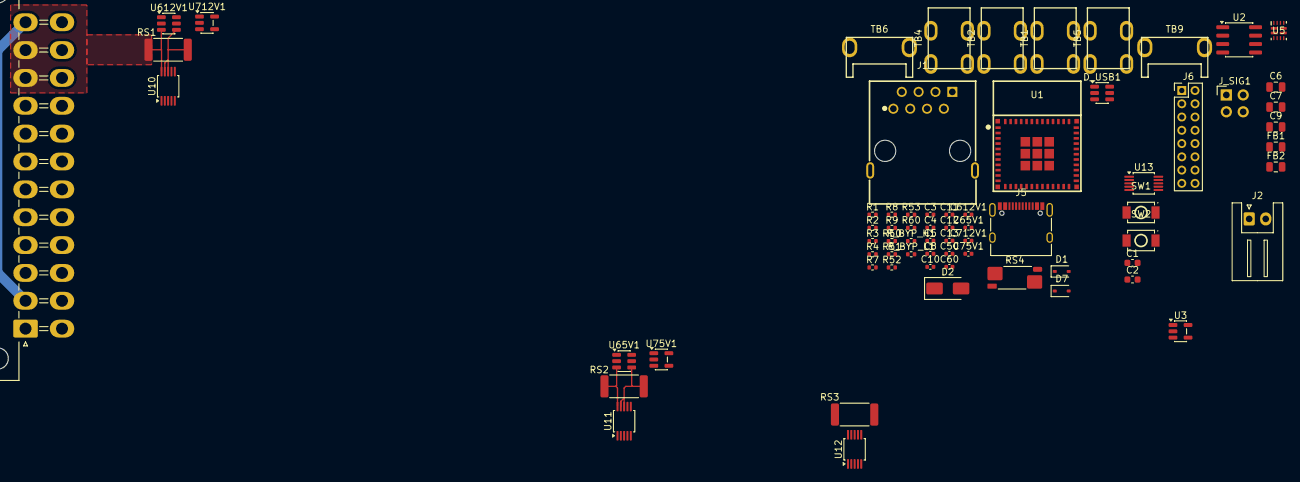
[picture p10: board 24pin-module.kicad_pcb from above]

Board: 4 copper layers, 69 parts (0 on the bottom side), 44 nets.

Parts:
C1, C2: 1uF; C_0603_1608Metric
C3, C4, C5, C8, C10, C11, C12, C13, C60, C65V1, C75V1, C612V1, C712V1: 100nF; C_0402_1005Metric
C6, C7, C9: 10uF; C_0805_2012Metric
C50: 2u2; C_0402_1005Metric
D1, D7: PESD5V0S1BA; D_SOD-323
D2: SS34; D_SMA
D_USB1: USBLC6-2SC6; SOT-23-6
FB1: 600R@100MHz FB (MPZ2012S601AT000); C_0805_2012Metric
FB2: 0R (FB position, populate on EMC evidence); C_0805_2012Metric
J1: TO-HUB; RJ45_FTP_Shielded_Horizontal
J2: TO-HUB-PWR; JST_XH_S2B-XH-A_1x02_P2.50mm_Horizontal
J3: ATX-24 PSU; Molex_Mini-Fit_Jr_5569-24A1_2x12_P4.20mm_Horizontal
J5: USB-C 2.0; USB_C_Receptacle_XKB_U262-16XN-4BVC11
J6: TO-HUB-STACK; PinHeader_2x08_P2.00mm_Vertical
J_SIG1: SSQ-102-03-G-D; Samtec_SSQ-102-03-G-D_2x02_P2.54mm_Vertical
R1, R3, R4: 2.2kΩ; R_0402_1005Metric
R2, R51, R60: 10kΩ; R_0402_1005Metric
R7, R52: 100kΩ; R_0402_1005Metric
R8, R9: 5.1kΩ; R_0402_1005Metric
R50: 20kΩ; R_0402_1005Metric
R53: 33kΩ; R_0402_1005Metric
RS1, RS2, RS3: 2mΩ; R_2512_6332Metric
RS4: 25mΩ; R_Shunt_Vishay_WSK2512_6332Metric_T1.19mm
R_BYP_H1: 0Ω; R_0402_1005Metric
R_BYP_L1: 0Ω; R_0402_1005Metric
SW1: BOOT; TS-1088-AR02016
SW2: RESET; TS-1088-AR02016
TB1, TB2, TB4, TB5: XFCN T34069; XFCN_T34069_THT_M3_40A
TB6, TB9: TTR32100127-0600; XFCN_TTR32100127-0600_THT_M3_60A
U1: ESP32-C6-MINI-1-N4; ESP32-C6-MINI-1
U2: TJA1051T/3; SOIC-8_3.9x4.9mm_P1.27mm
U3: LP5907MFX-3.3; SOT-23-5
U5: TPS2121RUXR; RUX0012A
U10, U11, U12, U13: INA238; VSSOP-10_3x3mm_P0.5mm
U65V1, U612V1: INA181A2IDBVR; SOT-23-6
U75V1, U712V1: TLV7011DBVR; SOT-23-5

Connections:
+3V3: C2.1, C3.1, C7.1, C8.1, C10.1, C11.1, C12.1, C13.1, C65V1.1, C75V1.1, C612V1.1, C712V1.1, R2.1, R4.2, R51.2, U1.3 (3V3), U2.5 (VIO), U3.5 (OUT), U11.2 (A0), U12.1 (A1), U13.1 (A1), U13.2 (A0), U13.6 (VS), U65V1.6 (VS), U75V1.5 (VCC), U612V1.6 (VS), U712V1.5 (VCC)
+5VSB: J3.9 (+5VSB), RS4.1 (I1), U5.2 (IN2)
+5V_MAIN: R52.1, RS2.2, TB2.1, U5.7 (IN1), U11.8 (Vbus), U11.9 (Vin-), U65V1.4 (IN-)
+5V_SYS: C1.1, C4.1, C6.1, D2.1 (K), FB2.1, U2.3 (VCC), U3.1 (IN), U3.3 (EN), U5.1 (OUT), U5.8 (OUT)
/+5V_SYS_PORT: FB2.2, J2.1 (VCC), J6.1 (+5V_SYS), J6.2 (+5V_SYS), J6.3 (+5V_SYS)
/CAN_H: R_BYP_H1.2, U2.7 (CANH)
/CAN_H_BUS: J1.3 (CAN1_H), J6.5 (CAN_H), R_BYP_H1.1
/CAN_L: R_BYP_L1.2, U2.6 (CANL)
/CAN_L_BUS: J1.6 (CAN1_L), J6.6 (CAN_L), R_BYP_L1.1
/CAN_RX: U1.27 (IO21), U2.4 (RXD)
/CAN_TX: U1.26 (IO20), U2.1 (TXD)
/DET5V: U1.29 (IO23), U75V1.1 (OUT)
/DET12V: U1.28 (IO22), U712V1.1 (OUT)
/DETAMP5V: U65V1.1 (OUT), U75V1.3 (IN+)
/DETAMP12V: U612V1.1 (OUT), U712V1.3 (IN+)
/DETECT: D1.1 (K), J1.8 (DETECT), J6.11 (DETECT), R1.1, R7.2
/DETECT_SENSE: R7.1, U1.12 (IO0)
/EN: C5.1, R2.2, SW2.2, U1.8 (EN)
/GPIO0: SW1.2, U1.23 (IO9)
/I2C_SCL: R4.1, U1.25 (IO19), U10.5 (SCL), U11.5 (SCL), U12.5 (SCL), U13.5 (SCL)
/I2C_SDA: R3.1 (~_1), U1.24 (IO18), U10.4 (SDA), U11.4 (SDA), U12.4 (SDA), U13.4 (SDA)
/ILIM: R50.1, U5.10 (ILM)
/MUX_ST: R51.1, U5.9 (ST)
/SENSE3V3_HI: J3.1 (+3.3V), J3.2 (+3.3V), J3.12 (+3.3V), J3.13 (+3.3V), RS3.1, U12.10 (Vin+)
/SENSE3V3_LO: RS3.2, TB4.1, U12.8 (Vbus), U12.9 (Vin-)
/SENSE5VSB_HI: RS4.2 (S1), U13.10 (Vin+)
/SENSE5VSB_LO: RS4.4 (I2), TB5.1, U13.8 (Vbus)
/SENSE5VSB_LO_KELVIN: RS4.3 (S2), U13.9 (Vin-)
/SENSE5V_HI: J3.4 (+5V), J3.6 (+5V), J3.21 (+5V), J3.22 (+5V), J3.23 (+5V), RS2.1, U11.10 (Vin+), U65V1.3 (IN+)
/SENSE12V_HI: J3.10 (+12V), J3.11 (+12V), RS1.1, U10.10 (Vin+), U612V1.3 (IN+)
/SENSE12V_LO: RS1.2, TB1.1, U10.8 (Vbus), U10.9 (Vin-), U612V1.4 (IN-)
/SS: C50.1, U5.11 (SS)
/THRESH: C60.1, R60.2, U75V1.4 (IN), U712V1.4 (IN)
/THRESH_PWM: R60.1, U1.19 (IO14)
/USB_CC1: J5.A5 (CC1), R8.1
/USB_CC2: J5.B5 (CC2), R9.1
/USB_DM: D_USB1.3 (I/O2), D_USB1.4 (I/O2), J5.A7 (D-), J5.B7 (D-), U1.17 (IO12)
/USB_DP: D_USB1.1 (I/O1), D_USB1.6 (I/O1), J5.A6 (D+), J5.B6 (D+), U1.18 (IO13)
/VBUS: C9.1, D2.2 (A), FB1.2
/VBUS_RAW: D7.1 (K), D_USB1.5 (VBUS), FB1.1, J5.A4 (VBUS), J5.A9 (VBUS), J5.B4 (VBUS), J5.B9 (VBUS)
GND: C1.2, C2.2, C3.2, C4.2, C5.2, C6.2, C7.2, C8.2, C9.2, C10.2, C11.2, C12.2, C13.2, C50.2, C60.2, C65V1.2, C75V1.2, C612V1.2, C712V1.2, D1.2 (A), D7.2 (A), D_USB1.2 (GND), J1.2 (GND), J1.SH1, J1.SH2, J2.2 (GND), J3.3 (GND), J3.5 (GND), J3.7 (GND), J3.15 (GND), J3.17 (GND), J3.18 (GND), J3.19 (GND), J3.24 (GND), J5.A1 (GND), J5.A12 (GND), J5.B1 (GND), J5.B12 (GND), J5.S1 (SHIELD), J6.4 (GND), J6.7 (GND), J6.10 (GND), J6.12 (GND), J6.14 (GND), J6.15 (GND), J6.16 (GND), J_SIG1.4, R1.2, R8.2, R9.2, R50.2, R53.2, SW1.1, SW2.1, TB6.1, TB9.1, U1.1 (GND), U1.2 (GND), U1.11 (GND), U1.14 (GND), U1.36 (GND), U1.37 (GND), U1.38 (GND), U1.39 (GND), U1.40 (GND), U1.41 (GND), U1.42 (GND), U1.43 (GND), U1.44 (GND), U1.45 (GND), U1.46 (GND), U1.47 (GND), U1.48 (GND), U1.49 (GND), U1.50 (GND), U1.51 (GND), U1.52 (GND), U1.53 (GND), U2.2 (GND), U2.8 (S), U3.2 (GND), U5.3 (CP2), U5.4 (OV2), U5.5 (OV1), U5.12 (GND), U10.1 (A1), U10.2 (A0), U11.1 (A1), U12.2 (A0), U12.7 (GND), U13.7 (GND), U65V1.2 (GND), U65V1.5 (REF), U75V1.2 (VEE), U612V1.2 (GND), U612V1.5 (REF), U712V1.2 (VEE)
unnamed: R52.2, R53.1, U5.6 (PR1)
unnamed: U10.7 (GND), U11.6 (VS)
unnamed: U11.7 (GND), U12.6 (VS)

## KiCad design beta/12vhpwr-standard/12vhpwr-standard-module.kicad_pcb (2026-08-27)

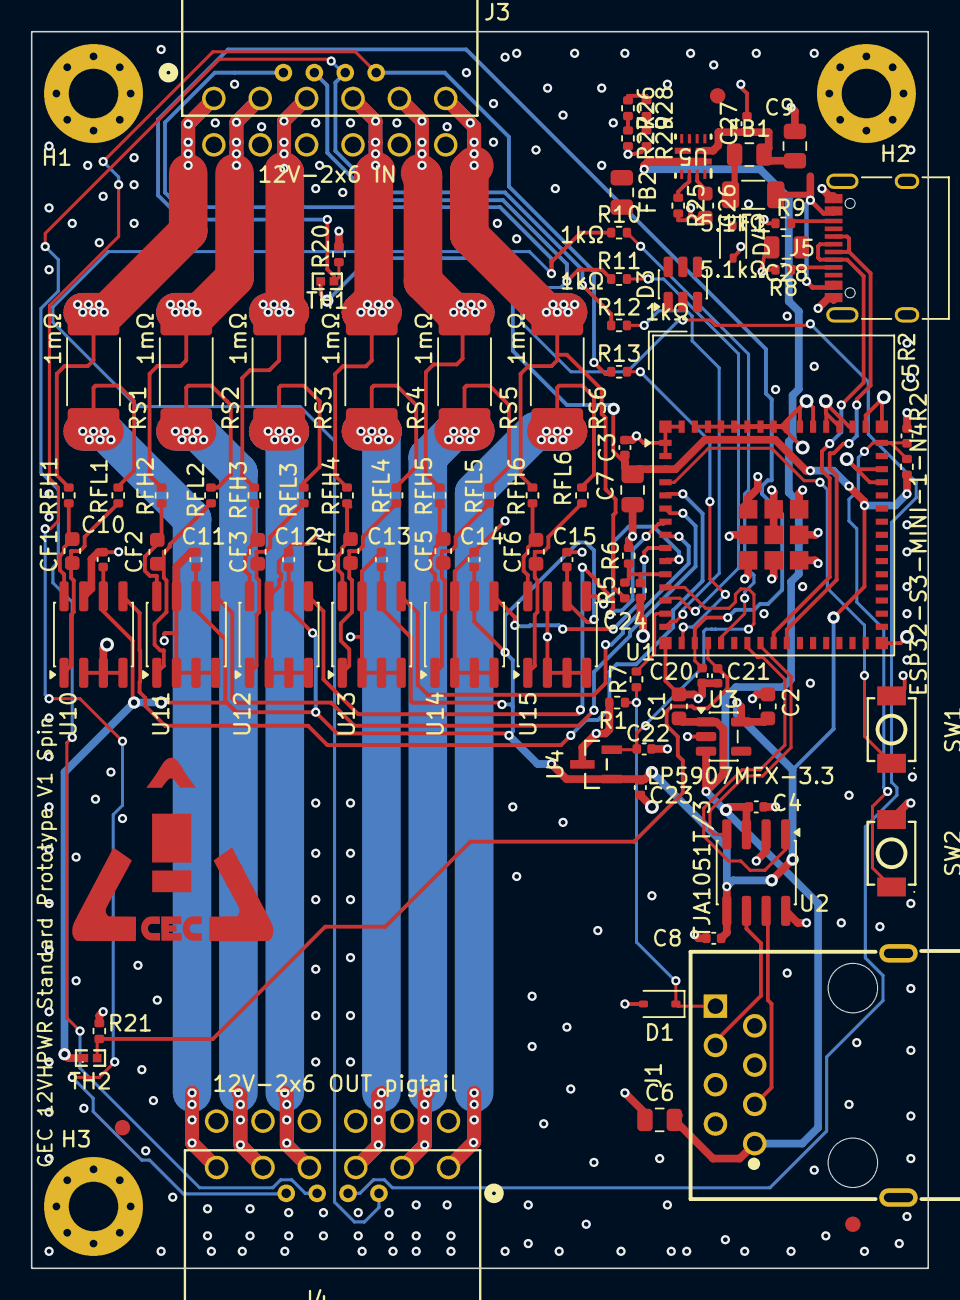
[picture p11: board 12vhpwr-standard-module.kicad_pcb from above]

Board: 4 copper layers, 58.0 x 80.0 mm, 97 parts (0 on the bottom side), 65 nets.

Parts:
C1, C2: 1uF; C_0603_1608Metric
C3, C4, C5, C8, C10, C11, C12, C13, C14, C15, C20, C21, C22, C23, C27: 100nF; C_0402_1005Metric
C6, C7, C9, C28: 10uF; C_0805_2012Metric
C24: 1nF; C_0402_1005Metric
C26: 2.2uF; C_0603_1608Metric
CF1, CF2, CF3, CF4, CF5, CF6: 470nF; C_0603_1608Metric
D1, D4: PESD5V0S1BA; D_SOD-323
D3: USBLC6-2SC6; SOT-23-6
F1: 750mA/16V PTC; R_1206_3216Metric
FB1: MPZ2012S601AT000; C_0805_2012Metric
FB2: 0R; C_0805_2012Metric
FID1, FID2, FID3: Fiducial_1mm_Mask2mm
H1, H2, H3: MountingHole_3.2mm_M3_Pad_Via
J1: TO-HUB; RJ45_FTP_Shielded_Horizontal
J3: 12V-2x6 IN; CEC_12V2x6_Horizontal
J4: 12V-2x6 OUT pigtail; CEC_12V2x6_Horizontal
J5: USB-C 2.0; USB_C_Receptacle_XKB_U262-16XN-4BVC11
LOGO1: CEC_Logo_Copper
R1: 2.2kΩ; R_0402_1005Metric
R2, R6, R20, R21, R27: 10kΩ; R_0402_1005Metric
R5: 47kΩ; R_0402_1005Metric
R7, R25, R28: 100kΩ; R_0402_1005Metric
R8, R9: 5.1kΩ; R_0402_1005Metric
R10, R11, R12, R13: 1kΩ; R_0402_1005Metric
R26: 43.2kΩ; R_0402_1005Metric
R29: 33kΩ; R_0402_1005Metric
RFH1, RFH2, RFH3, RFH4, RFH5, RFH6: 10Ω; R_0402_1005Metric
RFL1, RFL2, RFL3, RFL4, RFL5, RFL6: 10Ω; R_0402_1005Metric
RS1, RS2, RS3, RS4, RS5, RS6: 1mΩ; R_2512_6332Metric
SW1: BOOT; TS-1088-AR02016
SW2: RESET; TS-1088-AR02016
TH1, TH2: NTC 10k; NTC_0402_1005Metric
U1: ESP32-S3-MINI-1-N4R2; ESP32-S2-MINI-1_NoAntKeepout
U2: TJA1051T/3; SOIC-8_3.9x4.9mm_P1.27mm
U3: LP5907MFX-3.3; SOT-23-5
U4: REF3030; REF3030_DBZ3
U5: TPS2121RUXR; RUX0012A
U10, U11, U12, U13, U14, U15: INA240A3; SOIC-8_3.9x4.9mm_P1.27mm

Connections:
+3V3: C2.1, C3.1, C7.1, C8.1, C10.1, C11.1, C12.1, C13.1, C14.1, C15.1, C23.1, R2.1, TH1.1, TH2.1, U1.3 (3V3), U2.5 (VIO), U3.5 (OUT), U4.1 (IN), U10.6 (V+), U11.6 (V+), U12.6 (V+), U13.6 (V+), U14.6 (V+), U15.6 (V+)
+5VSB: C1.1, C4.1, C6.1, J1.1 (VCC), U2.3 (VCC), U3.1 (IN), U3.3 (EN), U5.1, U5.8
/08-usb/U5_ILM: R25.1, U5.10
/08-usb/U5_OV1: R26.2, R27.1, U5.5
/08-usb/U5_PR1: R28.2, R29.1, U5.6
/08-usb/U5_SS: C26.1, U5.11
/08-usb/VBUS_F: F1.2, FB1.1
/CAN_H: J1.3 (CAN1_H), U2.7 (CANH)
/CAN_L: J1.6 (CAN1_L), U2.6 (CANL)
/CAN_RX: U1.22 (IO18), U2.4 (RXD)
/CAN_TX: U1.21 (IO17), U2.1 (TXD)
/DETECT: D1.1 (K), J1.8 (DETECT), R1.1, R7.1
/DETECT_SENSE: R7.2, U1.14 (IO10)
/EN: C5.1, R2.2, SW2.2, U1.45 (EN)
/GPIO0: SW1.2, U1.4 (IO0)
/IN1_N: CF1.2, RFL1.2, U10.1 (-)
/IN1_P: CF1.1, RFH1.2, U10.8 (+)
/IN2_N: CF2.2, RFL2.2, U11.1 (-)
/IN2_P: CF2.1, RFH2.2, U11.8 (+)
/IN3_N: CF3.2, RFL3.2, U12.1 (-)
/IN3_P: CF3.1, RFH3.2, U12.8 (+)
/IN4_N: CF4.2, RFL4.2, U13.1 (-)
/IN4_P: CF4.1, RFH4.2, U13.8 (+)
/IN5_N: CF5.2, RFL5.2, U14.1 (-)
/IN5_P: CF5.1, RFH5.2, U14.8 (+)
/IN6_N: CF6.2, RFL6.2, U15.1 (-)
/IN6_P: CF6.1, RFH6.2, U15.8 (+)
/ISENSEP1: U1.5 (IO1), U10.5
/ISENSEP2: U1.6 (IO2), U11.5
/ISENSEP3: U1.7 (IO3), U12.5
/ISENSEP4: U1.8 (IO4), U13.5
/ISENSEP5: U1.9 (IO5), U14.5
/ISENSEP6: U1.10 (IO6), U15.5
/SB_CBL_PRES: J3.16 (SENSE), J4.16 (SENSE), R13.1
/SB_CBL_PRES_GPIO: R13.2, U1.16 (IO12)
/SB_PWR_STABLE: J3.15 (SENSE), J4.15 (SENSE), R12.1
/SB_PWR_STABLE_GPIO: R12.2, U1.15 (IO11)
/SB_SENSE0: J3.13 (SENSE), J4.13 (SENSE), R10.1
/SB_SENSE0_GPIO: R10.2, U1.19 (IO15)
/SB_SENSE1: J3.14 (SENSE), J4.14 (SENSE), R11.1
/SB_SENSE1_GPIO: R11.2, U1.13 (IO9)
/SENSEP1_HI: J3.1 (+12V), RFH1.1, RS1.1
/SENSEP1_LO: J4.6 (+12V), RFL1.1, RS1.2
/SENSEP2_HI: J3.2 (+12V), RFH2.1, RS2.1
/SENSEP2_LO: J4.5 (+12V), RFL2.1, RS2.2
/SENSEP3_HI: J3.3 (+12V), RFH3.1, RS3.1
/SENSEP3_LO: J4.4 (+12V), RFL3.1, RS3.2
/SENSEP4_HI: J3.4 (+12V), RFH4.1, RS4.1
/SENSEP4_LO: J4.3 (+12V), RFL4.1, RS4.2
/SENSEP5_HI: J3.5 (+12V), RFH5.1, RS5.1
/SENSEP5_LO: J4.2 (+12V), RFL5.1, RS5.2
/SENSEP6_HI: J3.6 (+12V), R5.1, RFH6.1, RS6.1
/SENSEP6_LO: J4.1 (+12V), RFL6.1, RS6.2
/TEMP1: C20.1, R20.1, TH1.2, U1.17 (IO13)
/TEMP2: C21.1, R21.1, TH2.2, U1.18 (IO14)
/USB_CC1: J5.A5 (CC1), R8.1
/USB_CC2: J5.B5 (CC2), R9.1
/USB_DM: D3.3, D3.4, J5.A7 (D-), J5.B7 (D-), U1.23 (USB_D-)
/USB_DP: D3.1, D3.6, J5.A6 (D+), J5.B6 (D+), U1.24 (USB_D+)
/VBUS: C9.1, C27.1, C28.1, FB1.2, U5.2
/VBUS_RAW: D3.5, D4.1, F1.1, J5.A4 (VBUS), J5.A9 (VBUS), J5.B4 (VBUS), J5.B9 (VBUS)
/VRAIL_DIV: C24.1, R5.2, R6.1, U1.11 (IO7)
/VREF: C22.1, U1.12 (IO8), U4.2 (OUT)
GND: C1.2, C2.2, C3.2, C4.2, C5.2, C6.2, C7.2, C8.2, C9.2, C10.2, C11.2, C12.2, C13.2, C14.2, C15.2, C20.2, C21.2, C22.2, C23.2, C24.2, C26.2, C27.2, C28.2, D1.2 (A), D3.2, D4.2, H1.1, H2.1, H3.1, J1.2 (GND), J1.SH1 (SHIELD), J1.SH2 (SHIELD), J3.7 (GND), J3.8 (GND), J3.9 (GND), J3.10 (GND), J3.11 (GND), J3.12 (GND), J4.7 (GND), J4.8 (GND), J4.9 (GND), J4.10 (GND), J4.11 (GND), J4.12 (GND), J5.A1 (GND), J5.A12 (GND), J5.B1 (GND), J5.B12 (GND), J5.S1 (SHIELD), R1.2, R6.2, R8.2, R9.2, R20.2, R21.2, R25.2, R27.2, R29.2, SW1.1, SW2.1, U1.1 (GND), U1.2 (GND), U1.42 (GND), U1.43 (GND), U1.46 (GND), U1.47 (GND), U1.48 (GND), U1.49 (GND), U1.50 (GND), U1.51 (GND), U1.52 (GND), U1.53 (GND), U1.54 (GND), U1.55 (GND), U1.56 (GND), U1.57 (GND), U1.58 (GND), U1.59 (GND), U1.60 (GND), U1.61 (GND), U1.62 (GND), U1.63 (GND), U1.64 (GND), U1.65 (GND), U2.2 (GND), U2.8 (S), U3.2 (GND), U4.3 (GND), U5.3, U5.4, U5.12, U10.2 (GND), U10.3 (REF2), U10.4 (GND), U10.7 (REF1), U11.2 (GND), U11.3 (REF2), U11.4 (GND), U11.7 (REF1), U12.2 (GND), U12.3 (REF2), U12.4 (GND), U12.7 (REF1), U13.2 (GND), U13.3 (REF2), U13.4 (GND), U13.7 (REF1), U14.2 (GND), U14.3 (REF2), U14.4 (GND), U14.7 (REF1), U15.2 (GND), U15.3 (REF2), U15.4 (GND), U15.7 (REF1)
VCC_RJ45: FB2.1, R26.1, R28.1, U5.7

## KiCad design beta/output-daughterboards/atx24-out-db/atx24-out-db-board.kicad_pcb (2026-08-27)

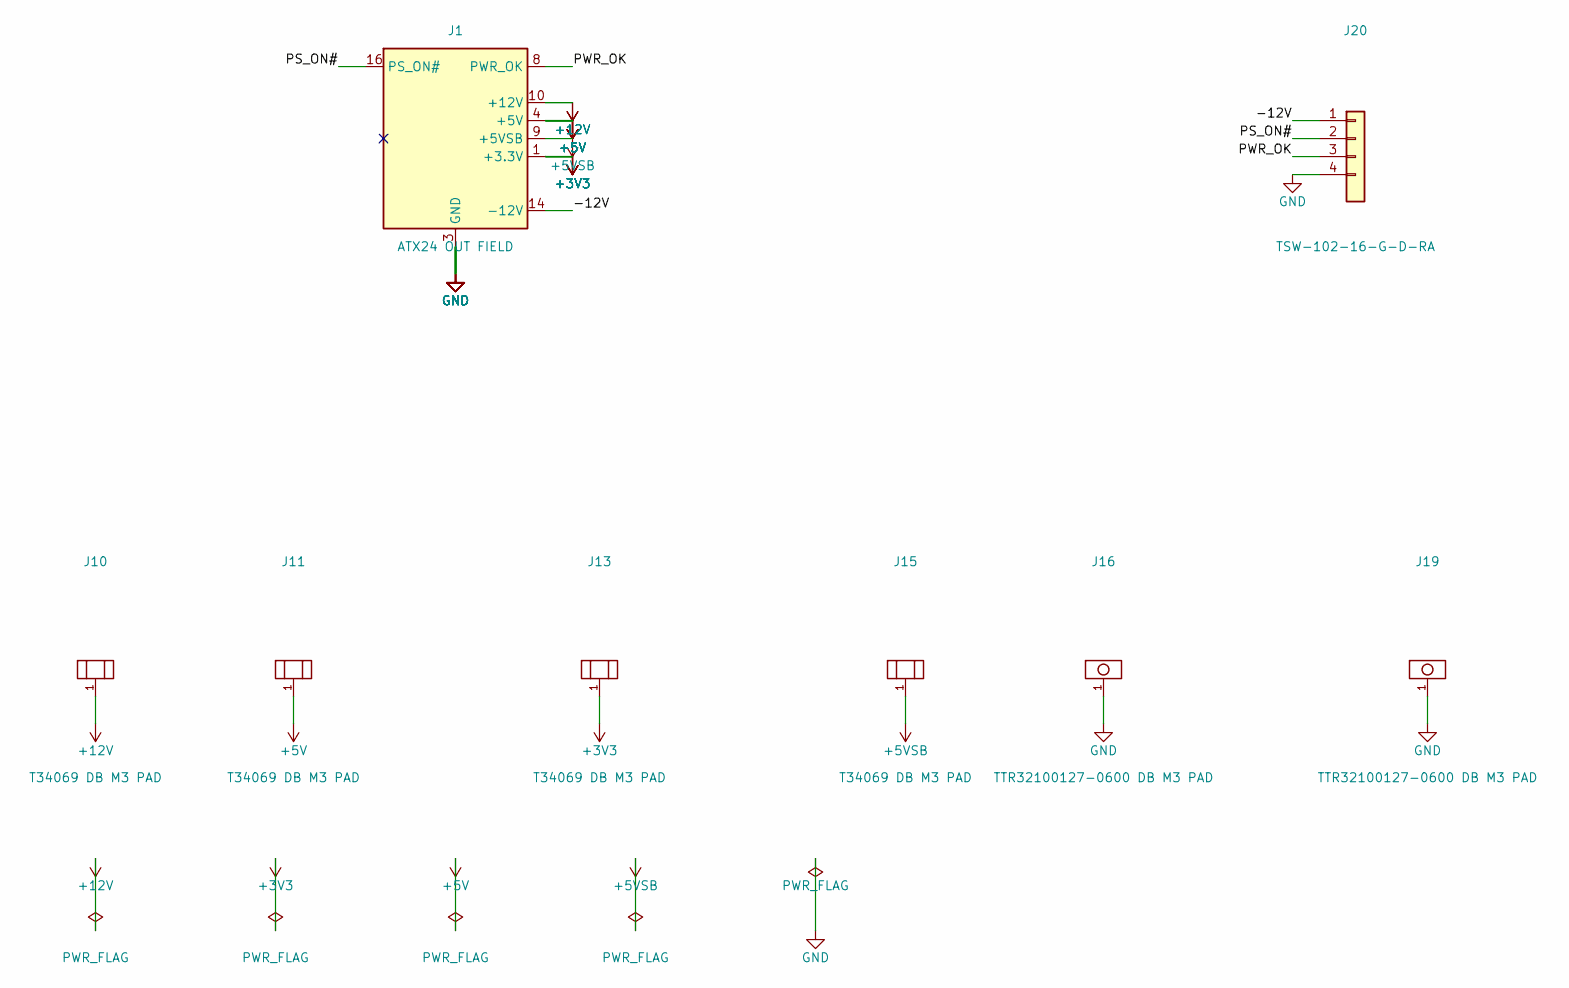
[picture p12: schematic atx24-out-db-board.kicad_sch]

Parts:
J1: ATX24 OUT FIELD; ATX24_Daughterboard_Field_P4.20mm
J10, J11, J13, J15: T34069 DB M3 PAD; XFCN_T34069_Daughterboard_BoltPad_M3_PROVISIONAL
J16, J19: TTR32100127-0600 DB M3 PAD; XFCN_TTR32100127-0600_Daughterboard_BoltPad_M3_PROVISIONAL
J20: TSW-102-16-G-D-RA; Samtec_TSW-102-16-G-D-RA_2x02_P2.54mm_Horizontal; MPN TSW-102-16-G-D-RA

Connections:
+3V3: J1.1 (+3.3V), J1.2 (+3.3V), J1.12 (+3.3V), J1.13 (+3.3V), J13.1
+5V: J1.4 (+5V), J1.6 (+5V), J1.21 (+5V), J1.22 (+5V), J1.23 (+5V), J11.1
+5VSB: J1.9 (+5VSB), J15.1
+12V: J1.10 (+12V), J1.11 (+12V), J10.1
/-12V: J1.14 (-12V), J20.1
/PS_ON#: J1.16 (PS_ON#), J20.2
/PWR_OK: J1.8 (PWR_OK), J20.3
GND: J1.3 (GND), J1.5 (GND), J1.7 (GND), J1.15 (GND), J1.17 (GND), J1.18 (GND), J1.19 (GND), J1.24 (GND), J16.1, J19.1, J20.4

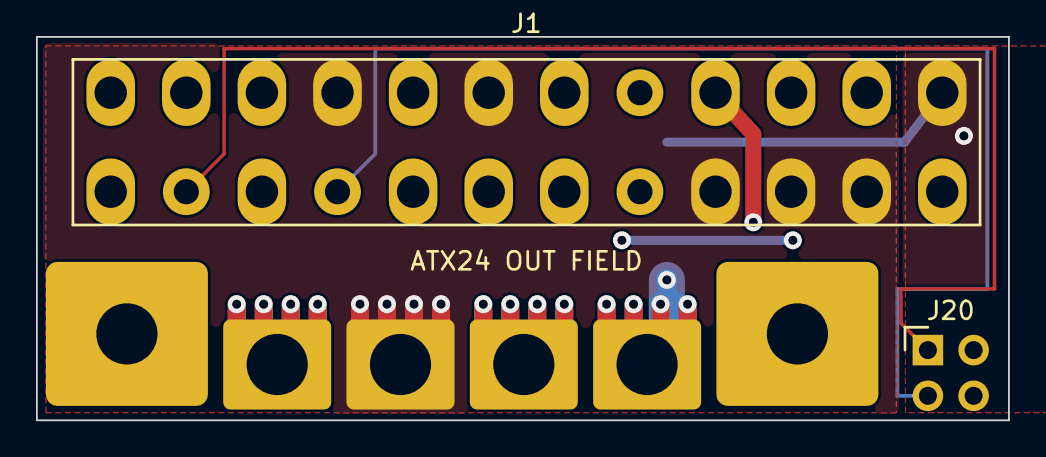
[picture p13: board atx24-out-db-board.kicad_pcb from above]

Board: 4 copper layers, 54.0 x 21.3 mm, 8 parts (0 on the bottom side), 8 nets.

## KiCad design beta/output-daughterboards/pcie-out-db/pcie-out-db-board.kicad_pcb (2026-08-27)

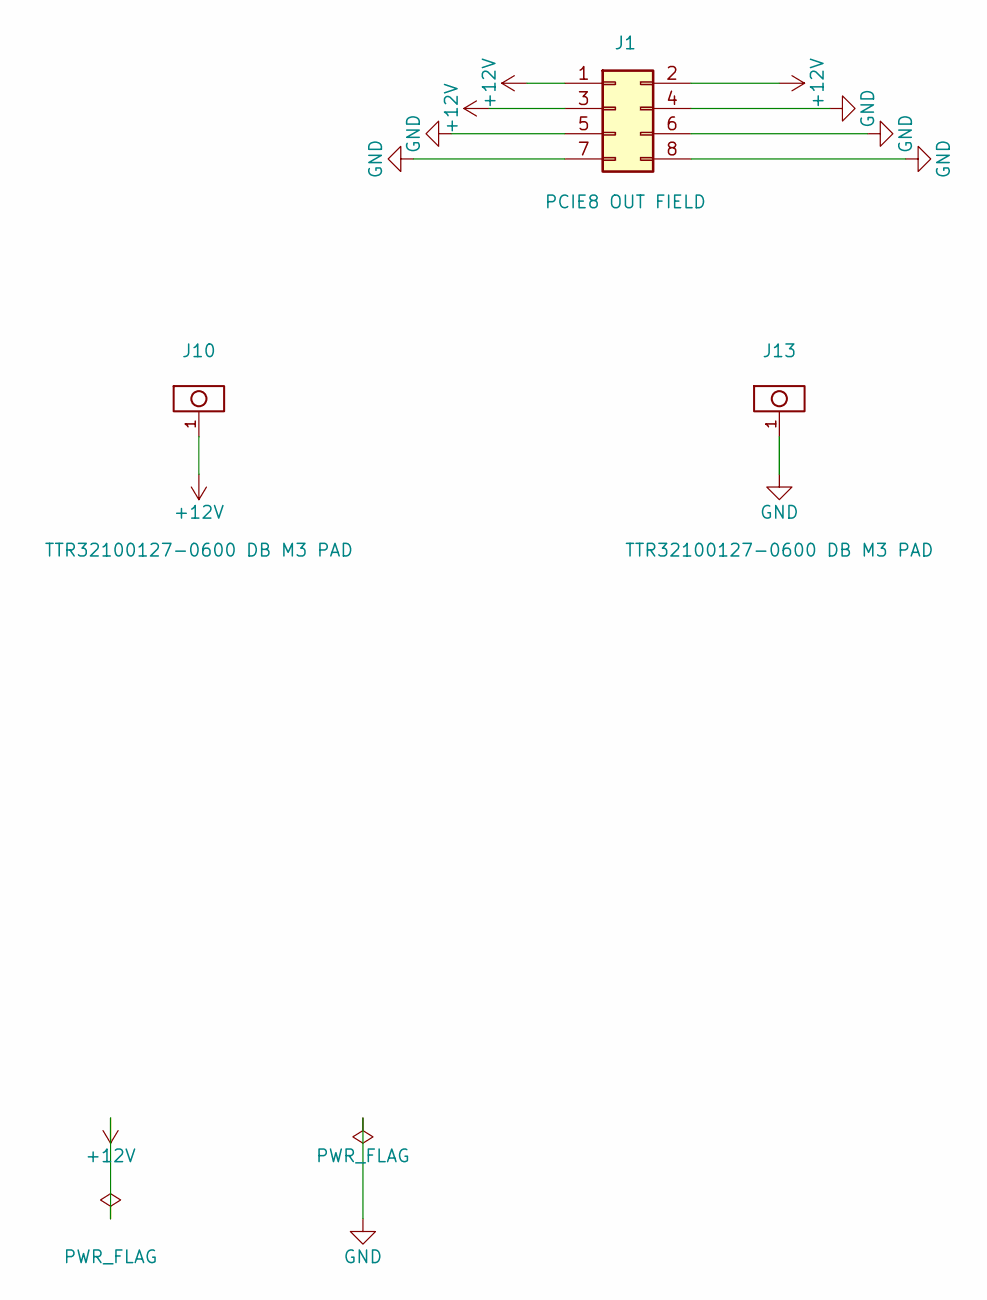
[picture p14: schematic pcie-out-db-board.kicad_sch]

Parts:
J1: PCIE8 OUT FIELD; PCIe8_Daughterboard_Field_P4.20mm
J10, J13: TTR32100127-0600 DB M3 PAD; XFCN_TTR32100127-0600_Daughterboard_BoltPad_M3_PROVISIONAL

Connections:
+12V: J1.1, J1.2, J1.3, J10.1
GND: J1.4, J1.5, J1.6, J1.7, J1.8, J13.1

Board: 4 copper layers, 3 parts (0 on the bottom side), 2 nets, no tracks yet.

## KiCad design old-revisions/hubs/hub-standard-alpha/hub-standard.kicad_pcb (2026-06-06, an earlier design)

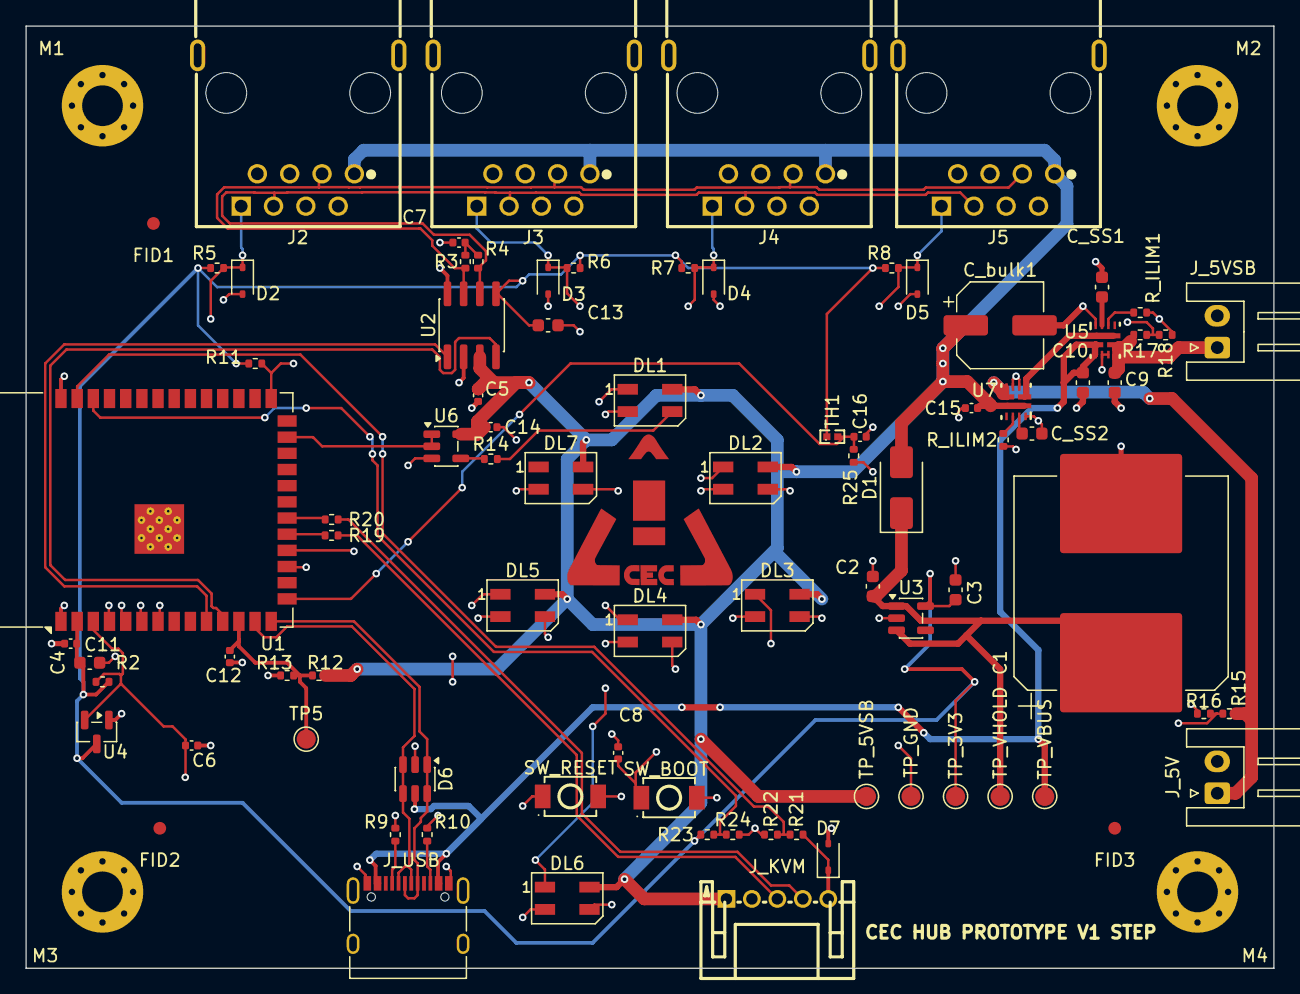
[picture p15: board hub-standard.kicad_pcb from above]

Board: 4 copper layers, 98.0 x 74.0 mm, 91 parts (0 on the bottom side), 47 nets.

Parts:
C1: 4700uF; CP_Elec_16x17.5
C2, C3, C9, C10: 1uF; C_0603_1608Metric
C4, C5, C6, C8, C14, C15, C16: 100nF; C_0402_1005Metric
C7: 4n7; C_0402_1005Metric
C11: 10uF; C_0603_1608Metric
C12: 10nF; C_0402_1005Metric
C13: 100nF; C_0603_1608Metric
C_SS1, C_SS2: 2.2uF; C_0603_1608Metric
C_bulk1: 470uF; CP_Elec_6.3x7.7
D1: SS14; D_SMA
D2, D3, D4, D5, D7: PESD5V0S1BA; D_SOD-323
D6: USBLC6-2SC6; SOT-23-6
DL1, DL2, DL3, DL4, DL5, DL6, DL7: SK6812MINI-E; LED_SK6812MINI_PLCC4_3.5x3.5mm_P1.75mm
FID1, FID2, FID3: Fiducial_1mm_Mask2mm
J2: PORT1; RJ45_FTP_Shielded_Horizontal
J3: PORT2; RJ45_FTP_Shielded_Horizontal
J4: PORT3; RJ45_FTP_Shielded_Horizontal
J5: PORT4; RJ45_FTP_Shielded_Horizontal
J_5V: MAIN_5V_IN; JST_XH_S2B-XH-A_1x02_P2.50mm_Horizontal
J_5VSB: 5VSB_IN; JST_XH_S2B-XH-A_1x02_P2.50mm_Horizontal
J_KVM: CEC_NANOKVM_AUX_5P; JST_PH_S5B-PH-K-S_1x05_P2.00mm_Horizontal
J_USB: USB-C; USB_C_Receptacle_XKB_U262-16XN-4BVC11
LOGO1: CEC_Logo_Copper
M1, M2, M3, M4: M3 Mount; MountingHole_3.2mm_M3_Pad_Via
R2, R5, R6, R7, R8, R11, R16, R18, R22, R24, R25: 10kΩ; R_0402_1005Metric
R3, R4: 60.4; R_0402_1005Metric
R9, R10: 5.1kΩ; R_0402_1005Metric
R12, R15, R17, R21, R23: 47kΩ; R_0402_1005Metric
R13: 27kΩ; R_0402_1005Metric
R14: 330Ω; R_0402_1005Metric
R19, R20: 33Ω; R_0402_1005Metric
R_ILIM1, R_ILIM2: 27kΩ; R_0402_1005Metric
SW_BOOT: SW_BOOT; TS-1088-AR02016
SW_RESET: SW_RST; TS-1088-AR02016
TH1: NTC 10k; NTC_0402_1005Metric
TP5: BLACKOUT; TestPoint_Pad_D1.5mm
TP_3V3: 3V3; TestPoint_Pad_D1.5mm
TP_5VSB: 5VSB; TestPoint_Pad_D1.5mm
TP_GND: GND; TestPoint_Pad_D1.5mm
TP_VBUS: USB_VBUS; TestPoint_Pad_D1.5mm
TP_VHOLD: 5V_HOLD; TestPoint_Pad_D1.5mm
U1: ESP32-S3-WROOM-1
U2: TJA1051T/3; SOIC-8_3.9x4.9mm_P1.27mm
U3: LP5907MFX-3.3; SOT-23-5
U4: TPS3839K33; SOT-23
U5, U7: TPS2121RUXR; RUX0012A
U6: SN74AHCT1G08; SOT-23-5

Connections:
+3V3: C3.1, C4.1, C11.1, C13.1, R2.1, R5.1, R6.1, R7.1, R8.1, R11.1, R23.1, TH1.1, TP_3V3.1, U1.2 (3V3), U2.5 (VIO), U3.5 (OUT), U4.3 (VDD)
+5VSB: C5.1, C14.1, C15.1, C_bulk1.1, D1.2 (A), DL1.4 (VDD), DL2.4 (VDD), DL3.4 (VDD), DL4.4 (VDD), DL5.4 (VDD), DL6.4 (VDD), DL7.4 (VDD), J2.1 (VCC), J3.1 (VCC), J4.1 (VCC), J5.1 (VCC), J_KVM.1 (+5VSB), R12.1, TP_5VSB.1, U2.3 (VCC), U6.5 (VCC), U7.1 (OUT), U7.8 (OUT)
/5VSB_RAW: C9.1, J_5VSB.1 (VCC), R17.1, U5.6 (PR1), U5.7 (IN1)
/5VSB_SENSE: R17.2, R18.1, U1.18 (IO10)
/+5V_HOLD: C1.1, C2.1, D1.1 (K), TP_VHOLD.1, U3.1 (IN), U3.3 (EN)
/AUX_RXC: J_KVM.4 (UART_RX), R20.2
/AUX_TXC: J_KVM.3 (UART_TX), R19.2
/AUX_UART_RX: R20.1, U1.20 (IO12)
/AUX_UART_TX: R19.1, U1.19 (IO11)
/BLACKOUT_SENSE: C12.1, R12.2, R13.1, TP5.1, U1.12 (IO8)
/CAN_H: J2.3 (CAN1_H), J3.3 (CAN1_H), J4.3 (CAN1_H), J5.3 (CAN1_H), R3.1, U2.7 (CANH)
/CAN_L: J2.6 (CAN1_L), J3.6 (CAN1_L), J4.6 (CAN1_L), J5.6 (CAN1_L), R4.2, U2.6 (CANL)
/CAN_MID: C7.1, R3.2, R4.1
/CAN_RX: U1.11 (IO18), U2.4 (RXD)
/CAN_TX: U1.10 (IO17), U2.1 (TXD)
/DETECT1: D2.1 (K), J2.8 (DETECT), R5.2, U1.4 (IO4)
/DETECT2: D3.1 (K), J3.8 (DETECT), R6.2, U1.5 (IO5)
/DETECT3: D4.1 (K), J4.8 (DETECT), R7.2, U1.6 (IO6)
/DETECT4: D5.1 (K), J5.8 (DETECT), R8.2, U1.7 (IO7)
/EN: C6.2, R2.2, SW_RESET.2, U1.3 (EN), U4.2 (~RESET)
/GPIO0: C8.1, R11.2, SW_BOOT.2, U1.27 (IO0)
/HUB_3V3_SENSE: R23.2, R24.1, U1.38 (IO2)
/KVM_3V3_REF: D7.1 (K), J_KVM.5 (KVM_3V3), R21.1
/KVM_3V3_SENSE: R21.2, R22.1, U1.39 (IO1)
/LED_DATA: U1.25 (IO48), U6.1 (A), U6.2 (B)
/LED_DATA_BUF: R14.1, U6.4 (Y)
/LED_DATA_DIN: DL1.3 (DIN), R14.2
/MAIN_5V_RAW: J_5V.1 (VCC), R15.1, U7.6 (PR1), U7.7 (IN1)
/MAIN_5V_SENSE: R15.2, R16.1, U1.17 (IO9)
/PSU_5V: U5.1 (OUT), U5.8 (OUT), U7.2 (IN2), U7.3 (CP2)
/TEMP_HUB: C16.1, R25.1, TH1.2, U1.15 (IO3)
/U7_ILM: R_ILIM2.1, U7.10 (ILM)
/U7_SS: C_SS2.1, U7.11 (SS)
/USB_CC1: J_USB.A5 (CC1), R9.1
/USB_CC2: J_USB.B5 (CC2), R10.1
/USB_DM: D6.3 (I/O2), D6.4 (I/O2), J_USB.A7 (D-), J_USB.B7 (D-), U1.13 (USB_D-)
/USB_DP: D6.1 (I/O1), D6.6 (I/O1), J_USB.A6 (D+), J_USB.B6 (D+), U1.14 (USB_D+)
/USB_VBUS: C10.1, D6.5 (VBUS), J_USB.A4 (VBUS), J_USB.A9 (VBUS), J_USB.B4 (VBUS), J_USB.B9 (VBUS), TP_VBUS.1, U5.2 (IN2), U5.3 (CP2)
GND: C1.2, C2.2, C3.2, C4.2, C5.2, C6.1, C7.2, C8.2, C9.2, C10.2, C11.2, C12.2, C13.2, C14.2, C15.2, C16.2, C_SS1.1, C_SS2.2, C_bulk1.2, D2.2 (A), D3.2 (A), D4.2 (A), D5.2 (A), D6.2 (GND), D7.2 (A), DL1.2 (VSS), DL2.2 (VSS), DL3.2 (VSS), DL4.2 (VSS), DL5.2 (VSS), DL6.2 (VSS), DL7.2 (VSS), J2.2 (GND), J2.SH1 (SHIELD), J2.SH2 (SHIELD), J3.2 (GND), J3.SH1 (SHIELD), J3.SH2 (SHIELD), J4.2 (GND), J4.SH1 (SHIELD), J4.SH2 (SHIELD), J5.2 (GND), J5.SH1 (SHIELD), J5.SH2 (SHIELD), J_5V.2 (GND), J_5VSB.2 (GND), J_KVM.2 (GND), J_USB.A1 (GND), J_USB.A12 (GND), J_USB.B1 (GND), J_USB.B12 (GND), J_USB.S1 (SHIELD), M1.1, M2.1, M3.1, M4.1, R9.2, R10.2, R13.2, R16.2, R18.2, R22.2, R24.2, R25.2, R_ILIM1.2, R_ILIM2.2, SW_BOOT.1, SW_RESET.1, TP_GND.1, U1.1 (GND), U1.40 (GND), U1.41 (GND), U2.2 (GND), U2.8 (S), U3.2 (GND), U4.1 (GND), U5.4 (OV2), U5.5 (OV1), U5.12 (GND), U6.3 (GND), U7.4 (OV2), U7.5 (OV1), U7.12 (GND)
unnamed: DL1.1 (DOUT), DL2.3 (DIN)
unnamed: DL2.1 (DOUT), DL3.3 (DIN)
unnamed: DL3.1 (DOUT), DL4.3 (DIN)
unnamed: DL4.1 (DOUT), DL5.3 (DIN)
unnamed: DL5.1 (DOUT), DL6.3 (DIN)
unnamed: DL6.1 (DOUT), DL7.3 (DIN)
unnamed: R_ILIM1.1, U5.10 (ILM)
unnamed: C_SS1.2, U5.11 (SS)

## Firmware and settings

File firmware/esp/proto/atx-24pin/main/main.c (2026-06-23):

/*
 * CEC 24-pin Module Firmware - ESP-IDF port
 *
 * Brings up the I2C bus + INA226 (5VSB), the ADC1 voltage-rail divider
 * reads (12V/5V/3V3), the ACS712 current sensors on the same three rails,
 * and the NTC thermistor, all matching the v0.5.9 hardware configuration.
 * Samples everything at 50 Hz, runs each channel through a fast EMA, and
 * emits TelePlot series at 10 Hz with a 1 Hz INFO summary line.
 *
 * Compare against v0.5.9 captures on the same hardware. Numbers should
 * match within measurement noise once per-unit trim is dialed in.
 */

#include <stdio.h>
#include <stdbool.h>
#include <stdint.h>
#include <inttypes.h>
#include <math.h>
#include <stdlib.h>
#include <string.h>
#include "freertos/FreeRTOS.h"
#include "freertos/task.h"
#include "esp_log.h"
#include "esp_check.h"
#include "esp_chip_info.h"
#include "esp_flash.h"
#include "esp_psram.h"
#include "esp_timer.h"
#include "driver/i2c_master.h"

#include "ina228.h"
#include "driver/gpio.h"
#include "cec_filters.h"
#include "cec_state.h"
#include "cec_config.h"
#include "cec_layer1.h"
#include "cec_layer2.h"
#include "cec_layer3.h"
#include "cec_swing.h"
#include "cec_nvs.h"
#include "cec_capture.h"
#include "cec_cli.h"
#include "cec_teleplot.h"
#include "cec_can.h"
#include "cec_telem.h"
#include "cec_canota.h"
#include "cec_pokeack.h"
#include "cec_freeze.h"

static const char *TAG = "cec_main";

/* Cross-module FREEZE (§6.10): a FREEZE from any node triggers this module's
 * real burst capture (cec_capture) on the shared instant -> co-capture dump. */
static void freeze_cocapture_cb(uint8_t origin, uint8_t cause, int64_t instant_us, void *ctx)
{
    (void)origin; (void)cause; (void)instant_us; (void)ctx;
    cec_capture_trigger(CEC_TRIG_COCAPTURE);
}

/* Set while a CAN-OTA update is in flight (cec_canota active callback).
 * can_comms_task pauses telemetry TX so it doesn't contend with the OTA
 * stream, and the app stays quiet right before it reboots into the new
 * image. */
static volatile bool s_ota_active = false;
static void ota_active_cb(bool active) { s_ota_active = active; }

/* CAN telemetry to the Hub. The live loop publishes the latest readings
 * into s_telem_pub (under a brief critical section); can_comms_task
 * snapshots it and sends the 3-frame rail-telemetry burst (cec_telem.h)
 * at CEC_CAN_TX_PERIOD_MS. */
static portMUX_TYPE s_telem_mux = portMUX_INITIALIZER_UNLOCKED;
static cec_telem_t  s_telem_pub;

static void can_comms_task(void *arg)
{
    (void)arg;
    ESP_LOGI(TAG, "CAN comms task on core %d, telemetry every %d ms",
             xPortGetCoreID(), CEC_CAN_TX_PERIOD_MS);
    uint8_t seq = 0;
    while (1) {
        if (s_ota_active) {                 /* hold off telemetry during a CAN-OTA */
            vTaskDelay(pdMS_TO_TICKS(CEC_CAN_TX_PERIOD_MS));
            continue;
        }
        cec_telem_t t;
        portENTER_CRITICAL(&s_telem_mux);
        t = s_telem_pub;
        portEXIT_CRITICAL(&s_telem_mux);
        t.instance    = CEC_CFG_MODULE_ID;     /* this module's port id (0) */
        t.module_type = CEC_CFG_MODULE_TYPE;
        t.seq = seq++;
        uint8_t f[8];
        for (uint8_t sub = 0; sub < CEC_TELEM_NUM_SUB; sub++) {
            uint32_t id = cec_telem_pack(&t, sub, f);
            can_send_frame(id, f, sizeof(f));
        }
        vTaskDelay(pdMS_TO_TICKS(CEC_CAN_TX_PERIOD_MS));
    }
}

/* I2C bus pins, matching v0.5.9 wiring on the Lonely Binary ESP32-S3 N16R8 */
#define I2C_PIN_SDA       8
#define I2C_PIN_SCL       9
#define I2C_PORT_NUM      I2C_NUM_0

/* ADC1 channels (GPIO1..7 = ADC1_CH0..6), pin map from v0.5.9 */
#define ADC_CH_V_12V      ADC_CHANNEL_0   /* GPIO1 */
#define ADC_CH_V_5V       ADC_CHANNEL_1   /* GPIO2 */
#define ADC_CH_V_3V3      ADC_CHANNEL_2   /* GPIO3 */
#define ADC_CH_I_12V      ADC_CHANNEL_3   /* GPIO4 */
#define ADC_CH_I_5V       ADC_CHANNEL_4   /* GPIO5 */
#define ADC_CH_I_3V3      ADC_CHANNEL_5   /* GPIO6 */
#define ADC_CH_NTC        ADC_CHANNEL_6   /* GPIO7 */

/* Per-rail trim factors carried forward from v0.5.9 (hardware-specific) */
#define TRIM_12V          1.0000f
#define TRIM_5V           0.9962f
#define TRIM_3V3          0.9915f
#define TRIM_5VSB         0.9901f

/* Hardware voltage dividers (top + bottom of resistor stack), v0.5.9 */
#define SCALE_12V         ((47000.0f + 10000.0f) / 10000.0f)
#define SCALE_5V          ((15000.0f + 10000.0f) / 10000.0f)
#define SCALE_3V3         (( 4700.0f + 10000.0f) / 10000.0f)

/* ACS712 divider (between sensor output and ADC pin) and per-part
 * sensitivities, from v0.5.9. The 30A part sits on the 12V rail; both
 * 20A parts sit on the 5V/3V3 rails. */
#define ACS712_DIVIDER       ((20000.0f + 30000.0f) / 30000.0f)
#define ACS712_30A_SENS      0.066f
#define ACS712_20A_SENS      0.100f
/* Per-rail no-load output (post-divider voltage). Nominal Vcc/2 = 2.20 V
 * but the part-to-part variation is several tens of mV (hundreds of mA
 * at these sensitivities), so each rail gets its own constant for hand-
 * tuning. The boot-time diagnostic logs the measured no-load output —
 * with the PSU disconnected at first boot, copy those values here. Full
 * runtime calibration lands with the serial-command + NVS path.
 *
 * Values below are the per-unit no-load measurements captured against
 * this board with the PSU disconnected. */
#define ACS712_ZERO_12V      2.4483f
#define ACS712_ZERO_5V       2.1967f
#define ACS712_ZERO_3V3      2.2117f

/* Loop cadence. Sample at 50 Hz to match v0.5.9; emit TelePlot at 10 Hz
 * (every 5th iteration); log an INFO summary at 1 Hz (every 50th). */
#define SAMPLE_PERIOD_MS  20
#define TELEPLOT_DIVIDER  5
#define LOG_DIVIDER       50

/* EMA smoothing. At 50 Hz, alpha=0.02 gives a ~1 s time constant, matching
 * the v0.5.9 EMA_ALPHA_FAST. */
#define EMA_ALPHA_FAST    0.02f

/* I2C bus handle (shared across components later) */
static i2c_master_bus_handle_t s_i2c_bus = NULL;

/* PRODUCTION sensing: one INA228 per rail (12V/5V/3V3/5VSB). Each gives bus
 * voltage + current, replacing the divider/ACS712/INA226 front end. */
static ina228_handle_t s_ina228_12v  = NULL;
static ina228_handle_t s_ina228_5v   = NULL;
static ina228_handle_t s_ina228_3v3  = NULL;
static ina228_handle_t s_ina228_5vsb = NULL;

/* Read one rail's bus voltage + current. True only if both reads succeed. */
static bool ina228_read_rail(ina228_handle_t h, float *v, float *i)
{
    if (h == NULL) return false;
    return ina228_read_bus_voltage(h, v) == ESP_OK &&
           ina228_read_current(h, i) == ESP_OK;
}

/* (LS divider rail configs removed -- rails now read via INA228.) */

/* (NTC + ACS712 + LS/HS divider configs removed -- the INA228s supply
 * per-rail V/I and the 12V die sensor supplies temperature.) */

/* Filter state */
static ema_t s_v_5vsb_ema, s_i_5vsb_ema;
static ema_t s_v_12v_ema, s_v_5v_ema, s_v_3v3_ema;
static ema_t s_i_12v_ema, s_i_5v_ema, s_i_3v3_ema;
static ema_t s_temp_ema;

/* State machine */
static cec_state_t s_state = CEC_STATE_OFF;
static int64_t s_state_entered_us = 0;

/* Layer 1 static-threshold detectors per rail. Bands + debounce live
 * in cec_config.{c,h} (the board-variation point).
 *
 * Mask Layer 1 for this long after every state transition. Covers the
 * PSU inrush (most visibly on 5VSB OFF -> STANDBY ramp, where the rail
 * passes through 1..5 V on its way up and would otherwise sustain
 * CRITICAL for the consecutive-sample window). 500 ms is loose enough
 * for typical PSU ramp times and tight enough not to miss real faults. */
#define LAYER1_SETTLE_US  (500LL * 1000)

static cec_layer1_detector_t s_l1_12v, s_l1_5v, s_l1_3v3, s_l1_5vsb;
static cec_severity_t s_last_sev_12v  = CEC_SEV_NONE;
static cec_severity_t s_last_sev_5v   = CEC_SEV_NONE;
static cec_severity_t s_last_sev_3v3  = CEC_SEV_NONE;
static cec_severity_t s_last_sev_5vsb = CEC_SEV_NONE;

/* Layer 2 adaptive transient detectors. Per-rail min-thresholds and
 * k_sigma live in cec_config.h (the board-variation point). */
static cec_layer2_detector_t s_l2_v_12v, s_l2_v_5v, s_l2_v_3v3, s_l2_v_5vsb;
static cec_layer2_detector_t s_l2_i_12v, s_l2_i_5v, s_l2_i_3v3;

/* Layer 3 per-(state, rail) running profile. Z-score threshold 4.0
 * (v0.5.9 default). Adapt rate 0.0005 gives an effective window of
 * roughly 2000 samples (40 s at 50 Hz) once the profile is warm. */
#define LAYER3_Z_THRESHOLD   4.0f
#define PROFILE_ADAPT_RATE   0.0005f
typedef enum {
    PROF_V_12V = 0, PROF_V_5V,  PROF_V_3V3,  PROF_V_5VSB,
    PROF_I_12V,     PROF_I_5V,  PROF_I_3V3,  PROF_I_5VSB,
    PROF_TEMP,      PROF_COUNT
} prof_idx_t;
static cec_rail_profile_t s_profiles[CEC_STATE_COUNT][PROF_COUNT];
static bool s_z_above_last = false;

/* Power swing: 250-sample rolling window (~5 s at 50 Hz). Adaptive
 * threshold = max(8 W, 25% * window_mean), 2 consecutive bad samples
 * (~40 ms) before firing. From v0.5.9. */
#define POWER_SWING_WINDOW_SIZE        250
#define POWER_SWING_CONSECUTIVE        2
#define POWER_SWING_MIN_THRESHOLD_W    8.0f
#define POWER_SWING_FRACTION           0.25f
static cec_swing_detector_t s_power_swing;
static float s_power_swing_buf[POWER_SWING_WINDOW_SIZE];

/* Current swing: per-rail 250-sample rolling window with fixed
 * thresholds. 3 consecutive bad samples (~60 ms) before firing. From
 * v0.5.9. Only one rail fires per iteration (priority 12V > 5V > 3V3). */
#define CURRENT_SWING_WINDOW_SIZE      250
#define CURRENT_SWING_CONSECUTIVE      3
#define CURRENT_SWING_THRESH_I_12V     0.30f
#define CURRENT_SWING_THRESH_I_5V      0.50f
#define CURRENT_SWING_THRESH_I_3V3     0.30f
static cec_swing_detector_t s_i_swing_12v, s_i_swing_5v, s_i_swing_3v3;
static float s_i_swing_12v_buf[CURRENT_SWING_WINDOW_SIZE];
static float s_i_swing_5v_buf [CURRENT_SWING_WINDOW_SIZE];
static float s_i_swing_3v3_buf[CURRENT_SWING_WINDOW_SIZE];

/* NVS persistence for Layer 3 profiles. The magic prefix lets a future
 * firmware revision reject an old blob cleanly if the layout changes. */
#define NVS_PROFILES_KEY     "profiles"
#define NVS_PROFILES_MAGIC   0xCEC30001U
#define NVS_SETTINGS_KEY     "settings"
#define NVS_SETTINGS_MAGIC   0xCEC50001U
#define NVS_SAVE_INTERVAL_US (5LL * 60 * 1000 * 1000)   /* 5 minutes */
static bool    s_profiles_dirty = false;
static int64_t s_last_nvs_save_us = 0;

/* Per-rail INA228 calibration, persisted so a bench cal survives reboots.
 * Index 0..3 = 12V/5V/3V3/5VSB (CAL_RAIL_NAME). The shunt sets accuracy
 * (~±1% tolerance uncalibrated); a one-point load cal sets the current gain
 * (removing the tolerance), a second point adds the offset, and a DMM point
 * sets the voltage gain. See cli_cmd_cal. */
#define NVS_CAL_KEY    "ina_cal"
#define NVS_CAL_MAGIC  0xCEC60001U
#define CAL_N_RAILS    4
typedef struct {
    float v_trim;     /* bus-voltage gain (1.0 = raw) */
    float i_trim;     /* current gain (1.0 = raw) */
    float i_offset;   /* current offset, amps (0.0 = none) */
} cec_rail_cal_t;
static cec_rail_cal_t s_cal[CAL_N_RAILS];   /* identity until load_cal_from_nvs() */
/* Pending current cal points per rail: 1 point -> gain only, 2 -> gain+offset. */
static struct { int n; float raw[2], tru[2]; } s_cal_pts[CAL_N_RAILS];

/* Shutdown detection: 1-second rate-of-change window on v_12v_ema.
 * Triggers when 12V is dropping faster than 0.5 V/s from a nominal-ish
 * starting point (> 5 V) — i.e. the PSU is in the middle of going down.
 * Fires CEC_TRIG_SHUTDOWN (bypasses cooldown so a real shutdown still
 * captures even if a recent burst is in cooldown) and asserts a 30 s
 * mute window during which all detector layers go quiet so we don't
 * spam triggers on collapsing rails. The mute clears either by timeout
 * or by the state classifier landing on OFF or STANDBY, whichever
 * comes first.
 *
 * The 5VSB-defined STANDBY in cec_state_classify is what makes this
 * clean: STANDBY now explicitly means "main rails off, 5VSB up",
 * which is the canonical post-shutdown stable state, so reaching it
 * is a positive signal that the shutdown has completed. */
#define V_12V_RATE_HISTORY_SIZE        50           /* 1 s at 50 Hz */
#define V_12V_SHUTDOWN_RATE_THRESHOLD  (-0.5f)      /* V/s, negative */
#define V_12V_SHUTDOWN_MIN_ARMED_V     5.0f         /* don't trigger if 12V was already low */
#define SHUTDOWN_MUTE_DURATION_US      (30LL * 1000 * 1000)
static float   s_v_12v_history[V_12V_RATE_HISTORY_SIZE];
static size_t  s_v_12v_hist_idx = 0;
static size_t  s_v_12v_hist_count = 0;
static bool    s_shutting_down = false;
static int64_t s_shutdown_start_us = 0;

/* Runtime-toggleable layer enables, persisted to NVS so they survive
 * reboots. Defaults are all-on. Toggle via the serial CLI. */
typedef struct {
    bool layer1;
    bool layer2;
    bool layer3;
    bool swing_power;
    bool swing_current;
} cec_settings_t;
static cec_settings_t s_settings = {
    .layer1 = true, .layer2 = true, .layer3 = true,
    .swing_power = true, .swing_current = true,
};
static bool s_settings_dirty = false;
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
void app_main(void)
{
    ESP_LOGI(TAG, "===========================================");
    ESP_LOGI(TAG, "CEC 24-pin Module Firmware (ESP-IDF port)");
    ESP_LOGI(TAG, "Version: 0.6.0-dev (INA226 bringup)");
    ESP_LOGI(TAG, "===========================================");

    /* If we just booted a CAN-OTA image it is PENDING_VERIFY -- confirm it so
     * the bootloader keeps it instead of rolling back on the next reset. */
    cec_canota_mark_valid();

    log_hardware_info();

    /* TelePlot transport: the production 24-pin board has ONLY the MCU's
     * native USB Serial/JTAG (one USB-C); there is no CH340K UART bridge
     * (that was the dev board). So we deliberately do NOT initialize the
     * dedicated UART transport here -- leaving it unconfigured routes every
     * teleplot_* line to stdio (the USB console), interleaved with the logs
     * and CLI on the one cable.
     *
     * This is independent of CONFIG_CEC_TELEMETRY_UART0 on purpose: a stale
     * sdkconfig left at =y (sdkconfig.defaults changes don't rewrite an
     * existing sdkconfig) must not silently send telemetry out the absent
     * GPIO43/44 again. The shared cec_telemetry component keeps full UART
     * support for a board that actually has the bridge; this app just
     * doesn't call it. */
    ESP_LOGI(TAG, "TelePlot on the native USB console (no CH340K UART on the production board)");

    init_i2c_bus();
    init_status_led();

    /* PRODUCTION sensing: 4x INA228 (one per rail). Replaces the proto's
     * divider/ACS712/INA226 front end -- do NOT also call init_ina226_5vsb(),
     * it grabs 0x40 and writes INA226 registers into the 12V INA228 (U10). */
    esp_err_t err = init_ina228_rails();
    if (err != ESP_OK) {
        ESP_LOGE(TAG, "INA228 rail init failed: %s", esp_err_to_name(err));
        ESP_LOGW(TAG, "Continuing; un-initialized rails read 0");
    }

    ema_init(&s_v_5vsb_ema, EMA_ALPHA_FAST);
    ema_init(&s_i_5vsb_ema, EMA_ALPHA_FAST);
    ema_init(&s_v_12v_ema,  EMA_ALPHA_FAST);
    ema_init(&s_v_5v_ema,   EMA_ALPHA_FAST);
    ema_init(&s_v_3v3_ema,  EMA_ALPHA_FAST);
    ema_init(&s_i_12v_ema,  EMA_ALPHA_FAST);
    ema_init(&s_i_5v_ema,   EMA_ALPHA_FAST);
    ema_init(&s_i_3v3_ema,  EMA_ALPHA_FAST);
    ema_init(&s_temp_ema,   EMA_ALPHA_FAST);

    init_layer1();
    init_layer2();
    init_layer3_profiles();
    init_swing_detectors();

    if (cec_nvs_init() == ESP_OK) {
        load_profiles_from_nvs();
        load_settings_from_nvs();
        load_cal_from_nvs();   /* after init_ina228_rails: applies the cal to the handles */
    } else {
        ESP_LOGW(TAG, "NVS init failed; profiles will not persist across boots");
    }

    esp_err_t cli_err = cec_cli_init(s_cli_commands,
                                     sizeof(s_cli_commands) / sizeof(s_cli_commands[0]));
    if (cli_err != ESP_OK) {
        ESP_LOGW(TAG, "cec_cli_init failed: %s — serial commands unavailable",
                 esp_err_to_name(cli_err));
    }

    /* CAN telemetry to the Hub. Normal mode (the Hub ACKs our frames); if
     * no Hub is on the bus the controller bus-offs and auto-recovers (the
     * cec_can on_state_change handler), logging until a Hub appears. */
    if (can_init(false) == ESP_OK) {
        xTaskCreatePinnedToCore(can_comms_task, "can_comms", 4096, NULL, 4, NULL, 1);
        /* CAN-OTA receiver: lets the Hub re-flash this module over CAN. It
         * drains can_receive() and writes the streamed image to the inactive
         * OTA slot; ota_active_cb pauses telemetry while an update runs. */
        if (cec_canota_receiver_start(ota_active_cb) != ESP_OK) {
            ESP_LOGW(TAG, "CAN-OTA receiver failed to start");
        }
        /* DETECT poke-and-ack responder. The 24-pin has NO pin-8 sense tap
         * (the MINI-1 GPIO pads sit under the shroud — none can be added), so
         * this starts INERT: safe fallback / legacy mode. The Hub still reads
         * this module's comm class from the static DETECT divider; it just
         * won't get a poke ack, and binds the port as known-but-unbound. */
        cec_pokeack_responder_start(CEC_POKEACK_TAP_NONE,
                                    CEC_CFG_MODULE_TYPE, CEC_CFG_MODULE_ID);
        /* Cross-module FREEZE co-capture (§6.10): a FREEZE from any node
         * triggers this module's real burst capture on the shared instant. */
        cec_freeze_cfg_t fz = { .self_instance = CEC_CFG_MODULE_ID, .on_freeze = freeze_cocapture_cb };
        cec_freeze_init(&fz);
    } else {
        ESP_LOGW(TAG, "CAN init failed — no telemetry to the Hub");
    }

    /* (ACS712 zero-cal removed; the INA228 needs no per-rail zero) */

    cec_capture_config_t cap_cfg = {
        .pre_trigger_capacity = PRE_TRIGGER_BUF_SIZE,
        .pre_sample_size      = sizeof(cec_capture_sample_t),
        .hs_row_size          = sizeof(cec_capture_hs_sample_t),
        .hs_sample_rate_hz    = HS_SAMPLE_RATE_HZ,
        .hs_duration_ms       = (HS_BURST_BUF_SIZE * 1000) / HS_SAMPLE_RATE_HZ,
        .cooldown_ms          = BURST_COOLDOWN_MS,
        .hs_dump_decimation   = 1,       /* dump every HS row, as v0.5.9 did */
        /* v0.5.9 lineage: pre-ring indices computed at dump time, so
         * pushes during the 4 s HS window are part of the dump. */
        .snapshot_pre_at_trigger = false,
        .dispatch_task_stack  = 8192,    /* legacy HS task margin */
        .write          = teleplot_write_raw,
        .render_pre     = capture_render_pre,
        .render_hs      = capture_render_hs,
        .state_token    = capture_state_token,
        .hs_source      = CEC_CAPTURE_HS_CALLBACK,
        .hs_fill        = capture_hs_fill,
    };
    err = cec_capture_init(&cap_cfg);
    if (err != ESP_OK) {
        ESP_LOGE(TAG, "cec_capture_init failed: %s", esp_err_to_name(err));
        ESP_LOGW(TAG, "Continuing without burst capture");
    }

    /* Sample at 50 Hz, emit TelePlot at 10 Hz, log an INFO summary at 1 Hz.
     * Read failures don't get spammed per-iteration; the divided cadence
     * makes them visible as gaps in TelePlot and bad values in the summary. */
    ESP_LOGI(TAG, "Entering main loop (sample=50 Hz, teleplot=10 Hz, log=1 Hz)");
    TickType_t last_wake = xTaskGetTickCount();
    uint32_t iter = 0;
    while (1) {
        float v_5vsb = 0.0f, i_5vsb = 0.0f;
        float v_12v = 0.0f, v_5v = 0.0f, v_3v3 = 0.0f;
        float i_12v = 0.0f, i_5v = 0.0f, i_3v3 = 0.0f;
        float temp_c = 0.0f;
        bool ok_5vsb = false, ok_temp = false;
        bool ok_v_12v = false, ok_v_5v = false, ok_v_3v3 = false;
        bool ok_i_12v = false, ok_i_5v = false, ok_i_3v3 = false;

        /* PRODUCTION sensing: one INA228 per rail gives bus voltage + current;
         * board temp from the 12V INA228's on-die sensor. */
        ok_v_12v = ok_i_12v = ina228_read_rail(s_ina228_12v,  &v_12v,  &i_12v);
        ok_v_5v  = ok_i_5v  = ina228_read_rail(s_ina228_5v,   &v_5v,   &i_5v);
        ok_v_3v3 = ok_i_3v3 = ina228_read_rail(s_ina228_3v3,  &v_3v3,  &i_3v3);
        ok_5vsb             = ina228_read_rail(s_ina228_5vsb, &v_5vsb, &i_5vsb);
        ok_temp  = (s_ina228_12v != NULL &&
                    ina228_read_die_temp_c(s_ina228_12v, &temp_c) == ESP_OK);

        /* PSU control/status, buffered by U4/U5 (read-only). PS_ON# is
         * active-low, so ps_on=true means the mobo is commanding the PSU on. */
        bool pwr_ok = (gpio_get_level(PWROK_BUF_GPIO) != 0);
        bool ps_on  = (gpio_get_level(PSON_BUF_GPIO)  == 0);

        /* On a failed read, fall back to the last good filtered value so a
         * single bad sample doesn't ripple into the state classifier. Before
         * the first successful read an EMA returns 0.0 (its init value). */
        float v_5vsb_ema = ok_5vsb  ? ema_update(&s_v_5vsb_ema, v_5vsb) : ema_value(&s_v_5vsb_ema);
        float i_5vsb_ema = ok_5vsb  ? ema_update(&s_i_5vsb_ema, i_5vsb) : ema_value(&s_i_5vsb_ema);
        float v_12v_ema  = ok_v_12v ? ema_update(&s_v_12v_ema,  v_12v)  : ema_value(&s_v_12v_ema);
        float v_5v_ema   = ok_v_5v  ? ema_update(&s_v_5v_ema,   v_5v)   : ema_value(&s_v_5v_ema);
        float v_3v3_ema  = ok_v_3v3 ? ema_update(&s_v_3v3_ema,  v_3v3)  : ema_value(&s_v_3v3_ema);
        float i_12v_ema  = ok_i_12v ? ema_update(&s_i_12v_ema,  i_12v)  : ema_value(&s_i_12v_ema);
        float i_5v_ema   = ok_i_5v  ? ema_update(&s_i_5v_ema,   i_5v)   : ema_value(&s_i_5v_ema);
        float i_3v3_ema  = ok_i_3v3 ? ema_update(&s_i_3v3_ema,  i_3v3)  : ema_value(&s_i_3v3_ema);
        float temp_ema   = ok_temp  ? ema_update(&s_temp_ema,   temp_c) : ema_value(&s_temp_ema);
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

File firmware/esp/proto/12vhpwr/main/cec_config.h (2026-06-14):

/*
 * 12vhpwr-proto board/application configuration — the official
 * board-variation point (eps main/cec_config pattern, firmware
 * consolidation Phase H3). Pins, LSB scaling, and the link clock live
 * here, never inside firmware/esp/components.
 *
 * Pin map per doc section 6.3 / 10 (ESP32-P4-Module-DEV-KIT GPIO header
 * to the Tang Primer 25K dock 2x20 GPIO field).
 *
 * Re-pinned off GPIO 20-24 (bench bring-up): on the ESP32-P4 those pads
 * are the flash/PSRAM MSPI bus (IO_MUX DBG_PSRAM_*), so gpio_config on
 * them hangs the CPU. GPIO 1-5 are plain-GPIO-only, exposed on the
 * DEV-KIT header, with no flash/PSRAM/Ethernet/console/strap function.
 * Dock field positions and FPGA balls are UNCHANGED — only the ESP GPIO
 * (and thus which header pin the jumper lands on) moved.
 */

#pragma once

#include <stdbool.h>
#include <stdint.h>
#include "cec_fpga_link.h"

#ifdef __cplusplus
extern "C" {
#endif

#define PROTO_PIN_SCLK  1    /* -> dock field T13 (FPGA F2)  */
#define PROTO_PIN_MOSI  2    /* -> dock field T14 (FPGA B2)  */
#define PROTO_PIN_MISO  3    /* <- dock field B14 (FPGA C2)  */
#define PROTO_PIN_CS    4    /* -> dock field B13 (FPGA F1)  */
#define PROTO_PIN_DRDY  5    /* <- dock field B12 (FPGA A1)  */

#define PROTO_LINK_HOST      SPI2_HOST
#define PROTO_LINK_CLOCK_HZ  (8 * 1000 * 1000)   /* 8 MHz. The ESP<->FPGA LINK
                                                  * SCLK (NOT the AD7606 readout).
                                                  * 12.5 MHz (fabric/4) is the
                                                  * slave's hard edge and bit-
                                                  * errored on the bench: the
                                                  * constant 0xA5 header arrived
                                                  * with single bits flipped
                                                  * (0xB5/0xA1/0xA7). 8 MHz sits
                                                  * below the known-good 10 MHz for
                                                  * MISO settle margin on the
                                                  * perfboard link; raise toward
                                                  * 10-12.5 only once the headers
                                                  * are 100% solid. Floor for the
                                                  * 25k stream keep-up is ~5 MHz. */

/* AD7606 +/-5 V range: 152.59 uV per LSB. */
#define PROTO_LSB_VOLTS      (5.0 / 32768.0)

/* FPGA native capture rate -- keep in sync with top.v SAMPLE_HZ. This is the
 * "burst at 200k for oversampling, decimate to the ~25 kSPS useful band" target
 * (the host averages each 200k/25k = 8 raw samples -> sqrt(8) ~ 2.8x noise drop).
 * Used only for the nominal time axis of `fastburst`; the real rate is the
 * AD7606 conv+read ceiling if SAMPLE_HZ over-paces it -- the sequential FSM
 * (conv ~4us + 64-SCLK read at 12.5 MHz) self-limits BELOW 200 kSPS, so the
 * fastburst header reports the ACHIEVED rate from the seq spacing, not this
 * nominal. Reaching the full 200 kSPS needs the read-SCLK speedup + pipelined
 * FSM noted in top.v. */
#define PROTO_NATIVE_HZ      200000

/* RTL capture-ring DEPTH (top.v) -- the max `fastburst` window. */
#define PROTO_RING_DEPTH     2048

/* Continuous decimated stream (top.v DECIM_M boxcar -> free-running FIFO).
 * The FPGA averages DECIM_M native samples into one stream sample, so the
 * stream rate = native / DECIM_M. With native ~200k and DECIM_M 8 -> ~25k;
 * with the v0 sequential FSM (~107k) and DECIM_M 4 -> ~27k. Keep
 * PROTO_STREAM_HZ in sync with top.v's NATIVE_HZ/DECIM_M -- it is only the
 * nominal time axis; the host derives the TRUE rate from the frame cadence,
 * and the per-frame dropcount byte exposes any FIFO overrun (lost samples). */
#define PROTO_STREAM_HZ      25000
/* Stream FIFO depth in FPGA (top.v STREAM_DEPTH) -- the ESP drain-jitter slack
 * (2048 @ 25k = ~80 ms). Reads >this in one block just wrap the FIFO. */
#define PROTO_STREAM_DEPTH   2048

/* 12V-rail voltage divider: 47k top / 10k bottom -> rail = adc * (47+10)/10. */
#define PROTO_RAIL_DIVIDER   (57.0f / 10.0f)

/* Per-pin current sense (PROVISIONAL -- confirm against the perfboard):
 *   amps = (adc_volts - PROTO_ISENSE_BIAS_V) / PROTO_ISENSE_V_PER_A
 * BIAS  = sense-amp output at 0 A (the capture's steady channels sit ~2.40 V).
 * V_PER_A = Rshunt * gain. The spec 12VHPWR-Std front-end is 1 mOhm * INA240A3
 * (gain 100) = 0.1 V/A; set this to the board's ACTUAL shunt*gain. Only the
 * magnitude scales with V_PER_A -- the sign and zero are right regardless. */
#define PROTO_ISENSE_BIAS_V    2.40f
#define PROTO_ISENSE_V_PER_A   0.10f
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

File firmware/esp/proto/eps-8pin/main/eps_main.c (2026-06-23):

#include <stdio.h>
#include <stdlib.h>
#include <string.h>
#include <inttypes.h>

#include "freertos/FreeRTOS.h"
#include "freertos/task.h"
#include "esp_log.h"
#include "esp_timer.h"

#include "cec_state.h"
#include "cec_config.h"
#include "cec_adc.h"
#include "acs758.h"
#include "ntc.h"
#include "cec_filters.h"
#include "cec_detection.h"
#include "cec_capture.h"
#include "cec_can.h"
#include "cec_telem.h"
#include "cec_canota.h"
#include "cec_pokeack.h"
#include "cec_freeze.h"
#include "cec_teleplot.h"
#include "cec_cli.h"
#include "cec_classifier.h"

static const char *TAG = "eps_main";

// ---- Global state ----
static cec_shared_state_t   g_state;
static cec_config_t  g_config;
static acs758_ctx_t  g_acs;
// NTC on GPIO 7 -> ADC1_CH6. 10K @ 25C, B=3950, 10K series pull-up to
// 3V3 - matches the EPS daughterboard schematic.
static ntc_t g_ntc = {
    .channel              = ADC_CHANNEL_6,
    .samples              = 8,
    .beta                 = 3950.0f,
    .nominal_resistance   = 10000.0f,
    .nominal_temperature_k = 298.15f,
    .pull_up_resistance   = 10000.0f,
    .vcc                  = 3.3f,
};
// 12V rail tap on GPIO 1 -> ADC1_CH0 via a 47k/10k divider, so
// V_rail = V_pin * (47k+10k)/10k = V_pin * 5.7. Trim is unity; a per-
// unit trim ('set vtrim <f>' later, or a one-shot calibration helper)
// can refine it against a known reference.
static const cec_adc_rail_t s_rail_12v = {
    .channel = ADC_CHANNEL_0,                          // GPIO 1
    .samples = 4,
    .scale   = (47000.0f + 10000.0f) / 10000.0f,       // 5.7
    .trim    = 1.0f,
};
// Two-stage filter per cable: median to reject impulse spikes, then EMA
// to smooth. Median window size is per-module tunable; 5 is the EPS
// starting point for the Hall sensor's ~50-100 mA RMS raw noise.
#define EPS_MEDIAN_WINDOW   5
static median_t g_median[CEC_NUM_CABLES];
static ema_t    g_ema[CEC_NUM_CABLES];
static float    g_median_buf[CEC_NUM_CABLES][EPS_MEDIAN_WINDOW];
static cec_detection_ctx_t g_detect;

// Burst capture engine config. 10 kHz HS rate (per channel) for 1 s, with
// 20 s of 50 Hz pre-trigger context. cooldown_ms=10000 matches the 24-pin.
#define EPS_BURST_HS_RATE_HZ        10000
#define EPS_BURST_HS_DURATION       1000
#define EPS_PRE_TRIGGER_SECONDS     20
#define EPS_BURST_COOLDOWN_MS       10000
// Default dump decimation: emit every 5th HS row to TelePlot (2 kHz
// visible from 10 kHz captured). Override via `set decim <N>`.
#define EPS_BURST_HS_DUMP_DECIM     5

// ---- Burst-capture shapes + hooks (app-side) ----
// The shared cec_capture engine treats rows as opaque bytes and calls
// back here for HS acquisition + dump rendering, so the eps dump stays
// byte-identical to its pre-merge format.

// Pre-trigger sample - 50 Hz, full state snapshot.
typedef struct {
    uint32_t ts_ms;
    float    eps1_a, eps2_a;
    float    eps1_raw_a, eps2_raw_a;
    float    bus_voltage_v;  // 12V rail measurement (V)
    float    temp_c;
    uint8_t  load_state;     // cec_load_state_t cast to byte
    uint8_t  flags;          // CEC_FLAG_* bits
} cec_capture_sample_t;

// HS sample - 10 kHz, currents only. Slim by design so the PSRAM
// footprint stays modest and the DMA consumer's per-sample work is cheap.
typedef struct {
    uint32_t ts_us_offset;   // microseconds since HS capture start
    float    eps1_a;
    float    eps2_a;
} cec_capture_hs_sample_t;

// raw ADC mv -> amps via the engine-cached per-channel conversion params
// (mirrors acs758_read_current; cec_capture_update_channel keeps the
// cached params current after runtime calibration changes).
static float hs_convert_to_amps(const cec_capture_channel_t *ch, int mv)
{
    float v_chip = (mv / 1000.0f) * ch->divider_gain;
    float v_sig  = v_chip - ch->quiescent_v - ch->zero_offset_v;
    if (ch->sensitivity_v_a == 0.0f) return 0.0f;
    return v_sig / ch->sensitivity_v_a;
}

static void capture_hs_on_reading(void *row_v, int cidx, int mv)
{
    cec_capture_hs_sample_t *row = row_v;
    const cec_capture_channel_t *ch = cec_capture_channel_get(cidx);
    if (ch == NULL) return;
    float amps = hs_convert_to_amps(ch, mv);
    if (cidx == 0)      row->eps1_a = amps;
    else if (cidx == 1) row->eps2_a = amps;
}

static void capture_hs_row_finish(void *row_v, uint32_t ts_us_offset)
{
    ((cec_capture_hs_sample_t *)row_v)->ts_us_offset = ts_us_offset;
}

// Dump renderers: byte-identical to the pre-merge eps burst dump.
static int capture_render_pre(const void *sample, char *buf, size_t cap)
{
    const cec_capture_sample_t *s = sample;
    return snprintf(buf, cap,
                    ">b_eps1_a:%" PRIu32 ":%.6f\n"
                    ">b_eps2_a:%" PRIu32 ":%.6f\n"
                    ">b_eps1_raw_a:%" PRIu32 ":%.6f\n"
                    ">b_eps2_raw_a:%" PRIu32 ":%.6f\n"
                    ">b_bus_v:%" PRIu32 ":%.6f\n"
                    ">b_temp_c:%" PRIu32 ":%.6f\n"
                    ">b_load:%" PRIu32 ":%u\n"
                    ">b_flags:%" PRIu32 ":%u\n",
                    s->ts_ms, s->eps1_a,
                    s->ts_ms, s->eps2_a,
                    s->ts_ms, s->eps1_raw_a,
                    s->ts_ms, s->eps2_raw_a,
                    s->ts_ms, s->bus_voltage_v,
                    s->ts_ms, s->temp_c,
                    s->ts_ms, (unsigned)s->load_state,
                    s->ts_ms, (unsigned)s->flags);
}
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

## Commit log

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2026-06-12 fw: G1 promote cec_telemetry -- transport superset, UART behind CONFIG_CEC_TELEMETRY_UART0 (FW-09)
    The diff verdict REVERSED the runbook's expectation: BOTH apps are
    dual-stream today (eps pioneered the CH340K UART transport; the 24-pin
    adopted it). The superset is therefore the eps transport core
    (parameterized init_uart(port,tx,rx,baud,txbuf), write_raw backend,
    UART_SCLK_APB pinned -- the field-debugged fix for SCLK_DEFAULT
    resolving to a wrong clock on S3) plus the 24-pin's teleplot_writef and
    its truncation clamp on every formatted emit (the eps emits could pass
    snprintf's would-be length straight to the writer on a truncating
    format). emit/emit_t formats are byte-identical to both tree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
    [cec_config.h, cec_teleplot.c, eps_main.c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]
2026-06-12 fw: G2 promote cec_comms (CAN/TWAI) -- bitrate, listen-only diag, and pins to Kconfig (FW-10)
    Promoted from eps to firmware/esp/components ahead of atx-24pin rev2's
    TJA1462A needs. The CAN_BITRATE_BPS grep-loud TODO is resolved per its
    own text: CONFIG_CEC_CAN_BITRATE_BPS defaults to the bench 125000 with
    the full production note (500 k platform target; the Waveshare bench
    breakout's slope-control Rs strap is why the bench parks lower)
    attached as the Kconfig help. CEC_CAN_DIAG_LISTEN_ONLY carried over as
    a Kconfig bool (its bus-off triage procedure = help text). The TX/RX
    pins (4/15, eps daughterboard wiring) also moved out of the shared
    header into Kconfig ints per the E3 board-constants r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
    [cec_can.c]
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2026-06-12 fw: self-diagnosing wrong-target guard in cec_adc; scope s_uart_port to the UART arm
    Field finding (owner's first VSCode build): the extension's Set-Target
    picker defaults to plain esp32 and writes sdkconfig directly, overriding
    the app's sdkconfig.defaults -- and plain esp32 is line-fitting-only, so
    the build died in cec_adc with an 'unknown type
    adc_cali_curve_fitting_config_t' riddle. cec_adc now #errors up front
    with the actual diagnosis (every CEC target -- s3/p4/c6 -- has curve
    fitting; a line-fitting-only target means a wrong set-target) and the
    fix command. Also: s_uart_port moves inside the CONFIG_CEC_TELEMETRY_UART0
    arm so UART0-off builds (the P4 proto) compile warning-free.
    Buil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
    [cec_adc.c, cec_teleplot.c]
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2026-06-12 fw: 12vhpwr proto -- instrument cec_fpga_link bring-up, make link non-fatal
    Bench: the app boots clean (rev v1.0 fix) and reaches app_main, but
    hangs in cec_fpga_link_init before its completion log -- on the v0 SPI
    pin map (GPIO 20-24) that was simulation-verified only, never run on P4
    silicon. To localize without guessing:
    * cec_fpga_link_init logs progress (DRDY-gpio ok -> spi_bus_initialize
    ok -> adding device), so the last line printed names the exact
    stuck call.
    * app_main no longer ESP_ERROR_CHECKs the link (that would abort/
    reset on a stuck init); it logs and continues so the console stays
    up and the CLI/loop still run.
    Build verified green (esp32p4).
    https://cla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
    [cec_fpga_link.c, main.c]
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2026-06-12 fw: 12vhpwr proto re-pin FPGA link to GPIO 1-5 (off the P4 PSRAM bus)
    The v0 link pins (GPIO 20-24) sit on the ESP32-P4 flash/PSRAM MSPI bus
    (IO_MUX DBG_PSRAM_*), so gpio_config on them hangs the CPU at bring-up.
    Re-pin all five signals to GPIO 1-5: plain-GPIO-only per the P4 IO_MUX
    (no flash/PSRAM/Ethernet/console-UART/strap function), all exposed on the
    ESP32-P4-Module-DEV-KIT header. Dock field positions and FPGA balls are
    unchanged -- only the ESP GPIO (and thus the header pin each jumper lands
    on) moved.
    - cec_config.h: PROTO_PIN_* sclk1/mosi2/miso3/cs4/drdy5, board-name +
    rationale comments
    - rtl/12vhpwr-proto README: wiring-table GPIO column, board id, and
    resolved the under-revi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
    [cec_config.h]
2026-06-12 fw: 12vhpwr proto -- yield in the DRDY idle-poll so IDLE doesn't starve
    With the FPGA link now up (post re-pin), a low DRDY (FPGA not pacing yet)
    kept the wait-loop in its idle branch, where vTaskDelay(pdMS_TO_TICKS(1))
    rounds to 0 ticks at the IDF default 100 Hz tick rate -- vTaskDelay(0)
    never yields, so main spins at 100% on CPU0, IDLE0 starves, and the task
    watchdog resets the board at ~5 s.
    Both loops (teleplot + raw console) now use a named PROTO_DRDY_POLL_TICKS
    (>= 1 tick = 10 ms @ 100 Hz, far below the ~200 ms frame period). printf
    output bytes are unchanged, so the teleplot/raw-console byte contract
    holds. The "waiting on DRDY" state is now stable, so the FPGA side can be
    brought u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
    [main.c]
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2026-06-13 fw: 12vhpwr proto -- config-driven physical-unit calibration + rail de-glitch
    Make the TelePlot/CLI output readable in real units instead of raw ADC
    volts. New per-channel calibration table in cec_config (proto_ch_cal_t /
    PROTO_CH_CAL): physical = (adc_v - offset_v) * scale, with a kind
    (RAW/VOLT/AMP), a TelePlot label, and a median-deglitch flag.
    - v6 -> "vrail": 47k/10k divider (x5.7), median-of-5 to reject the
    intermittent 2x read glitch on that high-Z divider node -> clean ~12V.
    - the other seven stay RAW (ADC volts) pending the perfboard current
    front-end (shunt/gain/bias); flipping one to amps is a one-line table
    edit (kind=AMP, scale=1/(Rshunt*gain), offset_v=Vbias, label="i<pi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
    [cec_config.h, main.c]
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2026-06-13 fw: 12vhpwr proto -- current channels in amps; drop unconnected v1/v2
    Stream the per-pin sense channels (v3-v5,v7,v8) as amps via PROVISIONAL
    PROTO_ISENSE_* constants: amps = (adc - 2.40 V bias) / 0.10 V/A (1 mOhm *
    INA240A3 gain 100, the spec front-end). Bias is taken from the capture's
    steady channels; set PROTO_ISENSE_V_PER_A to the board's real shunt*gain
    to lock the magnitude (the sign and zero are already correct). v6 stays
    the rail in volts.
    v1/v2 are not wired into the measuring cable yet, so they carry a NULL
    label = unconnected: skipped in the TelePlot stream (no float noise on
    the plot); the `frame` CLI still prints their raw value for a floating
    check.
    12vhpwr build OK (esp32p4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
    [cec_config.h, main.c]
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2026-06-13 fw: 12vhpwr proto -- polling SPI read + capture priority for true ~50 kHz
    The burst self-diagnosed ~12.7 kHz capture (every ~3.5th FPGA frame): the
    read was ~78 us/frame, only ~14 us of which is 10 MHz clocking -- the rest
    was spi_device_transmit's queue/ISR overhead. Swap cec_fpga_link_read to
    spi_device_polling_transmit (busy-wait, no queue) so a frame reads in a few
    us, and raise the burst task to near-max priority during the tight capture
    loop so preemption doesn't add jitter (the log showed an 8 ms stall). Both
    push the ESP-over-SPI capture toward the ~50 kHz the FPGA produces.
    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
    [cec_fpga_link.c, main.c]
2026-06-13 fw(rtl): 12vhpwr FPGA-buffered capture ring -- path to the native AD7606 rate
    The ESP per-frame handshake caps the live read ~12 kHz no matter how fast
    the SPI read is (bench-confirmed: polling didn't move it) -- the FPGA drops
    every frame produced while the ESP holds CS, then the ESP waits for the next
    DRDY. So move the buffering into the FPGA: every completed frame is written
    to a DEPTH-deep BRAM ring at the native sample rate (gap-free, FPGA-paced),
    and the ESP reads the whole window out in bulk.
    Selected by MOSI (cec_spi_slave is UNCHANGED -- only its `frame` input is
    muxed): MOSI low = live latest-frame (back-compat 5 Hz monitor + slow burst);
    MOSI high = buffered stream (1st transacti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
    [tb_top.v]
2026-06-13 fw: 12vhpwr proto -- `fastburst` reads the FPGA capture ring at native rate
    cec_fpga_link gains read_buffered() (drives MOSI high -> the fabric streams
    its BRAM ring; cec_fpga_link_read refactored to share read_tx + the polling
    transmit). New `fastburst [N]` CLI command: arm (discard) then pull N frames
    straight out of the ring and dump the bracketed CSV with a nominal us axis
    (idx x 1/PROTO_NATIVE_HZ) plus a seq-gap / bad-header count -- gap-free and
    uniform, unlike the ESP-paced `burst` (~12 kHz, jittered, drops frames during
    each read). PROTO_NATIVE_HZ / PROTO_RING_DEPTH in cec_config mirror the RTL
    SAMPLE_HZ / DEPTH.
    Build gate green (RTL sim + all three apps; 12vhpwr on esp32p4).
    http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
    [cec_config.h, cec_fpga_link.c, main.c]
2026-06-13 12vhpwr-proto: set native capture rate to the 200 kSPS oversample target
    Two-rate operating plan: stream the live monitor at the ~13 kHz handshake
    ceiling, and `fastburst` the FPGA-paced capture ring at the 200 kSPS
    AD7606 OS=000 throughput target so the host can oversample + decimate to
    the ~25 kSPS useful band (sqrt(8) ~ 2.8x noise drop, 200k/25k = 8x).
    - top.v SAMPLE_HZ 100_000 -> 200_000 (the free-running pacer self-limits
    to what the sequential conv->read FSM can service; see the in-file note
    on reaching the full rate via faster read SCLK + a pipelined FSM).
    - cec_config.h PROTO_NATIVE_HZ 100000 -> 200000 (nominal fastburst time
    axis; the seq column reveals the real achieved/gap-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
    [cec_config.h]
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2026-06-13 12vhpwr-proto: bad headers are the LINK SCLK, not the AD7606 read
    Bench evidence: the constant 0xA5 frame header arrives single-bit-flipped
    (0xB5/0xA1/0xA7), which is link-transmission corruption -- the FPGA emits
    0xA5, so a flipped header can only be the ESP mis-sampling MISO. That is
    the ESP<->FPGA link (PROTO_LINK_CLOCK_HZ), a different clock than the
    AD7606 readout SCLK that was slowed -- which is why slowing the AD7606
    SCLK (and the ground jumper) didn't touch the headers.
    - Link: 12.5 MHz -> 8 MHz. The 12.5 MHz this session bumped past the
    known-good 10 MHz and over the slave's marginal edge; 8 MHz gives MISO
    settle margin on the perfboard link. (Reflash, no bitstream rebuild.)
    -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
    [cec_config.h]
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2026-06-13 12vhpwr-proto: `rate` command -- measure the true native sample rate
    The "200 kSPS" in the burst CSVs is the nominal PROTO_NATIVE_HZ label; the
    conv+read FSM self-limits to ~100k at /4 readout, so an FFT scaled to the
    nominal is ~2x high (the stream run independently measured ~100k). Fix:
    measure it.
    FPGA: a free-running 32-bit native-frame counter (increments every
    cap_stb, even while frozen) exposed on a new 0x33 STATUS read mode
    (header 0x5C, count[31:16] in ch0 / [15:0] in ch1). MSB=0 so it never
    trips the 0xFF burst-freeze selector. tb verifies the counter advances
    between two status reads.
    ESP: cec_fpga_link_read_status(); `rate [ms]` reads the counter twice
    over a known interval ->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
    [cec_config.h, cec_fpga_link.c, main.c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]
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2026-06-13 12vhpwr-proto: rate -- pause teleplot during the measurement (garbage fix)
    Bench: `rate` returned 4122349 kSPS / 993M frames -- impossible (82x the
    fabric clock). Root cause: cli_cmd_rate didn't set s_capturing, so the
    TelePlot loop kept reading the link (MOSI=0x00 = live) across the 250 ms
    window and flipped the fabric out of status mode; the 2nd counter read
    then grabbed live channel data instead of the counter -> garbage delta.
    Fix: set s_capturing=true for the measurement (pauses teleplot, like
    cal/fastburst/autoburst already do), and header-check the 2nd status read
    too (0x5C) so a stray mode flip errors instead of computing nonsense.
    ESP-only (reflash, no bitstream rebuild). App buil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
    [main.c]
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2026-06-13 rtl(12vhpwr-proto): wire the native detector into top.v + gate it
    top.v now instantiates cec_native_detect on cap_stb + {shA,shB}:
    - sticky arm latch on MOSI command bytes 0x44 (arm) / 0x46 (disarm+clear),
    both MSB=0 so STATUS/BURST polls never disarm and never trip the 0xFF freeze;
    disarmed at reset so LIVE/BURST/STREAM/STATUS are untouched until armed.
    - on a trip the detector freezes the ring DEPTH/2 frames later (CENTERED) via a
    det_frozen flag that survives status polls; the frame mux now lets 0x33 STATUS
    outrank frozen (so the trip is readable while frozen) and the ring read-pointer
    only advances on a real 0xFF read, not on a poll.
    - STATUS frame V3 = {tripped, det_frozen, 0,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
    [tb_top.v]
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2026-06-13 fw(12vhpwr-proto): `detect` CLI to drive the FPGA native detector
    cec_fpga_link gains _detect_arm() (0x44) and _detect_clear() (0x46), the sticky
    arm-latch command bytes for the in-fabric detector. The new `detect [timeout_ms]`
    CLI command: arms, polls STATUS (0x33) for the tripped bit in code[2] (bit15) +
    reports which pin (trip_ch -> detector ch i = ESP frame idx 7-i), then reads the
    centered frozen ring with read_buffered() like fastburst and dumps a BURST_CSV,
    and disarms (0x46). Status polling doesn't disarm or consume the ring, so the
    wait loop is safe. The threshold/k/mask live in the bitstream (top.v DET_*);
    runtime config over MOSI is the next increment.
    Builds clean under the IDF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
    [cec_fpga_link.c, main.c]
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2026-06-13 12vhpwr-proto: replace transient detector with per-pin anomaly detector
    The bench data killed the transient trigger: the GPU load is a ~342 Hz
    periodic swing and all pins swing together (~4 A pk-pk), so firing on a
    pin's deviation from its own baseline trips on every load edge -- no
    signal. The melt-relevant anomaly is a pin's SHARE departing from fair
    share (a contact degrading so one pin hogs/starves while the rest carry
    the common swing).
    cec_native_anomaly.v: slow per-pin EMA, then per masked pin
    e_i = NMASK*avg_i - sum(masked avg) = NMASK*(avg_i - mean). The
    per-channel ADC bias and the common load swing both cancel in e_i, so a
    balanced load reads 0 at any load level; trip on |e_i| >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
    [tb_top.v]
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2026-06-13 12vhpwr-proto: add 12V-rail spike/brownout/load-unexplained detector
    A second sibling detector (cec_native_rail.v) on the rail voltage
    (vrail = v6 = detector ch 2), wired into top.v alongside the imbalance
    detector: shares the 0x44/0x46 arm, ORs into the same centered
    ring-freeze and the STATUS V3 word, and tags the vrail channel so the
    ESP detect CLI reports it as a rail event.
    The hard part is rejecting the in-spec load droop (the rail dips ~46
    codes when the GPU draws current) while catching PSU on/off, brownout,
    and a degrading feed. Two stacked discriminators:
    - MAGNITUDE: the in-spec droop sits in a ~30x gap below the ATX +/-5%
    window and a PSU on/off edge, so a band test on |vrai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
    [tb_native_rail.v, tb_top.v]
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2026-06-18 atx-24pin: read + report + capture PS_ON# / PWR_OK, LED tracks power-good
    Wire the U4/U5 buffers (74LVC1G17, non-inverting) into the firmware:
    PWR_OK on IO38 (1 = power good), PS_ON# on IO39 (0 = PSU commanded on).
    Both are read-only monitoring taps off the ATX pass-through.
    - configured as inputs; read every 50Hz iteration.
    - emitted to TelePlot (ps_on / pwr_ok) and added to the 1Hz log line.
    - added to the pre-trigger capture sample (b_ps_on / b_pwr_ok) so every
    burst records the PSU control/status alongside the rails -- useful
    forensics for "did PS_ON drop?" on a shutdown event.
    - status LED now means something: solid ON when PWR_OK (system running),
    ~1Hz heartbeat otherwise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
    [cec_config.h, main.c]
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2026-06-19 atx-24pin: route TelePlot to stdio unconditionally on the production board
    Root cause of "no graphs even with --show-teleplot": the production board
    has no CH340K UART, but a stale sdkconfig left CONFIG_CEC_TELEMETRY_UART0=y
    (a sdkconfig.defaults change does not rewrite an existing sdkconfig on a
    plain build), so every teleplot line was still being pushed out the absent
    GPIO43/44 -- nothing reached the host. The only lines on the USB console
    were the 1 Hz ESP_LOG rows; the 10 Hz teleplot stream was missing entirely,
    which is the tell that it was not hitting stdout at all.
    Fixes, all on the stdio path the production board actually uses:
    - main.c no longer calls cec_telemetry_init_uart. The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
    [cec_teleplot.c, main.c]
2026-06-19 atx-24pin: correct the cec_config TelePlot-transport comment
    main.c no longer calls cec_telemetry_init_uart, so the note that the init
    "no-ops" was stale -- update it to say TelePlot always rides stdio on this
    board regardless of CONFIG_CEC_TELEMETRY_UART0. Comment only.
    [cec_config.h]
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2026-06-19 atx-24pin: record the as-built shunt parts for this spin
    Document the actual shunts now on the board so the measurement chain is
    honest about what gates its accuracy: 12V/5V/3V3 = PSRP25K6FR002 (2 mOhm,
    ±1%), 5VSB = LCSR2512FR025K9L (RESI, 25 mOhm, ±1%, ±100 ppm/°C, 2 W). The
    shunt tolerance/TCR -- not the INA228 -- sets current/power accuracy, so
    the note ties it to the uncalibrated ±1%, the current_trim one-point cal,
    and die-temp TCR compensation. OQ-11 stays open (Bourns CSS2H intended for
    production); the PSRP 2 mOhm TCR is unconfirmed and flagged to verify.
    Comment only.
    [cec_config.h]
2026-06-19 atx-24pin: confirm the PSRP shunt TCR (±75 ppm/°C) from the datasheet
    The Prosemi PSRP datasheet resolves PSRP25K6FR002 = 2512, NiCr (K)
    element, 6 W, ±1%, 2 mOhm, and the 2512 table gives that row ±75 ppm/°C.
    Drop the "unconfirmed -- verify" flag and record the real specs: the main
    rails are ±75 ppm/°C (better than the 5VSB LCSR's ±100), and the 6 W
    rating means trivial self-heating at the ~0.45 W they actually dissipate
    at 15 A. Comment only.
    [cec_config.h]
2026-06-19 atx-24pin: add a per-rail INA228 calibration routine (cal CLI + NVS)
    The shunt tolerance (~±1%) -- not the INA228 -- sets the current/power
    accuracy, and the trims have been sitting at 1.0 (raw). Add a bench cal so
    each rail can be trimmed to the part's own ~±0.1-0.2% class:
    cal show per-rail v_gain / i_gain / i_offset
    cal i <rail> <known_A> apply a known load; 1st point sets gain, a 2nd
    point adds the offset term (solves gain+offset)
    cal v <rail> <known_V> set the voltage gain from a DMM reading
    cal save persist to NVS (survives reboot)
    cal clear [rail|all] reset to identity (raw) + save
    Driver: ina228 gains a c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
    [ina228.c, main.c]
2026-06-19 atx-24pin: record this-spin shunt parts in the BOM; flag the RS6 mismatch
    The 2mOhm main-rail shunts RS1/RS2/RS5 now carry the as-built part for
    this spin -- Prosemi PSRP25K6FR002 (NiCr, 6W, +/-1%, +/-75ppm/C,
    2-terminal) -- with the production-target Bourns CSS2H-2512K-2L00F
    (C1729157) preserved in the BOM comment (OQ-11). These are 2-terminal on
    the honest R_2512 land, so it is a clean metadata update.
    RS6 (25mOhm 5VSB) is NOT a clean swap: the schematic carries it as a
    4-TERMINAL Vishay WSK2512 Kelvin shunt (4-pin symbol + WSK land), but the
    as-built LCSR2512FR025K9L is 2-terminal. Recorded the LCSR + a loud
    MISMATCH note in the BOM comment, but left the symbol/footprint untouched
    -- con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
    [24pin-module.kicad_sch]
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2026-06-19 firmware: flash the 24-pin over CAN (app-level OTA bridged by the Hub)
    ESP32-S3 has no ROM CAN bootloader, so "flashing over CAN" is an application
    OTA: the running 24-pin app receives its next image over CAN, writes it to the
    inactive OTA slot, validates, flips the boot selector, and reboots. The Hub
    bridges it (host -> Hub USB -> CAN -> 24-pin).
    Shared protocol (cec_comms/cec_canota.{h,c}): one source of truth for both
    ends. 3 frame types -- CTRL (BEGIN/END/ABORT), DATA (7 bytes/frame, rolling
    seq), STAT (READY/ACK/NAK/DONE/ERR). Stop-and-wait with retries; CRC32
    (standard zlib, chainable) checked incrementally on the receiver and verified
    against the host's zlib.crc32. Sender + receiver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
    [partitions.csv]
2026-06-19 firmware: DETECT analog sense + poke-and-ack port binding (spec §2.3)
    The Hub reads a module's comm class off the static DETECT divider (pin 8, the
    analog sense), and poke-and-ack binds a CAN identity to its physical port: the
    Hub perturbs the line, a module with a high-Z pin-8 GPIO tap senses the edge
    and acks over CAN (a MOVED frame, 0x120), and the Hub binds that serial to the
    poked port. Identity stays on CAN; the pin spends no namespace.
    Shared cec_pokeack.{h,c} (in cec_comms):
    - Comm-class read (10k pull-up / 3.3V divider -> CAN-only 2.2k, CAN+RS485 4.7k,
    CAN+100BT1 10k, two reserved, open=absent, short=fault).
    - Module responder: a high-Z tap GPIO edge watcher; on the Hub's poke p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
    [cec_config.h, cec_pokeack.c, main.c]
2026-06-20 firmware: multi-module Hub aggregator + module-scoped telemetry IDs
    The Hub now consolidates up to 4 modules on one CAN bus and forwards the lot
    over USB for host analysis. Closes the collision in the old scheme, where the
    rail burst used fixed IDs (0x200-0x202) with no per-module offset.
    Module-scoped CAN IDs (cec_telem): telemetry is 0x200 + instance*0x10 + sub,
    so each port owns a 16-ID block (port 0 = 0x200-0x202, port 1 = 0x210-0x212,
    ...). Helpers cec_telem_id_is / _instance / _sub let the Hub demux. The status
    byte is now module-type-defined (raw `flags`): ATX24 keeps PS_ON/PWR_OK/
    SHUTTING_DOWN, the EPS carries its CEC_FLAG_* fault bits. Added per-(type,chan)
    labels and a type-name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
    [cec_config.h, eps_main.c, main.c]
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2026-06-24 rev3: datasheet pinout verify (all 7 ICs match) + fix TPS2121 PR1 priority wiring
    Cross-checked every placed IC's symbol pinout against its cached datasheet (workflow,
    1 agent/part): C6/INA228/INA181/TLV7011/TPS2121/LP5907/TJA1051 ALL match (the only diffs
    are cosmetic pin-NAME spellings -- ILM/ILIM, IN/IN- -- zero netlist impact). REAL FIX: the
    TPS2121 PR1 pin was a GND placeholder, which per datasheet Table 9-3 selects VCOMP mode
    (highest-voltage-wins), NOT IN1 priority -- corrected to a divider off IN1 (R52 100k/R53 33k)
    so IN1>IN2 priority is real; OV1/OV2/CP2->GND were already correct; ST pull-up 100k->10k.
    ERC unchanged (1 benign CAN-TXD GPIO typing). 57 parts.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
    [24pin-module.kicad_sch]
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2026-06-25 EPS + PCIe-2/3 Rev2: sectioned regen (BOM-preserving) + INA238 datasheet
    Same treatment as the 24-pin rev3 / Hub Rev2, for the three i2c-cable modules. They're
    already C6 + §6.13 + sourced, so this is the sectioned-layout pass: gen-module-rev2.py
    (parametric) regenerates each from its extracted netlist into 7 LABELLED SECTIONS,
    preserving the BOM (39/39/45 LCSC props via cec_sch props=). ERC = 1 benign error each
    (the universal C6→CAN-TXD typing). Pinout verification was ALREADY done -- every IC uses
    a symbol verified with the 24-pin/Hub (C6, TJA1051, LP5907, INA238=INA226 body, INA181,
    TLV7011); cached the one new datasheet (INA238). Source modules stay the source of truth.
    Co-Authored-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
    [eps8pin-module-rev2.kicad_sch, pcie8pin-2port-module-rev2.kicad_sch, pcie8pin-3port-module-rev2.kicad_sch]
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2026-06-27 eps-8pin-rev3: full pipeline raw schematic -> placed + routed (DRAFT)
    Capstone demo of the closed loop on a NEW revision: scaffold rev3 from the EPS schematic ->
    ERC (2 documented-benign errors: CAN TXD pin_not_driven + C6 NC pad) -> synth place (cc_aware=0,
    corridor-clean by construction) -> CONFORMANCE 0 flags (RJ-45/pin-alloc/DETECT/shunt/kelvin all
    pass) -> route (kelvin+diffpair PASS, unconn=0, drc=3 = cosmetic mount-edge-clearance) -> CL-13
    outcome label fires. Reverted the e=3.5->5.0 mount tweak (it aborts the placer worker; FOLLOWUPS).
    Placer run in-process (max_workers=1) to dodge tonight's intermittent pcbnew spawn-pool aborts.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
    [eps-8pin-rev3.kicad_pcb, eps-8pin-rev3.kicad_sch]
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

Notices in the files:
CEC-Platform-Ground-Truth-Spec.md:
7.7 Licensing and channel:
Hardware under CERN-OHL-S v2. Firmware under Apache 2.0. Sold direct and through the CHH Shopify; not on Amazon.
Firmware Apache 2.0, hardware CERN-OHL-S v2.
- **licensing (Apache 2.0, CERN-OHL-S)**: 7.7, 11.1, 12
